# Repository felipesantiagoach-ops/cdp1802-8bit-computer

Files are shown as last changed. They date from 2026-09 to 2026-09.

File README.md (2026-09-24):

# CDP1802 8-bit Computer — Design and Construction

Design, construction and testing of an 8-bit microcomputer built around the **RCA CDP1802**, the first CMOS microprocessor (also known for flying in the Galileo probe and the Hubble Space Telescope).

Final engineering project for *Proyecto y Diseño Electrónico* (ET546), Electronic Engineering, **Universidad Nacional de Misiones**, Argentina (November 2022).

📄 **[Read the full report (PDF, Spanish)](informe/ProyectoFinal.pdf)**: 166 pages covering theory, schematics, PCBs, assembly code and test results.  
🖼️ **[Project poster](Poster_PyD_2022_Grupo_A.pdf)**

<p align="center">
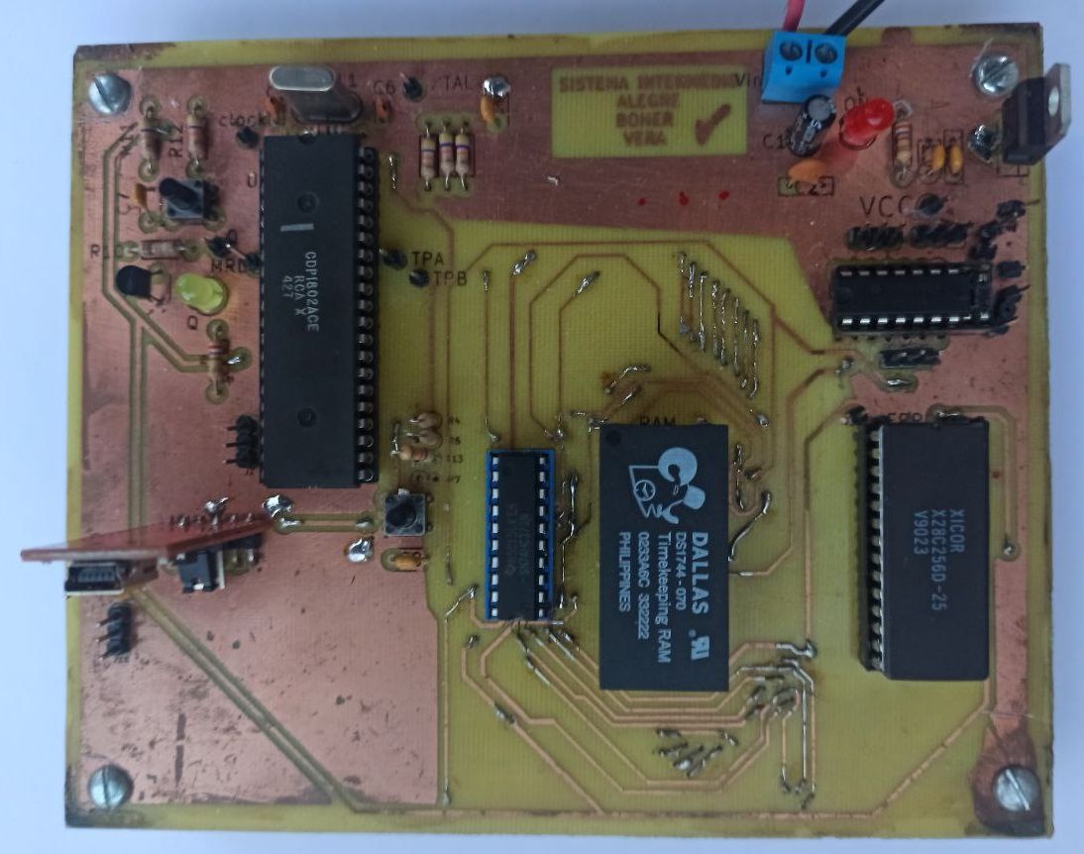
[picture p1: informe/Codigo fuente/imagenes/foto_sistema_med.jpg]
Medium system, assembled
  
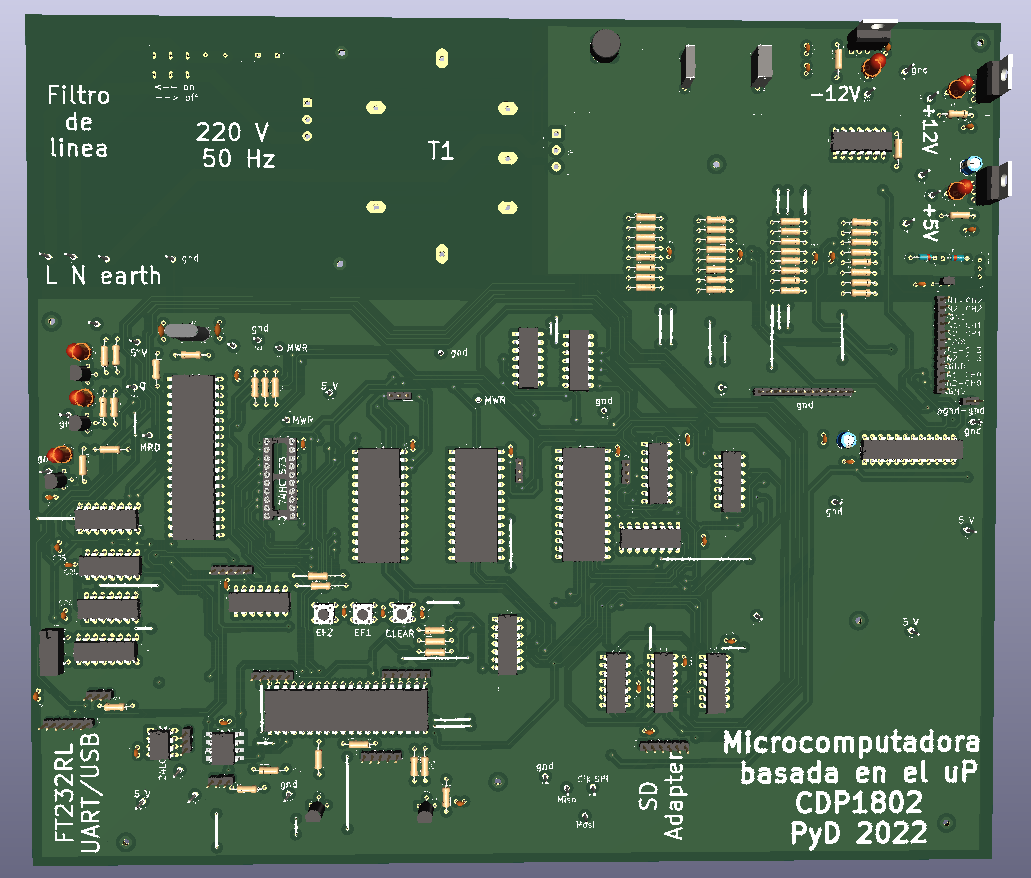
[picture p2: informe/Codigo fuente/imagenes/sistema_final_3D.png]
Final system, 3D render of the PCB
  
</p>

---

## Overview

The project was developed in three stages of increasing complexity. Each stage was designed in KiCad, simulated, and (for the first two) built and tested on hardware.

| Stage | Status | Highlights |
|---|---|---|
| **Minimal system** | ✅ Built and tested | CDP1802 + 8K EEPROM, 8-bit addressing, jumper-selectable program banks, single-sided PCB |
| **Medium system** | ✅ Built and tested | 16-bit addressing (64 KB), 32K EEPROM + 32K RAM, USB-UART link, runs Tiny BASIC and a diskless Elf/OS |
| **Final system** | 📐 Designed (schematics + PCB) | Power supply, bank-switched memory, I²C and SPI serial memories, 12-bit ADC, parallel I/O |

### 1. Minimal system
- CDP1802 with an AT28C64 EEPROM using only the 8 low address lines (256-byte programs).
- A8/A9 set by jumpers, allowing four independent programs in the same EEPROM without reprogramming.
- Four assembly programs written and verified on hardware: LED blink, push-button input, conditional blink, and a **bit-banged UART transmitter at 600 baud** using the Q output, with the delay loop derived analytically from the instruction cycle timing.
- Subroutines use the CDP1802 *SEP technique*, which requires no RAM (the system has none).

### 2. Medium system
- 74HC373 address latch to demultiplex the CDP1802's time-shared address bus to a full **16-bit / 64 KB** space.
- Memory map: 32K EEPROM (program) + 32K DS1744 timekeeping RAM (data).
- FT232RL USB-UART module for communication with a PC terminal (Tera Term).
- Ported and ran third-party software on real hardware:
  - **Tiny BASIC interpreter**: modified the source (register definitions, idle line polarity, autorun) and reassembled it.
  - **Diskless Elf/OS** operating system.

### 3. Final system (design)
Fully backwards compatible with the previous stages. Designed as a modular set of schematics and a double-sided 30 × 30 cm PCB:
- **Linear power supply** with line filter and ±12 V / 5 V regulation.
- **Bank-switched memory map**: boot mode (EEPROM + RAM) and run mode (program copied to RAM, a second RAM swapped in to maximise working memory).
- **Hardware SPI engine** built from discrete logic (MC14014 + 74HC595 shift registers, 74HC161/74HC74/74HC73 clock generator producing exactly 8 pulses at 2 MHz), which offloads the serial shifting from the CPU. Intended for a **microSD** card.
- **I²C serial memories**: 24LC1025 EEPROM and MB85RC64A **FRAM**, driven in software through the parallel port.
- **12-bit ADC** (MAX127) with OPA4277 signal conditioning for **4–20 mA** industrial current loops.
- **82C55 parallel I/O** mapped into the CDP1802's dedicated I/O space (INP/OUT instructions).

The report also outlines future work, including I/O drivers, SD-card support, a PLC-oriented use case and guidelines for a real-time operating system.

---

## Tools

| Area | Tools |
|---|---|
| Schematics and PCB | KiCad |
| Assembly and simulation | A18 cross-assembler, Emma02 emulator (debugging and instruction tracing) |
| Programming hardware | XGecu TL866 universal programmer; an Arduino-based EEPROM programmer was also built |
| Communication | FT232RL, Tera Term |
| Documentation | LaTeX (memoir, biblatex/biber), Git, VS Code |

---

## Repository structure

```
Poster_PyD_2022_Grupo_A.pdf   Project poster
informe/
  ProyectoFinal.pdf           Compiled report (Spanish)
  Codigo fuente/              LaTeX source (chapters, appendices, bibliography, figures)
archivos_de_kicad/            KiCad projects: schematics, PCBs, BOMs and exports
  1_Sistema_minimo/
  2_Sistema_medio/
  3_Sistema_final/            Full system plus separate sub-projects (ADC conditioning, SPI)
programas/                    CDP1802 assembly programs (.asm), assembled output (.hex, .lst) and build scripts
decodificador SPI/            Proteus simulations of the hardware SPI circuit
```

The KiCad projects were made with KiCad 6 (the minimal system also includes the original KiCad 5 files).  
Programs are assembled with the [A18 cross-assembler](https://www.retrotechnology.com/memship/a18.html); each folder includes a `.bat` script that assembles the `.asm` file with the same name.

### Building the report
Requires a LaTeX distribution (MiKTeX or TeX Live) with `biber`.

```bash
cd "informe/Codigo fuente"
pdflatex proyecto
biber proyecto
pdflatex proyecto
pdflatex proyecto
```

---

## Third-party software

The `programas/` folder also contains third-party code that was studied, modified or run on the hardware. It is included for reference, and credit goes to its original authors:
- **Tiny BASIC** for the 1802, from the [Membership Card](http://www.sunrise-ev.com/1802.htm) project (the `original/` folder is unmodified; `modificado/` contains our changes).
- **FIG-Forth** for the 1802, from Lee Hart's Membership Card resources.

---

## Authors

- **Felipe Santiago Alegre Chamorro**
- Atilio Boher
- Uriel Adrián Vera

Supervisor: Ing. Ricardo A. Korpys, Facultad de Ingeniería, UNaM.

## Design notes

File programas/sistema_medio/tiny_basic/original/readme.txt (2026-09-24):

Tiny BASIC for the 1802 by Lee Hart and Tom Pittman
mods by many, latest Loren Christiansen
http://www.retrotechnology.com/memship/mship_tbasic.html

tbsummaryp.txt	TMSI summary of Tiny BASIC 1802 commands
tbmanualp.txt	TMSI Tiny BASIC 1802 manual by Lee Hart
TBEK_sg.txt	Tom Pittman's documentation
tb0_test.asm		ASM of source, for A18 assember
1802reg.asm	include file names 1802 registers
tb0_test.prn		prn of assembled tb0 source
tb0_test.hex		Intel hex of assembled source
tb0_test_results.txt - commented notes from running this TB code
tbasic_loren.txt  notes about use of TB on 1802 M/S card
readme.txt	this document

last updated Aug 2 2018 Herb Johnson

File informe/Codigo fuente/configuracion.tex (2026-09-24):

% -----------------------------------------
% OTROS PAQUETES E INSTRUCCIONES ESPECIALES
% -----------------------------------------

% PAQUETES
%%%%%%%%%%

% Para insertar PDFs
\usepackage{pdfpages}
% Para insertar código fuente estilizado
\usepackage{listings}
	\lstset{basicstyle=\ttfamily,
    		breaklines=true,
            numbers=left, 
    		numberstyle=\tiny, 
    		stepnumber=1, 
    		numbersep=6pt
            }

% Para adjuntar pdf
\usepackage{pdfpages}

% Para usar múltiples columnas
\usepackage{multicol}

% Para crear árboles conceptuales
\usepackage{forest}

% Para insertar símbolos extraños
\usepackage{marvosym}

% Para insertar texto fútil
\usepackage{lipsum}

% NUEVAS INSTRUCCIONES
%%%%%%%%%%%%%%%%%%%%%%

\newcommand{\EIEx}{\textsc{Escuela \Lightning~ Ingeniería Eléctrica}}

% Definición de algunos símbolos matemáticos
\newcommand{\me}{\mathrm{e}}
\newcommand{\mi}{\mathrm{i}}
\newcommand{\mj}{\mathrm{j}}
\newcommand{\md}{\mathrm{d}}

% Listas con menos espacio entre ítemes (más ajustado)
\newcommand{\ajustado}{\itemsep0pt\parskip0pt\parsep0pt}

% FORMATO PARA EL REGLAMENTO
%%%%%%%%%%%%%%%%%%%%%%%%%%%%

\newcounter{articulo}
\newcommand{\articulo}[2]{
	{
    \stepcounter{articulo}
    \noindent
	\textbf{Artículo \thearticulo} --- \textit{#1}
	\vspace{2mm}\\
	}{
	#2
	\vspace{2mm} \\
	}
}

\newcounter{capitulo}
\newcommand{\capitulo}[1]{
	{
    \stepcounter{capitulo}
    \centering\large\bfseries
    Capítulo \Roman{capitulo}. #1
    \vspace{4mm}\\
    }
}

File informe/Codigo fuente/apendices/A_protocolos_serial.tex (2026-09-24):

\chapter{Protocolos de Comunicación Serial}
\label{C:anexo-comunicación-serial}

\section{UART}

UART (Universal Asynchronous Receiver-Transmitter) \cite{fernandez-com-serial} es un protocolo de comunicación serial asincrónica y bidireccional full-duplex desarrollado en el año 1960 por la empresa Digital Equipment Corporation. Esta interfaz posee dos líneas de datos, RX y TX, las cuales se interconectan como lo muestra la figura~\ref{F:uart-interconexión}. UART generalmente es usada para establecer una comunicación bidireccional full-dúplex sólo entre dos dispositivos (punto a punto).

\begin{figure}[ht!]
\centering
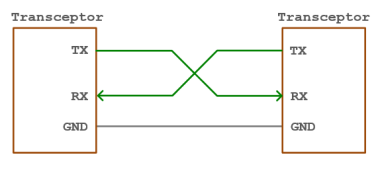
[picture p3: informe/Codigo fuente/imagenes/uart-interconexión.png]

\caption{Interconexión de interfaz UART}
\label{F:uart-interconexión}
\end{figure}

La información intercambiada entre los dispositivos es mediante paquetes de datos con un formato definido como se muestra en la figura~\ref{F:uart-trama-datos}. La comunicación está sincronizada mediante los bits de START y STOP que posee el paquete, considerando que los relojes de los dispositivos transmisor y receptor operan a la misma frecuencia.

\begin{figure}[ht!]
\centering

\caption{Paquete de datos UART}
\label{F:uart-trama-datos}
\end{figure}

El paquete de datos indicado posee las siguientes configuraciones que deben efectuarse en los dispositivos que intervienen en la comunicación:

\begin{description}
   \item[Bit de START] Es el primer bit del paquete de datos y permite que el receptor reconozca el inicio de la transmisión de un paquete. Normalmente el transmisor (TX) mantiene la línea de datos en “1” cuando se encuentra en reposo. Para iniciar la transmisión pone a “0” la línea y el receptor, al detectar esto, comienza con la lectura del DATO.
   \item[DATO] Este campo del paquete puede configurarse de 5 a 9 bits. La configuración debe ser la misma para ambos dispositivos en la comunicación. Los bits son enviados uno a uno, empezando por el menos significativo y terminando con el más significativo.
   \item[Bit de Paridad] Permite al receptor verificar si los datos recibidos son correctos o no. La paridad es un sistema de comprobación de errores de bajo nivel y puede ser de paridad par o paridad impar. Debe configurarse la misma paridad en ambos dispositivos involucrados en la comunicación.
   \item[Bit de STOP] Marca el final del paquete de datos al receptor. Puede tener uno o dos bits de longitud. Debe configurarse lo mismo en ambos dispositivos. Al finalizar la transmisión, es habitual que se mantenga la línea de datos en “1” (línea en reposo).
   \item[Baud Rate (bits por segundo)]  Es un parámetro que indica la velocidad a la que se transmiten los datos y se relaciona con el reloj interno que poseen los dispositivos para la lectura/escritura de los bits que conforman el paquete de datos. Todos los dispositivos deben tener el mismo baud rate. Algunas de las velocidades estándares son 4800 bps, 9600 bps, 19200 bps, 115200 bps, etc. De estas, 9600 bps es la más utilizada.
\end{description}

\section{I\texorpdfstring{\textsuperscript{2}}{Lg}C}

I\textsuperscript{2}C (Inter-Integrated Circuit) \cite{fernandez-com-serial} es un bus de comunicación serie sincrónica bidireccional half-duplex desarrollado en el año 1982 por la empresa Philips Semiconductors. El bus I2C también es conocido con el nombre de TWI (Two Wire Interface). Este bus también posee una arquitectura Maestro-Esclavo, donde el dispositivo Maestro es el único que puede iniciar y finalizar la transmisión y también proveer la señal de reloj. En I2C los dispositivos Esclavos pueden convertirse en Maestros, pero en el bus sólo puede existir un Maestro a la vez.

El bus está compuesto de dos líneas y la conexión común de GND, como puede apreciarse en la figura~\ref{F:i2c-interconexión}. Existe una línea bidireccional para el intercambio de datos que se denomina SDA (Serial Data) y una para la señal de reloj denominada SCL (Serial Clock). Como en este bus no existen líneas de selección de esclavo, cada dispositivo Esclavo debe contar con una dirección única (código de identificación) la cual debe incluirse al dato. Esto resulta en una reducción de la velocidad de transferencia de cada byte de dato.

Las líneas SDA y SCL son del tipo drenador abierto (figura~\ref{F:i2c-entrada-y-salida}), por lo cual cada una requiere una resistencia pull-up Rp ($ \num{1.8}~\unit{\kilo\Omega} \leq Rp \leq \num{10}~\unit{\kilo\Omega} $).

\begin{figure}[ht!]
\centering
\subfloat[Interconexión de interfaz I\textsuperscript{2}C][Interconexión de interfaz I\textsuperscript{2}C]{
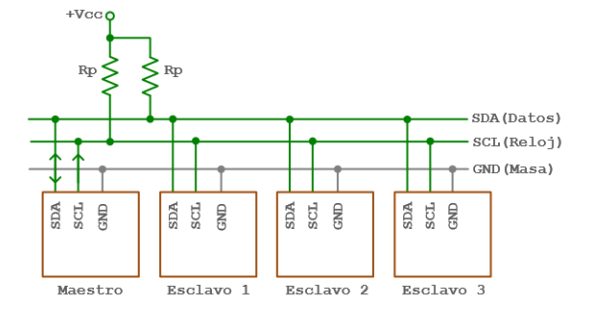
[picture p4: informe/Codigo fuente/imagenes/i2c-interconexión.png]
	
	\label{F:i2c-interconexión}}
\\
\subfloat[Líneas SDA y SCL][Líneas SDA y SCL]{
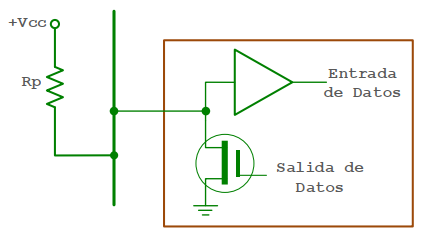
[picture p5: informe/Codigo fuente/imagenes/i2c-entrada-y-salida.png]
	
	\label{F:i2c-entrada-y-salida}}
\caption{Interfaz I\textsuperscript{2}C}
\end{figure}

A continuación se describe un ejemplo de trama del protocolo I\textsuperscript{2}C, la cual se puede observar en la figura~\ref{F:i2c-trama-y-sec}:

\begin{itemize}
    \item El Maestro inicia la comunicación con la secuencia de inicio (START), acompañada de 7~bits que corresponden a la dirección del Esclavo con el que se desea comunicar. A esto el Maestro agrega un bit que indica si la operación será de escritura (W~=~0) o  de lectura (R~=~1). En este caso de escritura.
    \item Si el Esclavo está disponible en el bus, responde con un bit de reconocimiento (ACK) a lo anterior. Si no hay respuesta del Esclavo en cuestión, el Maestro terminará la comunicación con una secuencia de parada (STOP).
    \item Luego de que el Maestro recibe el bit de reconocimiento, el mismo envía el Dato~1 (de 8~bits) que corresponde a la dirección del registro del Esclavo donde se desea escribir. A esto el Esclavo vuelve a responder con un bit de reconocimiento (ACK). Si esto no sucede el Maestro finaliza la comunicación con una secuencia de parada (STOP).
    \item Recibido el bit de reconocimiento, el Maestro envía el Dato~2 (8~bits) que corresponde al valor que se cargará en el registro del Esclavo. Luego, este último responde con un bit de reconocimiento (ACK). Caso contrario, el Maestro finaliza la comunicación.
    \item Una vez que el Maestro ha escrito el valor correspondiente (Dato~2) en el registro deseado (Dato~1) del Esclavo, finaliza la comunicación con una secuencia de parada (STOP).
\end{itemize}

\begin{figure}[ht!]
\centering
\subfloat[Ejemplo de trama I\textsuperscript{2}C: Escritura en el registro de un Esclavo (M: Maestro; E: Esclavo)][Ejemplo de trama I\textsuperscript{2}C: Escritura en el registro de un Esclavo (M: Maestro; E: Esclavo)]{
	
	\label{F:i2c-trama}}
\\
\subfloat[Secuencia de inicio y parada I\textsuperscript{2}C][Secuencia de inicio y parada I\textsuperscript{2}C]{
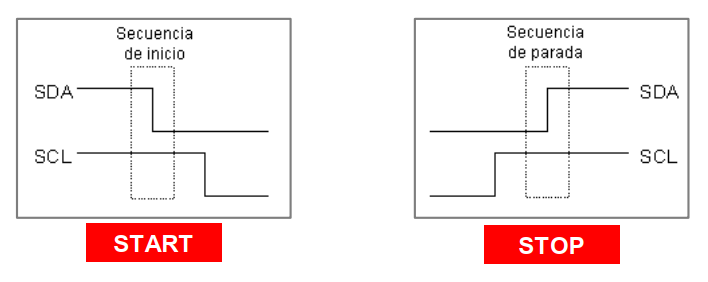
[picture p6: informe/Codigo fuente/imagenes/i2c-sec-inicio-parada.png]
	
	\label{F:i2c-sec-inicio-parada}}
\caption{Trama y secuencia de inicio y parada I\textsuperscript{2}C}
\label{F:i2c-trama-y-sec}
\end{figure}

En la figura~\ref{F:i2c-trama-en-detalle} se encuentra ilustrada en forma más detallada la trama I\textsuperscript{2}C. A continuación se describen cada una de las subfiguras.

\paragraph{Reconocimiento de bits (figura~\ref{F:i2c-fig1}):}
El nivel lógico de la línea SDA debe ser estable cuando la línea SCL es alta. La única excepción a esta regla es la generación de secuencias de START y STOP.

\paragraph{Secuencias de START y STOP (figura~\ref{F:i2c-fig2}):}
El bus está inactivo cuando SDA~=~1 y SCL~=~1. El Maestro inicia la transmisión con una secuencia START (SDA~=$ \downarrow $  con SCL~=~1) y finaliza la misma con una secuencia de STOP (SDA~=~$ \uparrow $ con SCL~=~1). Entre una condición de START y STOP, el bus se considera ocupado y ningún otro maestro debe intentar tomar el control del bus. Si el Maestro genera una nueva secuencia de START antes de la secuencia de STOP, esto se conoce como INICIO REPETIDO (\textit{Repeated START}) y se utiliza cuando el Maestro desea iniciar una nueva transferencia sin renunciar al control del bus.

\paragraph{Paquete de Dirección (figura~\ref{F:i2c-fig3}):}
Todos los paquetes de direcciones transmitidos tienen una longitud de 9~bits y están constituidos
por:

\begin{itemize}
    \item 7~bits más significativos para la dirección del Esclavo con el cual el Maestro desea comunicarse.
    \item 1~bit para definir la operación que desea realizar el Maestro. Puede ser Lectura (R) o Escritura ($ \overline{\text{W}} $). Este bit debe ser “1” para el caso de lectura y “0” para escritura.
    \item 1~bit de reconocimiento (ACK). Este bit es generado por el Esclavo cuando reconoce la dirección enviada por el Maestro. El esclavo debe poner a “0” la línea SDA si reconoce la dirección.
\end{itemize}

\paragraph{Paquete de Datos (figura~\ref{F:i2c-fig4}):}
Todos los paquetes de datos transmitidos poseen una longitud de 9~bits y están constituidos por:

\begin{itemize}
    \item 8~bits para datos.
    \item 1~bit de reconocimiento (ACK). Este bit es generado por el receptor de los datos. El reconocimiento de la recepción se efectúa poniendo en “0” la línea SDA durante el noveno ciclo de reloj en línea SCL. Si el receptor deja la línea SDA en “1”, se señaliza un NACK. Esta señalización permite al receptor avisar que ha recibido el último byte, o por alguna razón no puede recibir más bytes.
\end{itemize}

\paragraph{Combinación de Paquetes de Dirección y Datos (figura~\ref{F:i2c-fig5}):}
 Una transmisión consiste básicamente en una secuencia de START, una dirección más bit R o W (SLA+R/W)\footnote{SLA significa dirección de esclavo (Slave Address)}, uno o más paquetes de datos y una secuencia de STOP. Pueden existir varios bytes de datos entre SLA+R/W y STOP, dependiendo del protocolo implementado por el programa del usuario.

\vspace{4cm}
~

\begin{figure}[H]
\centering
\subfloat[Reconocimiento de bits][Reconocimiento de bits]{
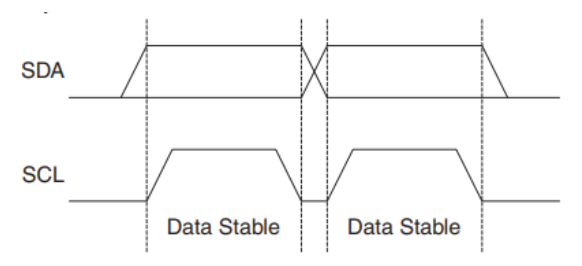
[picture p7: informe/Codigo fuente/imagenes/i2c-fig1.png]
	
	\label{F:i2c-fig1}}
\quad
\subfloat[Secuencias de START y STOP][Secuencias de START y STOP]{
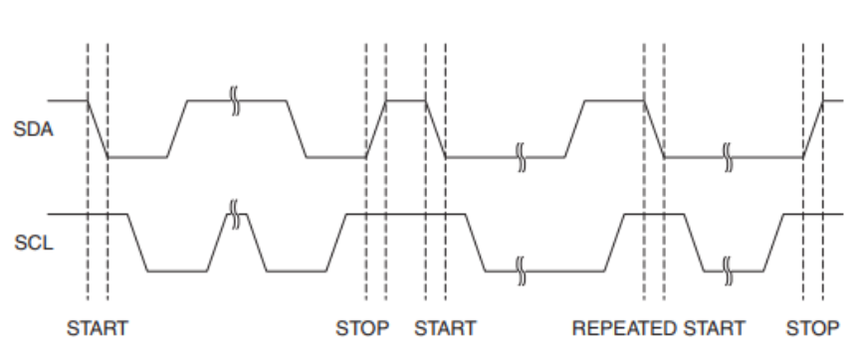
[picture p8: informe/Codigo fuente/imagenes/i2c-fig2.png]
	
	\label{F:i2c-fig2}}
\\
\subfloat[Paquete de Dirección][Paquete de Dirección]{
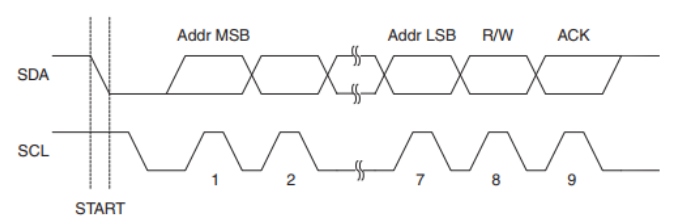
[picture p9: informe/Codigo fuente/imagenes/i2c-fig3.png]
	
	\label{F:i2c-fig3}}
	\\
\subfloat[Paquete de Datos][Paquete de Datos]{
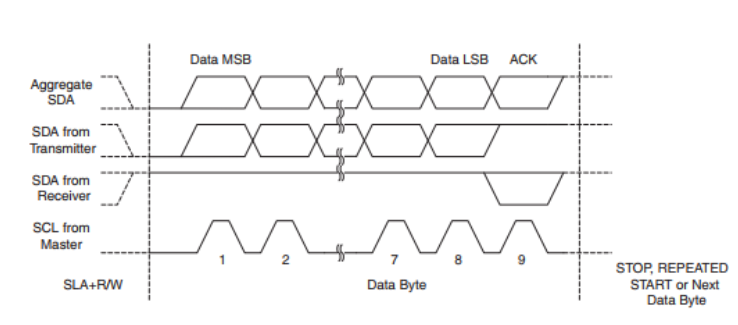
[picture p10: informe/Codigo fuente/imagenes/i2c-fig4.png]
	
	\label{F:i2c-fig4}}
	\\
\subfloat[Combinación de Paquetes de Dirección y Datos][Combinación de Paquetes de Dirección y Datos]{
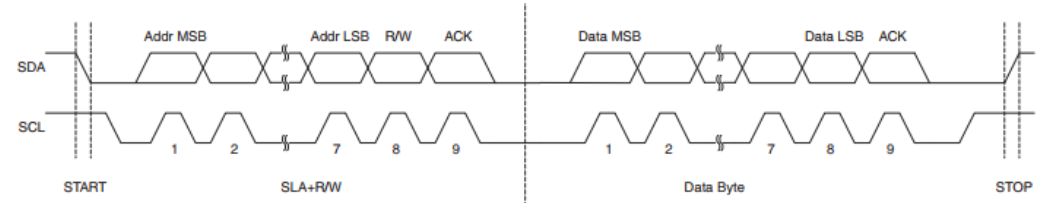
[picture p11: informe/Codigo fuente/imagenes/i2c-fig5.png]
	
	\label{F:i2c-fig5}}
\caption{Trama I\textsuperscript{2}C en detalle}
\label{F:i2c-trama-en-detalle}
\end{figure}

\section{SPI}

SPI (Serial Peripheral Interface) \cite{fernandez-com-serial} es un bus de comunicación serie sincrónica bidireccional full-duplex desarrollado en el año 1980 por la empresa Motorola. En el bus SPI hay un dispositivo Maestro y uno o más Esclavos. El Maestro es el único encargado de iniciar y finalizar la comunicación en cualquiera de las direcciones y también genera la señal de reloj de sincronización. Este bus se encuentra compuesto por las siguientes cuatro líneas más la línea común de GND:
\clearpage
\begin{description}
   \item[MOSI (Master Out Slave In):] Esta línea lleva los datos desde el Maestro a los Esclavos.
   \item[MISO (Master In Slave Out):] Lleva los datos desde los Esclavos al Maestro.
   \item[CLK (Clock):] Esta línea lleva los pulsos de reloj desde el Maestro a los Esclavos.
   \item[$ \overline{\text{SS}} $ (Slave Select):] Es la línea mediante la cual el Maestro selecciona al Esclavo con el cual quiere comunicarse. Si hay varios esclavos, pueden existir varias líneas de selección de esclavos.
\end{description}

\begin{figure}[ht!]
\centering
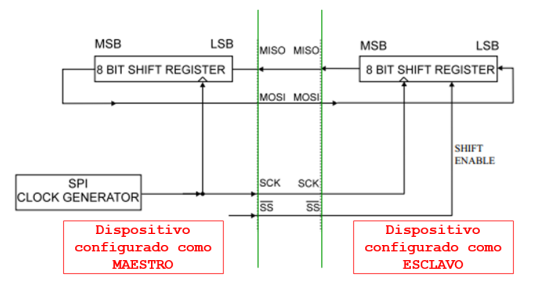
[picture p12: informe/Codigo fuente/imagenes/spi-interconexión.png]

\caption{Interconexión interfaz SPI}
\label{F:spi-interconexión}
\end{figure}

\paragraph{Operación:}
El sistema de comunicación SPI de la figura~\ref{F:spi-interconexión} posee dos registros de desplazamiento (de 8 bits c/u) y un generador de reloj maestro. El maestro SPI inicia el ciclo de comunicación cuando pone en bajo el pin $ \overline{\text{SS}} $. El maestro y el esclavo preparan los datos para ser enviados en sus respectivos registros de desplazamiento, y el maestro genera los pulsos de reloj requeridos en la línea CLK para intercambiar los datos. Estos últimos van de Maestro a Esclavo a través de la línea MOSI y de Esclavo a Maestro a través de MISO. Después de cada paquete de datos (8 bits), el maestro sincronizará al esclavo poniendo en alto la línea de selección $ \overline{\text{SS}} $.

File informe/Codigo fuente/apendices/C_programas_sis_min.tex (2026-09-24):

\chapter{Programas escritos para el sistema mínimo}
\label{C:anexo-programas-sistema-mínimo}

En este anexo se encuentra el código fuente de los programas escritos para el sistema mínimo.

\section{Programa 1: Parpadeo LED Q}
\label{C:anexo-prog-1}

\clearpage

\footnotesize
\lstinputlisting[language=CDP1802, caption=Programa 1]{codigo/1_qblink_test.asm}
\clearpage

\section{Programa 2: LED Q se enciende al presionar pulsador}
\label{C:anexo-prog-2}

\lstinputlisting[language=CDP1802, caption=Programa 2]{codigo/2_qInPutTurnOn.asm}
\clearpage

\section{Programa 3: LED Q parpadea al presionar pulsador}
\label{C:anexo-prog-3}

\lstinputlisting[language=CDP1802, caption=Programa 3]{codigo/3_qblinkIfPressed.asm}
\clearpage

\section{Programa 4: Transmisión serial de caracteres}
\label{C:anexo-prog-4}

\lstinputlisting[language=CDP1802, caption=Programa 4]{codigo/send_characters.asm}
\normalsize

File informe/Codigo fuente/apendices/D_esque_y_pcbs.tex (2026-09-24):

\chapter{Esquemas circuitales y circuitos impresos}

En este apéndice se incluyen los esquemáticos presentados dentro del cuerpo del informe, pero en el tamaño de hoja original.

\includepdf[fitpaper, angle=90]{./imagenes/EsquematicosSF/Esquematico (1).pdf}
\includepdf[fitpaper, angle=90]{./imagenes/EsquematicosSF/Esquematico (2).pdf}
\includepdf[fitpaper, angle=90]{./imagenes/EsquematicosSF/Esquematico (3).pdf}
\includepdf[fitpaper, angle=90]{./imagenes/EsquematicosSF/Esquematico (4).pdf}
\includepdf[fitpaper, angle=90]{./imagenes/EsquematicosSF/Esquematico (5).pdf}
\includepdf[fitpaper, angle=90]{./imagenes/EsquematicosSF/Esquematico (6).pdf}
\includepdf[fitpaper, angle=90]{./imagenes/EsquematicosSF/Esquematico (7).pdf}
\includepdf[fitpaper, angle=90]{./imagenes/EsquematicosSF/Esquematico (8).pdf}
\includepdf[fitpaper, angle=90]{./imagenes/EsquematicosSF/Esquematico (9).pdf}
\includepdf[fitpaper, angle=90]{./imagenes/EsquematicosSF/Esquematico (10).pdf}
\includepdf[fitpaper, angle=90]{./imagenes/EsquematicosSF/Esquematico (11).pdf}
\includepdf[fitpaper, angle=90]{./imagenes/EsquematicosSF/Esquematico (12).pdf}
\includepdf[fitpaper]{./imagenes/EsquematicosSF/PCB_atras.pdf}
\includepdf[fitpaper]{./imagenes/EsquematicosSF/PCB_frente.pdf}
\includepdf[fitpaper]{./imagenes/EsquematicosSF/PCB_mascara.pdf}

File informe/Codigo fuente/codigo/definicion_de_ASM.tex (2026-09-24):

%% este código define el estilo para el lenguaje assembler del CDP1802

\lstdefinelanguage{CDP1802}{
    morekeywords=[1]{LDN, LDA, LDX, LDXA, LDI, STR, STXD,
        INC, DEC, IRX, GLO, PLO, GHI, PHI,
        OR, ORI, XOR, XRI, AND, ANI, SHR, SHCR, RSHR, SHL, SHLC, RSHL,
        ADD, ADI, ADC, ADCI, SD, SDI, SDB, SDBI, SM, SMI, SMB, SMBI,
        BR, NBR, BZ, BNZ, BDF, BPZ, BGE, BNF, BM, BL, BQ, BNQ, B1, BN1, B2, BN2, B3, BN3, B4, BN4,
        LBR, NLBR, LBZ, LBNZ, LBDF, LBNF, LBQ, LBNQ,
        SKP, LSKP, LSZ, LSNZ, LSDF, LSNF, LSQ, LSNQ, LSIE,
        IDL, NOP, SEP, SEX, SEQ, REQ, SAV, MARK, RET, DIS,
        OUT1, OUT2, OUT3, OUT4, OUT5, OUT6, OUT7, INP1, INP2, INP3, INP4, INP5, INP6, INP7, OUT, INP},%
    morekeywords=[2]{r0, r1, r2, r3, r4, r5, r6, r7, r8, r9, r10, r11, r12, r13, r14, r15, ra, rb, rc, rd, re, rf},%
    morekeywords=[3]{org,def,equ,db,dw,include,dseg,cseg,eseg},%
    sensitive=false, % keywords are not case-sensitive
    morecomment=[l]{;}, % l is for line comment
} %

\definecolor{MyDarkGreen}{rgb}{0.0,0.4,0.0} % This is the color used for comments

\lstset{language=CDP1802,
        frame=single, % Single frame around code
        basicstyle=\small\ttfamily, % Use small true type font
        keywordstyle=\color{Blue}\textbf, % Instructions in blue, bold
        keywordstyle=[2]\color{Orange}, % Registers in orange
        keywordstyle=[3]\color{Purple}, % Directives in purple
        commentstyle=\usefont{T1}{pcr}{m}{sl}\color{MyDarkGreen}\small,
        tabsize=4, % 4 spaces per tab
        numbers=left, % Line numbers on left
        firstnumber=1, % Line numbers start with line 1
        numberstyle=\tiny\color{Blue}, % Line numbers are blue and small
        stepnumber=5 % Line numbers go in steps of 5
        }

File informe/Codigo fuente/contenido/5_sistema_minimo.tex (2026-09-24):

\chapter{Sistema mínimo}
\label{C:SistemaMinimo}
El primer circuito diseñado para el desarrollo del trabajo fue el \textbf{Sistema Mínimo}, un sistema simplificado que consta de una arquitectura simple, con el objetivo de analizar el funcionamiento del microprocesador y el uso del mapa de memoria. Este sistema consta de dos grandes bloques como se observa en la figura~\ref{F:diag_bloq_sistema_minimo}: el microprocesador y la memoria. 

\begin{figure}[ht]
  \centering
  
  \caption{Diagrama de bloques del sistema mínimo}
  \label{F:diag_bloq_sistema_minimo}
\end{figure}

El microprocesador es el elemento central del circuito diseñado, que es donde se realiza todo el procesamiento de datos. La incorporación del mismo permite realizar pruebas de funcionamiento, facilitando el entendimiento del lenguaje de programación y la secuencia de las instrucciones y ejecución dentro del microprocesador. Por otro lado, la memoria dentro de este sistema cumple la función de almacenar las instrucciones del programa a ejecutar y no se utiliza la misma para guardar datos generados en ejecución. Debido a la simplicidad del sistema presentado y la arquitectura del microprocesador, solo se utilizó un direccionamiento de 8 bits, lo que limita el tamaño del programa principal a un máximo de 256 bytes. Esto se debe a que el direccionamiento de 16 bits requiere el agregado de más elementos al circuito lo cual se explica en el desarrollo del sistema medio en la sección~\ref{C:SistemaMedio}. Con esta arquitectura los programas desarrollados debían ser simples con el único objetivo de determinar y comprobar el correcto funcionamiento de las conexiones y lograr un entendimiento básico del lenguaje de programación y del microprocesador. Para este fin se utilizan los programas desarrollados y presentados en la sección~\ref{C:ProgramasSMin}.

Debido a las limitaciones en el direccionamiento, se dispuso un diseño que permite establecer el estado de los pines de dirección A8 y A9 de la memoria de programa (28C64), directamente sobre el chip. Esto permite utilizar cuatro sectores de la memoria, aunque no simultáneamente. El microprocesador sigue utilizando únicamente 8 bits para el direccionamiento de memoria. Para la modificación se utilizan puentes tipo jumper que permiten conectar a masa o a VCC tanto A8 como A9 individualmente. De esta forma se establece un mapa de memoria como el presentado en la figura~\ref{F:Mapa_SMin}. De esta manera al realizar el grabado de la memoria EEPROM se pueden incluir los cuatro programas presentados en la sección \ref{C:ProgramasSMin} y pueden ser probados sin necesidad de regrabar la memoria.

\begin{figure}[ht!]
\centering
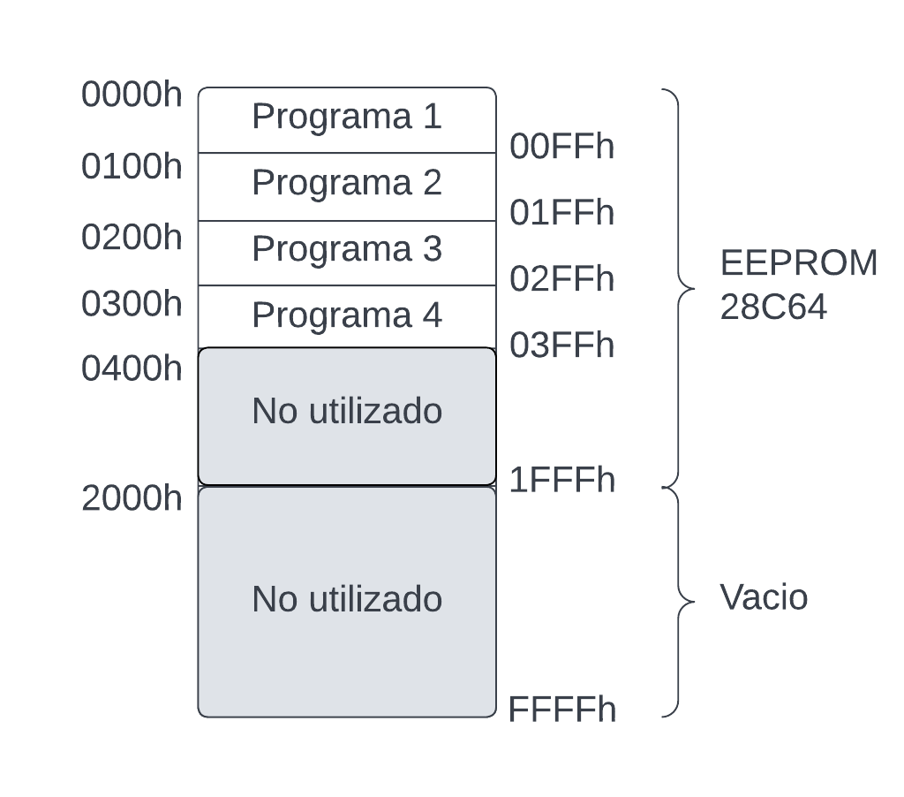
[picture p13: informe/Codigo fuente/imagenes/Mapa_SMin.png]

\caption{\centering Mapa de memoria Sistema Mínimo}
\label{F:Mapa_SMin}
\end{figure}

\clearpage
Para elegir cada uno de los programas debe conectarse adecuadamente un jumper en los conectores de J10 y otro jumper en los conectores de J11, como se describe a continuación.

\begin{description}
    \item[Programa 1:] Conectar un jumper en los pines 2 y 3 de J10, y otro jumper en los pines 2 y 3 de J11.
    \item[Programa 2:] Conectar un jumper en los pines 1 y 2 de J10, y otro jumper en los pines 2 y 3 de J11. 
    \item[Programa 3:] Conectar un jumper en los pines 2 y 3 de J10, y otro jumper en los pines 1 y 2 de J11. 
    \item[Programa 4:] Conectar un jumper en los pines 1 y 2 de J10, y otro jumper en los pines 1 y 2 de J11. 
\end{description}

Para que el circuito funcione correctamente se implementó un sistema de alimentación basado en un regulador de tensión de 5~V, específicamente el UTC7805. La incorporación del mismo proporciona mayor estabilidad en la alimentación protegiendo a los circuitos integrados del sistema. También se incorporó una interfaz de usuario simple que consta de pulsadores como sistema de entrada y LED indicadores de funcionamiento. 

Para la realización del esquemático y el diseño de la placa PCB se utilizó el programa KiCad. El esquema obtenido se presenta en la figura~\ref{F:EsquemaSMin}, además se lo presenta en el apéndice donde se encuentra en tamaño original. La placa PCB diseñada es una simple faz, la pista generada se presenta en la figura~\ref{F:PistaSMin}, mientras que la máscara de componentes de la misma se presenta en la figura~\ref{F:MascaraSMin}.

\begin{figure}[ht]
  \centering
  
  \caption{Esquema de sistema mínimo}
  \label{F:EsquemaSMin}
\end{figure}

\begin{figure}[ht]
\centering
\subfloat[Pista diseñada para sistema mínimo]{
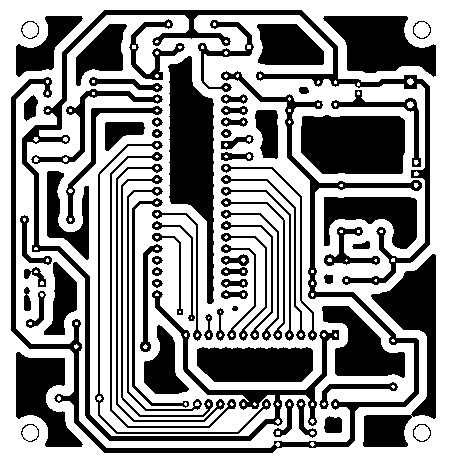
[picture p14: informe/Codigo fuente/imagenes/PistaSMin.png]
	
	\label{F:PistaSMin}}

\subfloat[Máscara de componentes sistema mínimo]{
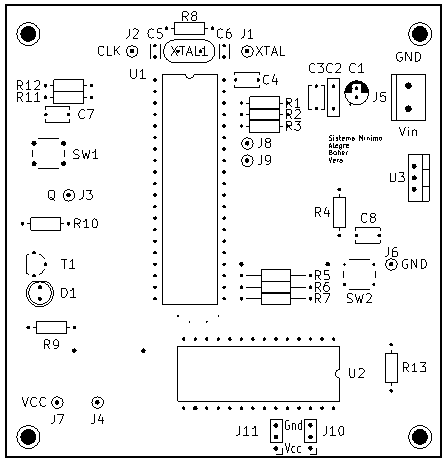
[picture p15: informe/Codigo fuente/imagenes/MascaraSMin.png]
	
	\label{F:MascaraSMin}}
\caption{Placa PCB diseñada para sistema mínimo}
\label{F:PlacaPCB}
\end{figure}

\clearpage

A partir de los diagramas presentados se procedió a la construcción del circuito. El resultado obtenido se presenta en la fotografía~\ref{F:SMin}. El mismo funcionó correctamente sin necesidad de realizar modificaciones a la arquitectura propuesta. Sin embargo, para la prueba de transmisión de datos mediante UART, con el programa que se presentará en la sección~\ref{C:ComunicacionSerial}, se utilizó una interfaz externa para la conversión del sistema UART a USB, esto permite la recepción de la información en una terminal. La interfaz utilizada es el circuito FT232RL\cite{datasheet_FT232RL}, la cual fue contemplada para los diseños posteriores al sistema mínimo. 

\begin{foto}[ht]
  \centering
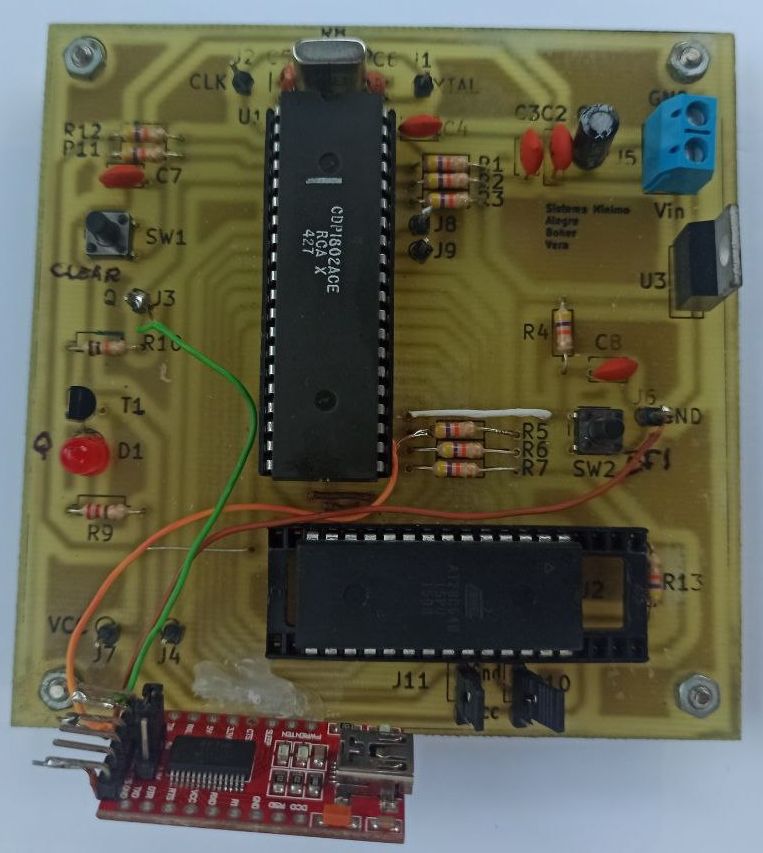
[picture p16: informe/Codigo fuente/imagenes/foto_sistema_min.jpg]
  
  \caption{Sistema mínimo construido}
  \label{F:SMin}
\end{foto}

\clearpage
\section{Lista de componentes}

En la tabla~\ref{T:bom_sis_min} se encuentra la lista de materiales para la construcción del sistema mínimo.

\begin{table}[ht!]
\caption{Lista de componentes del sistema mínimo}
\label{T:bom_sis_min}
\footnotesize
\begin{tabular}{|p{0.08\textwidth}|p{0.11\textwidth}|p{0.30\textwidth}|p{0.14\textwidth}|p{0.15\textwidth}|}
\hline
Cantidad & Etiqueta \newline
           Identificador            & Descripción                               & Fabricante            & Número de parte \\ \hline \hline
1       & U1                        & Microprocesador                           & RCA                   & CDP1802ACE      \\ \hline
1       & U2                        & Memoria EEPROM 8k x 8                     & ATMEL                 & AT28C64B          \\ \hline
1       & U3                        & Regulador de tensión                      & YOUW ANG              & UTC7805          \\ \hline
1       & T1                        & Transistor BJT NPN                        & ST Microelectronics   & PN2222A           \\ \hline
1       & XTAL1                     & Cristal \num{3.579545}~\si{\mega\hertz}   & CQ Electronics        & \listaVacio                \\ \hline
2       & SW1, SW2                  & Pulsador 6mm~x~4,3mm                      & \listaVacio           & \listaVacio       \\ \hline
10      & R1, R2, R3, R4, R5, R6, R7, R11, R12, R13
                                    & Resistor 47~\si{\kilo\ohm} 1/8~\si{\watt} & \listaVacio                      & \listaVacio                \\ \hline
1       & R8                        & Resistor 10~\si{\mega\ohm} 1/8~\si{\watt} & \listaVacio                      &    \listaVacio             \\ \hline
1       & R9                        & Resistor 220~\si{\ohm} 1/4~\si{\watt}     & \listaVacio                      &    \listaVacio             \\ \hline
1       & R10                       & Resistor 10~\si{\kilo\ohm} 1/8~\si{\watt} &  \listaVacio                     &  \listaVacio               \\ \hline
1       & D1                        & LED Rojo 5mm                              & \listaVacio                      &  \listaVacio               \\ \hline
1       & C1                        & Capacitor electrolítico 10~\si{\micro\farad} 25~\si{\volt}
                                                                                &  \listaVacio                     &   \listaVacio              \\ \hline
5       & C2, C3, C4, C7, C8        & Capacitor cerámico \num{0.10}~\si{\micro\farad} 50~\si{\volt}
                                                                                &  \listaVacio                     & \listaVacio                \\ \hline
2       & C5, C6                    & Capacitor cerámico \num{30}~\si{\pico\farad} 50~\si{\volt}
                                                                                & \listaVacio                      & \listaVacio                \\ \hline
8       & J1, J2, J3, J4, J6, J7, J8, J9
                                    & Pin conector macho (1 \textit{Male Header Pin})
                                                                                & \listaVacio                      &  \listaVacio               \\ \hline
1       & J5                        & Bornera 2 pines \num{5.08}~mm             & \listaVacio                      &  \listaVacio               \\ \hline
2       & J10, J11                  & 1x3 Pines Conectores Macho \num{2.54}~mm        & \listaVacio                      & \listaVacio                \\ \hline
\end{tabular}
\normalsize
\end{table}

Algo no contemplado en esta lista de componentes es el módulo FT232RL~\cite{datasheet_FT232RL}, dado que fue soldado luego de armado el circuito, como puede apreciarse en la figura~\ref{F:SMin}. El módulo FT232RL tiene soldado con cables sus pines Rx, Tx, Vcc y GND, a los pines Q, EF2, Vcc y GND del microprocesador, respectivamente.

%%-------------------------------------------------------------------------------------------

\clearpage
\section{Programas del sistema mínimo}
\label{C:ProgramasSMin}
Para probar el sistema mínimo, se confeccionaron cuatro programas sencillos de no más de 256 bytes, debido a que el sistema mínimo no puede direccionar más que esta cantidad de direcciones de memoria. Los programas se presentan a continuación, haciendo uso de diagramas de flujo. Sin embargo, en el apéndice~\ref{C:anexo-programas-sistema-mínimo} se encuentra el código fuente de los cuatro programas.

\subsection{Programa 1: Parpadeo LED Q}

El primer programa hace parpadear el LED conectado a la salida Q del microprocesador. Para ello, como puede apreciarse en el diagrama de flujo de la figura~\ref{F:prog_1}, el programa comienza apagando el LED (Q~=~0), luego realiza un retardo por software, que consiste en la asignación de un valor específico a un registro, para luego decrementarlo hasta que llegue a cero. Una vez finalizado el retardo, el LED togglea; si está encendido, se apaga, y si está apagado, se enciende. Esta secuencia se repite constantemente, haciendo parpadear el LED conectado a la salida Q. En el apéndice~\ref{C:anexo-prog-1}, se encuentra el código fuente del programa~1.

\begin{figure}[ht]
  \centering
  
  \caption{Programa 1}
  \label{F:prog_1}
\end{figure}

\clearpage
\subsection{Programa 2: LED Q se enciende al presionar pulsador}

El programa dos permite al usuario interactuar con el sistema, de manera que se prueba el funcionamiento de las entradas EFx (en el caso del sistema mínimo, EF1, dado que allí se encuentra conectado el pulsador). En el diagrama de flujo de la figura~\ref{F:prog_2} se puede observar cómo opera el programa. Cuando el botón se encuentra presionado, el programa entra a un bucle infinito que ejecuta el comando para encender el LED, en caso contrario, el programa entra a un bucle similar, pero donde la instrucción que se ejecuta continuamente es la de apagado del LED. En el apéndice~\ref{C:anexo-prog-2}, se encuentra el código fuente del programa~2.

\begin{figure}[H]
  \centering
  
  \caption{Programa 2}
  \label{F:prog_2}
\end{figure}

\clearpage
\subsection{Programa 3: LED Q parpadea al presionar pulsador}

El programa 3 es una combinación de los dos programas previos, el mismo hace parpadear el LED conectado a la salida Q del microprocesador, pero lo hace solo si el usuario presiona el pulsador.

En la figura~\ref{F:prog_3} se encuentra el diagrama de flujo del programa, el mismo consiste de una rutina de retardo con un contador que disminuye hasta cero (como en el programa 1), y luego, si el pulsador se encuentra presionado, el LED comienza a parpadear, pero si el pulsador no se encuentra presionado, el LED permanece apagado. En el apéndice~\ref{C:anexo-prog-3}, se encuentra el código fuente del programa 3.

\begin{figure}[H]
  \centering
  
  \caption{Programa 3}
  \label{F:prog_3}
\end{figure}

\clearpage
\subsection{Programa 4: Transmisión serial de caracteres}
\label{C:ComunicacionSerial}

El programa 4 realiza la transmisión serial por protocolo UART a través del pin Q de los caracteres “ABCDEFG”, seguido de un retorno de carro y un salto de línea. Este es el más complejo de los programas confeccionados para el sistema mínimo, por lo tanto, se encuentra descripto en dos diagramas de flujo separados, uno para la rutina principal, figura~\ref{F:prog_4_main} y otro para la rutina de transmisión de datos, figura~\ref{F:prog_4_rut_trans}. Si es de interés para el lector, en el apéndice~\ref{C:anexo-prog-4} se encuentra el código fuente.

 En la rutina principal, figura~\ref{F:prog_4_main}, inicialmente se inicializa el registro Contador  (en 7 decimal), que se utiliza para realizar la misma rutina 7 veces, y el registro Carácter (en 65 decimal), el cual representa el carácter A del código ASCII. Luego se ejecuta un bucle 7 veces seguidas, utilizando para ello el registro Contador. El mismo se decrementa una unidad en cada repetición del bucle y al llegar a cero en la última repetición, el programa sigue con su rutina. Dentro del bucle, Carácter es asignado a otro registro denominado Dato\footnote{Esta asignación parece a primera vista redundante, pero la razón de ello es que la rutina de trasmisión modifica el registro Dato, por lo tanto, se requiere que el dato a trasmitir permanezca guardado en otro lado, en este caso en el registro Carácter.}, en este registro debe encontrarse el dato a ser transmitido por la rutina de transmisión, seguidamente se llama a esa rutina, enviando el primer carácter (letra A). Seguidamente se llama a una rutina de retardo, se incrementa Carácter (pasando al siguiente carácter ASCII) y se vuelve a transmitir. Luego de ejecutarse 7 veces este bucle, se han transmitido los caracteres “ABCDEFG”.

A continuación, se sale del bucle y se envían los caracteres retorno de carro (D hexadecimal en codificación ASCII) y salto de línea (A hexadecimal en codificación ASCII). Esto concluye la rutina principal, la cual, al finalizar, vuelve a ejecutarse desde el comienzo.

En cuanto a la rutina de transmisión, figura~\ref{F:prog_4_rut_trans}, la misma envía los datos de forma serial por protocolo UART utilizando para ello el pin Q del microprocesador como salida de transmisión. En el apéndice~\ref{C:anexo-comunicación-serial} (\nameref{C:anexo-comunicación-serial}) se encuentran explicados los detalles relacionados con este protocolo.

La rutina de transmisión comienza pasando el pin Q de su estado de reposo (Q~=~1) a estado bajo (Q~=~0) por un periodo de 1~bit-time, este es el bit de inicio de la trama UART. Luego se inicializa un contador en 8 decimal, para realizar un bucle que se repite 8 veces, una por cada bit del dato de 8 bits. En este bucle el dato a enviar se corre a la derecha, cargando el LSB en el bit DF interno del microprocesador, en base al valor de este bit, se decide si poner la línea en estado alto (Q~=~1) o bajo (Q~=~0). Esto se repite 8 veces, de manera tal que se envían todos los bits del dato, del LSB al MSB. Finalmente se envían dos bits de parada (Q~=~1) para terminar la transmisión del dato.

\begin{figure}[H]
\centering
\subfloat[Rutina principal]{
	
	\label{F:prog_4_main}}
\quad
\subfloat[Rutina de transmisión]{
	
	\label{F:prog_4_rut_trans}}
\caption{Programa 4}
\label{F:prog_4}
\end{figure}

El programa 4 cuenta con muchas subrutinas, todas ellas fueron escritas con el método denominado \entreComillas{SEP technique}, el cual se encuentra descrito, junto a otros métodos, en la página 130 del libro Design Ideas Book for the CDP1802 COSMAC Microprocessor\cite{cdp1802_design_ideas}. El método SEP para las subrutinas fue utilizado por no requerir RAM para su operación, algo necesario, dado que el sistema mínimo no posee RAM.

En el listado~\ref{L:retardo}, se encuentra la rutina de retardo de un bit-time. En cada línea, como comentario, está indicado, para cada instrucción, el número de bytes, el número de ciclos máquina y la cantidad de veces que se ejecuta cada instrucción al llamarse la rutina. Esta información nos permite determinar el retardo ocasionado por la misma, necesario para poder calcular el valor que debe cargarse en \texttt{R1} (línea 5 y 6) y así poder obtener el retardo necesario.

\footnotesize
\lstinputlisting[language=CDP1802, caption = {Rutina de retardo de 1 bit-time}, label = {L:retardo}]{codigo/delay_routine.asm}
\normalsize

En base a esta información, en \eqref{eq:retardo} se tiene la expresión para el retardo; teniendo en cuenta que: todas las instrucciones ejecutadas en la rutina tienen una duración de dos ciclos máquina y que un ciclo máquina equivale a ocho ciclos de reloj.

\begin{equation}
    Retardo = 2\:ciclosMaq\:(4+3\:CONT1BT)\frac{8\:ciclosReloj}{1\:cicloMaq} T_{reloj}
    \label{eq:retardo}
\end{equation}

Simplificando \eqref{eq:retardo}, se obtiene \eqref{eq:retardo_simplificado}.

\begin{equation}
    Retardo = 16\:(4+3\:CONT1BT) T_{reloj}
    \label{eq:retardo_simplificado}
\end{equation}

Finalmente, a partir de \eqref{eq:retardo_simplificado}, se despeja CONT1BT, obteniéndose \eqref{eq:contador}.

\begin{equation}
    CONT1BT = \frac{Retardo}{48\:T_{reloj}}-\frac{4}{3}
    \label{eq:contador}
\end{equation}

En base a \eqref{eq:contador}, y teniendo en cuenta que el sistema mínimo utiliza un cristal de \num{3.579545}~\si{\mega\hertz} ($ T_{reloj} = \left(\num{3.579545}~\si{\mega\hertz}\right)^{-1} = \num{279.3651}~\si{\nano\second} $), podemos calcular CONT1BT. Lo único faltante es la duración del retardo, el cual se obtiene simplemente haciendo la inversa del baud rate. Tomando un baudrate de 600~baudios, se obtiene un retardo de \num{0.001666667}~\si{\second}. Con estos datos, y la ecuación \eqref{eq:contador}, es posible calcular el valor del contador para la rutina de retardo de 1 bit-time, como se muestra en \eqref{eq:calculo-1-bit-time-sistema-min}; redondeando el resultado, debido a que se trata de un valor que debe cargarse a un registro de 8 bits.

\begin{equation}
    CONT1BT = \frac{Retardo}{48\:T_{reloj}}-\frac{4}{3} = \frac{\num{0.001666667}~\si{\second}}{48\cdot\num{279.3651}~\si{\nano\second}}-\frac{4}{3} = \num{122.96}\approx\num{123}
    \label{eq:calculo-1-bit-time-sistema-min}
\end{equation}

\section{Simulaciones y resultados experimentales}

Todos los programas fueron probados en el simulador Emma02 antes de ser implementados en el sistema mínimo, los resultados obtenidos fueron los deseados. Para el testeo se utilizó la computadora Membership Card, y la configuración exacta utilizada puede visualizarse en la figura~\ref{F:config_emma02_sis_min}.

\begin{figure}[ht!]
  \centering
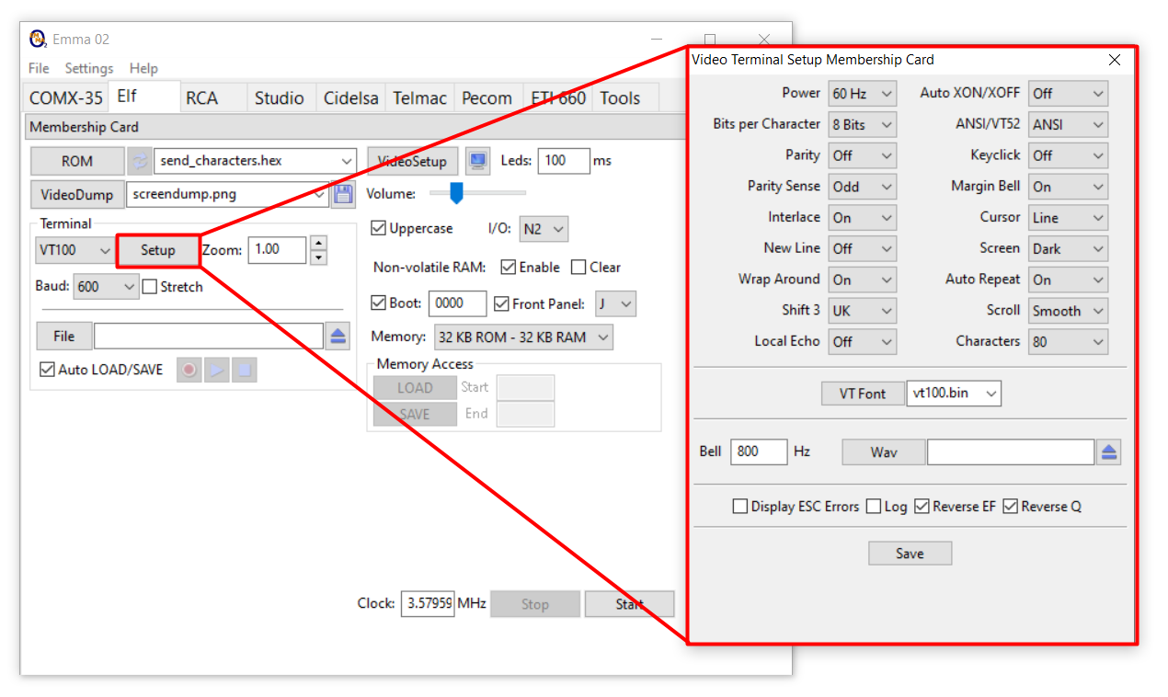
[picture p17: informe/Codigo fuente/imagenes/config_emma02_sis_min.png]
  
  \caption{Configuración utilizada en el simulador Emma02}
  \label{F:config_emma02_sis_min}
\end{figure}

En la figura~\ref{F:prog_4_resultados} puede observarse el resultado obtenido tanto en simulación como en el sistema mínimo construido. Los resultados obtenidos en ambos casos fueron acordes a lo esperado. La configuración en Tera Term fue de 600~baudios, 8~bits para tamaño de datos, sin bit de paridad y con dos bits de parada.

\begin{figure}[H]
\centering
\subfloat[Resultado obtenido en Emma02]{
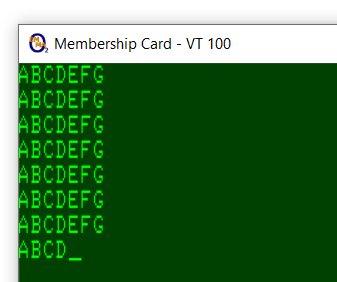
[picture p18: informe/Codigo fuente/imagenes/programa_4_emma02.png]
	
	\label{F:programa_4_emma02}}
\quad
\subfloat[\centering Resultado experimental obtenido con el sistema mínimo]{
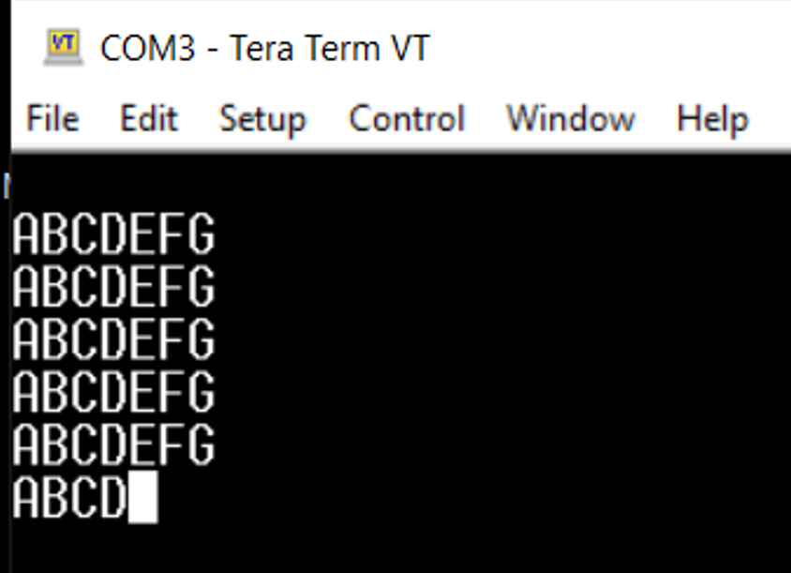
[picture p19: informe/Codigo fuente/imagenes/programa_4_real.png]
	
	\label{F:programa_4_real}}
\caption{Resultados de la ejecución del programa 4}
\label{F:prog_4_resultados}
\end{figure}

%% agregar captura de los caracteres obtenidos en esta parte, simulación y real juntos
%% explicar que el terminal externo es una computadora aparte corriendo Tera Term

\section{Programador}
Para insertar los programas diseñados en la memoria EEPROM fue requerido el diseño de un circuito programador. El diseño adoptado se basa en un Arduino Nano. El software utilizado para el mismo no es de nuestra autoría, se encuentra disponible en la red \cite{pagina_programador}; aun así, se tuvieron que realizar modificaciones, con ayuda de programación en Python, para obtener un resultado satisfactorio, ya que luego de compilar un programa se disponía del mismo en formato Intel y este debía ser interpretado antes de pasarlo al Arduino que se encargaría de grabar la memoria.

Finalmente, el resultado obtenido con el programador sirvió para realizar unos ensayos y grabar memoria, sin embargo, debido a su dificultad de operación se terminó descartando y se reemplazó por el uso del programador presentado en la sección~\ref{C:Programador}. Aun así, por haberse construido, se presenta el esquemático del circuito en la figura~\ref{F:EsquemaProg} y una fotografía del resultado obtenido en la figura~\ref{F:PlacaProg}.

\begin{figure}[ht]
  \centering
  
  \caption{Esquema de programador}
  \label{F:EsquemaProg}
\end{figure}

\begin{figure}[ht]
\centering
\subfloat[Pista diseñada para Programador]{
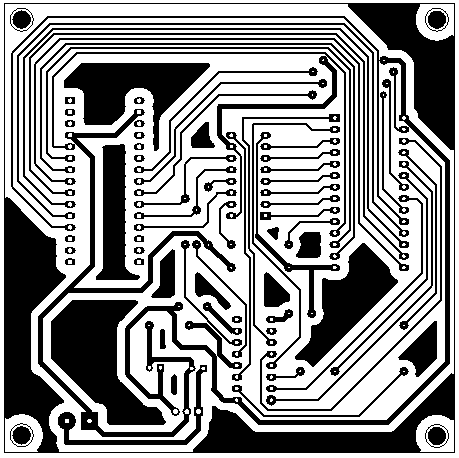
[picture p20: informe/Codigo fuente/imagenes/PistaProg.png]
	
	\label{F:PistaProg}}

\subfloat[Máscara de componentes de Programador]{
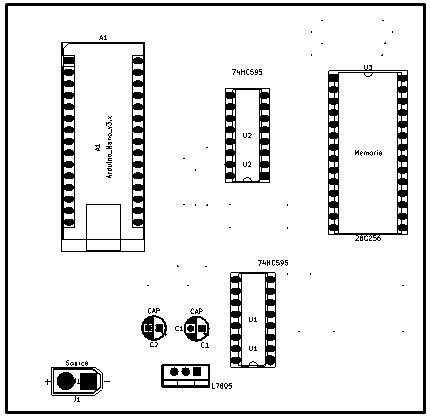
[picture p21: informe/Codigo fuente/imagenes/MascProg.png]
	
	\label{F:MascaraProg}}
\caption{Placa PCB diseñada para el programador de memoria}
\label{F:PlacaProg}
\end{figure}

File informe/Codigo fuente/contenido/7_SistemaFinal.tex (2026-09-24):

\chapter{Sistema Final}

El sistema final es la culminación de los sistemas desarrollados en este proyecto, el cual parte del planteado para el sistema medio agregando funcionalidades extras al sistema que se detallarán más adelante. El mismo se encuentra planteado de manera que presente retrocompatibilidad, es decir, que todo software diseñado tanto para el sistema mínimo como para el sistema medio, debe funcionar en el sistema final. En comparación al sistema medio, se presentan la integración de la fuente de alimentación al sistema, el uso de memorias seriales, sistema de conversión AD, una interfaz de entrada salida expandida y un sistema de comunicación SPI.   
El circuito del sistema se encuentra diseñado, se presenta el esquemático, lista de componentes y diseño de placa PCB. No obstante, al momento de la escritura de este informe, el mismo no ha sido construido.

\section{Esquemáticos}
\label{C:EsqSF}
A modo de simplificar el análisis y presentación del sistema, el esquemático del mismo se presenta de manera modular, comenzando con el esquema generalizado (Ver figura \ref{F:EsquemaSF}) en el cual se pueden ver todas las partes que componen al sistema, sin adentrarse en un funcionamiento específico, para luego en las siguientes secciones pasar a especificar su funcionamiento.
Principalmente en este esquema podemos observar la interconexión entre el microprocesador y los dispositivos o periféricos asociados.

\begin{figure}[ht]
  \centering
  
  \caption{Esquema general de sistema final}
  \label{F:EsquemaSF}
\end{figure}

\clearpage
\subsection{Fuente de alimentación}
La fuente de alimentación utilizada es lineal, basada en un transformador de tensión con punto medio. Dispone de un filtro de línea lo que reduce la distorsión armónica introducida en la red. 
Luego del proceso de rectificación y filtrado, se colocan etapas de regulación de tensión, para así poder alimentar los diferentes elementos del circuito que lo requieran. 

\begin{figure}[ht]
  \centering
  
  \caption{Esquema de fuente de alimentación de sistema final}
  \label{F:EsqSF2}
\end{figure}

\clearpage
\subsection{Mapa de memoria}
El planteo establecido para el mapa de memoria consta de dos modos de operación, un modo de inicio y un modo de ejecución o RUN. El sistema fue pensado de esta manera para tener disponible más memoria RAM en ejecución. 

El modo inicio consiste en la memoria EEPROM 28C256 en la primera mitad del mapa de memoria (0000h a 7FFFh) y en la segunda mitad una memoria RAM en dos tramos de 8000h a F7FFh y luego continúa en FC00h hasta FFF8h, se interrumpe de esta manera la RAM para simplificar el circuito decodificador el cual se presenta más adelante (Sección \ref{C:Decodificador}). La sección del mapa de memoria de F800h hasta FBFFh es destinada a la comunicación SPI. Y finalmente, en la zona superior del mapa de memoria (FFF8h a FFFFh), la memoria RAM DALLAS 1744 posee un apartado para un reloj de tiempo real. 

El modo de ejecución es un modo en el cual se cambia la primera mitad del mapa de memoria (0000h a 7FFFh). El proceso consiste en cambiar la memoria EEPROM del modo de inicio por una memoria RAM. Este proceso debe ser ejecutado por software y para ello en el modo de inicio se debe copiar el contenido de la memoria EEPROM en la RAM1, luego el sistema seguirá funcionando con la memoria de programa en la RAM1 y en la primera mitad del mapa de memoria se tendrá disponible la memoria RAM2. 

\begin{figure}[ht]
  \centering
  
  \caption{Esquema de Mapa de memoria de sistema final}
  \label{F:EsqSF3}
\end{figure}

\clearpage
\subsection{Memorias seriales}
El trabajo con memorias seriales fue planteado para diferentes tecnologías de memorias, específicamente del tipo EEPROM, FRAM y SDcard. Para la comunicación I2C se prevé el uso de un sistema de comunicación por software utilizando la interfaz de entrada salida presentada en la sección \ref{C:I/O} e interactuando con el acondicionamiento presentado en \ref{C:BUSI2C}, mientras que para la comunicación SPI, se diseñó un sistema por hardware presentado en la sección \ref{C:esqSPI}. En el esquema de la figura \ref{F:EsqSF4} se observan las etiquetas de interconexión con el resto del circuito.
\begin{figure}[ht]
  \centering
  
  \caption{Esquema de memorias seriales de sistema final}
  \label{F:EsqSF4}
\end{figure}

\clearpage
\subsection{Conversor analógico digital}

El sistema de conversión analógico-digital se basa en el MAX127 \cite{datasheet_max127}. Este conversor de 12 bits es configurable, lo que permite seleccionar el rango de tensiones a medir por cada canal y se realiza mediante comunicación I2C. Los rangos de medición pueden ser:
\begin{itemize}
    \item 0~V a 5~V
    \item -5~V a 5~V
    \item 0~V a 10~V
    \item -10~V a 10~V
\end{itemize}

Para el acondicionamiento de señal se utilizan amplificadores operacionales OPA4277~\cite{datasheet_OPA4277}. Los amplificadores operacionales se configuraron como conversores de corriente a tensión, de 4-20~mA a 0-10~V. Se concibió el diseño de esta manera, ya que en caso de que se requiera medir tensiones, el circuito puede ser modificado para que los amplificadores operacionales funcionen como seguidores de tensión. Basta con modificar el rango de medición por software para que la lectura refleje correctamente el valor a la entrada. 

\begin{figure}[ht]
  \centering
  
  \caption{Esquema de conversor analógico digital de sistema final}
  \label{F:EsqSF5}
\end{figure}

\clearpage
\subsection{Microprocesador}
En el esquema del microprocesador se observa su interacción con el resto del circuito. Es interesante destacar el latch 74HC573~\cite{datasheet_74HC573} el cual se encarga de transmitir los bits más significativos del bus de direcciones (A8-A15), esta configuración de microprocesador/latch para el direccionamiento es propia de la arquitectura propuesta por el CDP1802. Sin embargo, se utiliza un circuito integrado distinto al del sistema medio ya que su distribución de pines permite simplificar el diseño de la placa PCB. En el esquema también se puede observar una interfaz de usuario compuesta por pulsadores para señal de entrada y LEDs para señal de salida. 
El circuito oscilador que se presenta en el esquema está construido a partir de un cristal de 4~MHz. Es importante destacar que en la hoja de datos del microprocesador la frecuencia máxima para las condiciones de trabajo que establecemos es de 3,2~MHz, sin embargo, en la práctica es utilizado a mayor frecuencia y existen muchos casos prácticos que corroboran el funcionamiento con overclocking, como en la computadora Membership Card mencionada anteriormente \cite{membership-card}. 

\begin{figure}[ht]
  \centering
  
  \caption{Esquema de conexión de microprocesador de sistema final}
  \label{F:EsqSF6}
\end{figure}

\clearpage
\subsection{Decodificador}
\label{C:Decodificador}

El circuito decodificador se encarga de activar la selección de los dispositivos según lo presente en el bus de direcciones. Para ello se utiliza un circuito lógico con compuertas y un decodificador de 3 líneas a 8 líneas 74HC138 \cite{datasheet_74HC138}.

\begin{figure}[ht]
  \centering
  
  \caption{Esquema de decodificador de memoria de sistema final}
  \label{F:EsqSF7}
\end{figure}

\clearpage
\subsection{Comunicación UART}

La comunicación UART se basa principalmente en el software que la controla y se utiliza el pin Q del microprocesador para la transmisión de datos. Para lograr establecer comunicación con una terminal en una computadora personal se requiere la conexión por medio de USB, por lo que se conecta una interfaz FT232RL~\cite{datasheet_FT232RL} que realiza la interpretación y retransmisión de los protocolos. 

\begin{figure}[ht]
  \centering
  
  \caption{Esquema de comunicación UART de sistema final}
  \label{F:EsqSF8}
\end{figure}

\clearpage
\subsection{Comunicación SPI}
\label{C:esqSPI}

En el esquemático de la figura~\ref{F:EsqSF9} se observa un circuito diseñado para realizar una comunicación basada en el protocolo SPI. Fue planteado con el objetivo de simplificar el procesamiento de datos en el microprocesador, realizándose un gran número de iteraciones en el circuito de manera transparente para el procesador. 

En principio se debe considerar que el sistema planteado cuenta con una señal de reloj proveniente de un cristal oscilador compatible con CMOS. Este cristal, al igual que el conectado al microprocesador, es de 4~MHz. Considerando que las instrucciones en el procesador duran 8 ciclos de reloj, se tendrá una velocidad de procesamiento mayor en el hardware diseñado. Esto se representa más adelante en los diagramas temporales. 

Básicamente el sistema presentado consiste en hacer trabajar 2 registros de desplazamiento (shift-register), uno para enviar datos y el otro para recibirlos. 

Para el envío de datos se utiliza un registro de desplazamiento de entrada paralela y salida serie, el MC14014 \cite{datasheet_MC14014B} (también se encuentra como CD4014). Este dispositivo cuenta con un registro interno el cual guarda el dato disponible en el bus al recibir una señal en estado alto en el pin PL. La lectura de los puertos de entrada se realiza con la señal de clock, por lo que para el guardado de los datos en el bus se debe detectar un flanco ascendente en el pin CP. Una vez guardado el dato en el registro, se encuentra listo para transmitirlo, este proceso se acciona con una señal de estado bajo en el pin PL y se transmite de manera serial con las transiciones positivas de la señal de reloj. 

Para la recepción de datos se utiliza un registro de desplazamiento de entrada serial y salida paralelo, el 74HC595 \cite{datasheet_74HC595}. Este dispositivo cuenta con una entrada serial, por la cual toma el dato a almacenar, realizando una lectura en dicha entrada por cada flanco de reloj detectado. El dato presente en el registro de desplazamiento varía por cada ciclo de reloj, por lo que al transcurrir 8 ciclos se encuentra completo el registro, para guardar este dato y que no se vea alterado por el transcurso de los posteriores ciclos, se utiliza el pin RCLK que permite guardar el dato en un registro paralelo. Para que este dato sea presentado en la salida paralelo, se pone en estado bajo el pin de output enable $\overline{\text{OE}}$.

La señal de clock utilizada para los integrados mencionados anteriormente se genera a partir del circuito establecido entre el cristal oscilador, el flip flop D 74HC74, el contador 74HC161 y el flip flop JK 74HC73 \cite{datasheet_74HC161, datasheet_74HC73, datasheet_74HC74}. La topología presentada en el esquema detecta el inicio del ciclo al recibir la señal proveniente de PC7, poniendo en estado alto el pin 4 del 74HC74, la señal generada por Q inicializa el contador. En el contador se toma la señal Q0 como señal de reloj, la cual tendrá una frecuencia de 2~MHz y luego cuando el contador se desborda la salida TC se pone en alto, esta señal es resguardada por el flip flop 74HC73 y utilizada como señal de reinicio del flip flop 74HC74. De esta manera se genera una señal oscilante de 2~MHz a la salida pero que solo tiene 8 pulsos, lo necesario para realizar el envío de un byte. 

\begin{figure}[ht]
  \centering
  
  \caption{Esquema de comunicación SPI de sistema final}
  \label{F:EsqSF9}
\end{figure}

Para el control del sistema se desarrolló un algoritmo simple el cual se presenta en el listado \ref{L:instrucciones_V3}. El funcionamiento general de este sistema se puede desglosar en tres partes. El proceso en el cual se guarda el dato a transmitir, presentado en la figura~\ref{F:DT1_SPI}; la transmisión, presentada en la figura~\ref{F:DT2_SPI}, y la lectura del dato recibido, presentada en la figura~\ref{F:DT3_SPI}. El código assembler presentado en los gráficos se corresponde con el algoritmo presentado en el listado \ref{L:instrucciones_V3}.

\begin{figure}[H]
  \centering
  
  \caption{Proceso de guardado de dato a transmitir}
  \label{F:DT1_SPI}
\end{figure}

\begin{figure}[H]
  \centering
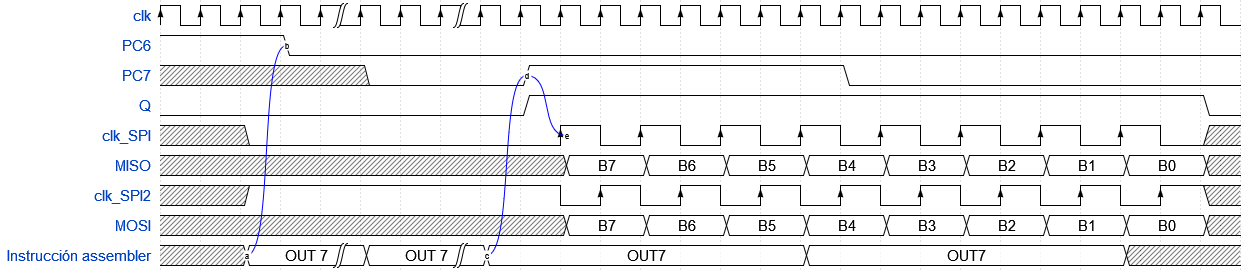
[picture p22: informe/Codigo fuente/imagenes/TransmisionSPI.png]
  
  \caption{Proceso de transmisión SPI}
  \label{F:DT2_SPI}
\end{figure}

\begin{figure}[H]
  \centering
  
  \caption{Proceso de lectura}
  \label{F:DT3_SPI}
\end{figure}

\clearpage
\footnotesize
\lstinputlisting[language=CDP1802, caption={\centering Rutina propuesta para la transmisión utilizando el circuito de comunicación SPI}, label = {L:instrucciones_V3}]{codigo/instrucciones_V3.asm}
\normalsize

\clearpage
\subsection{Alimentación de compuertas}
La alimentación de compuertas es un esquemático en el cual se representan los puntos de alimentación de los circuitos integrados y los elementos no usados de los dispositivos electrónicos. Principalmente sirve para tener una vista más limpia en los demás esquemas.

\begin{figure}[ht]
  \centering
  
  \caption{Esquema de alimentación de compuertas de sistema final}
  \label{F:EsqSF10}
\end{figure}

\clearpage
\subsection{Interfaz I/O}
\label{C:I/O}

El microprocesador CDP1802 posee una arquitectura poco común, la cual cuenta con un mapa de memoria separado para los dispositivos de entrada y salida. Esto le da la capacidad al microprocesador de poder acceder a la memoria y a los dispositivos de entrada y salida al mismo tiempo, es decir, con la ejecución de una sola instrucción.

En el set de instrucciones~\cite{cdp1802_datasheet} puede verse la descripción de las instrucciones de entrada y salida. Por un lado, la instrucción \entreComillas{INP}, para leer datos de un dispositivo de entrada y salida:

\begin{equation*}
    \text{ BUS } \rightarrow \text{ M(R(X)) ; BUS} \rightarrow \text{ D }
\end{equation*}

Es decir, el microprocesador actúa sobre el dispositivo de entrada para que este coloque el dato a leer en el BUS de datos, luego lo almacena en la dirección de memoria apuntada por \textbf{R(X)}.

Algo similar sucede con la instrucción para enviar datos a un dispositivo, denominada \entreComillas{OUT}:

\begin{equation*}
    \text{ M(R(X)) } \rightarrow \text{ BUS ; R(X)+1} \rightarrow \text{ R(X) }
\end{equation*}

Es decir, el microprocesador coloca en el bus de datos el dato guardado en la posición de memoria apuntada por \textbf{R(X)}, y luego actúa sobre el dispositivo de salida para que este lea el dato.

Lo que significa esto es que el microprocesador no puede usar directamente sus pines \textit{Memory Write} ($ \overline{\text{MWR}} $) o \textit{Memory Read} ($ \overline{\text{MRD}} $) en un dispositivo de entrada y salida, dado que los mismos se utilizan para acceder a la memoria. Para solventar eso, el microprocesador utiliza los pines TPA, TPB y $ \overline{\text{MRD}} $, en conjunto con un circuito lógico para actuar sobre el dispositivo de entrada y salida.

Este circuito lógico se obtuvo de la figura~98 de la página~77 del manual del CDP1802~\cite{cdp1802_manual}; en conjunto con la figura~1 de la página~4 de la hoja de datos del CDP1853~\cite{datasheet_CDP1853}, resultando en el circuito de la figura~\ref{F:EsqSF11}.

\begin{figure}[ht]
  \centering
  
  \caption{Esquema de interfaz de entrada/salida de sistema final}
  \label{F:EsqSF11}
\end{figure}

Con este circuito es posible controlar las salidas y leer las entradas del 82C55 utilizando las instrucciones de entrada y salida del CDP1802 (INP y OUT). Todas las instrucciones utilizables se encuentran en las tablas~\ref{T:82c55_inp} y \ref{T:82c55_out}, junto a una descripción de la acción realizada por las mismas.

\begin{table}[ht!]
\caption{Instrucciones INP utilizables con el 82C55}
\label{T:82c55_inp}
\begin{tabular}{|c|c|}
\hline
Instrucción & Acción \\ \hline \hline
INP 4       & Guarda en M(R(X)) y en D el dato presente en el puerto A del 82C55     \\ \hline
INP 5       & Guarda en M(R(X)) y en D el dato presente en el puerto B del 82C55    \\ \hline
INP 6       & Guarda en M(R(X)) y en D el dato presente en el puerto C del 82C55    \\ \hline
INP 7       & Guarda en M(R(X)) y en D el dato presente en el registro de control del 82C55     \\ \hline
\end{tabular}
\end{table}

\begin{table}[ht!]
\caption{Instrucciones OUT utilizables con el 82C55}
\label{T:82c55_out}
\begin{tabular}{|c|c|}
\hline
Instrucción & Acción \\ \hline \hline
OUT 4       & Escribe el dato M(R(X)) en el puerto A del 82C55     \\ \hline
OUT 5       & Escribe el dato M(R(X)) en el puerto B del 82C55     \\ \hline
OUT 6       & Escribe el dato M(R(X)) en el puerto C del 82C55     \\ \hline
OUT 7       & Escribe el dato M(R(X)) en el registro de control del 82C55     \\ \hline
\end{tabular}
\end{table}

\clearpage
\subsection{BUS I2C}
\label{C:BUSI2C}

El esquema presentado para el bus I2C presenta una interfaz construida a partir de transistores NPN. La razón de esta interfaz radica en la característica de los dispositivos I2C, que se conectan al bus mediante una interfaz de drenador abierto. Esto podría generar cortocircuitos en un accionamiento simultáneo del bus, por lo que se requiere de esta interfaz.

\begin{figure}[ht]
  \centering
  
  \caption{Esquema de bus I2C de sistema final}
  \label{F:EsqSF12}
\end{figure}

\clearpage
\section{Lista de componentes}

En la tabla~\ref{T:bom_sis_final} se encuentra la lista de materiales para la construcción del sistema final.

\footnotesize
\begin{longtable}{|p{0.08\textwidth}|p{0.11\textwidth}|p{0.30\textwidth}|p{0.14\textwidth}|p{0.15\textwidth}|}
\caption{Lista de componentes del sistema final} % needs to go inside longtable environment
\label{T:bom_sis_final}
\\
\hline
Cantidad & Etiqueta \newline
           Identificador            & Descripción                               & Fabricante            & Número de parte       \\ \hline \hline \endfirsthead
\hline
Cantidad & Etiqueta \newline
           Identificador            & Descripción                               & Fabricante            & Número de parte       \\ \hline \hline \endhead
1       & U1                        & Microprocesador                           & RCA                   & CDP1802ACE            \\ \hline
1       & U2                        & Latch de 8 bits                           & Philips               & 74HC573N              \\ \hline
1       & U3                        & Memoria EEPROM 32k x 8                    & XICOR                 & X28C256D-25           \\ \hline
1       & U4                        & Memoria EEPROM Serial I2C 128k x 8        & Microchip             & 24LC1025              \\ \hline
1       & U5                        & Time keeping RAM 32K x8                   & Dallas                & DS1744-070            \\ \hline
1       & U6                        & Memoria RAM 32k x 8                       & HYUNDAI               & HY62256ALP-10         \\ \hline
1       & U7                        & Memoria FRAM Serial I2C 8k x 8            & Fujitsu Semiconductor & MB85RC64A            \\ \hline
1       & U8                        & Conversor analógico-digital con interfaz I2C & Maxim Integrated   & MAX127                \\ \hline
1       & U9                        & Regulador de tensión 12~\si{\volt}        & Motorola              & 7812CT                \\ \hline
1       & U10                       & Regulador de tensión 5~\si{\volt}         & ST Microelectronics   & L7805CV               \\ \hline
1       & U11                       & High Precision Operational Amplifier      & Burr-Brown            & OPA4277PA             \\ \hline
1       & U12                       & Regulador de tensión -12~\si{\volt}       & ST Microelectronics   & L7912CV               \\ \hline
5       & U13, U14, U15, U16, U28   & Cuádruple compuerta NAND de dos entradas  & Texas Instruments     & SN74HC00N             \\ \hline
1       & U17                       & Cuádruple compuerta NAND de dos entradas con Schmitt-Trigger & Texas Instruments& SN74HC132N \\ \hline
2       & U18,U30                   & Cuádruple compuerta NOR de dos entradas   & Texas Instruments     & SN74HC02N             \\ \hline
1       & U19                       & Decodificador Multiplexador 3 a 8 líneas  & Texas Instruments     & SN74HC138N            \\ \hline
1       & U20                       & CMOS Programmable Peripheral Interface    & Intersil              & CP82C55A-5Z           \\ \hline
1       & U21                       & Regulador programable shunt               & Fairchild             & LM336Z25              \\ \hline
1       & U24                       & Doble flip-flop tipo D con Set y Reset    & Texas Instruments     & SN74HC74N             \\ \hline
1       & U25                       & Contador binario de 4 bits                & Fairchild Semiconductor & MM74HC161N          \\ \hline
1       & U29                       & Doble flip-flop JK con Set y Reset        & National Semiconductor & MM74HC73N           \\ \hline
1       & U31                       & Registro de desplazamiento de 8 bits      & Texas Instruments     & SN74HC595N            \\ \hline
1       & U32                       & Registro de desplazamiento de 8 estados   & Motorola              & MC14014BCP            \\ \hline
1       & X2                        & XO-22BE-4MHz                              &   \listaVacio                    & \listaVacio                      \\ \hline
1       & XTAL1                     & Cristal \num{4}~\si{\mega\hertz}          & CQ Electronics        & \listaVacio                      \\ \hline
1       & SW1                       & Llave DPDT 6 pines                        & \listaVacio                      & \listaVacio                      \\ \hline
3       & SW2, SW3, SW4             & Pulsador 6mm~x~4,3mm                      &  \listaVacio                     &  \listaVacio                     \\ \hline
5       & T2, T3, T4, T5, T6        & Transistor BJT NPN                        & Motorola              & P2N2222A               \\ \hline
1       & RV1                       & Preset 10~\si{\kilo\ohm}                  &  \listaVacio                     &  \listaVacio                     \\ \hline
1       & D1                        & Puente rectificador de onda completa B380R &            \listaVacio           &  \listaVacio                     \\ \hline
6       & D2, D3, D4, D5, D6, D7    & LED 5~mm                                  &\listaVacio                       &   \listaVacio                    \\ \hline
2       & D8, D9                    & 1N914                                     &\listaVacio                       &  \listaVacio                     \\ \hline
1       & F1                        & Fusible 10~mm 1~\si{\ampere}              &\listaVacio                       &  \listaVacio                     \\ \hline
8       & R1, R2, R3, R5, R21, R22, R23, R27
                                    & Resistor 47~\si{\kilo\ohm} 1/8~\si{\watt} & \listaVacio                      &   \listaVacio                    \\ \hline
1       & R4                        & Resistor 10~\si{\mega\ohm} 1/8~\si{\watt} &  \listaVacio                     &   \listaVacio                    \\ \hline
1       & R6                        & Resistor 330~\si{\ohm} 1/4~\si{\watt}     &  \listaVacio                     &   \listaVacio                    \\ \hline
2       & R7, R8                    & Resistor 1~\si{\kilo\ohm} 1/8~\si{\watt}  &  \listaVacio                     &    \listaVacio                   \\ \hline
3       & R9, R10, R11              & Resistor 220~\si{\ohm} 1/4~\si{\watt}     &    \listaVacio                   &    \listaVacio                   \\ \hline
16      & R12, R13, R14, R15, R16, R17, R18, R38, R39, R40, R41, R46, R47, R56, R57, R60
                                    & Resistor 10~\si{\kilo\ohm} 1/8~\si{\watt} & \listaVacio                      &   \listaVacio                    \\ \hline
5       & R19, R20, R24, R25, R26   & Resistor 100~\si{\kilo\ohm} 1/8~\si{\watt}&  \listaVacio                     &   \listaVacio                    \\ \hline
4       & R28, R30, R36, R52        & Resistor 100~\si{\ohm} 1/4~\si{\watt}     &  \listaVacio                     &   \listaVacio                    \\ \hline
4       & R29, R31, R37, R53        & Resistor 150~\si{\ohm} 1/4~\si{\watt}     &  \listaVacio                     &   \listaVacio                    \\ \hline
8       & R32, R33, R34, R35, R42, R43, R54, R55
                                    & Resistor 390~\si{\kilo\ohm} 1/8~\si{\watt}&  \listaVacio                     & \listaVacio                      \\ \hline
8       & R44, R45, R48, R49, R50, R51, R58, R59
                                    & Resistor 1~\si{\mega\ohm} 1/8~\si{\watt}  &  \listaVacio                     & \listaVacio                      \\ \hline
2       & C2, C3                    & Capacitor cerámico \num{30}~\si{\pico\farad} 50~\si{\volt}
                                                                                &   \listaVacio                    & \listaVacio                      \\ \hline
14       & C5, C7, C8, C29, C30, C31, C14, C15, C18, C32, C33, C39, C40, C43
                                    & Capacitor cerámico \num{0.10}~\si{\micro\farad} 50~\si{\volt}
                                                                                &    \listaVacio                   &   \listaVacio                    \\ \hline
2       & C11, C17                  & Capacitor electrolítico 4700~\si{\micro\farad} 25~\si{\volt}
                                                                                &     \listaVacio                  &   \listaVacio                    \\ \hline
2       & C12, C16                  & Capacitor cerámico \num{0.33}~\si{\micro\farad} 50~\si{\volt}
                                                                                &   \listaVacio                    &  \listaVacio                     \\ \hline
1       & C13                       & Capacitor electrolítico 10~\si{\micro\farad} 25~\si{\volt}
                                                                                &   \listaVacio                    &  \listaVacio                     \\ \hline
1       & C19                       & Capacitor electrolítico \num{0.01}~\si{\micro\farad} 25~\si{\volt}
                                                                                &     \listaVacio                  &  \listaVacio                     \\ \hline
1       & C20                       & Capacitor electrolítico \num{4.7}~\si{\micro\farad} 25~\si{\volt}
                                                                                &   \listaVacio                    &  \listaVacio                     \\ \hline
6       & J1, J2, J33, J48, J49, J50& 1x3 Pines Conectores Macho \num{2.54}~mm  &   \listaVacio                    &  \listaVacio                     \\ \hline
38      & J3, J4, J5, J6, J7, J8, J9, J10, J11, J12, J13, J14, J15, J16, J17, J18, J19, J20, J21, J22, J23, J24, J25, J26, J27, J28, J29, J30, J31, J36, J40, J41, J42, J45, J46, J51, J52, J53
                                    & Pin conector macho (1 \textit{Male Header Pin}) & \listaVacio                      &   \listaVacio                    \\ \hline
3       & J32, J35, J38             & 1x6 Pines Conectores Macho \num{2.54}~mm  & \listaVacio                      & \listaVacio                      \\ \hline
3       & J34, J37, J39             & 1x5 Pines Conectores Macho \num{2.54}~mm  & \listaVacio                      &   \listaVacio                    \\ \hline
2       & J43, J44                  & Bornera 3 pines \num{5.08}~mm             &  \listaVacio                     &  \listaVacio                     \\ \hline
2       & J47, J54                  & 1x12 Pines Conectores Macho \num{2.54}~mm &   \listaVacio                    &  \listaVacio                     \\ \hline
1       & J55                       & 1x2 Pines Conectores Macho \num{2.54}~mm  &   \listaVacio                    &   \listaVacio                    \\ \hline
1       & No aplica                 & Módulo conversor USB-Serial               & Future Technology Devices International & FT232RL \\ \hline
1       & No aplica                 & Módulo adaptador tarjeta micro SD         & \listaVacio  & \listaVacio \\ \hline
\end{longtable}
\normalsize

\section{Placa PCB}
La placa PCB fue desarrollada en KiCad, al igual que los anteriormente mencionados. En la misma se incluyen todas las partes presentadas en los esquemáticos de la sección \ref{C:EsqSF}. Para ello se requirió un tamaño de 30~cm de largo por 30~cm de ancho, en una placa doble faz. Ambos lados y la máscara de componentes se presentan en las figuras \ref{F:PCB_frente}, \ref{F:PCB_atras} y \ref{F:PCB_mascara}. Sin embargo, se adjuntarán en tamaño original en el apéndice. 
Por otro lado, se presenta una visión en tres dimensiones creada por el mismo software de diseño en la figura~\ref{F:PCB_3D}.

\begin{figure}[H]
  \centering
  
  \caption{Pistas de PCB sistema final parte frontal}
  \label{F:PCB_frente}
\end{figure}

\begin{figure}[H]
  \centering
  
  \caption{Pistas de PCB sistema final parte posterior}
  \label{F:PCB_atras}
\end{figure}

\begin{figure}[H]
  \centering
  
  \caption{Máscara de componentes de PCB de sistema final}
  \label{F:PCB_mascara}
\end{figure}

\begin{figure}[H]
  \centering
  
  \caption{Visión en tres dimensiones de sistema final}
  \label{F:PCB_3D}
\end{figure}

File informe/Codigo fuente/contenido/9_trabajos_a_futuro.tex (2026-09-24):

\chapter{Trabajos a futuro}
\label{C:trabajos_a_futuro}

En este capítulo presentaremos una lista de actividades que pueden ser desarrolladas a partir de las bases presentadas en este trabajo. Las actividades propuestas buscan ser alcanzables con un nivel medio de dificultad considerándose como punto de partida las herramientas teórico-prácticas presentadas.

\section{Construcción de sistema final}
Se considera que el primer paso lógico a seguir, luego de lo presentado, es la construcción del sistema final. La construcción del circuito puede proveer información útil, verificando los esquemas planteados o identificando fallas del mismo. En dicha construcción se deben realizar pruebas de alimentación, comunicación entre circuitos integrados, coordinación en instrucciones simples, entre otras pruebas.

\section{Programas de prueba}
Una vez construido el sistema final, este puede ser puesto a prueba con los programas diseñados para el sistema medio y mínimo, sin embargo, estos no explotarían el potencial del circuito presentado en el sistema final. Es por ello que se requiere el diseño de programas de prueba que en principio serán simples para verificar el funcionamiento del circuito y luego podrán ser modificados para realizar tareas más complejas. 

\subsection{Coordinación de interfaz entrada-salida}
El esquema presentado en la figura~\ref{F:EsqSF11} presenta una interfaz de entrada-salida basada en el circuito integrado 82C55. Para el correcto funcionamiento de la interfaz, se debe diseñar un software capaz de controlar los puertos disponibles en el chip. Este software debería ser uno de los primeros en probarse en el sistema final, ya que sirve para comunicarse con gran parte del resto del circuito. 

\subsection{Comunicación I2C}
El circuito final cuenta con circuitos integrados que funcionan a través de la comunicación I2C. Para lograr un funcionamiento óptimo del circuito, es indispensable el planteamiento de un software que permita enviar y recibir instrucciones a estos integrados. 

\subsection{Conversión Analógico-Digital}
Una vez diseñado el sistema de comunicación I2C, se puede plantear un software que permita controlar el sistema de conversión A/D. Para ello debe poder realizar la configuración de los niveles de tensión asociados a la lectura de cada uno de los canales disponibles, así como también realizar la lectura de un canal deseado. 

\subsection{Rutina de cambio en el mapa de memoria}
Para desbloquear un mayor potencial en el funcionamiento del sistema final, se debe plantear un programa de booteo que permita transmitir la memoria de programa a la memoria RAM y luego realice el cambio en el mapa de memoria poniendo en la parte baja del mismo (0000h a 7FFFh) otra memoria RAM, permitiendo almacenar mayor volumen de información en ejecución. 

\subsection{Escritura de memoria SDcard}
Aprovechando la rutina planteada en la sección \ref{C:esqSPI}, diseñar un programa capaz de escribir en una memoria del tipo SDcard. A estas memorias se puede acceder mediante un protocolo SPI, aun así debe ser analizado el funcionamiento específico del grabado en memorias SPI, para lograr modificar la rutina de comunicación SPI y lograr un sistema de escritura satisfactorio. 

\subsection{Copia de memoria}
Una vez que los sistemas de escritura en memoria, tanto los de comunicación I2C, como los de comunicación SPI, funcionen correctamente, se puede desarrollar un software capaz de guardar el contenido de una sección o la totalidad del mapa de memoria en estas memorias no volátiles. 

\section{Rediseño de circuito}
Una vez probado y verificado el sistema final, puede ser rediseñado con el fin de optimizar en algún aspecto su funcionamiento. En esta sección presentamos algunas propuestas.

\subsection{Rediseño de placa PCB}
En caso de que se desee replicar el sistema final, manteniendo su topología fundamental, puede establecerse un nuevo layout que reduzca la distancia entre componentes y el número de puentes. Dado el caso, puede analizarse el uso de GALs o PALs para reemplazar las compuertas lógicas y simplificar la disposición del circuito. 

\subsection{Conversión Digital-Analógico}
Para dotar de aún más herramientas al sistema, se puede plantear la incorporación de un circuito de conversión digital-analógico. Esto permitiría a la computadora interactuar con mayor número de periféricos.

\subsection{Separación galvánica de entradas analógicas}
Para un mejor desempeño de la etapa de conversión analógico-digital (o digital-analógico) puede plantearse la separación galvánica de estas para reducir interferencias que puedan existir.  

\subsection{Traslado del circuito SPI del mapa de memoria principal al mapa de memoria de entrada y salida del CDP1802}
En el diseño realizado del sistema final, el circuito SPI interrumpe la continuidad de la RAM en el mapa de memoria, utilizando 400h direcciones de memoria; sin embargo, solo necesita una dirección.

Como alternativa a esto, se propone modificar el circuito SPI para que el mismo esté en el mapa de memoria de dispositivos de entrada y salida del CDP1802, esto liberaría el espacio de memoria del mapa principal actualmente utilizado por el circuito SPI y, además, se utilizarían las instrucciones INP y OUT para el proceso de lectura y escritura de datos. Es necesario recordar que el 82C55 utiliza las direcciones 4, 5, 6 y 7 de los pines N0, N1 y N2, por lo tanto, quedan libres las direcciones 1, 2 y 3 que pueden utilizarse.

Aunque pareciera una complicación, realizar esta modificación simplificaría el decodificador del mapa de memoria, lo cual debe tenerse en cuenta a la hora de comparar las dos alternativas.

\section{Desarrollo de controlador lógico programable}
Combinando algunas de las soluciones propuestas tanto en software como en hardware, se puede plantear el uso del sistema como PLC. Para poder avanzar en el desarrollo de este sistema se debe contar con un hardware probado y libre de errores a fin de enfocarse en la tarea de desarrollo de software que puede resultar compleja. 

\section{Topología con dos microprocesadores}
A modo didáctico puede ser planteado un nuevo sistema que presente dos microprocesadores, esto permitiría expandir el mapa de memoria, realizar tareas en paralelo, entre otras cosas. El planteamiento del software debería contemplar un proceso de comunicación entre ambos microprocesadores. Las combinaciones y utilidades que pueda presentar son diversas y deben ser desarrolladas con detenimiento. Sin embargo, presentamos una propuesta de funcionamiento.

Establecer un microprocesador maestro el cual delega tareas preestablecidas al segundo microprocesador; la comunicación entre ellos se realizaría mediante los flags EF1-EF4. Para la interacción entre los buses de datos se utilizará un sistema basado en un latch de 8 líneas, que disponga de un flag indicador de disponibilidad de dato.

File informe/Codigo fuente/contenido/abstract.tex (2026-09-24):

% EL RESUMEN EN INGLÉS
% --------------------

\begin{theabstract}{Design and construction of an 8-bit computer based on the CDP1802 microprocessor}{microprocessor, CDP1802, computer, 8-bit, operating system}

The objective of this project is the development and design of a computer based on the CDP1802 microprocessor, and the theoretical foundation and steps followed to achieve it are presented. In the first part of the report, a quick description of the microprocessor, its operating principles and previous circuits based on the same technology are presented. Simple circuits are then developed with their corresponding assembly language programs designed to gain an understanding of the microprocessor instructions and the way in which the microprocessor interacts with the memories. At this point, schematic development processes, PCB boards and simple programs are presented. Then, the development of more complex systems with more available memory is presented. Complex programs created by third parties are tested, revealing the real capacity and limitations of the system developed. Finally, a final design is presented which exploits the capabilities exposed by previous developments and allows greater interaction with external stimuli, such as reading or writing data.

\end{theabstract}

% El entorno 'theabstract' tiene el formato \begin{theabstract}{A} ...B... \end{theabstract} donde A es el título del proyecto traducido de inglés a español y B es el contenido, en inglés, del resumen. Se recomienda buscar ayuda calificada para la elaboración y/o revisión de este resumen.

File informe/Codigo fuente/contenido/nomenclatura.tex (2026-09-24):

% LA NOMENCLATURA
% ---------------

% La nomenclatura se realiza con el paquete 'nomencl'. Para ingresar un nuevo elemento, se debe usar el comando \nomenclature{símbolo}{definición}, ya sea en este archivo nomenclatura.tex (más fácil para encontrar y editar), o en cualquier parte del documento (probablemente cuando se introduce una nueva variable o constante). Para más opciones del paquete, favor referirse a su documentación (https://www.ctan.org/pkg/nomencl). También hay una buena guía de uso en https://www.sharelatex.com/learn/Nomenclatures.

% Formato recomendado
% -------------------

% Variable o constante matemática
% \nomenclature{$V$}{Tensión eléctrica}

% Acrónimo
% \nomenclature{TBH}{Para ser honesto (del inglés \textit{To Be Honest})}

% Si únicamente existen acrónimos del inglés, se puede omitir la frase 'del inglés'. La definición no tiene punto al final.

\nomenclature{$R$}{Resistencia eléctrica}
\nomenclature{$I$}{Corriente eléctrica}
\nomenclature{$V$}{Tensión eléctrica}
\nomenclature{IEEE}{Instituto de Ingenieros Eléctricos y Electrónicos (del inglés \textit{Institute of Electrical and Electronics Engineers})}
\nomenclature{FIO}{Facultad de Ingeniería}
\nomenclature{UNaM}{Universidad Nacional de Misiones}
\nomenclature{ROM}{Read Only Memory}
\nomenclature{RAM}{Random Access Memory}
\nomenclature{CMOS}{Complementary Metal-Oxide Semiconductor}
\nomenclature{E/S}{Entrada/Salida}
\nomenclature{TTL}{Transistor-Transistor Logic}
\nomenclature{I\textsuperscript{2}C}{Inter-Integrated Circuit}
\nomenclature{UART}{Universal Asynchronous Receiver-Transmitter}
\nomenclature{SPI}{Serial Peripheral Interface}
\nomenclature{COSMAC}{Complementary Symmetry Monolithic Array Computer}
\nomenclature{MSB}{Most Significant Bit}
\nomenclature{LSB}{Least Significant Bit}
\nomenclature{EPROM}{Erasable Programmable Read-Only Memory}
\nomenclature{EEPROM}{Electrically Erasable Programmable Read-Only Memory}
\nomenclature{RCA}{Radio Corporation of America}
\nomenclature{EDA}{Electronic Design Automation}
\nomenclature{PCB}{Circuito impreso (del inglés \textit{Printed Circuit Board})}
\nomenclature{PAL}{Programmable Array Logic}
\nomenclature{GAL}{Generic Array Logic}
\nomenclature{PLC}{Programmable Logic Controller}
\nomenclature{KiCad}{Software para el diseño de esquemáticos y PCBs de circuitos electrónicos}
\nomenclature{MRD}{Memory Read}
\nomenclature{MWR}{Memory Write}

\printnomenclature

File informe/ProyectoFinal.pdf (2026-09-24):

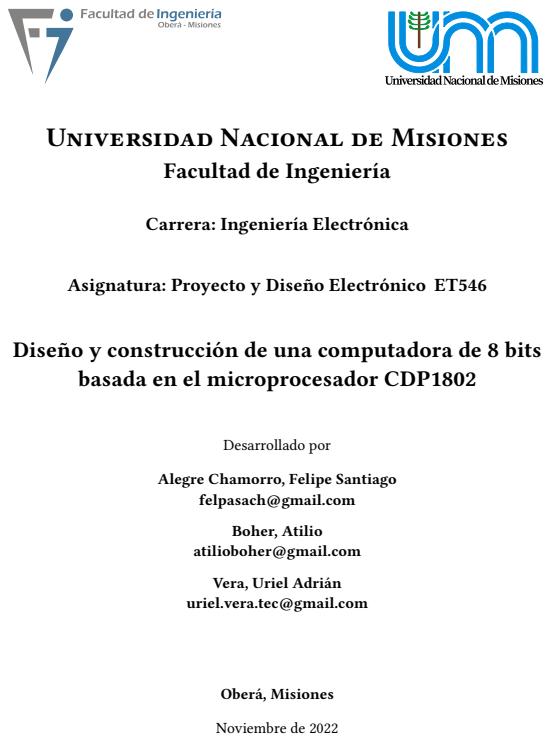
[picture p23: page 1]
Desarrollado por; Oberá, Misiones; Noviembre de 2022

Universidad Nacional de Misiones

Facultad de Ingeniería

Carrera: Ingeniería Electrónica

Asignatura: Proyecto y Diseño Electrónico ET546

Diseño y construcción de una computadora de 8 bits

basada en el microprocesador CDP1802

Alegre Chamorro, Felipe Santiago
felpasach@gmail.com

Boher, Atilio
atilioboher@gmail.com

Vera, Uriel Adrián
uriel.vera.tec@gmail.com

# Diseño y construcción de una computadora de 8 bits basada en el microprocesador CDP1802

Desarrollado por

# Alegre Chamorro, Felipe Santiago felpasach@gmail.com

# Boher, Atilio atilioboher@gmail.com

# Vera, Uriel Adrián uriel.vera.tec@gmail.com

# Proyecto y Diseño Electrónico ET546

Aprobado por

Ing. Ricardo A. Korpys

# Profesor tutor

Mgter. Ing. Guillermo Alfredo Fernández | Dr. Ing. Javier Ernesto Kolodziej
Profesor lector | Profesor lector

Noviembre de 2022

# Resumen

# Diseño y construcción de una computadora de 8 bits basada en el microprocesador CDP1802

Desarrollado por

# Alegre Chamorro, Felipe Santiago Boher, Atilio Vera, Uriel Adrián

Universidad Nacional de Misiones

Facultad de Ingeniería

Profesor tutor: Ing. Ricardo A. Korpys

Noviembre de 2022

El presente trabajo tiene como objetivo la proyección y el diseño de una computadora basada en

el microprocesador CDP1802, presentando la fundamentación teórica y la serie de pasos seguidos para

su implementación. En principio, se presenta una descripción breve del microprocesador, los principios

de funcionamiento y circuitos previos basados en la misma tecnología. Luego se exponen los circuitos

simples donde se implementan programas en lenguaje ensamblador pensados para lograr un entendi-

miento de las instrucciones del microprocesador y la forma en la que este interactúa con las memorias.

En tercer lugar, se exponen los esquemas, las placas de circuito impreso y programas simples que com-

plementan los conceptos previos. Seguidamente, se presenta el desarrollo de sistemas más complejos

con mayor disponibilidad de memoria e interacción con esta. Se han probado programas complejos

desarrollados por terceros que ponen en evidencia la capacidad de procesamiento del sistema y los

límites alcanzables por el mismo. Finalmente, se presenta el diseño final que es una evolución de los

sistemas anteriores, con mayor funcionalidad y aplicabilidad en diferentes entornos, como en la lectura

o escritura de datos.

Palabras clave: microprocesador, CDP1802, computadora, 8 bits, sistema operativo.

# Acerca de Proyecto y Diseño Electrónico

El Proyecto Electrónico es un curso anual bajo la modalidad de trabajo individual o grupal supervisado, con el propósito de

aplicar estrategias de diseño y análisis a un problema de temática abierta de la ingeniería electrónica.

# Abstract

# Design and construction of an 8-bit computer based on the CDP1802 microprocessor

## Translated from the original Spanish title: “Diseño y construcción de una

## computadora de 8 bits basada en el microprocesador CDP1802”

by

# Alegre Chamorro, Felipe Santiago Boher, Atilio Vera, Uriel Adrián

National University of Misiones

Engineering Faculty

Tutor: Ing. Ricardo A. Korpys

November 2022

The objective of this project is the development and design of a computer based on the CDP1802

microprocessor, and the theoretical foundation and steps followed to achieve it are presented. In the

first part of the report, a quick description of the microprocessor, its operating principles and previous

circuits based on the same technology are presented. Simple circuits are then developed with their

corresponding assembly language programs designed to gain an understanding of the microprocessor

instructions and the way in which the microprocessor interacts with the memories. At this point, sche-

matic development processes, PCB boards and simple programs are presented. Then, the development

of more complex systems with more available memory is presented. Complex programs created by

third parties are tested, revealing the real capacity and limitations of the system developed. Finally, a

final design is presented which exploits the capabilities exposed by previous developments and allows

greater interaction with external stimuli, such as reading or writing data.

Keywords: microprocessor, CDP1802, computer, 8-bit, operating system.

# About Proyecto y Diseño Electrónico (“Electronic Project”)

The “Electronic Project” is a one-year course of supervised individual or group work, with the purpose of applying design

and analysis strategies to an open-topic problem in electronic engineering.

# Índice general

Índice general | ix
Índice de figuras | xii
Índice de fotografías | xv
Índice de tablas | xv
1 Introducción | 1
2 Introducción al microprocesador CDP1802 | 3
3 Programas utilizados | 17

ix

x | Índice general
4 Pruebas en el COSMAC ELF II | 33
5 Sistema mínimo | 35
6 Sistema medio | 53
7 Sistema Final | 67
8 Conclusiones | 103

9 Trabajos a futuro | 105
9.1. | Construcción de sistema final | | | 105
9.2. | Programas de prueba | | | 105
9.2.1. | Coordinación de interfaz entrada-salida | | | 105
9.2.2. | Comunicación I2C | | 105
9.2.3. | Conversión Analógico-Digital | | 106
9.2.4. | Rutina de cambio en el mapa de memoria | | | 106
9.2.5. | Escritura de memoria SDcard | | 106
9.2.6. | Copia de memoria | | | 106
9.3. | Rediseño de circuito | | 106
9.3.1. | Rediseño de placa PCB | | 106
9.3.2. | Conversión Digital-Analógico | | 107
9.3.3. | Separación galvánica de entradas analógicas | | 107
9.3.4. Traslado del circuito SPI del mapa de memoria principal al mapa de memoria
de entrada y salida del CDP1802 | | 107
9.4. | Desarrollo de controlador lógico programable | | | 107
9.5. | Topología con dos microprocesadores | | 107
10 Lineamientos para el desarrollo del sistema operativo | 109
Bibliografía | 111
A Protocolos de Comunicación Serial | 115
A.1. | UART | | 115
A.2. | I²C | | | 116
A.3. | SPI | | | 121
B Formato Intel (Archivo .hex) | 123
C Programas escritos para el sistema mínimo | 125
C.1. | Programa 1: Parpadeo LED Q | | 125
C.2. | Programa 2: LED Q se enciende al presionar pulsador | | | 127
C.3. | Programa 3: LED Q parpadea al presionar pulsador | | | 128
C.4. | Programa 4: Transmisión serial de caracteres | | 129

xi

xii | Índice de figuras
D Esquemas circuitales y circuitos impresos | 133

# Índice de figuras

2.1. | CDP1802 en encapsulado DIP40 | | | 4
2.2. | Distribución de pines del CDP1802 | | 4
2.3. | Fotografía del COSMAC ELF de la revista Popular Electronics | | 5
2.4. | Fotografía obtenida en línea del COSMAC ELF II | | 6
2.5. | Fotografía obtenida en línea del Membership Card | | 7
2.6. | Circuitos impresos Membership Card | | 8
(a). | PCB Membership Card | | 8
(b). | PCB Membership Card Panel Frontal | | 8
2.7. Diagrama de bloques de un sistema computacional típico usando el microprocesador CDP1802 11
2.8. | Estructura interna del microprocesador CDP1802 | | | 14
2.9. | Formato de instrucción | | | 15
3.1. | Extensiones utilizadas en Visual Studio Code | | 17
(a). | Extensión para visualización en Assembler | | 17
(b). | Extensión para visualización de formato Intel | | 17
3.2. | Extensión para resaltar sintaxis de código en assembler | | | 18
3.3. | Extensión para resaltar la composición de archivos en formato Intel | | 18
3.4. | Configuración inicial de Git | | 19
(a). | Abrir Git | | 19
(b). | Comandos para la configuración inicial | | 19
3.5. | Configuración de Git relacionada a difftool | | 20
3.6. | Comando para comparar dos archivos con Git | | | 20
3.7. | Ejemplo de comparación | | | 20
3.8. | Apertura de ventana de comandos en directorio | | | 21
3.9. | Resultado del ensamblado en ventana de comandos | | | 22
3.10. Ensamblado con script Batch | | 22
(a). | Instrucciones Batch para el ensamblado con doble click | | 22
(b). | Uso del archivo .bat | | 22
3.11. Computadoras disponibles que utilizan el CDP1802 | | | 23
3.12. Seleccionar programa | | | 23
3.13. Seleccionar programa y configuración | | 24
3.14. Seleccionar programa en Emma02 | | 25

Índice de figuras | xiii
3.15. Direct Assembler | | | 25
3.16. Registrar instrucciones ejecutadas y visualización de Registros internos | | 26
3.17. Captura de instrucciones ejecutadas | | 26
3.18. Tamaño y tipo de letra de la terminal | | 27
3.19. Cargado de programas a través de la terminal | | 28
(a). | Opción de envío de archivo | | | 28
(b). | Configuración de delay | | 28
3.20. Herramienta para cambio de carácter de salto de línea en Multi Commander | | | 29
3.21. Programador universal XGecu TL866-3G | | 30
3.22. Entorno gráfico del programa del programador universal XGecu TL866-3G | | 30
3.23. Entorno gráfico del editor de esquemas del software KiCad | | 31
3.24. Entorno gráfico del editor de circuito impreso del software KiCad | | 32
5.1. | Diagrama de bloques del sistema mínimo | | | 35
5.2. | Mapa de memoria Sistema Mínimo | | 36
5.3. | Esquema de sistema mínimo | | | 38
5.4. | Placa PCB diseñada para sistema mínimo | | | 39
(a). | Pista diseñada para sistema mínimo | | | 39
(b). | Máscara de componentes sistema mínimo | | | 39
5.5. | Programa 1 | | 42
5.6. | Programa 2 | | 43
5.7. | Programa 3 | | 44
5.8. | Programa 4 | | 46
(a). | Rutina principal | | 46
(b). | Rutina de transmisión | | | 46
5.9. | Configuración utilizada en el simulador Emma02 | | 48
5.10. Resultados de la ejecución del programa 4 | | 49
(a). | Resultado obtenido en Emma02 | | 49
(b). | Resultado experimental obtenido con el sistema mínimo | | | 49
5.11. Esquema de programador | | 50
5.12. Placa PCB diseñada para el programador de memoria | | | 51
(a). | Pista diseñada para Programador | | | 51
(b). | Máscara de componentes de Programador | | | 51
6.1. | Diagrama de bloques del sistema medio | | 54
6.2. | Mapa de memoria del sistema medio | | 55
6.3. | Esquemático del sistema medio | | 56
6.4. | Menú del sistema operativo ElfOS sin disco | | 63
6.5. Configuración utilizada en el simulador Emma02 para ejecutar el intérprete Tiny Basic y el
| ElfOS sin disco | | 64
7.1. | Esquema general de sistema final | | | 68

7.2. | Esquema de fuente de alimentación de sistema final | | 70
7.3. | Esquema de Mapa de memoria de sistema final | | 72
7.4. | Esquema de memorias seriales de sistema final | | 74
7.5. | Esquema de conversor analógico digital de sistema final | | 76
7.6. | Esquema de conexión de microprocesador de sistema final | | | 78
7.7. | Esquema de decodificador de memoria de sistema final | | | 80
7.8. | Esquema de comunicación UART de sistema final | | | 82
7.10. Proceso de guardado de dato a transmitir | | | 84
7.11. Proceso de transmisión SPI | | 84
7.12. Proceso de lectura | | | 84
7.9. | Esquema de comunicación SPI de sistema final | | 85
7.13. Esquema de alimentación de compuertas de sistema final | | 89
7.14. Esquema de interfaz de entrada/salida de sistema final | | 92
7.15. Esquema de bus I2C de sistema final | | 94
7.16. Pistas de PCB sistema final parte frontal | | 98
7.17. Pistas de PCB sistema final parte posterior | | | 99
7.18. Máscara de componentes de PCB de sistema final | | | 100
7.19. Visión en tres dimensiones de sistema final | | 101
10.1. Sistema de directorios del ElfOS | | 110
A.1. | Interconexión de interfaz UART | | 115
A.2. | Paquete de datos UART | | 115
A.3. | Interfaz I²C | | 117
(a). | Interconexión de interfaz I²C | | | 117
(b). | Líneas SDA y SCL | | | 117
A.4. | Trama y secuencia de inicio y parada I²C | | 118
(a). | Ejemplo de trama I²C: Escritura en el registro de un Esclavo (M: Maestro; E: Esclavo) 118
(b). | Secuencia de inicio y parada I²C | | | 118
A.5. | Trama I²C en detalle | | 120
(a). | Reconocimiento de bits | | 120
(b). | Secuencias de START y STOP | | 120
(c). | Paquete de Dirección | | 120
(d). | Paquete de Datos | | | 120
(e). | Combinación de Paquetes de Dirección y Datos | | 120
A.6. | Interconexión interfaz SPI | | 122
B.1. | ejemplo de archivo .hex | | 123

xiv

# Índice de fotografías

4.1. | COSMAC ELF II, propiedad de la facultad de ingeniería | | | 33
5.1. | Sistema mínimo construido | | 40
6.1. | Sistema medio construido | | 57

# Índice de tablas

2.1. | Códigos de estado | | | 12
2.2. | Modos del CDP1802 | | 13
2.3. | Numeración decimal, binaria y hexadecimal | | | 15
5.1. | Lista de componentes del sistema mínimo | | 41
6.1. | Lista de componentes del sistema medio | | 58
7.1. | Instrucciones INP utilizables con el 82C55 | | 90
7.2. | Instrucciones OUT utilizables con el 82C55 | | 91
7.3. | Lista de componentes del sistema final | | | 95

xv

# Índice de listados

5.1. | Rutina de retardo de 1 bit-time | | 47
6.1. | Archivo 1802reg.asm con definición de etiquetas para los registros de trabajo | | 60
6.2. | Segmento del código fuente tb0_test.asm con modificación en línea 25 y 28 | | | 61
6.3. Segmento del código fuente tb0_test.asm, modificación de posición de memoria RAM
en el mapa de memoria | | | 62
6.4. Segmento del código fuente tb0_test.asm, definición del baudrate utilizado con cristal
de 4 MHz | | 62
7.1. | Rutina propuesta para la transmisión utilizando el circuito de comunicación SPI . . . . | 86
C.1. | Programa 1 | | 126
C.2. | Programa 2 | | 127
C.3. | Programa 3 | | 128
C.4. | Programa 4 | | 129

xvii

# Capítulo 1

# Introducción

El siguiente trabajo se desarrolla en el marco de la materia “Proyecto y diseño electrónico” de la

carrera de ingeniería electrónica de la Universidad Nacional de Misiones, en la cual se busca proyectar

y diseñar circuitos electrónicos que involucren las competencias desarrolladas durante el cursado de la

carrera. El objetivo principal del presente documento es contemplar todos los conceptos y conocimien-

tos utilizados en el proyecto, diseño e implementación de una microcomputadora de uso general basada

en un microprocesador específico con diferentes funcionalidades como ser conversor analógico-digital

y comunicación UART, entre otras. Teniendo en cuenta la búsqueda de la integración de los concep-

tos adquiridos en la carrera, el desarrollo de una computadora de uso general toma una relevancia

considerable ya que involucra ampliamente los conceptos estudiados, como por ejemplo: el diseño y

construcción de fuentes de alimentación, circuitos analógicos, circuitos digitales, acondicionamiento

de señal, programación en lenguaje ensamblador, entre otros.

Motivados por los avances obtenidos gracias a los primeros microprocesadores y con la disponi-

bilidad de las herramientas tecnológicas de la actualidad, se plantea el diseño de una computadora de

uso general basada en uno de los primeros microprocesadores: El CDP1802, primer microproce-

sador de la tecnología CMOS. Se busca comprender su principio de funcionamiento, arquitectura e

instrucciones de operación para poder integrar en un circuito las diferentes funcionalidades requeridas

y establecer un mecanismo por el cual incorporar tecnologías más modernas como ser las tarjetas SD

o FRAM.

Durante el desarrollo del trabajo se presentarán principios de funcionamiento, bibliografía invo-

lucrada, diseño de esquemas circuitales, construcción de placas de circuito impreso (PCB), diseño de

programas y pruebas de funcionamiento asociadas a los circuitos confeccionados. Para que el análisis

y comprensión de las topologías planteadas sean simples, el desarrollo del trabajo incrementa progre-

sivamente la complejidad de los circuitos implementados.

# 1.1. Objetivos

Objetivo general La idea básica del proyecto es diseñar una microcomputadora basada en el micro-

procesador CDP1802 que esté dotada de capacidad de memoria no volátil (ROM) y memorias volátiles

(RAM) para poder ejecutar funciones específicas y pueda conectarse mediante un puerto a un terminal

(notebook o computadora de escritorio) y utilizar la pantalla y el teclado de la misma como interfaz de

1

2 | 1. Introducción

entrada y salida, para poder así usar el terminal como método principal para la comunicación entre el

usuario y la computadora.

- Diseñar, proyectar y seleccionar los componentes necesarios para la microcomputadora, entre

los más importantes, el microprocesador, la memoria de programa, memoria de datos, buses de

comunicación, integrados, etc. Para ello debe realizarse el estudio adecuado de mercado y de

tecnologías ya existentes para implementar el sistema.

- Realizar un diagrama esquemático de un sistema mínimo, de preferencia de manera manual (lápiz

y papel), para así obtener un acercamiento general de los elementos mínimos e indispensables

para lograr el funcionamiento de la microcomputadora e introducir a los alumnos en el diseño

de la misma.

- Proyectar e implementar como primera aproximación el sistema mínimo de microcomputadora

donde solamente se utilice el microprocesador, una memoria de programa y los dispositivos ne-

cesarios para el funcionamiento básico (resonadores, integrados, etc.). Para ello se debe realizar

un estudio de la bibliografía correspondiente sobre la arquitectura del microprocesador y de las

instrucciones en lenguaje ensamblador para el funcionamiento del mismo.

- Diseñar y proyectar una fuente de alimentación lineal para energizar la microcomputadora, cu-

yo suministro sea la red de alimentación (220 V/50 Hz) y analizar la necesidad de utilizar un

suministro alternativo (ej. baterías).

- Partiendo del sistema mínimo, proyectar una microcomputadora que esté dotada de memorias

tanto ROM como RAM para su funcionamiento, un bus de puerto serie (Protocolo UART), un

puerto paralelo de 8 bits, un conversor analógico-digital de 8 bits, debe contener una memoria

SD-CARD para la grabación de algún programa que se requiera y analizar el uso de memorias

F-RAM.

# Capítulo 2

# Introducción al microprocesador CDP1802
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

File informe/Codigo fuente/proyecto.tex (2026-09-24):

% ------------------------------------
% UNIVERSIDAD DE COSTA RICA
% Facultad de Ingeniería
% Escuela de Ingeniería Eléctrica
% IE0499 - Proyecto Eléctrico
%
% PLANTILLA Y GUÍA DEL TRABAJO ESCRITO
% Versión: v1.0 (marzo 2017)
% ------------------------------------

% Tipo de documento
\documentclass[final]{proyectoelectrico}

% A. PAQUETES Y MACROS ESPECIALES -------
% Paquetes y definiciones que no están incluidos 
% en la clase proyectoelectrico.cls o que son 
% propios del proyecto.
\input{configuracion.tex}

% Tipografía
\usepackage{libertine}
\usepackage{libertinust1math}
\usepackage[T1]{fontenc}
\renewcommand*{\ttdefault}{cmtt}
\newcommand{\listaVacio}{Varios}

%---------------------------------------

% B. DATOS ------------------------------
% Todos los nombres incluyen dos apellidos,
% acentos y signos de puntuación apropiados.
% Revisar las recomendaciones sobre el título
% y los nombres de los profesores en la guía.

% Título del proyecto
\titulo{Diseño y construcción de una computadora de 8 bits basada en el microprocesador CDP1802}

% Autor (nombre y carné)
\autoruno{Alegre Chamorro, Felipe Santiago}
\carneuno{A-3484/3}
\emailuno{felpasach@gmail.com}

\autordos{Boher, Atilio}
\carnedos{B-3534/3}
\emaildos{atilioboher@gmail.com}

\autortres{Vera, Uriel Adrián}
\carnetres{V-3295/6}
\emailtres{uriel.vera.tec@gmail.com}

% Profesor(a) guía
% (Ing.) Nombre Apellido Apellido(, título)
\guia{Ing. Ricardo A. Korpys}

% Profesores lectores 
\lectorA{Mgter. Ing. Guillermo Alfredo Fernández}
\lectorB{Dr. Ing. Javier Ernesto Kolodziej}

% Fecha de entrega del trabajo escrito
\mes{11}	% Número del mes
\ano{2022}	% Formato AAAA
% ---------------------------------------

% C. CONTENIDOS -------------------------

\hypersetup{citecolor=black} % esto es el color en el que aparecen las citas cuando se usa el comando \cite{}, por defecto las llaves están el negro y el número en azul

%%%%%%%%%%%%%%%%%%%
\begin{document}
%%%%%%%%%%%%%%%%%%%

\frontmatter

% 1. PORTADA
\portada

% 2. HOJA DE APROBACIÓN
\iffinal
\aprobacion
\fi

% 3. RESUMEN (EN ESPAÑOL E INGLÉS)
\input{contenido/resumen.tex}
\input{contenido/abstract.tex}

% 4. RECONOCIMIENTOS
%\iffinal
%\input{contenido/reconocimientos.tex}
%\fi

% 5. TABLAS DE CONTENIDO, FIGURAS Y TABLAS
\tableofcontents
\listoffigures
\listoffotos
\listoftables
\lstlistoflistings

% 6. NOMENCLATURA
% no sé si vamos a usar esto, no me parece necesario
\input{contenido/nomenclatura.tex}

\mainmatter
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

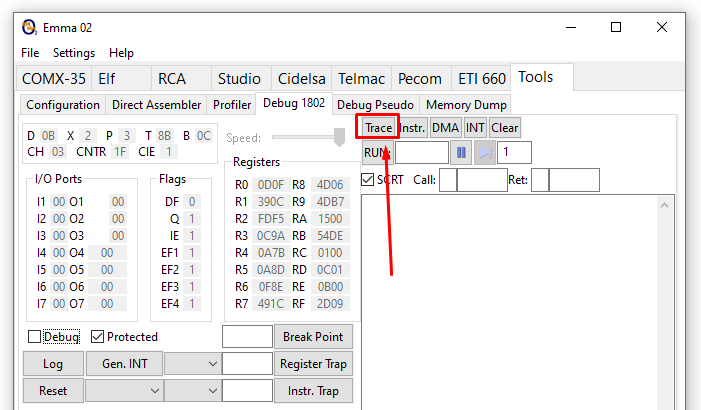
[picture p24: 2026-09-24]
informe/Codigo fuente/imagenes/emma02_trace.png

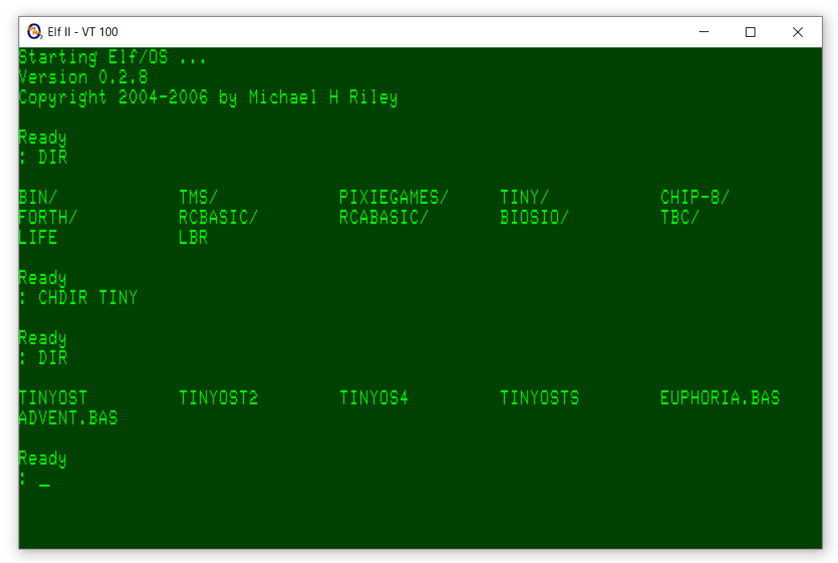
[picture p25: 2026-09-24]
informe/Codigo fuente/imagenes/dir_chdir.png

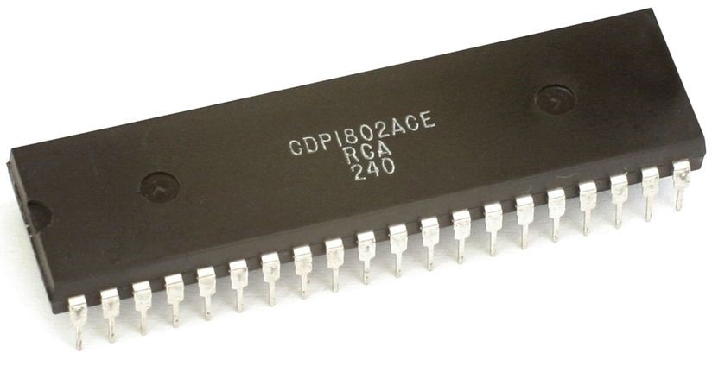
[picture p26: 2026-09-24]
informe/Codigo fuente/imagenes/cdp1802_encapsulado.jpg

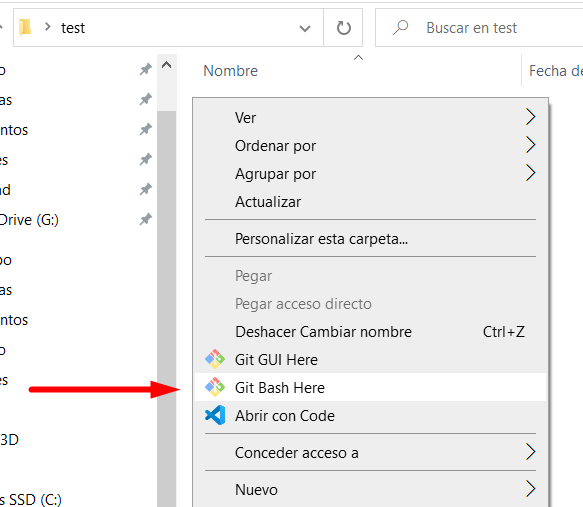
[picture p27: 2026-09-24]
informe/Codigo fuente/imagenes/git_inst_1.png

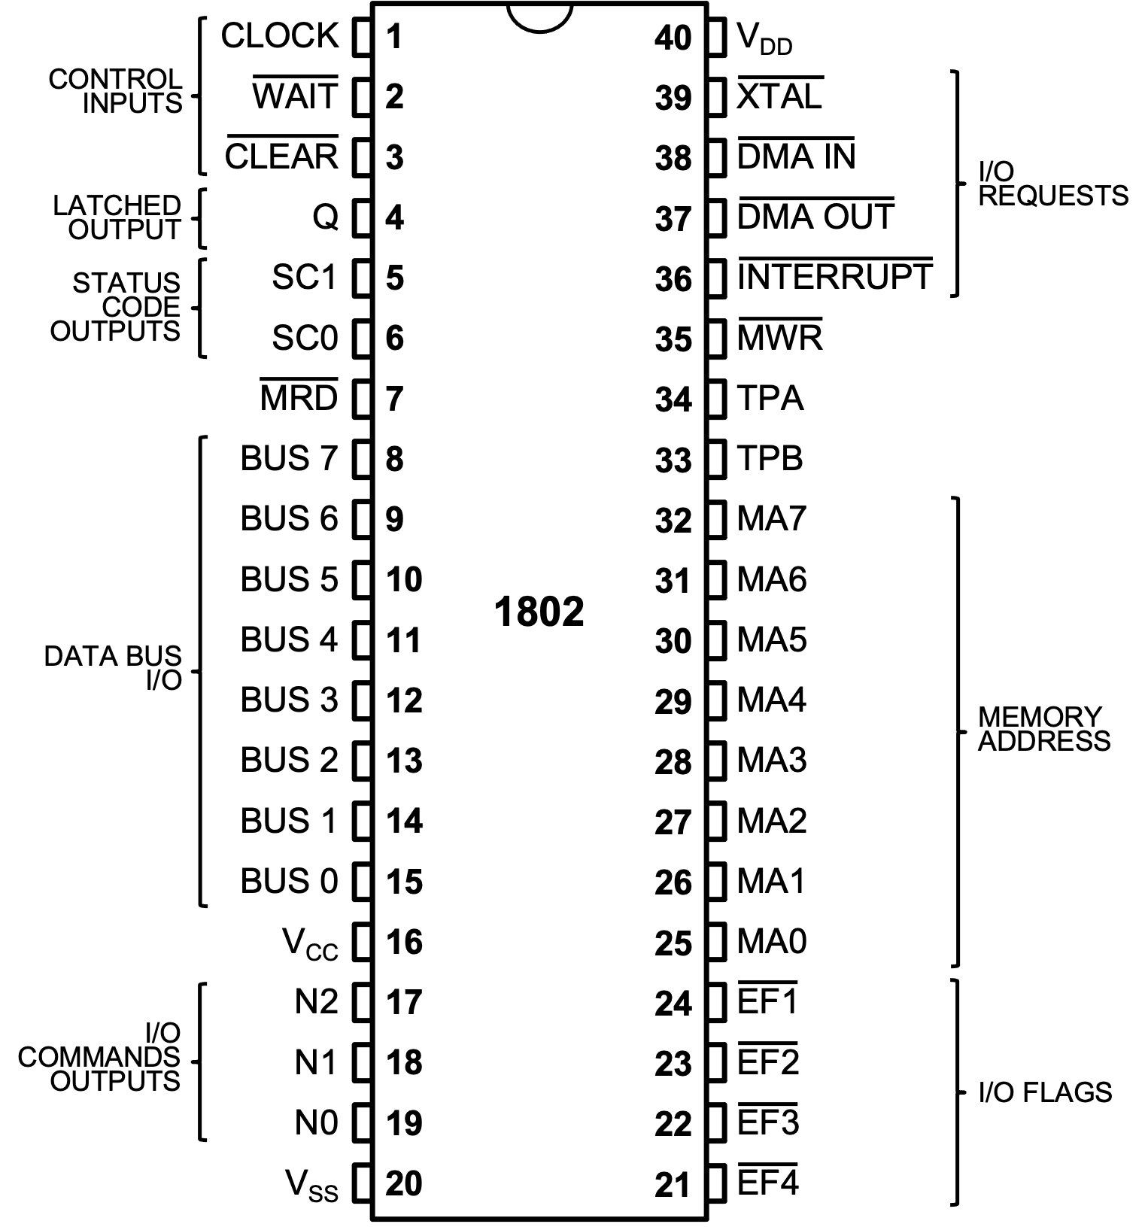
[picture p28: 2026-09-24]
informe/Codigo fuente/imagenes/cdp1802_pinout.png

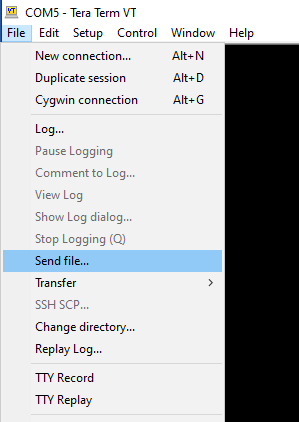
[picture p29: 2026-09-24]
informe/Codigo fuente/imagenes/teraterm_send_file.png

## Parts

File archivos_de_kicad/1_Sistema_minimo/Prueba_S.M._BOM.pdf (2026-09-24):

"Source:" "C:\Users\uriel\Desktop\FACULTAD\5TO\C_PROYECTO Y DISEÑO ELECTRONICO\Diseños_PCB_KIKAD\Prueba_S.M\Prueba_S.M..sch"
"Date:" | "2/5/2022 10:27:57"
"Tool:" | "Eeschema (5.1.12)-1"
"Component Count:" | "38"
"Ref" "Value" | "Part" | "Footprint""Description" | "Vendor"
"C1" "10u" "Device:CP""Capacitor_THT:CP_Radial_D5.0mm_P2.00mm" | "Polarized capacitor" ""
"C2" "0,1u" | "Device:C" "Capacitor_THT:C_Disc_D8.0mm_W2.5mm_P5.00mm" "Unpolarized capacitor" | ""
"C3" "0,1u" | "Device:C" "Capacitor_THT:C_Disc_D5.1mm_W3.2mm_P5.00mm" "Unpolarized capacitor" | ""
"C4" "0,1uF" | "Device:C" "Capacitor_THT:C_Disc_D5.1mm_W3.2mm_P5.00mm" "Unpolarized capacitor" | ""
"C5" "30pF" | "Device:C" "Capacitor_THT:C_Disc_D3.0mm_W2.0mm_P2.50mm" "Unpolarized capacitor" | ""
"C6" "30pF" | "Device:C" "Capacitor_THT:C_Disc_D3.0mm_W2.0mm_P2.50mm" "Unpolarized capacitor" | ""
"C7" "0,1u" | "Device:C" "Capacitor_THT:C_Disc_D5.1mm_W3.2mm_P5.00mm" "Unpolarized capacitor" | ""
"D1" "LD271" | "LED:LD271""LED_THT:LED_D5.0mm" | "940nm IR-LED, 5mm" | ""
"J1" "1" | "Connector:Conn_01x01_Male" "Connector_Pin:Pin_D1.0mm_L10.0mm" | "Generic connector, single row, 01x01,
script generated (kicad-library-utils/schlib/autogen/connector/)" | ""
"J2" "2" | "Connector:Conn_01x01_Male" "Connector_Pin:Pin_D1.0mm_L10.0mm" | "Generic connector, single row, 01x01,
script generated (kicad-library-utils/schlib/autogen/connector/)" | ""
"J3" "3" | "Connector:Conn_01x01_Male" "Connector_Pin:Pin_D1.0mm_L10.0mm" | "Generic connector, single row, 01x01,
script generated (kicad-library-utils/schlib/autogen/connector/)" | ""
"J4" "4" | "Connector:Conn_01x01_Male" "Connector_Pin:Pin_D1.0mm_L10.0mm" | "Generic connector, single row, 01x01,
script generated (kicad-library-utils/schlib/autogen/connector/)" | ""
"J5" "Voltaje de entrada" | "Connector:Screw_Terminal_01x02" | "TerminalBlock:TerminalBlock_bornier-2_P5.08mm" | "Generic
screw terminal, single row, 01x02, script generated (kicad-library-utils/schlib/autogen/connector/)" ""
"J6" "1" | "Connector:Conn_01x01_Male" "Connector_Pin:Pin_D1.0mm_L10.0mm" | "Generic connector, single row, 01x01,
script generated (kicad-library-utils/schlib/autogen/connector/)" | ""
"J7" "1" | "Connector:Conn_01x01_Male" "Connector_Pin:Pin_D1.0mm_L10.0mm" | "Generic connector, single row, 01x01,
script generated (kicad-library-utils/schlib/autogen/connector/)" | ""
"J8" "1" | "Connector:Conn_01x01_Male" "Connector_Pin:Pin_D1.0mm_L10.0mm" | "Generic connector, single row, 01x01,
script generated (kicad-library-utils/schlib/autogen/connector/)" | ""
"J9" "1" | "Connector:Conn_01x01_Male" "Connector_Pin:Pin_D1.0mm_L10.0mm" | "Generic connector, single row, 01x01,
script generated (kicad-library-utils/schlib/autogen/connector/)" | ""
"J10" "jumA8" | "Connector:Conn_01x03_Male" "Connector_PinHeader_2.54mm:PinHeader_1x03_P2.54mm_Vertical" | "Generic
connector, single row, 01x03, script generated (kicad-library-utils/schlib/autogen/connector/)" ""
"J11" "jumA9" | "Connector:Conn_01x03_Male" "Connector_PinHeader_2.54mm:PinHeader_1x03_P2.54mm_Vertical" | "Generic
connector, single row, 01x03, script generated (kicad-library-utils/schlib/autogen/connector/)" ""
"R1" "47K" "Device:R" "Resistor_THT:R_Axial_DIN0207_L6.3mm_D2.5mm_P10.16mm_Horizontal" | "Resistor" ""
"R2" "47K" "Device:R" "Resistor_THT:R_Axial_DIN0207_L6.3mm_D2.5mm_P10.16mm_Horizontal" | "Resistor" ""
"R3" "47K" "Device:R" "Resistor_THT:R_Axial_DIN0207_L6.3mm_D2.5mm_P10.16mm_Horizontal" | "Resistor" ""
"R4" "47K" "Device:R" "Resistor_THT:R_Axial_DIN0207_L6.3mm_D2.5mm_P15.24mm_Horizontal" | "Resistor" ""
"R5" "47K" "Device:R" "Resistor_THT:R_Axial_DIN0207_L6.3mm_D2.5mm_P15.24mm_Horizontal" | "Resistor" ""
"R6" "47K" "Device:R" "Resistor_THT:R_Axial_DIN0207_L6.3mm_D2.5mm_P15.24mm_Horizontal" | "Resistor" ""
"R7" "47K" "Device:R" "Resistor_THT:R_Axial_DIN0207_L6.3mm_D2.5mm_P15.24mm_Horizontal" | "Resistor" ""

"R8" "10M" "Device:R" "Resistor_THT:R_Axial_DIN0207_L6.3mm_D2.5mm_P10.16mm_Horizontal" | "Resistor" ""
"R9" "220" "Device:R" "Resistor_THT:R_Axial_DIN0207_L6.3mm_D2.5mm_P10.16mm_Horizontal" | "Resistor" ""
"R10" "10K" "Device:R" "Resistor_THT:R_Axial_DIN0207_L6.3mm_D2.5mm_P10.16mm_Horizontal" | "Resistor" ""
"R11" "47k" "Device:R" "Resistor_THT:R_Axial_DIN0207_L6.3mm_D2.5mm_P10.16mm_Horizontal" | "Resistor" ""
"R12" "47k" "Device:R" "Resistor_THT:R_Axial_DIN0207_L6.3mm_D2.5mm_P10.16mm_Horizontal" | "Resistor" ""
"R13" "47K" "Device:R" "Resistor_THT:R_Axial_DIN0207_L6.3mm_D2.5mm_P10.16mm_Horizontal" | "Resistor" ""
"SW1" "SW_Push" | "Switch:SW_Push" "Button_Switch_THT:SW_PUSH_6mm_H4.3mm" "Push button switch, generic, two pins" ""
"T1" "PN2222A" | "Transistor_BJT:PN2222A" | "Package_TO_SOT_THT:TO-92_Inline" "1A Ic, 40V Vce, NPN Transistor, General
Purpose Transistor, TO-92" | ""
"U1" "CDP1802ACE" | "CPU:CDP1802ACE" "Package_DIP:DIP-40_W15.24mm" | "8-bit, General Purpose, 5V, 3.2 MHz, DIP-40"
""
"U2" "Ram Comp.""Memory_RAM:CY62256-70PC" | "Package_DIP:DIP-28_W15.24mm" | "256K (32K x 8) Static RAM, 70ns, DIP-28"
""
"U3" "L7805" | "Regulator_Linear:L7805" | "Package_TO_SOT_THT:TO-220-3_Vertical" "Positive 1.5A 35V Linear Regulator,
Fixed Output 5V, TO-220/TO-263/TO-252" ""
"XTAL1" | "4 MHz" | "Device:Crystal" "Crystal:Crystal_HC18-U_Vertical" "Two pin crystal" | ""

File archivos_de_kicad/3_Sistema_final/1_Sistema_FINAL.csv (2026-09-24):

Source: | C:\Users\felu1\OneDrive\Documentos\proyecto\1_Sistema_FINAL\SF-19-11\Diseños_Finales\1_Sistema_FINAL\1_Sistema_FINAL.kicad_sch
Date: | 20/11/2022 13:54:38
Tool: | Eeschema (6.0.6)
Generator: | C:\Program Files\KiCad\6.0\bin\scripting\plugins/bom_csv_grouped_by_value.py
Component Count: | 206
Individual Components:
Item | Qty | Reference(s) | Value | LibPart | Footprint | Datasheet
 |  | C1 | 0.1uF | Device:C | Capacitor_THT:C_Disc_D3.0mm_W1.6mm_P2.50mm | ~
 |  | C2 | 30pF | Device:C | Capacitor_THT:C_Disc_D4.3mm_W1.9mm_P5.00mm | ~
 |  | C3 | 30pF | Device:C | Capacitor_THT:C_Disc_D4.3mm_W1.9mm_P5.00mm | ~
 |  | C4 | 0.1uF | Device:C | Capacitor_THT:C_Disc_D3.0mm_W1.6mm_P2.50mm | ~
 |  | C5 | 0,1uF | Device:C | Capacitor_THT:C_Disc_D3.0mm_W1.6mm_P2.50mm | ~
 |  | C6 | 0.1uF | Device:C | Capacitor_THT:C_Disc_D3.0mm_W1.6mm_P2.50mm | ~
 |  | C7 | 0,1uF | Device:C | Capacitor_THT:C_Disc_D3.0mm_W1.6mm_P2.50mm | ~
 |  | C8 | 0,1uF | Device:C | Capacitor_THT:C_Disc_D3.0mm_W1.6mm_P2.50mm | ~
 |  | C9 | 0.1uF | Device:C | Capacitor_THT:C_Disc_D3.0mm_W1.6mm_P2.50mm | ~
 |  | C10 | 0.1uF | Device:C | Capacitor_THT:C_Disc_D3.0mm_W1.6mm_P2.50mm | ~
 |  | C11 | 4700 uf | Device:C_Polarized | Capacitor_THT:C_Rect_L11.5mm_W4.3mm_P10.00mm_MKT | ~
 |  | C12 | 0.33 | Device:C | Capacitor_THT:C_Disc_D3.0mm_W1.6mm_P2.50mm | ~
 |  | C13 | 10 uf | Device:C_Polarized | Capacitor_THT:CP_Radial_D5.0mm_P2.00mm | ~
 |  | C14 | 0.1uf | Device:C | Capacitor_THT:C_Disc_D3.0mm_W1.6mm_P2.50mm | ~
 |  | C15 | 0.1uf | Device:C | Capacitor_THT:C_Disc_D3.0mm_W1.6mm_P2.50mm | ~
 |  | C16 | 0.33 | Device:C | Capacitor_THT:C_Disc_D3.0mm_W1.6mm_P2.50mm | ~
 |  | C17 | 4700 uf | Device:C_Polarized | Capacitor_THT:C_Rect_L11.5mm_W2.8mm_P10.00mm_MKT | ~
 |  | C18 | 0.1 uf | Device:C | Capacitor_THT:C_Disc_D3.0mm_W1.6mm_P2.50mm | ~
 |  | C19 | 0.01 uf | Device:C_Polarized | Capacitor_THT:C_Disc_D3.0mm_W1.6mm_P2.50mm | ~
 |  | C20 | 4.7 uf | Device:C_Polarized | Capacitor_THT:CP_Radial_D5.0mm_P2.00mm | ~
 |  | C21 | 0.1uF | Device:C | Capacitor_THT:C_Disc_D3.0mm_W1.6mm_P2.50mm | ~
 |  | C22 | 0.1uF | Device:C | Capacitor_THT:C_Disc_D3.0mm_W1.6mm_P2.50mm | ~
 |  | C23 | 0.1uF | Device:C | Capacitor_THT:C_Disc_D3.0mm_W1.6mm_P2.50mm | ~
 |  | C24 | 0.1uF | Device:C | Capacitor_THT:C_Disc_D3.0mm_W1.6mm_P2.50mm | ~
 |  | C25 | 0.1uF | Device:C | Capacitor_THT:C_Disc_D3.0mm_W1.6mm_P2.50mm | ~
 |  | C26 | 0.1uF | Device:C | Capacitor_THT:C_Disc_D3.0mm_W1.6mm_P2.50mm | ~
 |  | C27 | 0.1uF | Device:C | Capacitor_THT:C_Disc_D3.0mm_W1.6mm_P2.50mm | ~
 |  | C28 | 0.1uF | Device:C | Capacitor_THT:C_Disc_D3.0mm_W1.6mm_P2.50mm | ~
 |  | C29 | 0,1uF | Device:C | Capacitor_THT:C_Disc_D3.0mm_W1.6mm_P2.50mm | ~
 |  | C30 | 0,1uF | Device:C | Capacitor_THT:C_Disc_D3.0mm_W1.6mm_P2.50mm | ~
 |  | C31 | 0,1uF | Device:C | Capacitor_THT:C_Disc_D3.0mm_W1.6mm_P2.50mm | ~
 |  | C32 | C | pspice:C | Capacitor_THT:C_Disc_D3.0mm_W1.6mm_P2.50mm | ~
 |  | C33 | C | pspice:C | Capacitor_THT:C_Disc_D3.0mm_W1.6mm_P2.50mm | ~
 |  | C34 | 0.1uF | Device:C | Capacitor_THT:C_Disc_D3.0mm_W1.6mm_P2.50mm | ~
 |  | C35 | 0.1uF | Device:C | Capacitor_THT:C_Disc_D3.0mm_W1.6mm_P2.50mm | ~
 |  | C36 | 0.1uF | Device:C | Capacitor_THT:C_Disc_D3.0mm_W1.6mm_P2.50mm | ~
 |  | C37 | 0.1uF | Device:C | Capacitor_THT:C_Disc_D3.0mm_W1.6mm_P2.50mm | ~
 |  | C38 | 0.1uF | Device:C | Capacitor_THT:C_Disc_D3.0mm_W1.6mm_P2.50mm | ~
 |  | C39 | C | pspice:C | Capacitor_THT:C_Disc_D3.0mm_W1.6mm_P2.50mm | ~
 |  | C40 | C | pspice:C | Capacitor_THT:C_Disc_D3.0mm_W1.6mm_P2.50mm | ~
 |  | C43 | C | pspice:C | Capacitor_THT:C_Disc_D3.0mm_W1.6mm_P2.50mm | ~
 |  | D1 | B380R | Diode_Bridge:B380R | Diode_THT:Diode_Bridge_Round_D9.0mm | https://diotec.com/tl_files/diotec/files/pdf/datasheets/b40r.pdf
 |  | D2 | LD271 | LED:LD271 | LED_THT:LED_D5.0mm | http://www.alliedelec.com/m/d/40788c34903a719969df15f1fbea1056.pdf
 |  | D3 | LD271 | LED:LD271 | LED_THT:LED_D5.0mm | http://www.alliedelec.com/m/d/40788c34903a719969df15f1fbea1056.pdf
 |  | D4 | LD271 | LED:LD271 | LED_THT:LED_D5.0mm | http://www.alliedelec.com/m/d/40788c34903a719969df15f1fbea1056.pdf
 |  | D5 | LD271 | LED:LD271 | LED_THT:LED_D5.0mm | http://www.alliedelec.com/m/d/40788c34903a719969df15f1fbea1056.pdf
 |  | D6 | LD271 | LED:LD271 | LED_THT:LED_D5.0mm | http://www.alliedelec.com/m/d/40788c34903a719969df15f1fbea1056.pdf
 |  | D7 | LD271 | LED:LD271 | LED_THT:LED_D5.0mm | http://www.alliedelec.com/m/d/40788c34903a719969df15f1fbea1056.pdf
 |  | D8 | 1N914 | Diode:1N914 | Diode_THT:D_DO-35_SOD27_P7.62mm_Horizontal | http://www.vishay.com/docs/85622/1n914.pdf
 |  | D9 | 1N914 | Diode:1N914 | Diode_THT:D_DO-35_SOD27_P7.62mm_Horizontal | http://www.vishay.com/docs/85622/1n914.pdf
 |  | F1 | Fuse | Device:Fuse | Library_fusible:fusible_10mm | ~
 |  | J1 | N1,2,3 | Connector:Conn_01x03_Male | Connector_PinHeader_2.54mm:PinHeader_1x03_P2.54mm_Vertical | ~
 |  | J2 | N1,2,3 | Connector:Conn_01x03_Male | Connector_PinHeader_2.54mm:PinHeader_1x03_P2.54mm_Vertical | ~
 |  | J3 | 1 | Connector:Conn_01x01_Male | Connector_Pin:Pin_D1.0mm_L10.0mm | ~
 |  | J4 | 1 | Connector:Conn_01x01_Male | Connector_Pin:Pin_D1.0mm_L10.0mm | ~
 |  | J5 | 1 | Connector:Conn_01x01_Male | Connector_Pin:Pin_D1.0mm_L10.0mm | ~
 |  | J6 | 1 | Connector:Conn_01x01_Male | Connector_Pin:Pin_D1.0mm_L10.0mm | ~
 |  | J7 | 1 | Connector:Conn_01x01_Male | Connector_Pin:Pin_D1.0mm_L10.0mm | ~
 |  | J8 | 1 | Connector:Conn_01x01_Male | Connector_Pin:Pin_D1.0mm_L10.0mm | ~
 |  | J9 | 1 | Connector:Conn_01x01_Male | Connector_Pin:Pin_D1.0mm_L10.0mm | ~
 |  | J10 | 1 | Connector:Conn_01x01_Male | Connector_Pin:Pin_D1.0mm_L10.0mm | ~
 |  | J11 | 1 | Connector:Conn_01x01_Male | Connector_Pin:Pin_D1.0mm_L10.0mm | ~
 |  | J12 | 1 | Connector:Conn_01x01_Male | Connector_Pin:Pin_D1.0mm_L10.0mm | ~
 |  | J13 | 1 | Connector:Conn_01x01_Male | Connector_Pin:Pin_D1.0mm_L10.0mm | ~
 |  | J14 | 1 | Connector:Conn_01x01_Male | Connector_Pin:Pin_D1.0mm_L10.0mm | ~
 |  | J15 | 1 | Connector:Conn_01x01_Male | Connector_Pin:Pin_D1.0mm_L10.0mm | ~
 |  | J16 | 1 | Connector:Conn_01x01_Male | Connector_Pin:Pin_D1.0mm_L10.0mm | ~
 |  | J17 | 4 | Connector:Conn_01x01_Male | Connector_Pin:Pin_D1.0mm_L10.0mm | ~
 |  | J18 | 4 | Connector:Conn_01x01_Male | Connector_Pin:Pin_D1.0mm_L10.0mm | ~
 |  | J19 | 1 | Connector:Conn_01x01_Male | Connector_Pin:Pin_D1.0mm_L10.0mm | ~
 |  | J20 | 1 | Connector:Conn_01x01_Male | Connector_Pin:Pin_D1.0mm_L10.0mm | ~
 |  | J21 | 3 | Connector:Conn_01x01_Male | Connector_Pin:Pin_D1.0mm_L10.0mm | ~
 |  | J22 | 1 | Connector:Conn_01x01_Male | Connector_Pin:Pin_D1.0mm_L10.0mm | ~
 |  | J23 | 1 | Connector:Conn_01x01_Male | Connector_Pin:Pin_D1.0mm_L10.0mm | ~
 |  | J24 | 1 | Connector:Conn_01x01_Male | Connector_Pin:Pin_D1.0mm_L10.0mm | ~
 |  | J25 | 1 | Connector:Conn_01x01_Male | Connector_Pin:Pin_D1.0mm_L10.0mm | ~
 |  | J26 | 1 | Connector:Conn_01x01_Male | Connector_Pin:Pin_D1.0mm_L10.0mm | ~
 |  | J27 | 1 | Connector:Conn_01x01_Male | Connector_Pin:Pin_D1.0mm_L10.0mm | ~
 |  | J28 | 1 | Connector:Conn_01x01_Male | Connector_Pin:Pin_D1.0mm_L10.0mm | ~
 |  | J29 | 1 | Connector:Conn_01x01_Male | Connector_Pin:Pin_D1.0mm_L10.0mm | ~
 |  | J30 | 1 | Connector:Conn_01x01_Male | Connector_Pin:Pin_D1.0mm_L10.0mm | ~
 |  | J31 | 1 | Connector:Conn_01x01_Male | Connector_Pin:Pin_D1.0mm_L10.0mm | ~
 |  | J32 | Conn_01x06_Male | Connector:Conn_01x06_Male | Connector_PinHeader_2.54mm:PinHeader_1x06_P2.54mm_Vertical | ~
 |  | J33 | N1,2,3 | Connector:Conn_01x03_Male | Connector_PinHeader_2.54mm:PinHeader_1x03_P2.54mm_Vertical | ~
 |  | J34 | Conn_01x05_Male | Connector:Conn_01x05_Male | Connector_PinHeader_2.54mm:PinHeader_1x05_P2.54mm_Vertical | ~
 |  | J35 | Conn_01x06_Male | Connector:Conn_01x06_Male | Connector_PinHeader_2.54mm:PinHeader_1x06_P2.54mm_Vertical | ~
 |  | J36 | 1 | Connector:Conn_01x01_Male | Connector_Pin:Pin_D1.0mm_L10.0mm | ~
 |  | J37 | Conn_01x05_Male | Connector:Conn_01x05_Male | Connector_PinHeader_2.54mm:PinHeader_1x05_P2.54mm_Vertical | ~
 |  | J38 | Conn_01x06_Male | Connector:Conn_01x06_Male | Connector_PinHeader_2.54mm:PinHeader_1x06_P2.54mm_Vertical | ~
 |  | J39 | Conn_01x05_Male | Connector:Conn_01x05_Male | Connector_PinHeader_2.54mm:PinHeader_1x05_P2.54mm_Vertical | ~
 |  | J40 | 1 | Connector:Conn_01x01_Male | Connector_Pin:Pin_D1.0mm_L10.0mm | ~
 |  | J41 | 1 | Connector:Conn_01x01_Male | Connector_Pin:Pin_D1.0mm_L10.0mm | ~
 |  | J42 | 1 | Connector:Conn_01x01_Male | Connector_Pin:Pin_D1.0mm_L10.0mm | ~
 |  | J43 | Screw_Terminal_01x03 | Connector:Screw_Terminal_01x03 | TerminalBlock:TerminalBlock_bornier-3_P5.08mm | ~
 |  | J44 | Screw_Terminal_01x03 | Connector:Screw_Terminal_01x03 | TerminalBlock:TerminalBlock_bornier-3_P5.08mm | ~
 |  | J45 | 1 | Connector:Conn_01x01_Male | Connector_Pin:Pin_D1.0mm_L10.0mm | ~
 |  | J46 | 1 | Connector:Conn_01x01_Male | Connector_Pin:Pin_D1.0mm_L10.0mm | ~
 |  | J47 | Conn_01x12_Male | Connector:Conn_01x12_Male | Connector_PinHeader_2.54mm:PinHeader_1x12_P2.54mm_Vertical | ~
 |  | J48 | N1,2,3 | Connector:Conn_01x03_Male | Connector_PinHeader_2.54mm:PinHeader_1x03_P2.54mm_Vertical | ~
 |  | J49 | N1,2,3 | Connector:Conn_01x03_Male | Connector_PinHeader_2.54mm:PinHeader_1x03_P2.54mm_Vertical | ~
 |  | J50 | N1,2,3 | Connector:Conn_01x03_Male | Connector_PinHeader_2.54mm:PinHeader_1x03_P2.54mm_Vertical | ~
 |  | J51 | 1 | Connector:Conn_01x01_Male | Connector_Pin:Pin_D1.0mm_L10.0mm | ~
 |  | J52 | 1 | Connector:Conn_01x01_Male | Connector_Pin:Pin_D1.0mm_L10.0mm | ~
 |  | J53 | 1 | Connector:Conn_01x01_Male | Connector_Pin:Pin_D1.0mm_L10.0mm | ~
 |  | J54 | Conn_01x12_Male | Connector:Conn_01x12_Male | Connector_PinHeader_2.54mm:PinHeader_1x12_P2.54mm_Vertical | ~
 |  | J55 | Conn_01x02_Male | Connector:Conn_01x02_Male | Connector_PinHeader_2.54mm:PinHeader_1x02_P2.54mm_Vertical | ~
 |  | R1 | 47K | Device:R | Resistor_THT:R_Axial_DIN0207_L6.3mm_D2.5mm_P10.16mm_Horizontal | ~
 |  | R2 | 47K | Device:R | Resistor_THT:R_Axial_DIN0207_L6.3mm_D2.5mm_P10.16mm_Horizontal | ~
 |  | R3 | 47K | Device:R | Resistor_THT:R_Axial_DIN0207_L6.3mm_D2.5mm_P10.16mm_Horizontal | ~
 |  | R4 | 10M | Device:R | Resistor_THT:R_Axial_DIN0207_L6.3mm_D2.5mm_P10.16mm_Horizontal | ~
 |  | R5 | 47k | Device:R | Resistor_THT:R_Axial_DIN0207_L6.3mm_D2.5mm_P10.16mm_Horizontal | ~
 |  | R6 | 330 | Device:R | Resistor_THT:R_Axial_DIN0207_L6.3mm_D2.5mm_P10.16mm_Horizontal | ~
 |  | R7 | 1 k | Device:R | Resistor_THT:R_Axial_DIN0207_L6.3mm_D2.5mm_P10.16mm_Horizontal | ~
 |  | R8 | 1 k | Device:R | Resistor_THT:R_Axial_DIN0207_L6.3mm_D2.5mm_P10.16mm_Horizontal | ~
 |  | R9 | 220 | Device:R | Resistor_THT:R_Axial_DIN0207_L6.3mm_D2.5mm_P10.16mm_Horizontal | ~
 |  | R10 | 220 | Device:R | Resistor_THT:R_Axial_DIN0207_L6.3mm_D2.5mm_P10.16mm_Horizontal | ~
 |  | R11 | 220 | Device:R | Resistor_THT:R_Axial_DIN0207_L6.3mm_D2.5mm_P10.16mm_Horizontal | ~
 |  | R12 | 10K | Device:R | Resistor_THT:R_Axial_DIN0207_L6.3mm_D2.5mm_P10.16mm_Horizontal | ~
 |  | R13 | 10K | Device:R | Resistor_THT:R_Axial_DIN0207_L6.3mm_D2.5mm_P10.16mm_Horizontal | ~
 |  | R14 | 10K | Device:R | Resistor_THT:R_Axial_DIN0207_L6.3mm_D2.5mm_P10.16mm_Horizontal | ~
 |  | R15 | 10K | Device:R | Resistor_THT:R_Axial_DIN0207_L6.3mm_D2.5mm_P10.16mm_Horizontal | ~
 |  | R16 | 10K | Device:R | Resistor_THT:R_Axial_DIN0207_L6.3mm_D2.5mm_P10.16mm_Horizontal | ~
 |  | R17 | 10K | Device:R | Resistor_THT:R_Axial_DIN0207_L6.3mm_D2.5mm_P10.16mm_Horizontal | ~
 |  | R18 | 10K | Device:R | Resistor_THT:R_Axial_DIN0207_L6.3mm_D2.5mm_P10.16mm_Horizontal | ~
 |  | R19 | 100K | Device:R | Resistor_THT:R_Axial_DIN0207_L6.3mm_D2.5mm_P10.16mm_Horizontal | ~
 |  | R20 | 100K | Device:R | Resistor_THT:R_Axial_DIN0207_L6.3mm_D2.5mm_P10.16mm_Horizontal | ~
 |  | R21 | 47k | Device:R | Resistor_THT:R_Axial_DIN0207_L6.3mm_D2.5mm_P15.24mm_Horizontal | ~
 |  | R22 | 47k | Device:R | Resistor_THT:R_Axial_DIN0207_L6.3mm_D2.5mm_P15.24mm_Horizontal | ~
 |  | R23 | 47K | Device:R | Resistor_THT:R_Axial_DIN0207_L6.3mm_D2.5mm_P10.16mm_Horizontal | ~
 |  | R24 | 100k | Device:R | Resistor_THT:R_Axial_DIN0207_L6.3mm_D2.5mm_P10.16mm_Horizontal | ~
 |  | R25 | 100k | Device:R | Resistor_THT:R_Axial_DIN0207_L6.3mm_D2.5mm_P10.16mm_Horizontal | ~
 |  | R26 | 100k | Device:R | Resistor_THT:R_Axial_DIN0207_L6.3mm_D2.5mm_P10.16mm_Horizontal | ~
 |  | R27 | 47K | Device:R | Resistor_THT:R_Axial_DIN0207_L6.3mm_D2.5mm_P10.16mm_Horizontal | ~
 |  | R28 | 100 | Device:R | Resistor_THT:R_Axial_DIN0207_L6.3mm_D2.5mm_P10.16mm_Horizontal | ~
 |  | R29 | 150 | Device:R | Resistor_THT:R_Axial_DIN0207_L6.3mm_D2.5mm_P10.16mm_Horizontal | ~
 |  | R30 | 100 | Device:R | Resistor_THT:R_Axial_DIN0207_L6.3mm_D2.5mm_P10.16mm_Horizontal | ~
 |  | R31 | 150 | Device:R | Resistor_THT:R_Axial_DIN0207_L6.3mm_D2.5mm_P10.16mm_Horizontal | ~
 |  | R32 | 390k | Device:R | Resistor_THT:R_Axial_DIN0207_L6.3mm_D2.5mm_P10.16mm_Horizontal | ~
 |  | R33 | 390k | Device:R | Resistor_THT:R_Axial_DIN0207_L6.3mm_D2.5mm_P10.16mm_Horizontal | ~
 |  | R34 | 390k | Device:R | Resistor_THT:R_Axial_DIN0207_L6.3mm_D2.5mm_P10.16mm_Horizontal | ~
 |  | R35 | 390k | Device:R | Resistor_THT:R_Axial_DIN0207_L6.3mm_D2.5mm_P10.16mm_Horizontal | ~
 |  | R36 | 100 | Device:R | Resistor_THT:R_Axial_DIN0207_L6.3mm_D2.5mm_P10.16mm_Horizontal | ~
 |  | R37 | 150 | Device:R | Resistor_THT:R_Axial_DIN0207_L6.3mm_D2.5mm_P10.16mm_Horizontal | ~
 |  | R38 | 10k | Device:R | Resistor_THT:R_Axial_DIN0207_L6.3mm_D2.5mm_P10.16mm_Horizontal | ~
 |  | R39 | 10k | Device:R | Resistor_THT:R_Axial_DIN0207_L6.3mm_D2.5mm_P10.16mm_Horizontal | ~
 |  | R40 | 10k | Device:R | Resistor_THT:R_Axial_DIN0207_L6.3mm_D2.5mm_P10.16mm_Horizontal | ~
 |  | R41 | 10k | Device:R | Resistor_THT:R_Axial_DIN0207_L6.3mm_D2.5mm_P10.16mm_Horizontal | ~
 |  | R42 | 390k | Device:R | Resistor_THT:R_Axial_DIN0207_L6.3mm_D2.5mm_P10.16mm_Horizontal | ~
 |  | R43 | 390k | Device:R | Resistor_THT:R_Axial_DIN0207_L6.3mm_D2.5mm_P10.16mm_Horizontal | ~
 |  | R44 | 1M | Device:R | Resistor_THT:R_Axial_DIN0207_L6.3mm_D2.5mm_P10.16mm_Horizontal | ~
 |  | R45 | 1M | Device:R | Resistor_THT:R_Axial_DIN0207_L6.3mm_D2.5mm_P10.16mm_Horizontal | ~
 |  | R46 | 10k | Device:R | Resistor_THT:R_Axial_DIN0207_L6.3mm_D2.5mm_P10.16mm_Horizontal | ~
 |  | R47 | 10k | Device:R | Resistor_THT:R_Axial_DIN0207_L6.3mm_D2.5mm_P10.16mm_Horizontal | ~
 |  | R48 | 1M | Device:R | Resistor_THT:R_Axial_DIN0207_L6.3mm_D2.5mm_P10.16mm_Horizontal | ~
 |  | R49 | 1M | Device:R | Resistor_THT:R_Axial_DIN0207_L6.3mm_D2.5mm_P10.16mm_Horizontal | ~
 |  | R50 | 1M | Device:R | Resistor_THT:R_Axial_DIN0207_L6.3mm_D2.5mm_P10.16mm_Horizontal | ~
 |  | R51 | 1M | Device:R | Resistor_THT:R_Axial_DIN0207_L6.3mm_D2.5mm_P10.16mm_Horizontal | ~
 |  | R52 | 100 | Device:R | Resistor_THT:R_Axial_DIN0207_L6.3mm_D2.5mm_P10.16mm_Horizontal | ~
 |  | R53 | 150 | Device:R | Resistor_THT:R_Axial_DIN0207_L6.3mm_D2.5mm_P10.16mm_Horizontal | ~
 |  | R54 | 390k | Device:R | Resistor_THT:R_Axial_DIN0207_L6.3mm_D2.5mm_P10.16mm_Horizontal | ~
 |  | R55 | 390k | Device:R | Resistor_THT:R_Axial_DIN0207_L6.3mm_D2.5mm_P10.16mm_Horizontal | ~
 |  | R56 | 10k | Device:R | Resistor_THT:R_Axial_DIN0207_L6.3mm_D2.5mm_P10.16mm_Horizontal | ~
 |  | R57 | 10k | Device:R | Resistor_THT:R_Axial_DIN0207_L6.3mm_D2.5mm_P10.16mm_Horizontal | ~
 |  | R58 | 1M | Device:R | Resistor_THT:R_Axial_DIN0207_L6.3mm_D2.5mm_P10.16mm_Horizontal | ~
 |  | R59 | 1M | Device:R | Resistor_THT:R_Axial_DIN0207_L6.3mm_D2.5mm_P10.16mm_Horizontal | ~
 |  | R60 | 10k | Device:R | Resistor_THT:R_Axial_DIN0207_L6.3mm_D2.5mm_P10.16mm_Horizontal | ~
 |  | RV1 | 10k | Device:R_Potentiometer | Potentiometer_THT:Potentiometer_Bourns_3386C_Horizontal | ~
 |  | SW1 | SW_Push_DPDT | Switch:SW_Push_DPDT | llave_6:llave_6pin | ~
 |  | SW2 | SW_Push | Switch:SW_Push | Button_Switch_THT:SW_PUSH_6mm_H4.3mm | ~
 |  | SW3 | SW_Push | Switch:SW_Push | Button_Switch_THT:SW_PUSH_6mm_H4.3mm | ~
 |  | SW4 | SW_Push | Switch:SW_Push | Button_Switch_THT:SW_PUSH_6mm_H4.3mm | ~
 |  | T2 | PN2222A | Transistor_BJT:PN2222A | Package_TO_SOT_THT:TO-92L_Wide | https://www.onsemi.com/pub/Collateral/PN2222-D.PDF
 |  | T3 | PN2222A | Transistor_BJT:PN2222A | Package_TO_SOT_THT:TO-92L_Wide | https://www.onsemi.com/pub/Collateral/PN2222-D.PDF
 |  | T4 | PN2222A | Transistor_BJT:PN2222A | Package_TO_SOT_THT:TO-92L_Wide | https://www.onsemi.com/pub/Collateral/PN2222-D.PDF
 |  | T5 | PN2222A | Transistor_BJT:PN2222A | Package_TO_SOT_THT:TO-92L_Wide | https://www.onsemi.com/pub/Collateral/PN2222-D.PDF
 |  | T6 | PN2222A | Transistor_BJT:PN2222A | Package_TO_SOT_THT:TO-92L_Wide | https://www.onsemi.com/pub/Collateral/PN2222-D.PDF
 |  | U1 | CDP1802ACE | CPU:CDP1802ACE | Package_DIP:DIP-40_W15.24mm_LongPads | http://www.cosmacelf.com/publications/data-sheets/cdp1802.pdf
 |  | U2 | 74HCT573 | 74xx:74HCT574 | Package_DIP:DIP-20_W7.62mm_Socket_LongPads | http://www.ti.com/lit/gpn/sn74HCT574
 |  | U3 | EEPROM | Memory_RAM:CY62256-70PC | Package_DIP:DIP-28_W15.24mm_LongPads | https://ecee.colorado.edu/~mcclurel/Cypress_SRAM_CY62256.pdf
 |  | U4 | 24LC1025 | Memory_EEPROM:24LC1025 | Package_DIP:DIP-8_W7.62mm_LongPads | http://ww1.microchip.com/downloads/en/DeviceDoc/21941B.pdf
 |  | U5 | RAM1 | Memory_RAM:CY62256-70PC | Package_DIP:DIP-28_W15.24mm_LongPads | https://ecee.colorado.edu/~mcclurel/Cypress_SRAM_CY62256.pdf
 |  | U6 | RAM2 | Memory_RAM:CY62256-70PC | Package_DIP:DIP-28_W15.24mm_LongPads | https://ecee.colorado.edu/~mcclurel/Cypress_SRAM_CY62256.pdf
 |  | U7 | MB85RC64 | Memory_EEPROM:24LC1025 | Package_DIP:DIP-8_W8.89mm_SMDSocket_LongPads | http://ww1.microchip.com/downloads/en/DeviceDoc/21941B.pdf
 |  | U8 | MAX127 | MAX127:MAX127 | Package_DIP:DIP-24_W7.62mm_LongPads
 |  | U9 | L7812 | Regulator_Linear:L7812 | Package_TO_SOT_THT:TO-220-3_Vertical | http://www.st.com/content/ccc/resource/technical/document/datasheet/41/4f/b3/b0/12/d4/47/88/CD00000444.pdf/files/CD00000444.pdf/jcr:content/translations/en.CD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
 |  | U10 | L7805 | Regulator_Linear:L7805 | Package_TO_SOT_THT:TO-220-3_Vertical | http://www.st.com/content/ccc/resource/technical/document/datasheet/41/4f/b3/b0/12/d4/47/88/CD00000444.pdf/files/CD00000444.pdf/jcr:content/translations/en.CD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
 |  | U11 | OPA4277 | OP27:OPA4277 | Package_DIP:DIP-14_W7.62mm_LongPads | ~
 |  | U12 | L7912 | Regulator_Linear:L7912 | Package_TO_SOT_THT:TO-220-3_Vertical | http://www.st.com/content/ccc/resource/technical/document/datasheet/c9/16/86/41/c7/2b/45/f2/CD00000450.pdf/files/CD00000450.pdf/jcr:content/translations/en.CD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
 |  | U13 | 74HC00 | 74xx:74HC00 | Package_DIP:DIP-14_W7.62mm_LongPads | http://www.ti.com/lit/gpn/sn74hc00
 |  | U14 | 74HC00 | 74xx:74HC00 | Package_DIP:DIP-14_W7.62mm_LongPads | http://www.ti.com/lit/gpn/sn74hc00
 |  | U15 | 74HC00 | 74xx:74HC00 | Package_DIP:DIP-14_W7.62mm_LongPads | http://www.ti.com/lit/gpn/sn74hc00
 |  | U16 | 74HC00 | 74xx:74HC00 | Package_DIP:DIP-14_W7.62mm_LongPads | http://www.ti.com/lit/gpn/sn74hc00
 |  | U17 | 74HC132 | 74xx:74HC00 | Package_DIP:DIP-14_W7.62mm_LongPads | http://www.ti.com/lit/gpn/sn74hc00
 |  | U18 | 74HC02 | 74xx:74HC02 | Package_DIP:DIP-14_W7.62mm_LongPads | http://www.ti.com/lit/gpn/sn74hc02
 |  | U19 | 74HC138 | 74xx:74LS138 | Package_DIP:DIP-16_W7.62mm_LongPads | http://www.ti.com/lit/gpn/sn74LS138
 |  | U20 | 82C55A | Interface:82C55A | Package_DIP:DIP-40_W15.24mm | http://jap.hu/electronic/8255.pdf
 |  | U21 | LM285Z-ADJ | Reference_Voltage:LM285Z-ADJ | Package_TO_SOT_THT:TO-92S_Wide | http://www.ti.com/lit/ds/symlink/lm185-adj.pdf
 |  | U24 | 74HC74 | 74xx:74HC74 | Package_DIP:DIP-14_W7.62mm_LongPads | 74xx/74hc_hct74.pdf
 |  | U25 | 74HC161 | 74xx:74LS161 | Package_DIP:DIP-16_W7.62mm_LongPads | http://www.ti.com/lit/gpn/sn74LS161
 |  | U28 | 74HC00 | 74xx:74HC00 | Package_DIP:DIP-14_W7.62mm_LongPads | http://www.ti.com/lit/gpn/sn74hc00
 |  | U29 | 74HC73 | 74xx:74LS73 | Package_DIP:DIP-14_W7.62mm_LongPads | http://www.ti.com/lit/gpn/sn74LS73
 |  | U30 | 74HC02 | 74xx:74HC02 | Package_DIP:DIP-14_W7.62mm_LongPads | http://www.ti.com/lit/gpn/sn74hc02
 |  | U31 | 74HC595 | 74xx:74HC595 | Package_DIP:DIP-16_W7.62mm_LongPads | http://www.ti.com/lit/ds/symlink/sn74hc595.pdf
 |  | U32 | CD4014 | 4xxx_IEEE:4014 | Package_DIP:DIP-16_W7.62mm_LongPads
 |  | X2 | XO-25-4MHz | Oscillator:ASE-xxxMHz | Oscillator:Oscillator_SeikoEpson_SG-8002DC | http://www.abracon.com/Oscillators/ASV.pdf
 |  | XTAL1 | 4 MHz | Device:Crystal | Crystal:Crystal_HC18-U_Vertical | ~
Collated Components:
Item | Qty | Reference(s) | Value | LibPart | Footprint | Datasheet
1 | 18 | C1, C4, C6, C9, C10, C21, C22, C23, C24, C25, C26, C27, C28, C34, C35, C36, C37, C38 | 0.1uF | Device:C | Capacitor_THT:C_Disc_D3.0mm_W1.6mm_P2.50mm | ~
2 | 2 | C2, C3 | 30pF | Device:C | Capacitor_THT:C_Disc_D4.3mm_W1.9mm_P5.00mm | ~
3 | 6 | C5, C7, C8, C29, C30, C31 | 0,1uF | Device:C | Capacitor_THT:C_Disc_D3.0mm_W1.6mm_P2.50mm | ~
4 | 1 | C11 | 4700 uf | Device:C_Polarized | Capacitor_THT:C_Rect_L11.5mm_W4.3mm_P10.00mm_MKT | ~
5 | 2 | C12, C16 | 0.33 | Device:C | Capacitor_THT:C_Disc_D3.0mm_W1.6mm_P2.50mm | ~
6 | 1 | C13 | 10 uf | Device:C_Polarized | Capacitor_THT:CP_Radial_D5.0mm_P2.00mm | ~
7 | 2 | C14, C15 | 0.1uf | Device:C | Capacitor_THT:C_Disc_D3.0mm_W1.6mm_P2.50mm | ~
8 | 1 | C17 | 4700 uf | Device:C_Polarized | Capacitor_THT:C_Rect_L11.5mm_W2.8mm_P10.00mm_MKT | ~
9 | 1 | C18 | 0.1 uf | Device:C | Capacitor_THT:C_Disc_D3.0mm_W1.6mm_P2.50mm | ~
10 | 1 | C19 | 0.01 uf | Device:C_Polarized | Capacitor_THT:C_Disc_D3.0mm_W1.6mm_P2.50mm | ~
11 | 1 | C20 | 4.7 uf | Device:C_Polarized | Capacitor_THT:CP_Radial_D5.0mm_P2.00mm | ~
12 | 5 | C32, C33, C39, C40, C43 | C | pspice:C | Capacitor_THT:C_Disc_D3.0mm_W1.6mm_P2.50mm | ~
13 | 1 | D1 | B380R | Diode_Bridge:B380R | Diode_THT:Diode_Bridge_Round_D9.0mm | https://diotec.com/tl_files/diotec/files/pdf/datasheets/b40r.pdf
14 | 6 | D2, D3, D4, D5, D6, D7 | LD271 | LED:LD271 | LED_THT:LED_D5.0mm | http://www.alliedelec.com/m/d/40788c34903a719969df15f1fbea1056.pdf
15 | 2 | D8, D9 | 1N914 | Diode:1N914 | Diode_THT:D_DO-35_SOD27_P7.62mm_Horizontal | http://www.vishay.com/docs/85622/1n914.pdf
16 | 1 | F1 | Fuse | Device:Fuse | Library_fusible:fusible_10mm | ~
17 | 6 | J1, J2, J33, J48, J49, J50 | N1,2,3 | Connector:Conn_01x03_Male | Connector_PinHeader_2.54mm:PinHeader_1x03_P2.54mm_Vertical | ~
18 | 35 | J3, J4, J5, J6, J7, J8, J9, J10, J11, J12, J13, J14, J15, J16, J19, J20, J22, J23, J24, J25, J26, J27, J28, J29, J30, J31, J36, J40, J41, J42, J45, J46, J51, J52, J53 | 1 | Connector:Conn_01x01_Male | Connector_Pin:Pin_D1.0mm_L10.0mm | ~
19 | 2 | J17, J18 | 4 | Connector:Conn_01x01_Male | Connector_Pin:Pin_D1.0mm_L10.0mm | ~
20 | 1 | J21 | 3 | Connector:Conn_01x01_Male | Connector_Pin:Pin_D1.0mm_L10.0mm | ~
21 | 3 | J32, J35, J38 | Conn_01x06_Male | Connector:Conn_01x06_Male | Connector_PinHeader_2.54mm:PinHeader_1x06_P2.54mm_Vertical | ~
22 | 3 | J34, J37, J39 | Conn_01x05_Male | Connector:Conn_01x05_Male | Connector_PinHeader_2.54mm:PinHeader_1x05_P2.54mm_Vertical | ~
23 | 2 | J43, J44 | Screw_Terminal_01x03 | Connector:Screw_Terminal_01x03 | TerminalBlock:TerminalBlock_bornier-3_P5.08mm | ~
24 | 2 | J47, J54 | Conn_01x12_Male | Connector:Conn_01x12_Male | Connector_PinHeader_2.54mm:PinHeader_1x12_P2.54mm_Vertical | ~
25 | 1 | J55 | Conn_01x02_Male | Connector:Conn_01x02_Male | Connector_PinHeader_2.54mm:PinHeader_1x02_P2.54mm_Vertical | ~
26 | 5 | R1, R2, R3, R23, R27 | 47K | Device:R | Resistor_THT:R_Axial_DIN0207_L6.3mm_D2.5mm_P10.16mm_Horizontal | ~
27 | 1 | R4 | 10M | Device:R | Resistor_THT:R_Axial_DIN0207_L6.3mm_D2.5mm_P10.16mm_Horizontal | ~
28 | 1 | R5 | 47k | Device:R | Resistor_THT:R_Axial_DIN0207_L6.3mm_D2.5mm_P10.16mm_Horizontal | ~
29 | 1 | R6 | 330 | Device:R | Resistor_THT:R_Axial_DIN0207_L6.3mm_D2.5mm_P10.16mm_Horizontal | ~
30 | 2 | R7, R8 | 1 k | Device:R | Resistor_THT:R_Axial_DIN0207_L6.3mm_D2.5mm_P10.16mm_Horizontal | ~
31 | 3 | R9, R10, R11 | 220 | Device:R | Resistor_THT:R_Axial_DIN0207_L6.3mm_D2.5mm_P10.16mm_Horizontal | ~
32 | 7 | R12, R13, R14, R15, R16, R17, R18 | 10K | Device:R | Resistor_THT:R_Axial_DIN0207_L6.3mm_D2.5mm_P10.16mm_Horizontal | ~
33 | 2 | R19, R20 | 100K | Device:R | Resistor_THT:R_Axial_DIN0207_L6.3mm_D2.5mm_P10.16mm_Horizontal | ~
34 | 2 | R21, R22 | 47k | Device:R | Resistor_THT:R_Axial_DIN0207_L6.3mm_D2.5mm_P15.24mm_Horizontal | ~
35 | 3 | R24, R25, R26 | 100k | Device:R | Resistor_THT:R_Axial_DIN0207_L6.3mm_D2.5mm_P10.16mm_Horizontal | ~
36 | 4 | R28, R30, R36, R52 | 100 | Device:R | Resistor_THT:R_Axial_DIN0207_L6.3mm_D2.5mm_P10.16mm_Horizontal | ~
37 | 4 | R29, R31, R37, R53 | 150 | Device:R | Resistor_THT:R_Axial_DIN0207_L6.3mm_D2.5mm_P10.16mm_Horizontal | ~
38 | 8 | R32, R33, R34, R35, R42, R43, R54, R55 | 390k | Device:R | Resistor_THT:R_Axial_DIN0207_L6.3mm_D2.5mm_P10.16mm_Horizontal | ~
39 | 9 | R38, R39, R40, R41, R46, R47, R56, R57, R60 | 10k | Device:R | Resistor_THT:R_Axial_DIN0207_L6.3mm_D2.5mm_P10.16mm_Horizontal | ~
40 | 8 | R44, R45, R48, R49, R50, R51, R58, R59 | 1M | Device:R | Resistor_THT:R_Axial_DIN0207_L6.3mm_D2.5mm_P10.16mm_Horizontal | ~
41 | 1 | RV1 | 10k | Device:R_Potentiometer | Potentiometer_THT:Potentiometer_Bourns_3386C_Horizontal | ~
42 | 1 | SW1 | SW_Push_DPDT | Switch:SW_Push_DPDT | llave_6:llave_6pin | ~
43 | 3 | SW2, SW3, SW4 | SW_Push | Switch:SW_Push | Button_Switch_THT:SW_PUSH_6mm_H4.3mm | ~
44 | 5 | T2, T3, T4, T5, T6 | PN2222A | Transistor_BJT:PN2222A | Package_TO_SOT_THT:TO-92L_Wide | https://www.onsemi.com/pub/Collateral/PN2222-D.PDF
45 | 1 | U1 | CDP1802ACE | CPU:CDP1802ACE | Package_DIP:DIP-40_W15.24mm_LongPads | http://www.cosmacelf.com/publications/data-sheets/cdp1802.pdf
46 | 1 | U2 | 74HCT573 | 74xx:74HCT574 | Package_DIP:DIP-20_W7.62mm_Socket_LongPads | http://www.ti.com/lit/gpn/sn74HCT574
47 | 1 | U3 | EEPROM | Memory_RAM:CY62256-70PC | Package_DIP:DIP-28_W15.24mm_LongPads | https://ecee.colorado.edu/~mcclurel/Cypress_SRAM_CY62256.pdf
48 | 1 | U4 | 24LC1025 | Memory_EEPROM:24LC1025 | Package_DIP:DIP-8_W7.62mm_LongPads | http://ww1.microchip.com/downloads/en/DeviceDoc/21941B.pdf
49 | 1 | U5 | RAM1 | Memory_RAM:CY62256-70PC | Package_DIP:DIP-28_W15.24mm_LongPads | https://ecee.colorado.edu/~mcclurel/Cypress_SRAM_CY62256.pdf
50 | 1 | U6 | RAM2 | Memory_RAM:CY62256-70PC | Package_DIP:DIP-28_W15.24mm_LongPads | https://ecee.colorado.edu/~mcclurel/Cypress_SRAM_CY62256.pdf
51 | 1 | U7 | MB85RC64 | Memory_EEPROM:24LC1025 | Package_DIP:DIP-8_W8.89mm_SMDSocket_LongPads | http://ww1.microchip.com/downloads/en/DeviceDoc/21941B.pdf
52 | 1 | U8 | MAX127 | MAX127:MAX127 | Package_DIP:DIP-24_W7.62mm_LongPads
53 | 1 | U9 | L7812 | Regulator_Linear:L7812 | Package_TO_SOT_THT:TO-220-3_Vertical | http://www.st.com/content/ccc/resource/technical/document/datasheet/41/4f/b3/b0/12/d4/47/88/CD00000444.pdf/files/CD00000444.pdf/jcr:content/translations/en.CD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
54 | 1 | U10 | L7805 | Regulator_Linear:L7805 | Package_TO_SOT_THT:TO-220-3_Vertical | http://www.st.com/content/ccc/resource/technical/document/datasheet/41/4f/b3/b0/12/d4/47/88/CD00000444.pdf/files/CD00000444.pdf/jcr:content/translations/en.CD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
55 | 1 | U11 | OPA4277 | OP27:OPA4277 | Package_DIP:DIP-14_W7.62mm_LongPads | ~
56 | 1 | U12 | L7912 | Regulator_Linear:L7912 | Package_TO_SOT_THT:TO-220-3_Vertical | http://www.st.com/content/ccc/resource/technical/document/datasheet/c9/16/86/41/c7/2b/45/f2/CD00000450.pdf/files/CD00000450.pdf/jcr:content/translations/en.CD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
57 | 5 | U13, U14, U15, U16, U28 | 74HC00 | 74xx:74HC00 | Package_DIP:DIP-14_W7.62mm_LongPads | http://www.ti.com/lit/gpn/sn74hc00
58 | 1 | U17 | 74HC132 | 74xx:74HC00 | Package_DIP:DIP-14_W7.62mm_LongPads | http://www.ti.com/lit/gpn/sn74hc00
59 | 2 | U18, U30 | 74HC02 | 74xx:74HC02 | Package_DIP:DIP-14_W7.62mm_LongPads | http://www.ti.com/lit/gpn/sn74hc02
60 | 1 | U19 | 74HC138 | 74xx:74LS138 | Package_DIP:DIP-16_W7.62mm_LongPads | http://www.ti.com/lit/gpn/sn74LS138
61 | 1 | U20 | 82C55A | Interface:82C55A | Package_DIP:DIP-40_W15.24mm | http://jap.hu/electronic/8255.pdf
62 | 1 | U21 | LM285Z-ADJ | Reference_Voltage:LM285Z-ADJ | Package_TO_SOT_THT:TO-92S_Wide | http://www.ti.com/lit/ds/symlink/lm185-adj.pdf
63 | 1 | U24 | 74HC74 | 74xx:74HC74 | Package_DIP:DIP-14_W7.62mm_LongPads | 74xx/74hc_hct74.pdf
64 | 1 | U25 | 74HC161 | 74xx:74LS161 | Package_DIP:DIP-16_W7.62mm_LongPads | http://www.ti.com/lit/gpn/sn74LS161
65 | 1 | U29 | 74HC73 | 74xx:74LS73 | Package_DIP:DIP-14_W7.62mm_LongPads | http://www.ti.com/lit/gpn/sn74LS73
66 | 1 | U31 | 74HC595 | 74xx:74HC595 | Package_DIP:DIP-16_W7.62mm_LongPads | http://www.ti.com/lit/ds/symlink/sn74hc595.pdf
67 | 1 | U32 | CD4014 | 4xxx_IEEE:4014 | Package_DIP:DIP-16_W7.62mm_LongPads
68 | 1 | X2 | XO-25-4MHz | Oscillator:ASE-xxxMHz | Oscillator:Oscillator_SeikoEpson_SG-8002DC | http://www.abracon.com/Oscillators/ASV.pdf
69 | 1 | XTAL1 | 4 MHz | Device:Crystal | Crystal:Crystal_HC18-U_Vertical | ~

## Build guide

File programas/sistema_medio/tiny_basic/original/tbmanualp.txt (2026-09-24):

                 11     888888     000000     222222
                111    88    88   00    00   22    22
                 11    88    88   00    00         22
                 11     888888    00    00     22222
                 11    88    88   00    00    22 
                 11    88    88   00    00   22 
                1111    888888     000000    22222222

                TTTTTTTT   IIII   NN    NN   YY    YY
                   TT       II    NNN   NN   YY    YY
                   TT       II    NNNN  NN    YY  YY
                   TT       II    NN NN NN     YYYY
                   TT       II    NN  NNNN      YY
                   TT       II    NN   NNN      YY
                   TT      IIII   NN    NN      YY

          BBBBBBB       AA       SSSSSS    IIII    CCCCCC
          BB    BB     AAAA     SS    SS    II    CC    CC
          BB    BB    AA  AA    SS          II    CC
          BBBBBBB    AA    AA    SSSSSS     II    CC
          BB    BB   AAAAAAAA         SS    II    CC
          BB    BB   AA    AA   SS    SS    II    CC    CC
          BBBBBBB    AA    AA    SSSSSS    IIII    CCCCCC

                   TMSI Tiny BASIC for the 1802

                            User Manual

                       Copyright (C) 1981 by

                   Technical Micro Systems, Inc.
                          366 Cloverdale
                        Ann Arbor, MI 48105

                          (313) 994-0784

3/31/2002: This manual is being provided with the permission of its
original author, Lee A. Hart, for historical and educational use. It
may be used without charge for any non-commercial purpose. Technical
Micro Systems is out of business, so the above address and phone
number are not valid. To contact the author, write to Lee A. Hart,
814 8th Ave. N, Sartell MN 56366, or email <leeahart@earthlink.net>.

                         TABLE OF CONTENTS

     1. INTRODUCTION . . . . . . . . . . . . . . . . . . . .  1

     2. OVERVIEW . . . . . . . . . . . . . . . . . . . . . .  2

     3. HARDWARE REQUIREMENTS  . . . . . . . . . . . . . . .  3

     4. INSTALLATION . . . . . . . . . . . . . . . . . . . .  4

     5. CHECKOUT . . . . . . . . . . . . . . . . . . . . . .  5
           In Case of Difficulty . . . . . . . . . . . . . .  5

     6. TINY BASIC . . . . . . . . . . . . . . . . . . . . .  7
           The Command Mode  . . . . . . . . . . . . . . . .  8
           The Execute Mode  . . . . . . . . . . . . . . . .  9
           Error Messages  . . . . . . . . . . . . . . . . .  9
           Numbers . . . . . . . . . . . . . . . . . . . . .  9
           Variables . . . . . . . . . . . . . . . . . . . . 10
           Expressions . . . . . . . . . . . . . . . . . . . 10
           Statements  . . . . . . . . . . . . . . . . . . . 11
           Functions . . . . . . . . . . . . . . . . . . . . 18

     7. THE MACHINE-LEVEL MONITOR  . . . . . . . . . . . . . 21
           Operation . . . . . . . . . . . . . . . . . . . . 21
           Examine Memory (?M) . . . . . . . . . . . . . . . 22
           Change Memory (!M)  . . . . . . . . . . . . . . . 23
           Move Memory (?M --- !M) . . . . . . . . . . . . . 24
           Examine Registers (?R)  . . . . . . . . . . . . . 24
           Run Registers ($R)  . . . . . . . . . . . . . . . 26
           Run Program ($P)  . . . . . . . . . . . . . . . . 27

     8. INTERNAL OPERATION . . . . . . . . . . . . . . . . . 28
           Memory Allocation . . . . . . . . . . . . . . . . 28
           Internal BASIC Program Format . . . . . . . . . . 29
           Saving a BASIC Program in ROM . . . . . . . . . . 30
           Register Usage  . . . . . . . . . . . . . . . . . 33
           User-Accessible Subroutines . . . . . . . . . . . 34
           Writing USR Functions . . . . . . . . . . . . . . 39
           USR Function Example  . . . . . . . . . . . . . . 40

     APPENDICES
           Serial Terminal Interface . . . . . . . . . . .  A-1
           ASCII Control Codes . . . . . . . . . . . . . .  B-1
           Error Message Summary . . . . . . . . . . . . .  C-1
           Formal Definition of Tiny BASIC . . . . . . . .  D-1
           ASCII/Decimal/Hex Conversions . . . . . . . . .  E-1
           Tiny BASIC Memory Map . . . . . . . . . . . . .  F-1
           Tiny BASIC Assembly Listing . . . . . . . . . .  G-1

                             CHAPTER 1

                           INTRODUCTION

Thank you for your purchase of TMSI(tm) Tiny BASIC. We hope
you find it a quick and easy way to get familiar with the
BASYS/1 1802 Microcomputer and apply it to simple applications.

Tiny BASIC originated with the People's Computer Company,
and was written for the COSMAC microprocessor by Tom
Pittman of Itty Bitty Computers Company. RCA Corporation
funded its development, and it is with their permission
that it has been made available. TMSI Tiny BASIC has all
the features of regular Tiny BASIC, plus I/O extensions
and a powerful machine-level monitor. Programs written in
TMSI Tiny BASIC can also be saved in EPROM so that they
execute immediately upon power-up.

This program has been extensively tested, and we believe
it to be free of errors. It does carry our standard 90-day
warranty (see warranty statement) so if any errors are
found during the first 90 days, we will correct them free
of charge.

Good documentation is the key to solid, reliable software.
Accordingly, it is our policy to supply complete source
code listings for all TMSI software. Although it increases
our costs, we feel that it makes the program far more
useful to you. Please help us continue this policy by
respecting our copyright notices.

If there are any questions or problems with this product,
call or write:

        TMSI c/o Lee A. Hart
        814 8th Avenue North
        Sartell, MN 56377
        <leeahart@earthlink.net>

(Contact information updated, and valid as of 3/31/2002.)

                                -1-

                             CHAPTER 2

                             OVERVIEW

TMSI Tiny BASIC is a simple, high-level language for the BASYS/1 and
other microcomputers based on the RCA "COSMAC" microprocessor. It
executes a subset of the popular BASIC language and is unusually
easy to learn and use. A line editor is provided to enter programs,
and an extensive set of error checks and messages is available for
program debugging. For control-oriented applications, TMSI Tiny
BASIC has a complete set of I/O commands for controlling the
computer's inputs and outputs without machine language programming.
A Tiny BASIC program can also be saved in EPROM for dedicated
applications. It will then be executed immediately upon power-up or
reset, without the need for any operator input (see chapter 8:
Internal Operation).

All numbers in Tiny BASIC are integers within the range of -32768
to +32767. There are 26 named variables (A-Z), and four math
operators (add, subtract, multiply, and divide). Statements include
LET, PRINT, INPUT, GOTO, GOSUB, RETURN, IF-THEN, LIST, RUN, and NEW.
There are two functions; RND for generating a random number, and USR
for linking to machine-language subroutines.

For advanced users, a machine-level monitor program is included.
Using the monitor, critical functions can be programmed and debugged
in machine language, and then called by Tiny BASIC as needed. The
monitor can examine, change, and move memory; examine and change
CPU register contents; and execute programs with breakpoints. The
read and type formats are fully compatible with those used by RCA.

TMSI Tiny BASIC is specifically designed to run in very small
systems -- consequently, it trades execution speed for low memory
requirements. All software is contained in a single 4K byte EPROM
(with 1K bytes available for user programs), and the minimum RAM
requirement is 256 bytes. A serial ASCII data terminal is needed for
user inputs and outputs, using the COSMAC's Q and EF4 I/O pins.
Execution speed is quite slow (approximately 5 lines per second at
2 MHz), but adequate for many simple applications.

Conventions

Tiny BASIC normally uses only upper-case letters. Commands typed in
lower-case letters will cause syntax errors. However, lower-case
letters can be used in REMarks, comments, and PRINT statements.

In this manual, numbers are in decimal unless otherwise noted. <CR>
means the ASCII "Carriage Return" control code (13 decimal, 0D hex),
which is the RETURN or ENTER key on you keyboard.

                                -2-

                             CHAPTER 3

                       HARDWARE REQUIREMENTS

TMSI Tiny BASIC will run in the BASYS/1 microcomputer, or any other
COSMAC based system that meets the following minimum requirements:

CPU     RCA, Hughes, or Solid State Scientific "COSMAC"
        microprocessor; 1802, 1804, 1805, or 1806. Any clock
        frequency is acceptable; however, it sets the maximum baud
        rate for serial communications (see I/O below).

MEMORY  RAM: 256 bytes minimum, fully decoded and starting at
        address 1000 (hex). TMSI Tiny BASIC will test for RAM
        starting at this address, and adapt itself to the amount
        found. RAM in excess of 256 bytes is used to hold Tiny
        BASIC programs, so the more RAM, the larger the program.

        BASIC ROM: One socket for a 27C32 4K byte EPROM, fully
        decoded at address 0000. EPROM access time is 450nS,
        which is acceptable for COSMAC systems running at up to
        5 MHz. Data in the EPROM is active high (not inverted).
        Execution should begin at 0000 with P = X = 0.

        User EPROM (containing user BASIC programs): 1K bytes
        of space are available in the TMSI Tiny BASIC EPROM for
        user BASIC programs. Additional EPROMs may be added for
        larger programs. They must be addressed above the first
        page of RAM at 1000 (hex), and preferably above all RAM.
        If a user EPROM is found by TMSI Tiny BASIC after reset,
        it will be executed immediately as a BASIC program. If a
        user EPROM is not used or not addressed immediately
        above RAM, then pull-up resistors to +5v should be used
        on the data bus to insure that TMSI Tiny BASIC does not
        mistake a floating data bus for a user EPROM program.

I/O     User terminal input and output is serial ASCII, using the
	COSMAC's EF4 and Q pins respectively with a "software UART"
	program. The baud rate can be from 60 to 2400 baud with a 2
	MHz clock; scale proportionately for other CPU clock
	frequencies. TMSI Tiny BASIC automatically determines the
	baud rate from the first character received after Reset,
	which should be a <CR> (your RETURN or ENTER key) for full
	duplex, or <LF> (your LINE FEED or control-J key) for half
	duplex. See Appendix A for a sample RS-232 serial interface
	circuit.

                                -3-

                             CHAPTER 4

                           INSTALLATION

These instructions are for the TMSI BASYS/1 microcomputer. However,
they should serve as a guide for other systems as well. To avoid
damaging the parts from static electricity, follow the instructions
exactly as given. Then place a check mark in the space provided ( ).

( ) Touch the metal case of crystal Y1 on the BASYS/1 board first to
    discharge any static potential safely.

( ) U11: Remove the chip at U11 from its socket, and hold it in one
    hand. With the other hand, pick up the piece of protective foam
    holding the Tiny BASIC IC. Insert U11 into the back of this
    piece. Now remove the Tiny BASIC IC, and insert it into socket
    U11. Be sure to position pin 1 (with the dot) as shown below.

( ) X5: Install jumpers at    ____________________________________
    pins 1-2, 3-14, 6-12,    /       |                    |       \
    and 8-10 (configures    |        |         P2         |        |
    U11 for a 27C32 EPROM). |        |::::::::::::::::::::|        |
    .-----------------.     |        `--------------------'        |
    | O O O O O O O O |     | .-----. .----.   .--------. .--..--. |
    |     |   |   |   |     | |.U3  | |.U9 |   |.U17    | U25|U26| |
  X5 > _  |    \   \  |     | `-----' `----'   `--------' `--'`--' |
    | | | |     |   | |     | .-----. .-----.  .--------.  .-----. |
    | O O O O O O O O |     | |.U2  | |.U8  |  |.U16    |  |.U24 | |
    `-----------------'     | `-----' `-----'  `--------'  `-----' |
( ) XD2: Install five diode | .----------------. .------.  .-----. |
    jumpers as shown (A=    | |                | |.U15  |  |.U23 | |
    anode, C=cathode). Puts | |   BREADBOARD   | `------'  `-----' |
    RAM at 1000-17FF (hex). | |      AREA      | .------.  .-----. |
    .-------------------.   | |                | |.U14  |  |.U22 | |
    | O O O O O O O O O |   | |                | `------'  `-----' |
    |   |   |  \   \ \  |   | `----------------'.------.   .---.   |
 XD2 \  C   A   C   A C |   | .------. .----.   |.U13  |   |.X6|   |
     /  A   C   A   C A |   | |.XD2  | |.X3 |   `------'   `---'   |
    |    \  |   |   | | |   | `------' `----'   .------.   .-----. |
    | O O O O O O O O O |   | .------. .-----.  |.U12  |   |.X5  | |
    `-------------------'   | |.XD1  | |.U7  |  `------'   `-----' |
( ) XD1: Install four diode |  ------   -----  .---------.         |
    jumpers as shown. Puts  | .-----. .------. |         | .-----. |
    BASIC at 0-0FFF (hex).  | |.U1  | |.U6   | |         | |.U21 | |
    .-------------------.   | `-----' `------' |.U11     | `-----' |
    | O O O O O O O O O |   |                  `---------'         |
    |        \ \   \ \  |   |         .------------------. .----.  |
 XD1 \        A C   A C |   |  |  |   |                  | |.U20|  |
     /        C A   C A |   | .----.  |                  | `----'  |
    |         | |   | | |   | |    |  |.U5               |D20      |
    | O O O O O O O O O |   | | Y1 |  `------------------' .-----. |
    `-------------------'   | |    |.-----. .-----. .-----.|.U19 | |
( ) D20: If diode D20 is    | `----'|.U4  | |.U10 | |.U18 |`-----' |
    installed, remove it.   |__     `-----' `-----' `-----'      __|
                               |               P1               |
This completes installation    | |||||||||||||||||||||||||||||| |
of the TMSI Tiny BASIC EPROM.  |_||||||||||||||||||||||||||||||_|

                                -4-

                             CHAPTER 5

                             CHECKOUT

Re-install the BASYS/1 board in its cabinet, and connect it to a
serial RS-232 or current-loop terminal. Appendix A gives a sample
circuit for non-BASYS systems. Set the terminal for 300 baud, 8 data
bits, no parity, 2 stop bits, and full duplex. Turn on the computer
and reset it. There should be no response displayed on the terminal.
Now push your <CR> or <LF> key. The computer will echo the Carriage
Return, then print a Line Feed, and the message "NEW?".

Respond by typing "Y" for yes, and then the <CR> key. This tells
Tiny BASIC to start with a new program. Tiny BASIC will clear any
old programs in memory, and print a ":" (colon) to indicate that it
is ready for a BASIC statement or command.

Type "PRINT 2+2" and then the <CR> key. Tiny BASIC will respond by
printing "4". It's alive! This completes the initial checkout
procedure.

In Case of Difficulty

Check the following list of problems, and their possible causes. If
the symptoms of your problem are not on the list, your you are
unable to fix the problem, please write or call Customer Service,
and we'll do our best to help.

1. No response -- terminal prints nothing at all.

   a. No input at EF4 from keyboard.
      Check the voltage at pin 21 of the COSMAC (U5). It should be
      low (<0.5 volts) when no key is pressed, and high (>4 volts)
      when the <BREAK> key is pressed or the terminal is turned off
      or disconnected.

   b. Q output not reaching terminal.
      Check the voltage between pins 5 and 4 of opto-coupler U25.
      When no key is pressed, pin 5 should be +0.5v to +1.5v above
      pin 4 (i.e. the opto-coupler is "on". When keys are typed
      and the computer echoes them (try typing a "repeat+<NUL>" or
      "repeat+control+shift+L"), the opto-coupler will turn "off"
      during each character, and the voltage between pins 5 and 4
      will be close to (V+)-(V-) (P2 pin 36 and P2 pin 35
      respectively).

   c. Tiny BASIC EPROM not addressed at 0000 (hex).
      Check the address decoding. On BASYS/1, there should be four
      diodes in XD1, all installed at an angle (not straight across
      the socket). See Chapter 4: INSTALLATION for details.

   d. No RAM at 1000 (hex).
      Check the address decoding. On BASYS/1, diodes D14, D15, D16,
      and D18 should be installed at an angle in XD2, and D17 should
      be straight across XD2. See Chapter 4: INSTALLATION for
      details.
                                -5-

   e. Baud rate too high.
      Be sure the baud rate is not above 1200 baud if a 2 MHz CPU
      clock is used, or a proportionate rate for lower clock
      frequencies.

2. Tiny BASIC types "!(number) AT#(number)".

   a. A second user EPROM or write-protected RAM was found that does
      not contain a valid BASIC program. Disable or remove the
      EPROM, or write-enable the RAM. If this is not easily done,
      type "A=USR(2552)" and the <CR> key to jump to the monitor
      program. Then type a second <CR> to set the baud rate. The
      message "NEW?" will appear, to which you should type another
      <CR>. Tiny BASIC will now ignore the EPROM and start again.

   b. Write-protected RAM or partially-decoded images of the Tiny
      BASIC EPROM appear in the memory map. Memory should be fully
      decoded for TMSI Tiny BASIC. If not possible, BASIC will
      improperly size RAM and won't be able to find and run user
      programs in EPROMs.

3. Terminal prints several characters of nonsense.

   a. Terminal baud rate is too high, so an error message is being
      printed but is unreadable. Before you type the first <CR>,
      Tiny BASIC does not know your baud rate, and so assumes 300
      baud and a 2 MHz clock. Also, the opto-couplers used for the
      serial interface are not particularly fast; they will limit
      the baud rate to about 2400 baud maximum no matter how fast
      the COSMAC's clock speed is. Select a lower baud rate, and
      correct the problem as in 2b above.

   b. Serial output is inverted, or not working properly. See 1a and
      1b above.

   c. Terminal has parity enabled, or is not ASCII (Baudot, EBCDIC,
      etc.). Disable parity and try again.

                                -6-

                             CHAPTER 6

                             OPERATION

When power is first applied or whenever the computer is Reset, TMSI
Tiny BASIC searches for a user's program in the EPROM. If one is
found, it is executed immediately, and all further actions are
controlled by that program.

If no user program is found in the EPROM, TMSI Tiny BASIC waits for
you to type a key so it can determine the baud rate and echo status.
Press the <CR> key for full duplex (so all serial inputs will be
echoed as received), or the <LF> for half duplex operation (so keys
you type are not echoed, because your terminal prints them directly
by itself).

TMSI Tiny BASIC will then print "NEW?" to ask if you want to begin
with a new BASIC program (a "cold start"), or continue with one
already in memory (a "warm start"). Type "Y" for yes, or "N" for no,
and follow either response with the <CR> key.

If you answer "yes", Tiny BASIC will test RAM and adapt itself to use
the full amount available. The RAM test checks every location above
1100 (hex) and can serve as a simple confidence test to find bad
bits or addressing problems. Tiny BASIC now copies the initial values of
its control parameters from the EPROM to RAM, where they can easily
be examined or changed. See Appendix B for the location and function
of these parameters. The program space is now defined as "empty",
and BASIC prints its command-mode prompt ":" and is ready for use.

If you answer "no", Tiny BASIC assumes that RAM has already been
sized, the control parameters already moved, and that RAM contains a
valid BASIC program. Therefore, there must have been at least one
previous "NEW" since power-up to do this initialization. Everything
is left as-is, and BASIC signs on with its command-mode ":" prompt
and is ready for use.

All inputs to Tiny BASIC are held in a 72-character buffer until the
final <CR> key is typed. Excess characters will be ignored, and
signaled by ringing the terminal's bell. When the final <CR> is
typed, Tiny BASIC responds with a <LF> and then processes the line.
When finished, it again types its ":" prompt and is ready for the
next line.

If you make a mistake when typing a line, there are two ways to
correct it before the final <CR> key. First, you can
"rubout" the error one key at a time. As supplied, this is the
<BACKSPACE> key on most keyboards; ASCII code 08 (hex). Second, you
can "cancel" the entire line. As supplied, this is this is the
Control-X key on most keyboards; ASCII code 18 (hex). Both of these
codes can be changed to suit your preferences (see Appendix B: ASCII
Control Codes).

                                -7-

Tiny BASIC provides one more control function, useful for loading
programs from a cassette recorder or paper tape reader that
transmits its data continuously without stopping. If a line feed is
received, all outputs from BASIC itself are disabled (prompts and
program outputs; echoed inputs are not affected). BASIC can then
receive data continuously without pausing to type a prompt or other
data. Normal printing is restored by an X-OFF character (ASCII DC3,
code 13 hex, control-S), or by any action that returns BASIC to the
Command mode.

The Command Mode

When BASIC is not running a BASIC program, it is in the "immediate"
or command mode, and types a colon ":" on the left margin. You may
type in any BASIC statement, with or without a line number. If a
line number is included, it will be inserted into the present
program at the appropriate place without further action. Any
previous line with the same number is deleted. If the line contains
the line number only (a blank line), that line will be deleted from
the program. 0 is not a valid line number. Tiny BASIC ignores
blanks, so they may be used where desired to improve readability.
However, after the first non-blank non-numeric character in the
line, all blanks will be saved in memory. The following are all
valid lines with line numbers.

        10 PRINT "HELLO"
        2 0 PRINT "THIS IS LINE #20"
        10
        3 0 P R I N T " S P A C E S "
        1PRINT"smallest line number"
        32767 PRINT "largest line number"
        12345 Tiny BASIC ignores the contents of a line at insertion

If the input line does not start with a line number, then it will be
considered an immediate command and will be executed. The following
is a list of the valid commands. They will be explained in more
detail in the following pages:

        IF ... THEN     GOSUB           REM
        INPUT           GOTO            NEW
        PRINT           RETURN          LIST
        LET             END             RUN

Note that all twelve of these can be used in the command mode
(without a line number) or as statements within a BASIC program
(with a line number). They all work the same as commands and
program statements except INPUT and RUN, which behave slightly
differently. Although it does not make much sense to use RUN or NEW
in a program, they are still legal statements. Similarly, using
GOSUB in the command mode will work, but will cause an error stop
when the corresponding RETURN is executed because there is no
program to return to.

                                -8-

The Execute Mode

Once a BASIC program has been loaded into memory, it can be executed
by simply typing "RUN". Tiny BASIC then enters the Execute mode.
Execution begins at the first (lowest) line number, and continues
from there. BASIC will return to the Command mode when a) the
program executes an END statement, b) an error condition is detected
(see below), or c) the user stops the program by hitting the
terminals BREAK key (or by repeatedly hitting any other key). In the
latter two cases, BASIC will print an error message indicating the
cause of the halt, and the line number on which it occurred.

Error Messages

Tiny BASIC checks each line for errors when it is executed. An
immediate command (typed without a line number) is thus checked for
errors immediately after the final <CR> is typed. If there is an
error on the line (mis-spelled keyword, divide by 0, etc.) BASIC
prints an error message of the form:

        !number

where "number" is a number indicating the type of error. For
example, "!243" indicates an attempt to divide by zero. A list of
the error numbers and their meanings is given in Appendix C.

Lines typed with a line number are entered into the program space
exactly as typed. They will be checked for errors only when executed
as part of a BASIC program. Thus lines of miscellaneous data,
comments, instructions, or plain text can be entered, edited, and
listed by Tiny BASIC. Errors found during execution of a BASIC
program print an error message of the form:

        !number AT#line

and Tiny BASIC halts and returns to the command mode. "Number" is
the error number as above, and "line" is the line number in the
BASIC program in which the error occurred.

Numbers

A number in Tiny BASIC is any sequence of decimal digits (0-9)
optionally preceded by a sign (+ or -). If no sign is used, the
number is assumed to be positive. Tiny BASIC stores numbers as
16-bit signed integers. This limits them to the range of +32767 to
-32768 inclusive. You can enter numbers outside this range, but they
will be truncated modulo 65536 (=2^16). In effect, Tiny BASIC will
repetitively add or subtract 65536 to your number until it is
between -32768 and +32767 (inclusive). Blanks have no significance
within numbers and are ignored.

                                -9-

Similarly, leading zeros will be ignored. The following are examples
of valid numbers. The comments in parentheses show the effect of
truncation for numbers that are too large or too small.

        1
        123             (assumed positive)
        +123
        -123
        1 2 3           (same as 123)
        000123
        +32767          (the largest positive number)
        -32768          (the largest negative number)
        32768           (32768 - 65536 = -32768)
        65600           (65600 - 65536 = 64)
        -100000         ( -100000 + 65536 + 65536 = 31072)

Variables

There are 26 variables in Tiny BASIC, each represented by a single
capital letter A-Z. Each variable is assigned a 2-byte location in
memory. The value of the variable is the contents of that location,
which can be any valid number (i.e. an integer from -32768 to
+32767).

Expressions

An Expression is a combination of one or more numbers, variables,
and math operators that can be evaluated to a single value. For
example, the expression 2+2 evaluates to 4. The math operators are:

        + add
        - subtract
        * multiply
        / divide

Tiny BASIC follows the normal rules of precedence for mathematics.
Expressions are evaluated from left to right, performing all
multiplications and divisions, and then all additions and
subtractions. For example, in the expression:

        2+3*4+5         (=29)

the multiplication is done first (3*4=12), then the left addition
(2+12=14), and finally the right addition (14+5=19).

Parentheses may be used to alter the order of evaluation. Anything
in parentheses will be evaluated first. Parentheses may be nested as
needed. For example, if the above expression was instead written as:

        (2+3)*(4+5)     (=45)

then the left addition would be performed first (2+3=5), then the
right addition (4+5=9), and the multiplication last (5*9=45).

                               -10-

Spaces are ignored in expressions. Tiny BASIC does not check for
arithmetic overflows. However, an attempt to divide by zero will
result in an error stop.

The following are examples of valid expressions:

        A
        123
        1+2-3
        B-14*C
        (A+B)/(C+D)
        -128 / ( -32768 + (E*E) )
        (((((Q)))))

All expressions are evaluated as modulo 65536 integers. This means
that the intermediate results from every addition, subtraction,
multiplication, and division are all truncated to 16 bits. Thus an
expression like (N/P*P) may not equal N because the remainder
following the division is lost. In fact, this characteristic can be
used to determine if a number N is an exact multiple of another
number P. If so, then N/P*P=N.

Any number in the range 32768 to 65535 (2^15 to 2^16-1) becomes a
binary number with a sign bit of "1", and so is treated as NEGATIVE
by Tiny BASIC, i.e. as if 65536 were subtracted from it. Thus the
following expressions all produce the same result:

        -4096
        -4096+65536
        -8193/2
        15*4096
        32768/8
        30720+30720

Statements

A tiny BASIC statement begins with a keyword, such as REM or LET,
indicating the type of statement. The function of the rest of the
statement depends on the keyword, as defined below. Some keywords
also have abbreviated forms to save typing and save space in memory.

The REM statement

        REM This is a remark

The REM statement permits comments to be placed in a BASIC program.
Everything from the REM to the end of the line will be ignored. REM
statements have no effect on program execution except for the time
it takes to skip over it.

                               -11-

The LET Statement

        LET variable=expression
        variable=expression

The keyword LET assigns the value of the expression to the variable.
Optionally, the LET may be eliminated entirely to save memory.
However, execution is faster if it is included. The following are
example of the LET statement:

        LET X=1
        X=1
        LET A=(B+C)/2

The PRINT Statement

        PRINT printlist
        PR printlist

This statement prints the values of the items in the printlist on
the user's terminal or output device. PRINT can be abbreviated by
PR to save memory. The items in the printlist can be numbers,
variables, expressions, or quoted messages, as long as the printed
line does not exceed 125 characters. Items in the printlist are
separated by ";" (semicolons) or "," (commas). A semicolon between
items causes them to be printed with no intervening spaces. If an
item is preceded by a comma, it will begin printing at the next
"tab stop". Tab stops are set automatically every 8 spaces. The
following are examples of valid PRINT statements and the printed
output they produce (assuming A=1 and B=2).

        STATEMENT                       PRINTED OUTPUT
        ---------                       --------------
        PRINT                           (prints a blank line)
        PRINT 123                       123
        PR 1,2,3                        1       2       3
        PR "HELLO"                      HELLO
        PR"The answer is ";2+2          The answer is 4
        PR  "A=";A,"B=";B               A=1     B=2

A PRINT statement normally ends with a <CR><LF> (Carriage Return and
Line Feed) ready for the next line. But if a PRINT statement ends
with a comma "," or semicolon ";", the ending <CR><LF> sequence is
not sent. Subsequent PRINT or INPUT statements (see next section)
can then continue printing on the same line.

A PRINT statement can also be ended with a colon ":". The colon
sends an X-OFF control character (ASCII DC3, code 13 hex, control-S)
just before the final <CR><LF> sequence. This can be used to control
a mass storage device, or to prepare data for later input to other
Tiny BASIC programs.

                               -12-

The INPUT Statement

        INPUT inputlist
        IN inputlist

The INPUT statement lets the program get information from the
user, and assign it to the variables in the inputlist. It may be
abbreviated by IN. Normally, the Tiny BASIC line buffer is empty
(i.e. the last keyboard input was fully processed). In this case,
INPUT prints a question mark "?", a space, and an X-ON control
character (ASCII DC1, code 11 hex, control-Q) to indicate that it
is expecting data. The user responds by typing a line of one or more
expressions, separated by commas "," and ending with a Carriage
Return <CR>. BASIC evaluates each expression, and assigns its value
to successive variables in the inputlist. Consider the following
examples.

        STATEMENT       USER TYPES      ACTION
        ---------       ----------      ------
        INPUT A       ? 2+2             sets A=4
        IN A,B,C      ? 4,A,A+B         sets A=4, B=4, and C=8

If the user enters fewer expressions than there are variables in the
inputlist, a new "?" will be printed to ask for more data. If the
number of expressions is greater than the number of inputlist
variables, the leftover expressions will be saved in the line buffer
for subsequent INPUT statements.

If there is data in the line buffer when INPUT begins, it uses that
information first (before typing a "?"). Each expression is in turn
evaluated, removed from the buffer, and assigned to the next
inputlist variable as described above. If there are enough
expressions to satisfy the inputlist, no "?" prompt will be issued;
otherwise a "?" will be printed to request the additional
expressions needed. Warning: Misalignment between expressions and
inputlist variables can cause program bugs that are very difficult
to locate -- match them carefully!

        STATEMENT       USER TYPES      ACTION
        ---------       ----------      ------
        INPUT A,B     ? 2               sets A=2
                      ? 3               2nd "?" prompt; sets B=3
        IN A          ? 2,3             sets A=2, save 3 for next IN
        IN B                            no "?" prompt; sets B=3

Blanks are ignored as usual within input responses. The Backspace
and Cancel functions also work normally for correcting errors as
long as they are used before the final <CR>. There is no defined
escape from an input request, but an invalid expression (such as
divide-by-zero, a pair of commas, etc.) will result in an error
stop.

INPUT operates somewhat differently in the command mode if the
inputlist has more than one variable. This is because the line

                               -13-

buffer contains BOTH the INPUT statement itself and the expression
being input. For example, if you type

        INPUT A,B

in the command mode (no line number), Tiny BASIC first removes the
first part of the statement (INPUT A) and executes it. But when it
looks at the line buffer again, it finds the rest of the statement
(,B). So it evaluates it as input data for the INPUT A statement,
and sets A=B.

The IF Statement

        IF expression1 relation expression2 THEN statement
        IF expression1 relation expression2 statement

The IF statement computes the value of the two expressions, and
compares them. If the relation specified is TRUE, then the statement
is executed. Otherwise, the statement is skipped. The word THEN is
optional, and may be omitted. The relation operators are:

        =        equal
        <        less than
        >        greater than
        <=       less than or equal (i.e. not greater than)
        >=       greater than or equal (i.e. not less than)
        <> or >< not equal (i.e. greater than or less than)

Note that the statement following IF can be any valid Tiny BASIC
statement, including another IF statement. The following are valid
IF statements.

        IF A=25 THEN LET B=0
        IF A>B PRINT A,B
        IF A>0 THEN IF A<10 PRINT A      (prints A only if 1-9)
        IF N/P*P=N PRINT "NO REMAINDER"

                               -14-

The GOTO Statement

        GOTO expression

Tiny BASIC normally executes a program in ascending statement number
order. The GOTO statement permits changing this order. The next
statement executed after a GOTO is the one specified by the value of
the expression. Since the expression can include variables, the new
line number can be a computed value. GOTO is quite useful within IF
statements to make the program loop or branch.

        GO TO 100
        GOTO 200+A
        IF A=0 GOTO 100

If the value of the expression is zero, negative, or a non-existent
line number, an error stop will result. If a GOTO is typed in the
command mode (without a beginning line number), the program will
begin executing at the specified line number instead of at the
beginning. This is useful for resuming execution of a program halted
by an error stop after correcting the error.

The GOSBUB Statement

        GOSUB expression

The GOSUB statement is like the GOTO statement, except that the
value of the expression in the GOSUB is saved before going to that
line number. The next occurrence of a RETURN statement (described
below) restores this saved line number, and execution continues with
the statement following the GOSUB. The series of statements called
by the GOSUB and ending in RETURN is called a "subroutine".
Subroutines may include GOSUBs of their own, and such GOSUBs can be
nested to any depth, limited only by the available memory. The
following examples all call a subroutine starting at line 100.

      GO SUB 100
      GOSUB 50*2
      GOSUB A          (where A=100)

An error stop will result if the line number given by the expression
is negative, zero, or does not exist. GOSUB may be typed in the
command mode, but may produce an error stop when the corresponding
RETURN is executed because there is no line number to return to.

                               -15-

The RETURN Statement

        RETURN
        RET

The RETURN statement (which can be abbreviated as RET) transfers
execution to the line following the most recent unused line number saved
by a GOSUB statement (see above). If there is no matching GOSUB line
number saved, an error stop results.

A subroutine is a sub-program which consists of several statements
that are used in two or more places in the main program. Rather than
duplicating the statements each time they are needed, they are
entered only once, and end with a RETURN statement. The subroutine
can then be called from any number of places by GOSUBs. The
following subroutine is called with a GOSUB 100. It will increment
A, print it, and return to the caller.

        100 LET A=A+1
        110 PRINT A
        120 RETURN

The END Statement

        END

The END statement should be the last one executed in a program. It
halts program execution and returns BASIC to the command mode. There
may be as many END statements in the program as desired.

The LIST Statement

        LIST
        LIST expression
        LIST expression, expression

The LIST statement is used to list part or all of the user program
in memory. LIST may used alone, or may be followed by one or two
expressions. Used alone, LIST will print the entire program. If one
expression is given, it is evaluated to form a line number. LIST
then prints this line of the program if it exists. If two
expressions are given, they are evaluated and LIST prints the
program lines between the two values (inclusive). If the last
expression in a LIST statement evaluates to a number for which there
is no line, the next line above that line number is listed as the
last line. Zero is not a valid line number, and an error stop will
result if it is used. The following are valid LIST statements.

        LIST
        LIST 100
        LIST 50*2
        LIST 100,200        (lists lines 100 to 200)
        LIST 500,400        (lists nothing)

                               -16-

LIST is normally used in the command mode (without a line number).
It can also be used within a program to list large blocks of text
instead of PRINT statements, although it will of course include line
numbers. A listing may be terminated early with the BREAK key. The
format used by LIST can be recorded on the terminal's mass storage
device, and subsequently reloaded by BASIC.

The NEW Statement

        NEW

The NEW statement clears the current program from memory, sizes
memory, and initializes the CPU registers. It is in effect a "cold
start", and should be used before entering a new program.

NEW is normally used in command mode (without a line number). If
used within a program, the program will commit "suicide" and erase
itself when the NEW statement is executed.

The RUN Statement

        RUN
        RUN, expression

The RUN statement is used to begin program execution at the first
(lowest) line number. RUN may be followed by one or more
expressions, separated by commas. These expressions are saved in the
line buffer as the initial input line. When an INPUT statement is
executed, it will first check the line buffer; if there is anything
in it, it will be used first (see INPUT).

        RUN
        RUN,1,2        (line buffer contains "1,2")

RUN is normally used in the command mode. If used within a program,
RUN works as a GOTO the first line of a program.

                               -17-

                            FUNCTIONS

Tiny BASIC has two intrinsic functions: RND for generating a random
number, and USR for calling a machine-language subroutine. Each
function returns a single value, and can be used in any expression
in place of a number or variable.

The RND Function

        RND (lowerlimit, upperlimit)

RND generates a positive random number between the specified
lowerlimit and upperlimit (inclusive). Both limits can be
expressions if desired. The limits must be 0 <= lowerlimit <=
upperlimit <= 32767 or an error stop will result. The following
examples generate a random number between 1 and 100 (inclusive).

        PRINT RND(1,100)
        LET A=RND(1,2*50)

The USR Function

        USR (address)
        USR (address, expression1)
        USR (address, expression1, expression2)

The USR function calls a machine-language subroutine at the
specified address, and optionally passes it the values of one or
two expressions. The subroutine can return a 16-bit number, which
becomes the value of the USR function. The three arguments in
parentheses can be any valid Tiny BASIC expression.

A number of pre-defined USR functions are included to read and write
data to memory, I/O ports, the keyboard, or the display. The user
can also call the machine-level monitor program, IDIOT/4 (described
in the next chapter). The monitor can be used to extend Tiny BASIC
with additional machine-language USR functions as described in
Chapter 8: Internal Operation.

        USR (6)         Read Character
                        Reads one ASCII character from the keyboard
                        or other serial input device, and returns
                        its decimal equivalent. Example:
                                LET C=USR(6)
                        sets C=65 if the user types the letter "A".

        USR (9,0,n)     Print Character
                        Prints the ASCII character specified by "n"
                        to the screen or other serial output device.
                        Only the lower 8 bits of "n" are used. The
                        second expression (=0) is ignored. The value
                        returned to BASIC is always 251. Example:
                                C=C+0*USR(9,C,C)
                        If C=65 (ASCII "A"), this prints an "A" and
                        leaves the value of C unchanged.

                               -18-

        USR (20,a)      Memory Peek
                        Returns the decimal value of the byte in
                        decimal memory address "a". Since the most
                        significant bit of Tiny BASIC numbers is the
                        sign, positive values of "a" are addresses
                        from 0000-7FFF hex, and negative values are
                        addresses from 8000-FFFF hex. Example:

                                PRINT USR(20,12)

                        reads decimal address 12 (=000C hex), which
                        contains the value 192 (=C0 hex); thus this
                        statement prints 192.

        USR (24,a,b)    Memory Poke
                        Writes the decimal value of the lower 8 bits
                        of expression "b" in decimal memory address
                        "a" and returns the value of expression "b".

                                LET A=USR(24,4115,24)

                        writes the ASCII <CAN> code 24 decimal (=18
                        hex) into memory address 4115 (=1013 hex),
                        and sets A=24.

        USR (32)        Call IDIOT/4 Monitor
                        Calls the machine-level monitor program. The
                        "*" prompt will be printed, and the monitor
                        commands will then be available. The monitor
                        saves the contents of all CPU registers; you
                        can restore them and return to Tiny BASIC
                        with the monitor command $R23 <CR>.

        USR (35,n,m)    Read/Write COSMAC I/O Pins
                        Returns the status of the COSMAC EF1-4 or Q
                        pin selected by "n", and optionally sets or
                        resets Q according to the value of "m".

                          n=0 returns 0 if Q=0,   1 if Q=1
                           =1    "    0 if EF1=1, 1 if EF1=0
                           =2    "    0 if EF2=1, 1 if EF2=0
                           =3    "    0 if EF3=1, 1 if EF3=0
                           =4    "    0 if EF4=1, 1 if EF4=0

                          m=0 leaves Q unchanged
                           =1   sets Q=1
                          =-1 resets Q=0 (m=any value but 0 or 1)

                        Note that the physical EF1-4 pins on the
                        COSMAC are active LOW (a low level on the
                        pin sets the corresponding flag high).
                        Only the lower 8 bits of "m" and "n" are
                        used. Values of "n" other than 0-4 always
                        return 1. Values of "m" other than 0 or 1
                        will reset Q=0.

                               -19-

        USR (38,a)      Read Input Port
                        For "a"=9 to 15, read the corresponding
                        COSMAC input port (IN1-IN7), and return
                        its decimal value (0-255). The lowest 4
                        bits of "a" specifies which input port
                        to read according to the following code:

                                a=9 reads IN1
                                =10   "   IN2
                                =11   "   IN3
                                =12   "   IN4
                                =13   "   IN5
                                =14   "   IN6
                                =15   "   IN7

                        For example: A=USR(38,11) sets A to the
                        decimal value of input port IN3.

        USR(38,a,b)     Write to Output Port
                        For "a"=1 to 7, output the value of the
                        lower 8 bits of expression "b" (0-255)
                        to output port OUT1-OUT7. For example,
                                A=A+0*USR(38,3,10)
                        outputs 10 (0A hex) to output port 3.
                        The value of A is not changed.

Note that Tiny BASIC treats all numbers as decimal. Most machine
language and hardware devices use hexadecimal or binary notation.
Machine language opcodes, memory addresses, and I/O port values in
hexadecimal must be converted to decimal for use by Tiny BASIC. For
example, to call a machine language subroutine at address 0020 hex,
you must use its decimal equivalent, 32. Similarly, address FFB5 hex
is 65461 decimal; since 65461 is larger than 32767 (Tiny BASIC's
maximum positive integer), subtract 65636 to get -75 (i.e. -75 in
Tiny BASIC represents FFB5 in hexadecimal).

Single-byte (8-bit) hexadecimal numbers should be represented by
positive numbers from 0-255 in decimal.

4-bit numbers 0-F hex are represented by positive numbers from 0-15
decimal.

The printable ASCII characters are represented by decimal numbers
from 32-127. ASCII control codes include <NUL> Null=0, <BS>
Backspace=8, <LF> LineFeed=10 (0A hex), and <CR> Carriage Return=13
(0D hex). Conversion charts are given for converting between
decimal, hexadecimal, and ASCII in Appendix E.

                               -20-

                             CHAPTER 7

                     THE MACHINE-LEVEL MONITOR

While many applications can be programmed completely in Tiny BASIC,
there will be some tasks that need higher performance. In such
cases, some or all of the program can be written in machine language
using the machine-level monitor program IDIOT/4. Machine language
offers great flexibility and much faster program execution, at the
expense of being much harder to write and debug. To use the monitor
properly, you will need a good working knowledge of the COSMAC
microprocessor and its instruction set. You should also have a copy
of the RCA "User Manual for the CDP1802 COSMAC Microprocessor",
publication MPM-201, available from RCA or TMSI.

The IDIOT/4 monitor provides direct access to the COSMAC
microprocessor and all system memory and I/O. You can examine and
change the contents of memory, CPU registers, and I/O bits EF1-4 and
Q; load and dump programs to your terminal or mass-storage media
(paper tape, cassette, etc.); block move memory contents from one
place to another, and run and debug programs with or without
breakpoints. The command and data formats are the same as used by
RCA's UT4-UT20 series monitor programs. IDIOT/4 can also be used the
RCA Editor and Assembler software for more advanced applications.

Operation

There are three ways to enter the monitor. To enter from Tiny BASIC,
use the USR(32) function in a command or program statement; (for
example, "PRINT USR(32)". From a machine language program, call the
monitor with a "SEP R1" instruction (hex D1). Finally, if interrupts
are enabled, you can call the monitor with a hardware interrupt (by
pulling the COSMAC's INTERRUPT pin 36 low with a pushbutton switch
for example).

In each case, the monitor first saves a copy of all CPU registers
and I/O bits EF1-4 and Q in RAM. All registers are saved correctly
except T (and possibly P and X as described later in the IDIOT
Monitor Summary). The monitor then types its "*" prompt and is ready
for your commands.

Commands consist of a punctuation character (?, !, or $) followed
immediately by a letter (M, P, or R). All other characters will be
printed on your terminal, but otherwise ignored. This feature lets
you type in messages, comments, or text for documentation purposes,
or just to check the terminal-to-computer I/O interface.

The commands to IDIOT/4 are ?M (examine memory), !M (change memory),
?R (examine registers), $R (run registers), and $P (run program).
All numbers are in hexadecimal, and leading zeros are unnecessary.

                               -21-

Spaces, line feeds, etc. can be used where not ambiguous to improve
readability. If the monitor detects a syntax error, it aborts the
command and types a "?" to indicate that it didn't understand it.
Commands are executed as they are typed in, so the "rubout" or
"backspace" keys cannot be used to correct errors. When a command
has been correctly executed, the monitor again types its "*" prompt
and is ready for the next command.

Examine Memory Command

        ?Maaaa nnnn <CR>

The "?M" command lists the contents of "nnnn" bytes of memory
starting at address "aaaa". Following the <CR>, the monitor types
the address as 4 hex digits, and then up to 16 data bytes of memory.
The data bytes are paired into 2-byte (4-digit) groups. A new line
is started every 16 bytes, with a semicolon ";" at the end of the
line to indicate that the listing is continued on the next line. A
final "*" indicates the end. Examples:

        ?M20 3<CR>          (user types)
        0020 C006 6F        (monitor prints)

        ?M240023 4<CR>      (oops! corrected 0024 by typing 0023)
        0023 C0 0BFE        (monitor prints)

        ?M26 4Z<CR>         (syntax error; 4Z isn't hex)
        ?                   (monitor prints "?" to indicate error)

        ?M0000 20<CR>
        0000 7100 E4C0 0800 C009 40C0 09A4 C006 665F;
        0010 1882 8020 97BA 48D5 58D5 0679 1100 0010

All numbers are in hexadecimal. Leading zeros are unnecessary. If
more than 4 digits are typed for the address or byte count, only the
last 4 are used; thus you can correct an error by simply following
it with the correct number. For instance, the second example shows
address 0024 was corrected to 0023. A long listing can be aborted by
hitting your terminal's BREAK (or any other key repeatedly.

The format used by ?M is suitable for saving data on your terminal's
mass storage facility (paper tape, cassette, etc.). Before typing
the final <CR>, turn on your punch or recorder. The monitor will
ignore any spaces, nulls, or text you type as a header. Then type
the final <CR> and the monitor will start outputting data. The
resulting tape can then be used by the !M command to load memory.

                               -22-

Change Memory Command

        !Maaaa dd .... dd <CR>
        !Maaaa dd .... dd, comments <CR>
               dd .... dd
        !Maaaa dd .... dd; comments <CR>
          aaaa dd .... dd

The !M command writes data byte pairs "dd" into successive memory
locations, starting at address "aaaa". The data bytes are written
into memory as soon as they are typed, without waiting for the final
<CR>. They must come in pairs of hex digits, or a syntax error will
occur. Otherwise, nulls, spaces, and other non-hex characters are
ignored by the monitor, and can be used to improve readability. A
final <CR> ends the command.

Two optional forms are provided for loading more data than will fit
on one line. If you type a comma "," anything up to the final <CR>
will be ignored, and memory loading will resume on the next line at
the next sequential address. Similarly, a semicolon ";" also ignores
anything you type up to the final <CR>; memory loading continues on
the next line at a new address specified by the first hex number on
the line. This allows changing non-sequential bytes of memory. The
following examples illustrate the use of the !M command.

        !M1000 001122 <CR>  (user types)
        *                   (monitor writes 00 to address 1000,
                             11 to address 1001, and 22 to 1002)

        !M20031003 3344<CR> (oops! corrected 2003 to 1003)
        *                   (monitor writes 33 to 1003, 44 to 1004)

        !M1005 55 6X <CR>   (syntax error; 4Z isn't hex)
        ?                   (monitor writes 55 to 1005, but then
                             prints "?" to indicate error)

        !M1006 66 77 88, comma makes it ignore comments <CR>
        99 AA BB,        like these <CR>
        CC <CR>             (this ends the Change Memory command)
        *

        !M100D DD; HERE: ORG 100Dh, SEP 13 semicolons let you <CR>
        100E EE;         DB 0EEh  load assembler files with a <CR>
        100E FF;         DB 0EEh  new address for each line   <CR>
        1010 <CR>           (ends command)
        *

        ?M1000 10 <CR>      (use ?M to examine the results)
        1000 0011 2233 4455 6677 8899 AABB CCDD EEFF;
        *

As with the ?M command, an erroneous address can be corrected by
just following it with the corrected one; only the last 4 digits
count. The third example shows a syntax error; the 55 gets written
into memory, but the 6X does not -- it had to be re-typed on the
following line. The last example shows the contents of memory after
this series of !M commands.
                               -23-

The !M command will accept data produced by the ?M command. Simply
type "!M;" without a final <CR>, then turn on your terminal's
reader. Everything will be ignored (because of the semicolon) until
the first <CR> is read from the tape. This should be followed with
the first address, and then the data bytes to be loaded. The !M
command will also load listings produced by the RCA assembler.

Move Memory Command

The ?M and !M commands can be used together to move a block of
"nnnn" bytes of memory from address "aaaa" to "bbbb". Any size block
can be moved, and overlapping blocks can be moved without error. The
following examples illustrate the block move.

        ?M0 10 !M1000 <CR>       (moves 10 bytes from 0 to 1000)
        *

        ?MC00 230024 !M1C00 <CR> (oops; corrected byte count to 24)
        *

        ?M0 10000 !M1 <CR>       (move entire memory up 1 byte)
        *

        ?M1234 56X               (syntax error; 56X is not hex)
        ?

The first example moves 10 hex (16 decimal) bytes starting at
address 0000 to address 1000 hex. The addresses and byte count can be
corrected using the last-4-digits rule as in the ?M and !M commands.
The third example is the largest possible block move, and moves the
entire contents of memory up one byte. But, since the IDIOT/4
monitor is in ROM, it is write protected against damaging itself.
But the Move Memory command can move anything in RAM, since it uses
no RAM itself. Like ?M and !M, spaces can be used freely for
readability, but non-hex characters will cause a syntax error.

Examine Registers

        ?R <CR>

Upon entry, IDIOT/4 saves the state of the COSMAC CPU in RAM. This
data can be listed using the ?R command. What actually happens is
that ?R supplies the address and byte count, and performs a ?M to
list the data. The following example shows the source of the data in
each 4-byte pair of bytes in parentheses.

        ?R <CR>
        10B8 (ID,T) (DF,D) (IE,Q) (EF1-4);
        10C0 (R0) (R1) (R2) (R3) (R4) (R5) (R6) (R7);
        10D0 (R8) (R9) (RA) (RB) (RC) (RD) (RE) (RF)
        *

The first number on each line is the starting address for that line
of register contents. For example, R1 is in location 10C2 and 10C3.

                               -24-

The register contents are interpreted as follows:

        ID - Identifies what caused the registers to be saved.
                00 - power or hardware RESET
                10 - hardware or software interrupt, or USR(32)
         T - Contents of T register. Contains old X and P if entry
                     was via a hardware interrupt
        DF - Contents of DF flag
                00 - DF=0
                01 - DF=1
         D - Contents of D register (accumulator)
        IE - Status of Interrupt Enable bit
                00 - interrupts disabled
                01 - interrupts enabled
         Q - Status of Q bit
                00 - Q=0
                01 - Q=1
     EF1-4 - Status of external flags about 500 usec after entry
                1xxx - EF1=1 (EF1 pin low)
                0xxx - EF1=0 (EF1 pin high)
                x2xx - EF2=1 (EF2 pin low)
                x0xx - EF2=0 (EF2 pin high)
                xx3x - EF3=1 (EF3 pin low)
                xx0x - EF3=0 (EF3 pin high)
                xxx4 - EF4=1 (EF4 pin low)
                xxx0 - EF4=0 (EF4 pin high)
     R0-RF - Contents of registers R0-RF; 4 hex digits each

Saving CPU registers is a great aid in debugging machine-language
programs. Breakpoints (SEP R1 instructions) can be inserted into a
program with the !M command. When executed, the breakpoint saves the
registers for analysis with the ?R command. If desired, the register
values saved in RAM can be altered with the !M command. These values
can then be restored to the registers, and program execution resumed
where it left off with the $R command (described below).

The COSMAC architecture places certain limitations on the accuracy
of the saved registers. The COSMAC itself alters R0, P, X, and IE
upon Reset, so their previous contents are lost. In addition, the
monitor uses R4 as a pointer to RAM. Thus if the ID code is 00
(Reset), registers R0, P, X, IE, and R4 will not show the actual
values at the time of Reset.

If the ID code is 10, entry was via a hardware interrupt (COSMAC
Interrupt pin low) or a software interrupt (SEP 1 instruction).
Register R1 must point to the interrupt handler and R2 must point
into RAM with at least 4 free bytes for a stack. When the COSMAC
responds to a hardware interrupt, it saves the old values of X and P
in the T register; therefore the previous contents of T is lost.
Otherwise, all registers are saved correctly.

                               -25-

There are two ways to enter the monitor with a software interrupt
(SEP 1). You can either save X and P; or T; but not both. To save T,
insert a SEP 1 instruction in any machine-language program. To save
X and P, insert a MARK and a SEP 1. MARK copies X and P into T, then
pushes T onto the stack (via R2). Since MARK affects the stack and
R2, the saved register contents should be interpreted accordingly.
Other than this, all registers are saved correctly.

Run Register Command

        $R <CR>
        $Rp <CR>
        $Rxp <CR>

The Run Register command restores all CPU registers (except T) to
the values sown by the ?R command, and resumes program execution
with these values. An optional value can be specified for X and P;
if not specified, 0 is assumed. The following examples illustrate
the use of the $R command.

        $R <CR>          (restore register, and set X=0, P=0)
        $R3 <CR>         (same, but set X=0, P=3)
        $R23 <CR>	 (same, but set X=2, P=3)

Since the Tiny BASIC USR function exits with X=2 and P=3, the last
example will return to BASIC and resume execution right where it
left off.

There are a few precautions to observe when using $R to resume a
program that was interrupted by a software interrupt (SEP 1)
instruction:

1. Be sure to restore the correct value of X and P.

2. If a byte of the program was replaced by the SEP 1 (to insert a
   breakpoint), execution will resume AFTER the SEP 1 and the
   original instruction will not have been executed. You will have
   to replace the SEP 1 with the original instruction, and decrement
   the program counter by 1 so this instruction gets executed when
   you resume.

3. If the 2-byte sequence MARK, SEP 1 were substituted, two bytes
   will need to be replaced with the original instructions, and the
   program counter decremented by two to execute them. Also, R2 and
   M(R2+1) will have to be corrected as well. These details can be
   fixed by using !M to correct the RAM and register values saved in
   RAM before using the $R command.

                               -26-

Run Program Command

        $Paaaa

The Run Program Command begins execution of the program at address
"aaaa" with X=0, P=0, and interrupts disabled (similar to the effect
of a hardware reset). If no address is specified, execution begins
at 0000.

        $P100N           (syntax error; 100N is not hex)
        ?

        $P1000           (runs program at 1000 hex)

The address must be a hexadecimal number. As for the ?M and !M
commands, only the last 4 digits typed are used for the address. If
you make a mistake, simply retype the correct address as the last
four digits.

                               -27-

                             CHAPTER 8

                        INTERNAL  OPERATION

Although TMSI Tiny BASIC is quite versatile as delivered, you may
wish to modify it for special applications. Typical changes may
include adding new USR functions, modifying the I/O routines, or
saving a BASIC program in ROM. To do these successfully, you will
need a good working knowledge of the COSMAC microprocessor and must
be familiar with the normal operation of Tiny BASIC  and the IDIOT
monitor. This chapter will then provide you with the necessary
details on memory allocation, register usage, and available
subroutines.

Memory Allocation

TMSI Tiny BASIC is normally supplied in a single 4k byte 27C32 EPROM
which is addressed from 0 to 4095 (0000 to 0FFF hex). This ROM
contains all the necessary software, including I/O routines. Only
the lower 3/4 of the ROM is used, leaving approximately 1k bytes
available for expansion or user programs. Refer to the actual source
code listing (Appendix G) for the specific beginning and ending
addresses in your ROM.

Tiny BASIC requires at least 256 bytes of RAM to store its buffers,
variables, pointers, and other data. This RAM must be addressed at
4096 to 4351 (1000 to 10FF hex). This RAM is initialized from data
in the ROM whenever you answer the "NEW?" prompt with "Y" (for
"yes"), or use the BASIC NEW command. Once initialized, Tiny BASIC
works only with the data in RAM. Thus, you can temporarily change
the way BASIC operates (until the next NEW) by changing values in
RAM, or permanently change operation by changing the corresponding
values in ROM with an EPROM programmer. Appendix F summarizes the
contents of the first page of RAM and the corresponding ROM
addresses from which they are initialized. The following sections
provide further information on exactly what each of these values
does.

"NEW" also causes Tiny BASIC to set itself up to use all of the RAM
available. It begins searching for RAM at address 4352 (hex 1100);
just above the first page of RAM. The search continues upward until
the first non-RAM byte is found. The actual contents of RAM is not
changed by the test, so any programs or data in RAM are not harmed.
Once RAM has been sized, the lower limit (normally 1100 hex) is
saved at location 1020-1021 hex, and the upper limit at location
1022-1023 hex. These limits define the amount of memory available
for new Tiny BASIC programs.

Tiny BASIC needs a "stack" during program execution to store return
addresses, GOSUB line numbers, and other temporary data. This stack
begins at the upper end of RAM. It grows downward as information is

                               -28-

pushed onto it, and shrinks back upward as the information is popped
back off again. The contents of location 1017 hex is the "stack
reserve", which specifies the number of bytes of RAM reserved for
this stack. The stack reserve is normally set to 32 (20 hex), though
Tiny BASIC itself only uses about half of this. Increasing the stack
reserve gives you more room for nested GOSUBs or machine-language
subroutine calls; decreasing the stack reserve gives you a little
more room for programs. If you leave too little stack reserve, you
may run out of stack space during program execution. If this happens
in BASIC, it causes an error stop with the message "!232". If it
happens during a machine-language subroutine, it can destroy the
last line of the BASIC program. 

Internal BASIC Program Format

New Tiny BASIC programs are stored in RAM, beginning at the lower
limit specified in locations 1020-1021 hex and growing upward. The
contents of locations 1024-1025 hex is the end-of-program pointer,
and points to the last byte of the program plus the stack reserve.
When lines are deleted from the program, they are removed from RAM,
the rest of the program is shifted down to fill the hole, and the
end-of-program pointer is decreased by the appropriate amount. New
lines are inserted into the program in ascending numerical order. A
hole is created between the appropriate lines by moving the rest of
the program up, inserting the new line, and increasing the
end-of-program pointer by the right amount. If the insertion would
cause the end-of-program plus stack reserve to exceed the upper end
of RAM, you have run out of memory and a "!8" message is printed.
Since the stack reserve is included in this test, you can run any
program you can enter successfully.

Once in RAM, each line of a Tiny BASIC program begins with a 2-byte
line number (converted to binary), and ends with a carriage return
(<CR>, 0D hex). The bytes in between contain the remaining ASCII
characters in the line, exactly as originally entered and complete
with spaces. The end of the program is marked by a 2-byte 0000 after
the last line. The following shows a simple BASIC program in RAM:

	:20 END                    (enter a 2-line BASIC program)
        :10 PR A
        :X=USR(32)                 (call the monitor to examine it)
        *?M1017 F                  (display the BASIC pointers)
             vv------------------- (stack reserve)
        1017 20 0038 1234 0679 0679;
        1020 1100 17FF 112E------- (end of program + stack reserve)
                  ^^^^------------ (upper end of RAM)
             ^^^^----------------- (start of program)
        *?M1100 F                  (OK: show the BASIC program)
        1100 000A 5052 2041 0D00 1445 4E44 0D00 00
        *    \  / | |  | |  |  \  /|  | |  | \   /
              10  P R    A <CR> 20 E  N D <CR> 00

The lines were sorted into ascending order, the last two bytes were
0000, and the last byte was located at (end of program + stack
reserve)-(stack reserve)-(start of program) = 112E-1100-20 = 110E.

                               -29-

Saving a BASIC Program in EPROM

A BASIC program in RAM will be lost whenever the computer is turned
off or loses power. To prevent this, you can save your program in
Read-Only Memory (ROM), which retains its contents indefinitely
without power. TMSI Tiny BASIC automatically searches for such a
program in ROM following power-on or Reset. If found, the ROM
program is executed immediately, without other inputs: The initial
<CR>, "NEW?" message response, and RUN command are not necessary.
Thus you can write programs for control systems, test fixtures, and
other dedicated applications that "wake up" and run without a person
to type commands. In fact, no terminal keyboard or display is needed
at all unless your own BASIC program uses PRINT or INPUT statements.

In general, any TMSI Tiny BASIC program can be saved in ROM. The ROM
version will be located at a different address than its RAM version,
but this does not normally cause a problem because Tiny BASIC
programs are intrinsically ROM-able and relocatable without change.
However, there are a few special requirements that your Tiny BASIC
program must meet to be saved in ROM successfully:

1. The Command Mode

   a. You cannot insert or delete lines from a BASIC program in ROM.
      The program is permanent, and can't be changed by the
      computer.

   b. Likewise, the NEW command cannot clear a program in ROM.

2. The USR Function

   a. No USR function can alter the BASIC program itself.

   b. If a USR function reads data within the program itself, it
      must address the data relative to the start-of-program
      pointer, not by an absolute address. For example, you could
      read the 100th byte in a BASIC program in RAM by:

        10 LET X=USR(20,100+4352)

      since programs in RAM always begin at address 4352. But a ROM
      program will begin at a different address, which depends on
      where the ROM is addressed. Therefore, calculate the location
      of the 100th byte by using the start-of-program pointer:

        10 LET X=USR(20,100+USR(20,4128)*256+USR(20,4129))

      The start-of-program pointer is a 16-bit address, stored at
      locations 4128-4129. The second USR function reads the upper
      half of this address (at 4128), multiplies it by 256 to make
      it the most significant byte of a Tiny BASIC number. The third
      USR function then reads the lower byte (at 4129) and adds it
      to produce a single 16-bit Tiny BASIC number. This number
      points to the start of the BASIC program regardless of whether
      it is in ROM or RAM. The first USR function can then read the
      100th byte in the program by adding 100 to this number.

                               -30-
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

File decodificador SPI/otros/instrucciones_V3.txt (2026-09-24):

-------------------------------------------DEFINICIONES PREVIAS---------------------------------------------------------------
; voy a usar registros y valores especificos para que se entienda mejor, pero se pueden usar otros registros y otros valores

para hacer el pulso en PC7 debe estar en la memoria lo siguiente (Esas posiciones deben estár libres, si no lo estan, elegir otras. Pero tienen que ser consecutivas)
esos bits son las instruciones para hacer PC7 -> 1, y PC7 -> 0 en el 82C55
7F00	0XXX1100	para PC6 -> 0
7F01	0XXX1110	para PC7 -> 0
7F02	0XXX1111	para PC7 -> 1
7F03	0XXX1110	para PC7 -> 0
7F04	SE DEJA EN BLANCO PARA LEER EL PUERTO A
7F05	0XXX1101	para PC6 -> 1

R3 -> F800	R3 apunta a la primera dirección del SPI

R4 -> 7F00	R4 apunta a la dirección donde estan las instrucciones para hacer Set y Reset de PC6 y PC7 del 82C55, también para la lectura del puerto A

Estos registros deben ser cargados en una rutina previamente, y no deben modificarse en el transcurso de otras rutinas no relacionadas a la del circuito para la comunicación SPI de manera que siempre estén listas para ser utilizados

-------------------------------------------RUTINA DE ESCRITURA Y LECTURA JUNTAS-----------------------------------------------------------------------------

		; Se parte de que el dato que se quiere escribir está en el acumulador D, si no se quiere transmitir y solo recibir, no importa que tiene D
	STR R3	; D -> M(R3)	se escribe el dato a enviar al CD4014
	SEX R4	; 4 -> X
	OUT 7	; M(R(X)) -> BUS; R(X) + 1 -> R(X)	Esto hace PC6 -> 0
	OUT 7	; M(R(X)) -> BUS; R(X) + 1 -> R(X)	Esto hace PC7 -> 0
	OUT 7	; M(R(X)) -> BUS; R(X) + 1 -> R(X)	Esto hace PC7 -> 1
	OUT 7	; M(R(X)) -> BUS; R(X) + 1 -> R(X)	Esto hace PC7 -> 0
CHECK:	INP 4	; BUS -> M(R(X)); BUS -> D
	LDX	; M(R(X)) -> D
	SHR	; SHIFT D RIGHT, LSB(D) -> DF, 0 -> MSB(D)
	SHR
	SHR	; Ahora DF = PA2
	BNF CHECK
	INC R4
	OUT 7	; M(R(X)) -> BUS; R(X) + 1 -> R(X)	Esto hace PC6 -> 1
	DEC R4
	DEC R4
	DEC R4
	DEC R4
	DEC R4
	DEC R4	; decremento R4 dos veces para ponerlo en su valor inicial (la instrucción OUT lo modificó, lo quiero dejar como estaba)
	LDN R3	; M(R(N)) -> D; R(N) + 1 -> R(N)	Hay que tener cuidado porque aumenta R(N)
	DEC R3	; Decrementa R3 porque la instrucción anterior lo aumentó

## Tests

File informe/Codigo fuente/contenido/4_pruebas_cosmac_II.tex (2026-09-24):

% --------------------
  \chapter{Pruebas en el COSMAC ELF II}
% --------------------
\label{C:pruebas_cosmac_elf_II}

%%%%%%%%%%%%%%%%%%%%%%%%%%%%%%%
En las instalaciones de la facultad de ingeniería se cuenta con el COSMAC ELF II, el cual fue comentado en la sección~\ref{C:cosmac_elf_II}. A modo de introducción, antes de comenzar a desarrollar los sistemas del proyecto, se realizaron pruebas sobre el COSMAC ELF II, para probar su funcionamiento y comenzar a comprender la operación del microprocesador. 

\begin{foto}[ht!]
  \centering
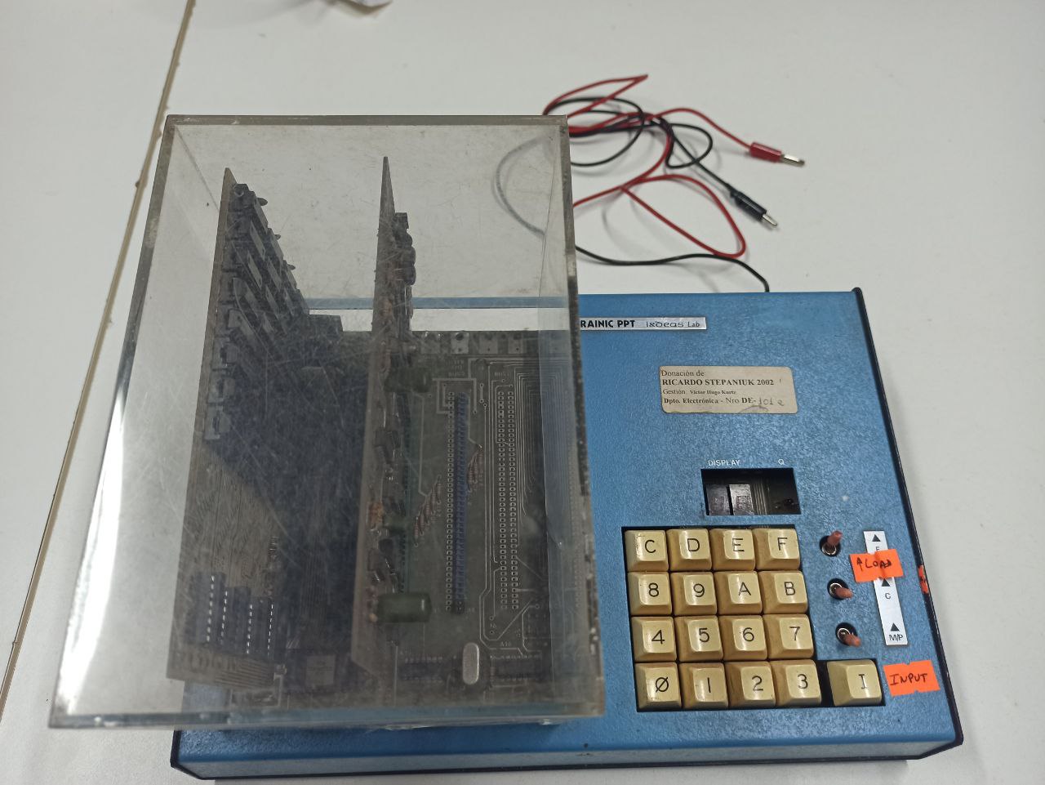
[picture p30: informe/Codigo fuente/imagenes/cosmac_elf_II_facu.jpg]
  
  \caption{COSMAC ELF II, propiedad de la facultad de ingeniería}
  \label{F:cosmac_elf_ii_falcultad}
\end{foto}

En la figura~\ref{F:cosmac_elf_ii_falcultad} se encuentra una fotografía del COSMAC ELF II que se encuentra en la facultad. Para utilizarlo fue necesario realizar reparaciones sobre el mismo. Un capacitor de entrada en la etapa de alimentación (en paralelo al pin de entrada del regulador LM7805) se encontraba dañado y fue necesario reemplazar el mismo, como así también soldar un cable a la placa para reemplazar una pista que se encontraba dañada. Luego se soldaron dos cables a los pines de alimentación de la placa de la computadora, para así poder conectarla a una fuente de alimentación.

Una vez realizadas estas reparaciones, se conectó el COSMAC ELF II a una fuente de alimentación configurada a \num{8}~\si{\volt} y se encendió. Para comprobar su funcionamiento correcto, se grabaron dos programas encontrados en línea \cite{programacion_cosmac}, junto con la explicación detallada del procedimiento para realizar la programación.

Se puede cargar un programa en el COSMAC ELF II poniendo el interruptor LOAD en la posición ON, con RUN y MP (Memory Protect) en OFF, y luego ingresar un byte con el teclado para finalmente presionar el botón INPUT. Esto graba un byte en la primera dirección de memoria. Para grabar otro byte en la siguiente dirección de memoria simplemente se debe ingresar el mismo en el teclado y volver a presionar INPUT. Una vez que se ingresaron todos los bytes del programa, MP debe colocarse en ON para proteger la memoria.

Con el programa ya cargado, para correrlo, se debe colocar LOAD en ON, esto resetea el microprocesador, luego se coloca RUN en ON, con lo cual el programa comienza a funcionar.

Siguiendo este procedimiento, se comprobó el funcionamiento del COSMAC ELF II con dos programas, uno que hace parpadear el LED Q, y otro que enciende el mismo cuando el botón INPUT es presionado.

%%%%%%%%%%%%%%%%%%%%%%%%%%%%%%%

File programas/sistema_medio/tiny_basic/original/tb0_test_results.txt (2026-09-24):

:
STARTING HOLLYWOOD COMPUTER DEMO
N IS 10
N IS 9
N IS 8
N IS 7
N IS 6
N IS 5
N IS 4
N IS 3
N IS 2
N IS 1

:LIST

10 PRINT "STARTING HOLLYWOOD COMPUTER DEMO"
20 LET N=10
30 PRINT "N IS "; N
40 REM CALL $38 TO OUTPUT N ON PORT 4, (LEDs)
50 LET X=USR(38,4,N)
60 LET N=N-1
70 IF N>0 GOTO 30
90 END

:

; "NEW" would not clear embedded program!
; to clear embedded program, must jump to "COMMAND" at 09F8H.
; a "USR(COMMAND)" may do that.
; that's (9 X 256) +(15 X 16) + 8 = 2552 decimal

:LIST

10 PRINT "STARTING HOLLYWOOD COMPUTER DEMO"
20 LET N=10
30 PRINT "N IS "; N
40 REM CALL $38 TO OUTPUT N ON PORT 4, (LEDs)
50 LET X=USR(38,4,N)
60 LET N=N-1
70 IF N>0 GOTO 30
90 END

:X=USR(2552)

NEW? Y
:LIST

; I enter a new program...

:10 I=1
20 PRINT I
30 I=I+1
40 IF I<10 GOTO 20
50 END

:RUN
1
2
3
4
5
6
7
8
9

;enter IDIOT monitor with USR(32)

:USR(32)

!201
:X=USR(32)

*?M 0000 20
0000 7100 E4C0 0800 C009 40C0 09A4 C006 6608;
0010 1802 8020 97BA 48D5 58D5 0679 8100 0080
*

;back to Tiny BASIC via COMMAND; keep last program

*$P09F8

NEW? N
:LIST

10 I=1
20 PRINT I;" ";
30 I=I+1
40 IF I<10 GOTO 20
50 END

:

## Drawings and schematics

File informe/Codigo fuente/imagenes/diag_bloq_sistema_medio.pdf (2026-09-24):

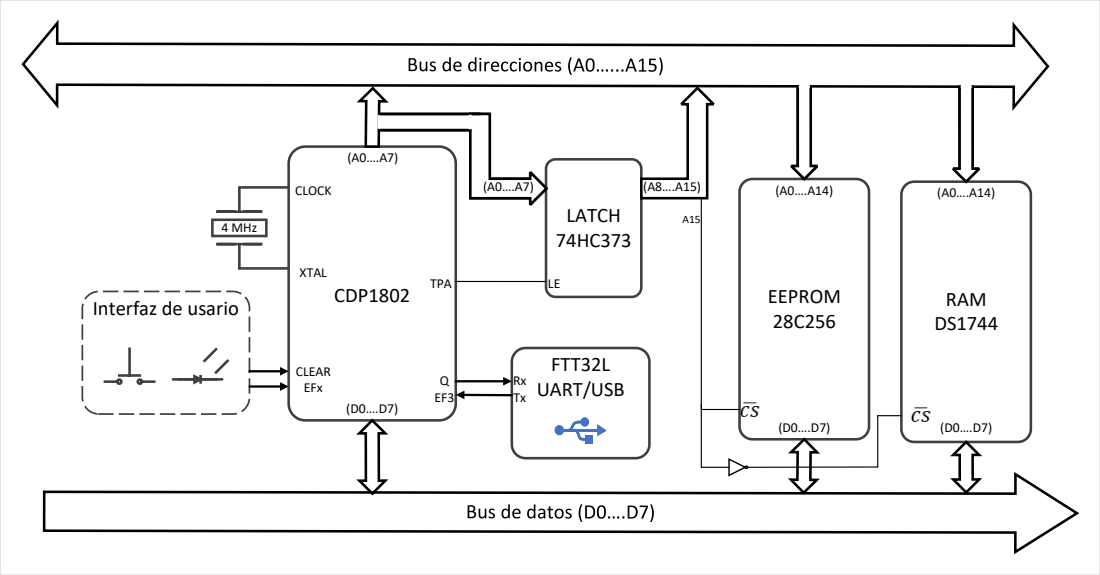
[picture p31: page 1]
CDP1802; EEPROM; LATCH 74HC373; TPA; RAM DS1744; FTT32L UART/USB Q EF3; 4 MHz; CLOCK; XTAL; CLEAR EFx

Interfaz de usario

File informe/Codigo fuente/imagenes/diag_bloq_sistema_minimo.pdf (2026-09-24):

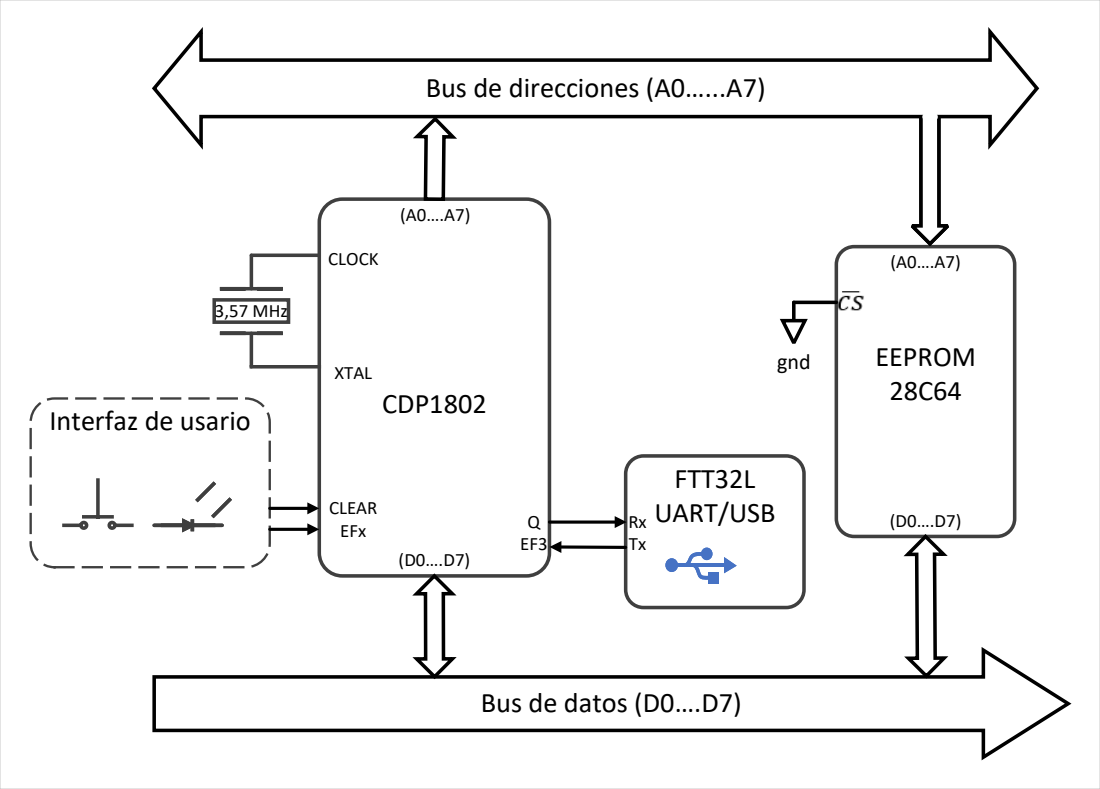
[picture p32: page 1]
CDP1802; EEPROM 28C64; FTT32L; UART/USB; 3,57 MHz; CLOCK; XTAL; CLEAR EFx; gnd

Bus de direcciones (A0…...A7)

Interfaz de usario

Bus de datos (D0….D7)

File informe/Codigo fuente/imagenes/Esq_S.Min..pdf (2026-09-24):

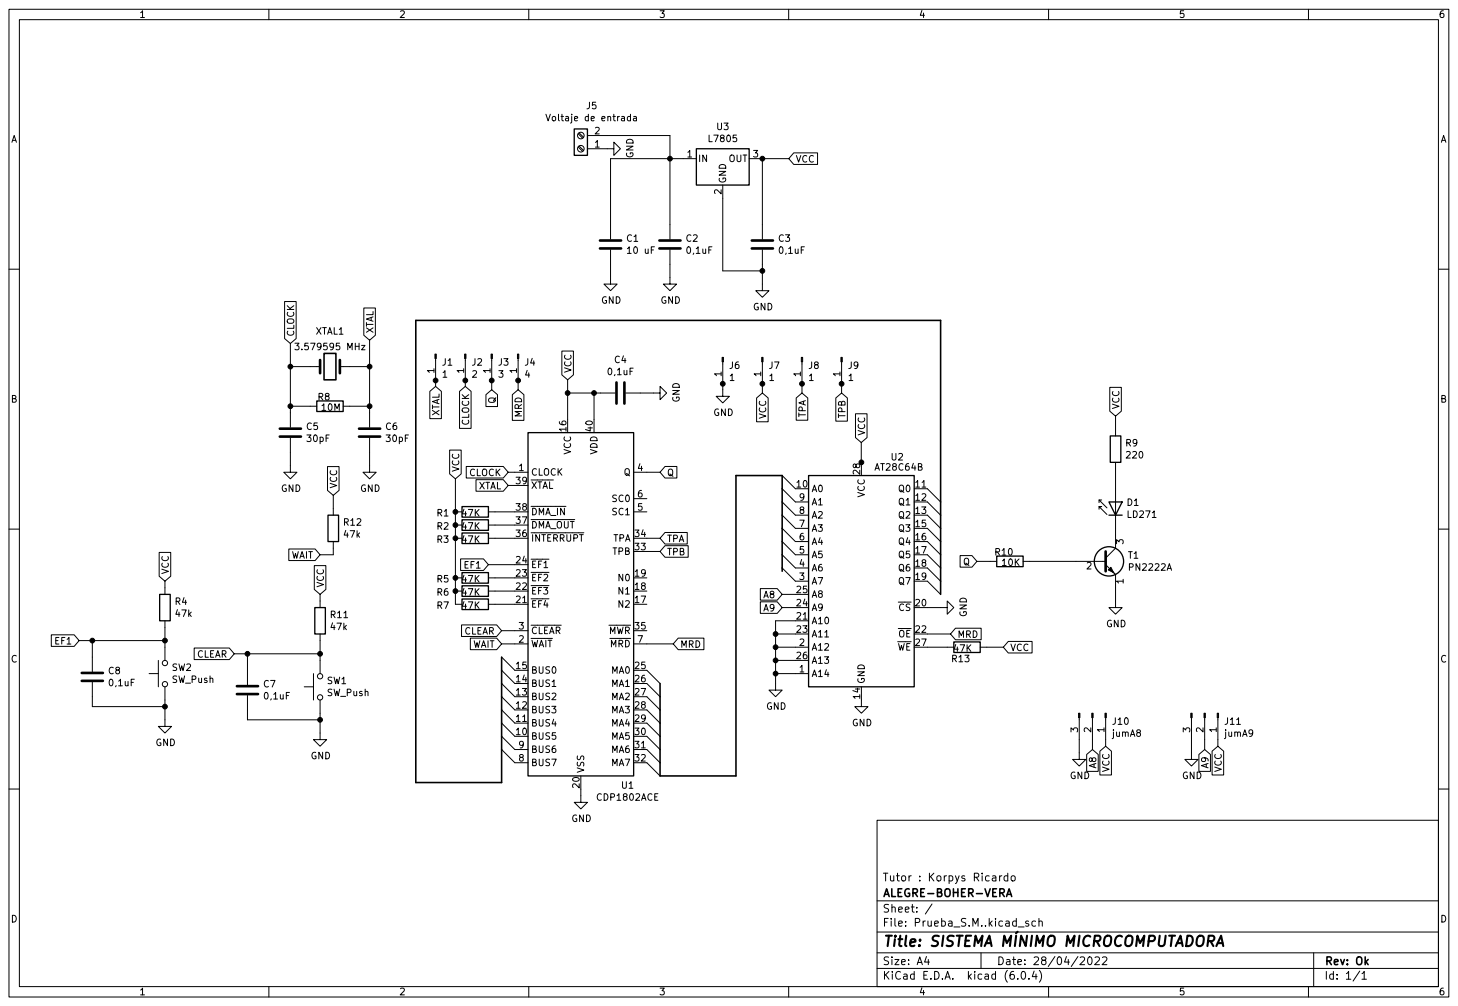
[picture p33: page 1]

J5 Voltaje de entrada GND GND

Q VCC A9 TPB WAIT CLEAR CLOCK VCC XTAL CLOCK VCC XTAL MRD VCC

Tutor : Korpys Ricardo
File: Prueba_S.M..kicad_sch Sheet: / ALEGRE-BOHER-VERA

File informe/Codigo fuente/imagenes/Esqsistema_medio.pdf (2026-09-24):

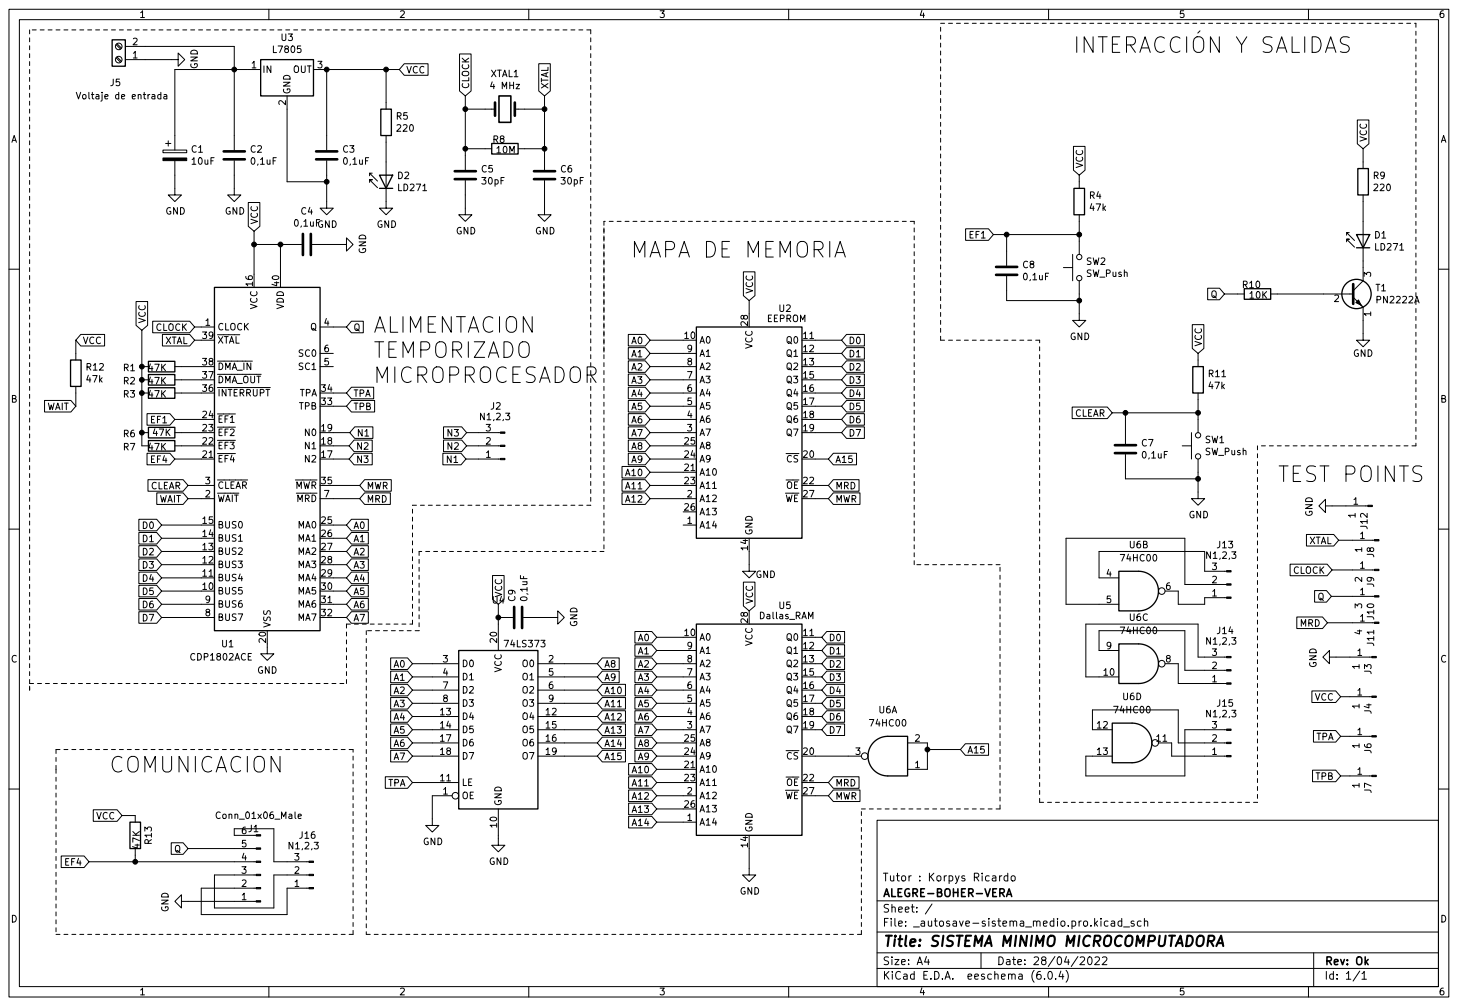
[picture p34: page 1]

File: _autosave-sistema_medio.pro.kicad_sch Sheet: / ALEGRE-BOHER-VERA

Id: 1/1 Title: SISTEMA MINIMO MICROCOMPUTADORA

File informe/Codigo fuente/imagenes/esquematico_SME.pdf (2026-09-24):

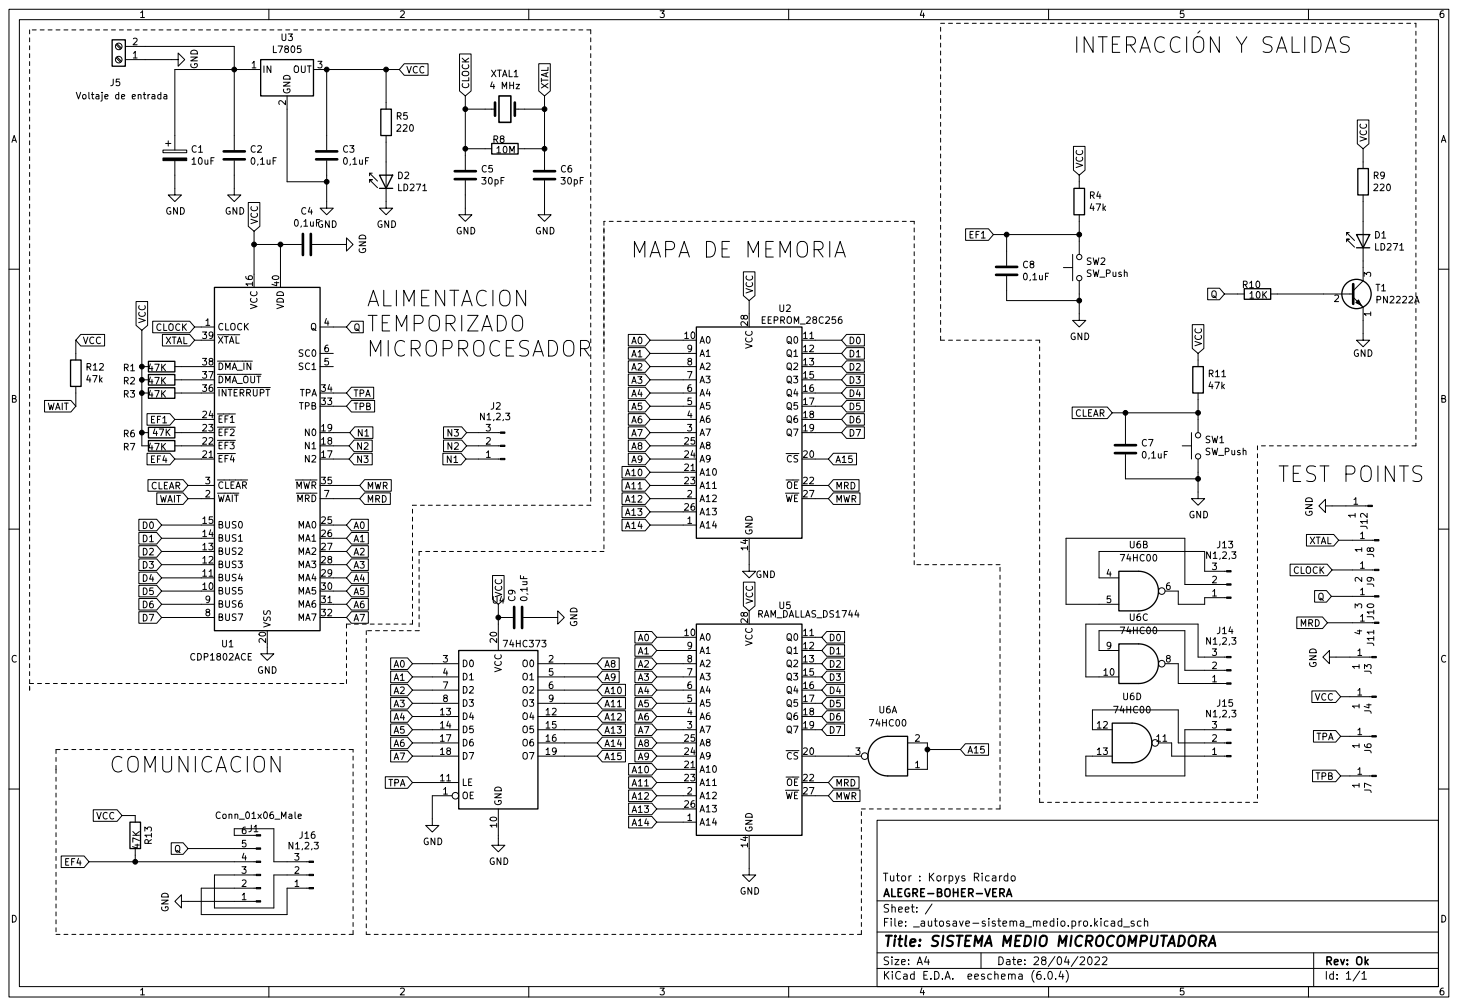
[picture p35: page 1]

File: _autosave-sistema_medio.pro.kicad_sch Sheet: / ALEGRE-BOHER-VERA

Id: 1/1 Title: SISTEMA MEDIO MICROCOMPUTADORA

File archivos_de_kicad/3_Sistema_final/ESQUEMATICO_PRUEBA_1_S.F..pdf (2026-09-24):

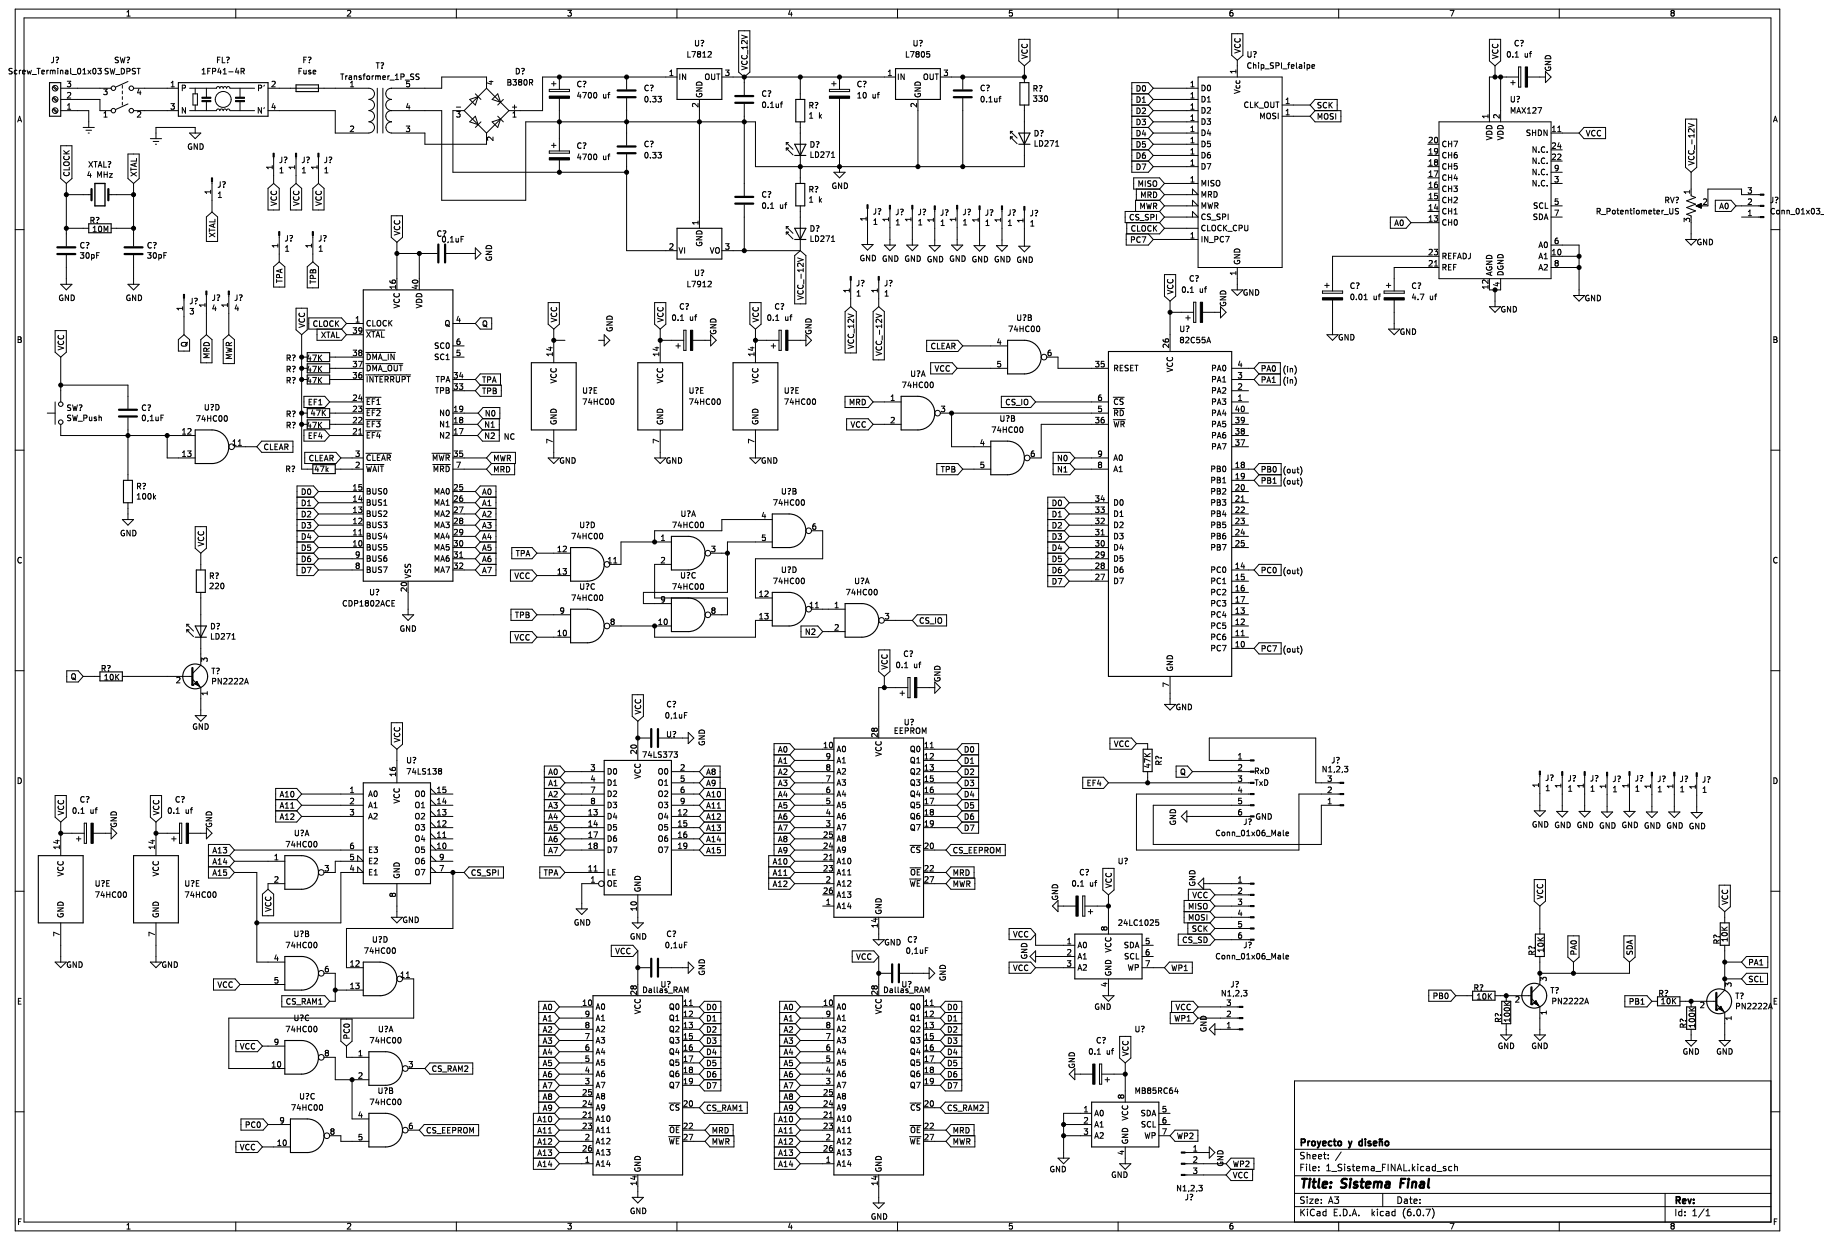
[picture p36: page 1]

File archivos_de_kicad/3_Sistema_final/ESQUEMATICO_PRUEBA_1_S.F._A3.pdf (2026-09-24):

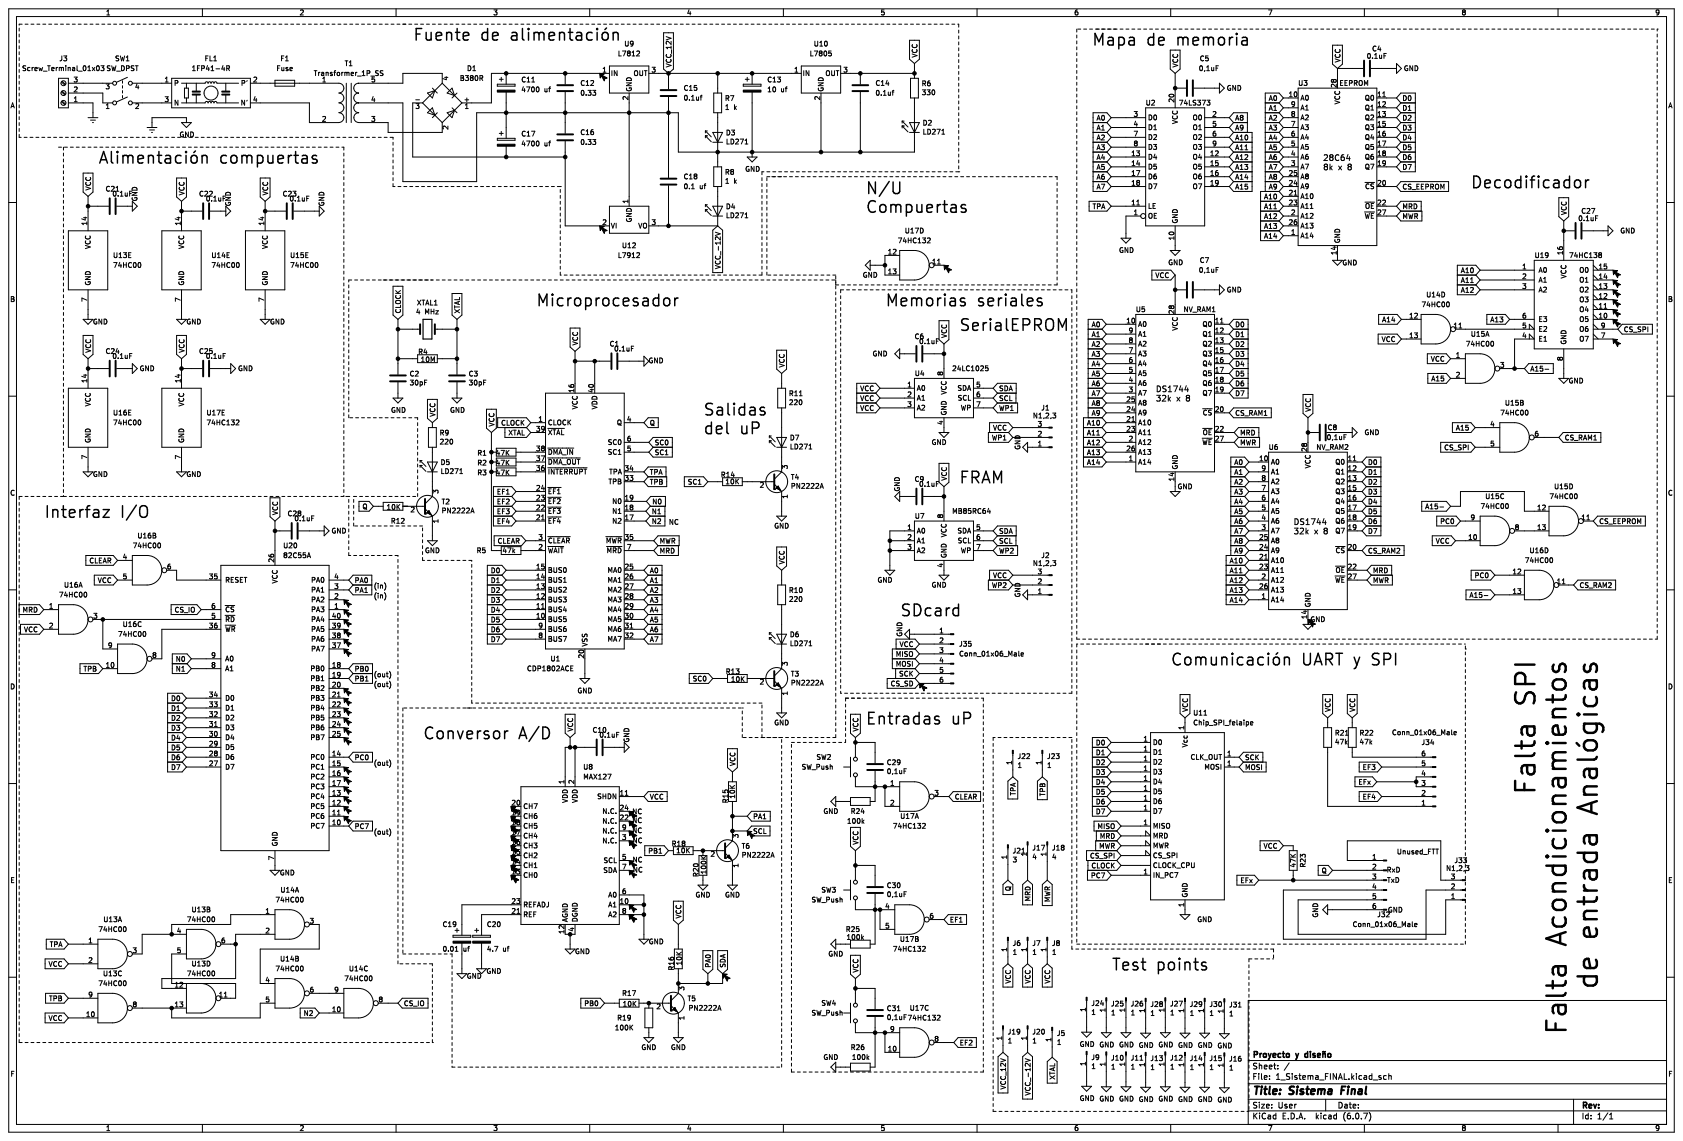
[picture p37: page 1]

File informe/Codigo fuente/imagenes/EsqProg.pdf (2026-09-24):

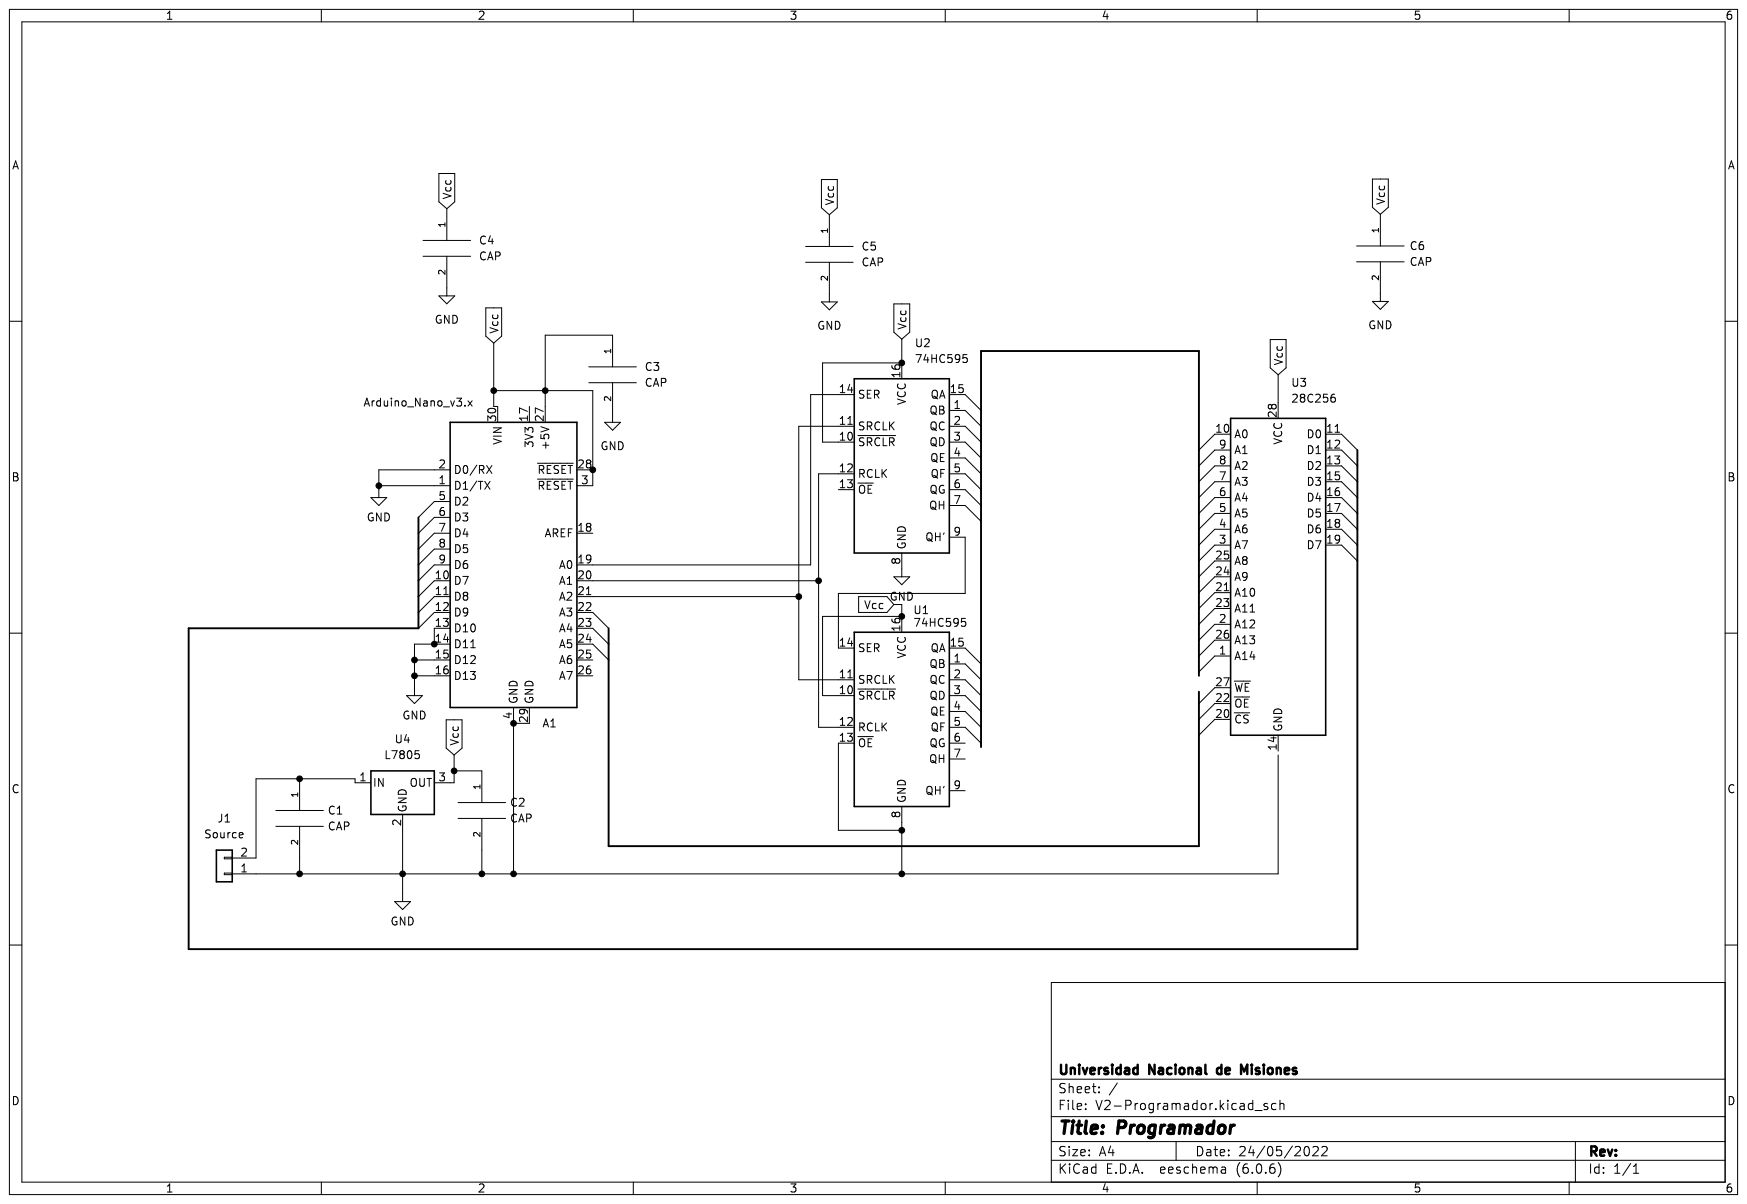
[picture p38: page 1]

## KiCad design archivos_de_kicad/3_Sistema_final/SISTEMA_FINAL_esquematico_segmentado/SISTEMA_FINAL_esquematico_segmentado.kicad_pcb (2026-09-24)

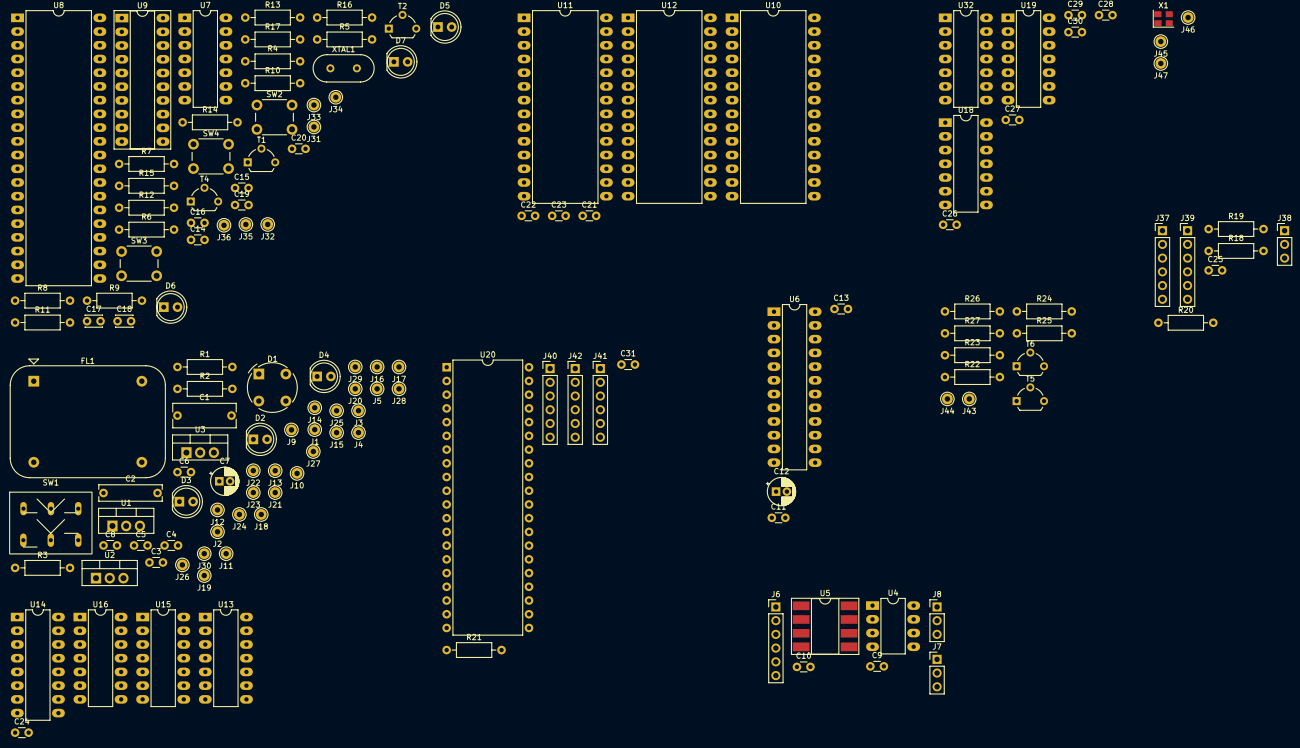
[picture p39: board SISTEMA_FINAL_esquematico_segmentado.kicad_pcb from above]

Board: 2 copper layers, 144 parts (0 on the bottom side), 133 nets, no tracks yet.

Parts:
C1: 4700 uf; C_Rect_L11.5mm_W4.3mm_P10.00mm_MKT
C2: 4700 uf; C_Rect_L11.5mm_W2.8mm_P10.00mm_MKT
C3, C4: 0.33; C_Disc_D3.0mm_W1.6mm_P2.50mm
C5, C8: 0.1uf; C_Disc_D3.0mm_W1.6mm_P2.50mm
C6: 0.1 uf; C_Disc_D3.0mm_W1.6mm_P2.50mm
C7: 10 uf; CP_Radial_D5.0mm_P2.00mm
C9, C10, C13, C19, C21, C24, C25, C26, C27, C28, C29, C30, C31: 0.1uF; C_Disc_D3.0mm_W1.6mm_P2.50mm
C11: 0.01 uf; C_Disc_D3.0mm_W1.6mm_P2.50mm
C12: 4.7 uf; CP_Radial_D5.0mm_P2.00mm
C14, C15, C16, C20, C22, C23: 0,1uF; C_Disc_D3.0mm_W1.6mm_P2.50mm
C17, C18: 30pF; C_Disc_D3.0mm_W2.0mm_P2.50mm
D1: B380R; Diode_Bridge_Round_D9.0mm
D2, D3, D4, D5, D6, D7: LD271; LED_D5.0mm
FL1: 1FP41-4R; Filter_FILTERCON_1FPxx
J1, J2, J3, J4, J5, J9, J10, J11, J12, J13, J14, J15, J16, J17, J18, J19, J20, J21, J22, J23, J24, J25, J26, J27, J28, J29, J30, J32, J34, J36, J43, J44, J45, J46, J47: 1; Pin_D1.0mm_L10.0mm
J6, J37, J39, J40, J41, J42: Conn_01x06_Male; PinHeader_1x06_P2.54mm_Vertical
J7, J8, J38: N1,2,3; PinHeader_1x03_P2.54mm_Vertical
J31: 3; Pin_D1.0mm_L10.0mm
J33, J35: 4; Pin_D1.0mm_L10.0mm
R1, R2: 1 k; R_Axial_DIN0207_L6.3mm_D2.5mm_P10.16mm_Horizontal
R3: 330; R_Axial_DIN0207_L6.3mm_D2.5mm_P10.16mm_Horizontal
R4, R5, R6: 100k; R_Axial_DIN0207_L6.3mm_D2.5mm_P10.16mm_Horizontal
R7: 10M; R_Axial_DIN0207_L6.3mm_D2.5mm_P10.16mm_Horizontal
R8, R9, R10, R18, R21: 47K; R_Axial_DIN0207_L6.3mm_D2.5mm_P10.16mm_Horizontal
R11, R19, R20: 47k; R_Axial_DIN0207_L6.3mm_D2.5mm_P10.16mm_Horizontal
R12, R14, R16, R22, R23, R26, R27: 10K; R_Axial_DIN0207_L6.3mm_D2.5mm_P10.16mm_Horizontal
R13, R15, R17: 220; R_Axial_DIN0207_L6.3mm_D2.5mm_P10.16mm_Horizontal
R24, R25: 100K; R_Axial_DIN0207_L6.3mm_D2.5mm_P10.16mm_Horizontal
SW1: SW_Push_DPDT; llave_6pin
SW2, SW3, SW4: SW_Push; SW_PUSH_6mm_H4.3mm
T1, T2, T4, T5, T6: PN2222A; TO-92L_Wide
U1: L7812; TO-220-3_Vertical
U2: L7912; TO-220-3_Vertical
U3: L7805; TO-220-3_Vertical
U4: 24LC1025; DIP-8_W7.62mm_LongPads
U5: MB85RC64; DIP-8_W8.89mm_SMDSocket_LongPads
U6: MAX127; DIP-24_W7.62mm_LongPads
U7, U19, U32: 74HC132; DIP-14_W7.62mm_LongPads
U8: CDP1802ACE; DIP-40_W15.24mm_LongPads
U9: 74HC73; DIP-20_W7.62mm_Socket_LongPads
U10: EEPROM; DIP-28_W15.24mm_LongPads
U11: NV_RAM1; DIP-28_W15.24mm_LongPads
U12: NV_RAM2; DIP-28_W15.24mm_LongPads
U13, U15, U16, U18: 74HC00; DIP-14_W7.62mm_LongPads
U14: 74HC138; DIP-16_W7.62mm_LongPads
U20: 82C55A; DIP-40_W15.24mm
X1: XO-25-4MHz; Oscillator_SMD_Abracon_ASE-4Pin_3.2x2.5mm
XTAL1: 4 MHz; Crystal_HC18-U_Vertical

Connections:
/Decodificador/A15: U13.2, U13.5
/Mapa_de_memoria/A0: U10.10 (A0), U11.10 (A0), U12.10 (A0)
/Mapa_de_memoria/A1: U10.9 (A1), U11.9 (A1), U12.9 (A1)
/Mapa_de_memoria/A2: U10.8 (A2), U11.8 (A2), U12.8 (A2)
/Mapa_de_memoria/A3: U10.7 (A3), U11.7 (A3), U12.7 (A3)
/Mapa_de_memoria/A4: U10.6 (A4), U11.6 (A4), U12.6 (A4)
/Mapa_de_memoria/A5: U10.5 (A5), U11.5 (A5), U12.5 (A5)
/Mapa_de_memoria/A6: U10.4 (A6), U11.4 (A6), U12.4 (A6)
/Mapa_de_memoria/A7: U10.3 (A7), U11.3 (A7), U12.3 (A7)
/Mapa_de_memoria/A8: U10.25 (A8), U11.25 (A8), U12.25 (A8)
/Mapa_de_memoria/A9: U10.24 (A9), U11.24 (A9), U12.24 (A9)
/Mapa_de_memoria/A10: U10.21 (A10), U11.21 (A10), U12.21 (A10)
/Mapa_de_memoria/A11: U10.23 (A11), U11.23 (A11), U12.23 (A11)
/Mapa_de_memoria/A12: U10.2 (A12), U11.2 (A12), U12.2 (A12)
/Mapa_de_memoria/A13: U10.26 (A13), U11.26 (A13), U12.26 (A13)
/Mapa_de_memoria/A14: U10.1 (A14), U11.1 (A14), U12.1 (A14)
/Mapa_de_memoria/D0: U10.11 (Q0), U11.11 (Q0), U12.11 (Q0)
/Mapa_de_memoria/D1: U10.12 (Q1), U11.12 (Q1), U12.12 (Q1)
/Mapa_de_memoria/D2: U10.13 (Q2), U11.13 (Q2), U12.13 (Q2)
/Mapa_de_memoria/D3: U10.15 (Q3), U11.15 (Q3), U12.15 (Q3)
/Mapa_de_memoria/D4: U10.16 (Q4), U11.16 (Q4), U12.16 (Q4)
/Mapa_de_memoria/D5: U10.17 (Q5), U11.17 (Q5), U12.17 (Q5)
/Mapa_de_memoria/D6: U10.18 (Q6), U11.18 (Q6), U12.18 (Q6)
/Mapa_de_memoria/D7: U10.19 (Q7), U11.19 (Q7), U12.19 (Q7)
/Microprocesador/A0: U8.25 (MA0), U9.3 (D0)
/Microprocesador/A1: U8.26 (MA1), U9.4 (D1)
/Microprocesador/A2: U8.27 (MA2), U9.7 (D2)
/Microprocesador/A3: U8.28 (MA3), U9.8 (D3)
/Microprocesador/A4: U8.29 (MA4), U9.13 (D4)
/Microprocesador/A5: U8.30 (MA5), U9.14 (D5)
/Microprocesador/A6: U8.31 (MA6), U9.17 (D6)
/Microprocesador/A7: U8.32 (MA7), U9.18 (D7)
CS_EEPROM: U10.20 (~CS), U15.11
CS_RAM1: U11.20 (~CS), U13.6
CS_RAM2: U12.20 (~CS), U16.11
CS_SPI: U13.4, U14.9 (O6)
EF3: J39.5, U8.22 (~EF3)
EF4: J39.2, U8.21 (~EF4)
EFx: J37.3, J39.3, J39.4, R18.1
Earth: C1.2, C2.1, C3.2, C4.1, C5.2, C6.1, C7.2, C8.2, C9.1, C10.1, C11.2, C12.2, C13.2, C17.2, C18.2, C19.2, C20.2, C21.2, C22.2, C23.2, C24.2, C25.2, C26.2, C27.2, C28.2, C29.2, C30.2, C31.2, D2.1 (K), D4.1 (K), J3.1, J6.1, J7.1, J8.1, J13.1, J14.1, J16.1, J17.1, J18.1, J19.1, J21.1, J22.1, J23.1, J24.1, J25.1, J26.1, J27.1, J28.1, J29.1, J30.1, J37.6, R2.1, R4.1, R5.1, R6.1, R21.1, R24.1, R25.1, T1.1 (E), T2.1 (E), T4.1 (E), T5.1 (E), T6.1 (E), U1.2 (GND), U2.1 (GND), U3.2 (GND), U4.4 (GND), U5.1 (A0), U5.2 (A1), U5.3 (A2), U5.4 (GND), U6.4 (DGND), U6.6 (A0), U6.8 (A2), U6.10 (A1), U6.12 (AGND), U8.20 (VSS), U9.1 (OE), U9.10 (GND), U10.14 (GND), U11.14 (GND), U12.14 (GND), U13.7 (GND), U14.8 (GND), U15.7 (GND), U16.7 (GND), U18.7 (GND), U19.7 (GND), U20.7 (GND), U32.12, U32.13, X1.2 (GND)
MOSI: J6.4, J45.1, J46.1
MRD: J33.1, U8.7 (~MRD), U10.22 (~OE), U11.22 (~OE), U12.22 (~OE), U16.1
MWR: J35.1, U8.35 (~MWR), U10.27 (~WE), U11.27 (~WE), U12.27 (~WE)
N0: U8.19 (N0), U20.9 (A0)
N1: U8.18 (N1), U20.8 (A1)
N2: U8.17 (N2), U18.10
unnamed: C1.1, C3.1, D1.1 (+), U1.1 (IN)
unnamed: C2.2, C4.2, D1.3 (-), U2.2 (VI)
unnamed: C11.1, U6.23 (REFADJ)
unnamed: C12.1, U6.21 (REF)
unnamed: C14.2, R4.2, SW2.1, U7.1, U7.2
unnamed: C15.2, R5.2, SW3.1, U7.4, U7.5
unnamed: C16.2, R6.2, SW4.1, U7.9, U7.10
unnamed: C17.1, R7.1, U8.1 (CLOCK), XTAL1.1
unnamed: C18.1, R7.2, U8.39 (~XTAL), XTAL1.2
unnamed: D2.2 (A), R1.2
unnamed: D3.2 (A), R2.2
unnamed: D4.2 (A), R3.2
unnamed: D5.1 (K), T1.3 (C)
unnamed: D5.2 (A), R13.2
unnamed: D6.1 (K), T2.3 (C)
unnamed: D6.2 (A), R15.2
unnamed: D7.1 (K), T4.3 (C)
unnamed: D7.2 (A), R17.2
unnamed: FL1.1, J1.1
unnamed: FL1.2 (P'), SW1.2 (B)
unnamed: FL1.3 (N), J2.1
unnamed: FL1.4 (N'), SW1.5 (B)
unnamed: J37.1, J38.3
unnamed: J37.5, J38.1
unnamed: J39.1, R20.2
unnamed: J39.6, R19.2
unnamed: J40.1, U20.37 (PA7)
unnamed: J40.2, U20.38 (PA6)
unnamed: J40.3, U20.39 (PA5)
unnamed: J40.4, U20.40 (PA4)
unnamed: J40.5, U20.1 (PA3)
unnamed: J40.6, U20.2 (PA2)
unnamed: J41.1, U20.25 (PB7)
unnamed: J41.2, U20.24 (PB6)
unnamed: J41.3, U20.23 (PB5)
unnamed: J41.4, U20.22 (PB4)
unnamed: J41.5, U20.21 (PB3)
unnamed: J41.6, U20.20 (PB2)
unnamed: J42.1, U20.11 (PC6)
unnamed: J42.2, U20.12 (PC5)
unnamed: J42.3, U20.13 (PC4)
unnamed: J42.4, U20.17 (PC3)
unnamed: J42.5, U20.16 (PC2)
unnamed: J42.6, U20.15 (PC1)
unnamed: R8.2, U8.38 (~DMA_IN)
unnamed: R9.2, U8.37 (~DMA_OUT)
unnamed: R10.2, U8.36 (~INTERRUPT)
unnamed: R11.2, U8.2 (~WAIT)
unnamed: R12.1, U8.6 (SC0)
unnamed: R12.2, T1.2 (B)
unnamed: R14.1, U8.5 (SC1)
unnamed: R14.2, T2.2 (B)
unnamed: R16.1, U8.4 (Q)
unnamed: R16.2, T4.2 (B)
unnamed: R22.2, R24.2, T5.2 (B)
unnamed: R23.2, R25.2, T6.2 (B)
unnamed: U6.17 (CH4), U6.18 (CH5), U6.19 (CH6), U6.20 (CH7)
unnamed: U7.3, U8.3 (~CLEAR)
unnamed: U7.6, U8.24 (~EF1)
unnamed: U7.8, U8.23 (~EF2)
unnamed: U13.3, U14.4 (E1), U15.12, U16.13
unnamed: U13.8, U15.13
unnamed: U13.11, U14.5 (E2)
unnamed: U15.3, U16.4, U18.1
unnamed: U15.6, U20.35 (RESET)
unnamed: U15.8, U18.5, U18.13
unnamed: U16.3, U16.9, U20.5 (~RD)
unnamed: U16.5, U18.11
unnamed: U16.6, U18.2, U18.12
unnamed: U16.8, U20.36 (~WR)
unnamed: U18.3, U18.4
unnamed: U18.6, U18.9
unnamed: U18.8, U20.6 (~CS)
PA0: J43.1, R27.1, T6.3 (C), U4.5 (SDA), U5.5 (SDA), U6.7 (SDA), U20.4 (PA0)
PA1: J44.1, R26.1, T5.3 (C), U4.6 (SCL), U5.6 (SCL), U6.5 (SCL), U20.3 (PA1)
PB0: R23.1, U20.18 (PB0)
PB1: R22.1, U20.19 (PB1)
PC0: R21.2, U13.9, U16.12, U20.14 (PC0)
Q: J31.1, J37.2
SCK: J6.5, J47.1
TPA: J32.1, U8.34 (TPA), U9.11 (LE), U15.1
TPB: J34.1, U8.33 (TPB), U15.9, U16.10
VCC: C8.1, C9.2, C10.2, C13.1, C14.1, C15.1, C16.1, C19.1, C20.1, C21.1, C22.1, C23.1, C24.1, C25.1, C26.1, C27.1, C28.1, C29.1, C30.1, C31.1, J4.1, J5.1, J6.2, J7.3, J8.3, J9.1, J10.1, J11.1, J12.1, J37.4, J38.2, R3.1, R8.1, R9.1, R10.1, R11.1, R13.1, R15.1, R17.1, R18.2, R19.1, R20.1, R26.2, R27.2, SW2.2, SW3.2, SW4.2, U3.3 (OUT), U4.1 (A0), U4.2 (A1), U4.3 (A2), U4.8 (VCC), U5.8 (VCC), U6.1 (VDD), U6.2 (VDD), U6.11 (SHDN), U8.16 (VCC), U8.40 (VDD), U9.20 (VCC), U10.28 (VCC), U11.28 (VCC), U12.28 (VCC), U13.1, U13.10, U13.13, U13.14 (VCC), U14.16 (VCC), U15.2, U15.5, U15.10, U15.14 (VCC), U16.2, U16.14 (VCC), U18.14 (VCC), U19.14 (VCC), U20.26 (VCC), X1.1 (EN), X1.4 (Vdd)
VCC_12V: C5.1, C7.1, J15.1, R1.1, U1.3 (OUT), U3.1 (IN)
VCC_-12V: C6.2, D3.1 (K), J20.1, U2.3 (VO)
WP1: J7.2, U4.7 (WP)
WP2: J8.2, U5.7 (WP)

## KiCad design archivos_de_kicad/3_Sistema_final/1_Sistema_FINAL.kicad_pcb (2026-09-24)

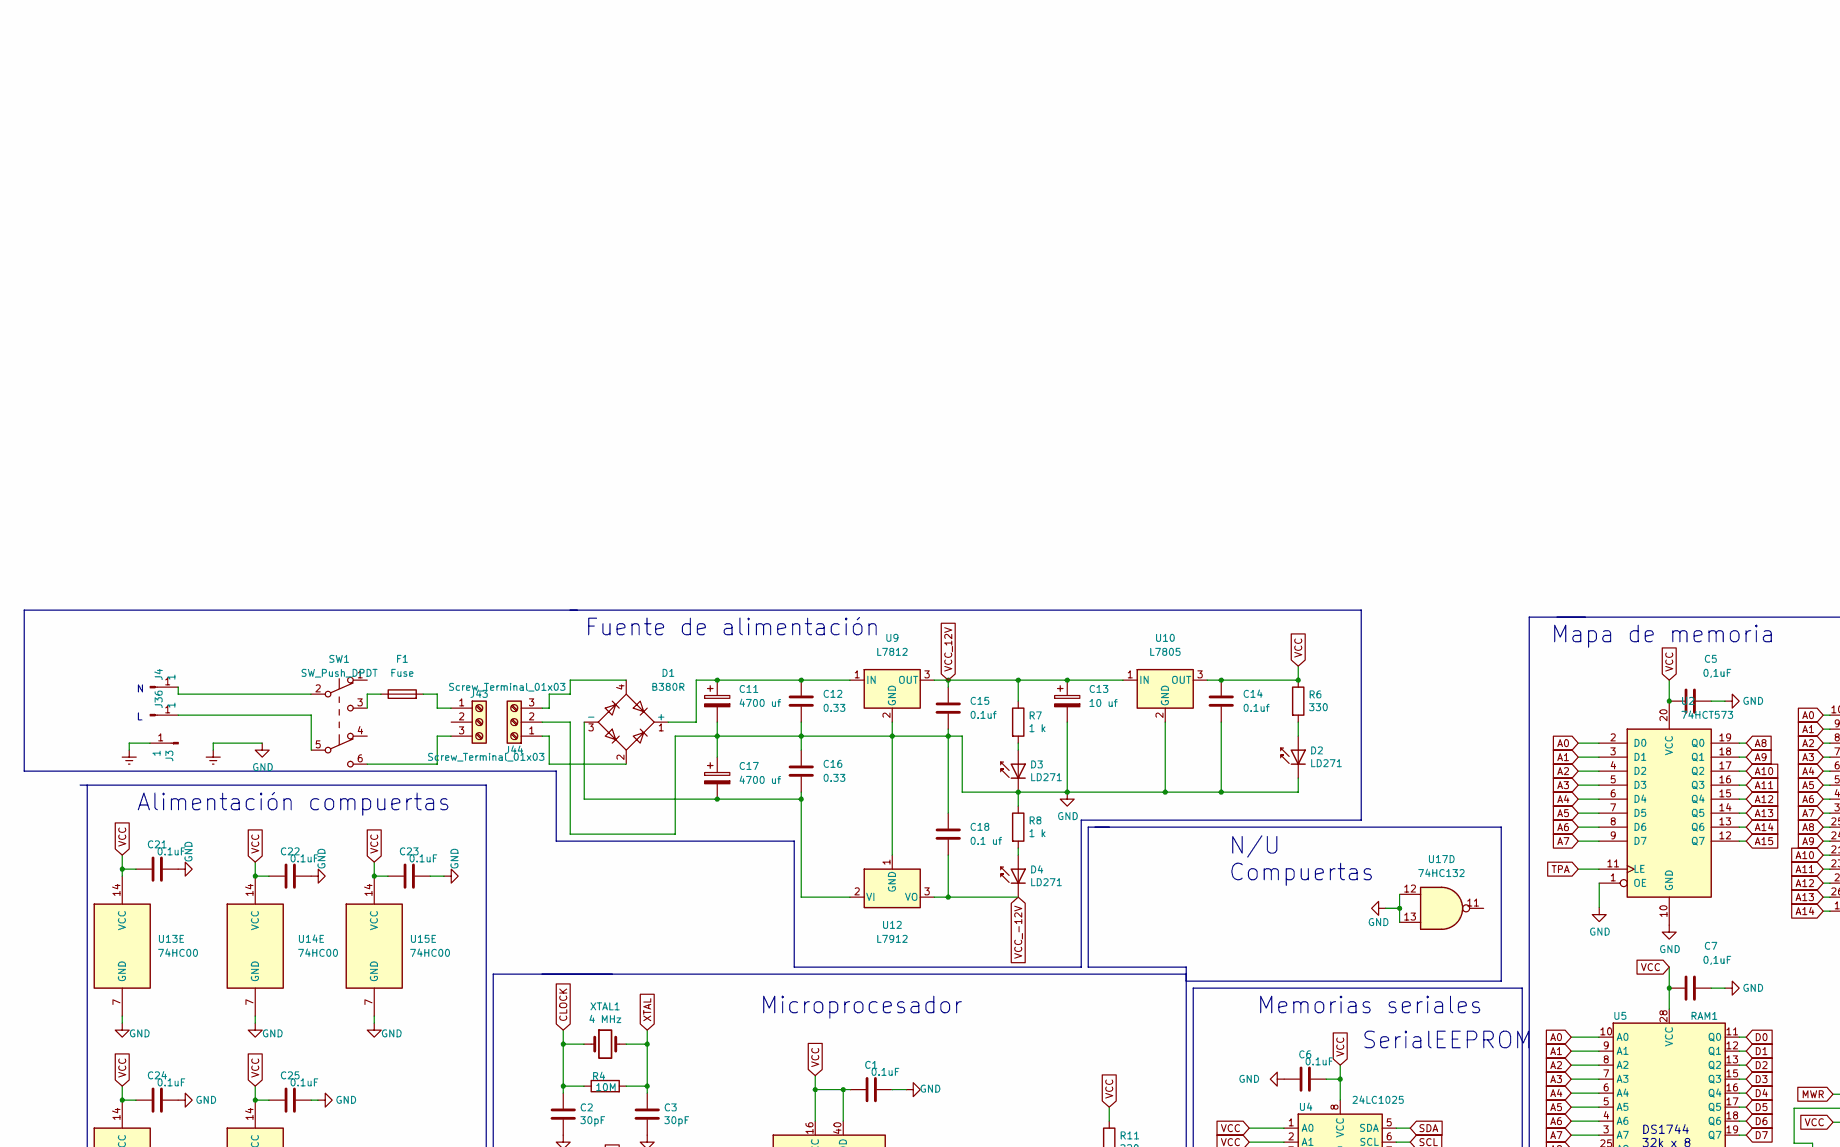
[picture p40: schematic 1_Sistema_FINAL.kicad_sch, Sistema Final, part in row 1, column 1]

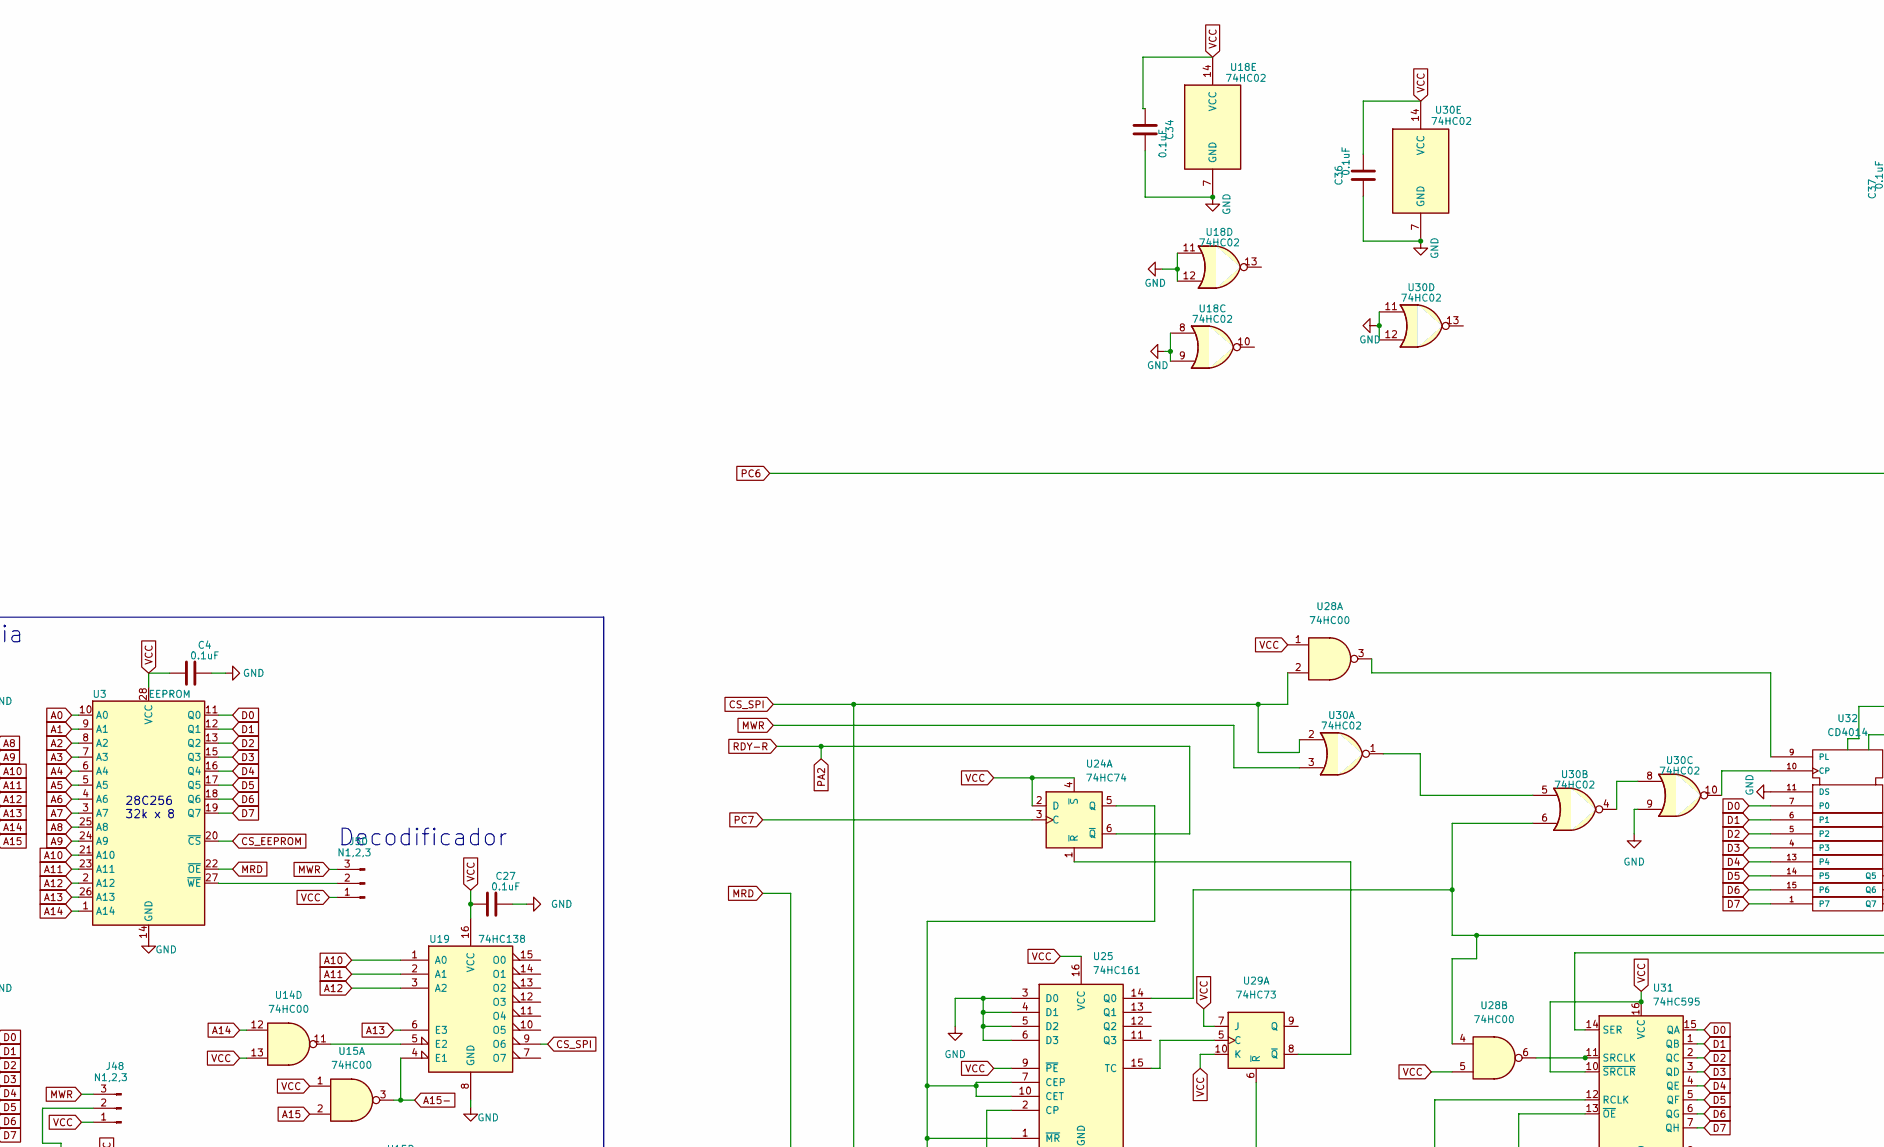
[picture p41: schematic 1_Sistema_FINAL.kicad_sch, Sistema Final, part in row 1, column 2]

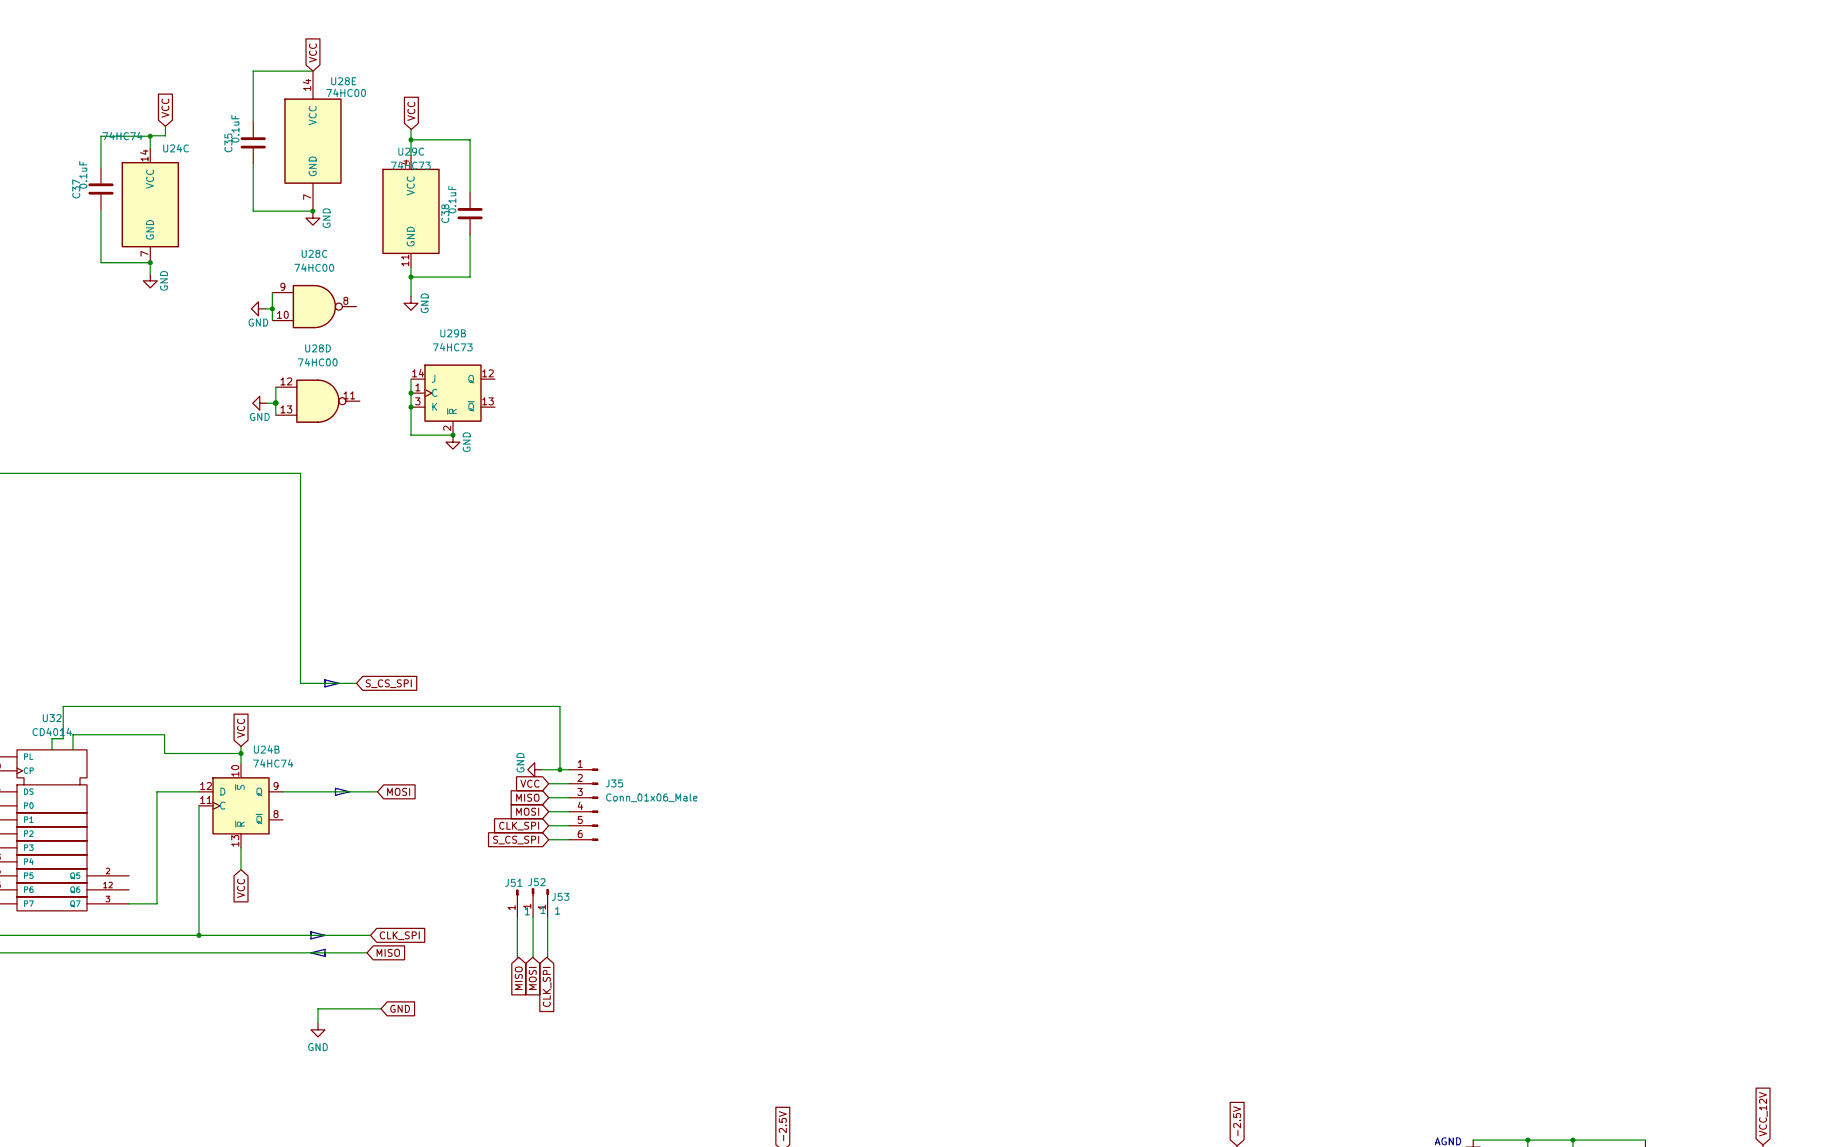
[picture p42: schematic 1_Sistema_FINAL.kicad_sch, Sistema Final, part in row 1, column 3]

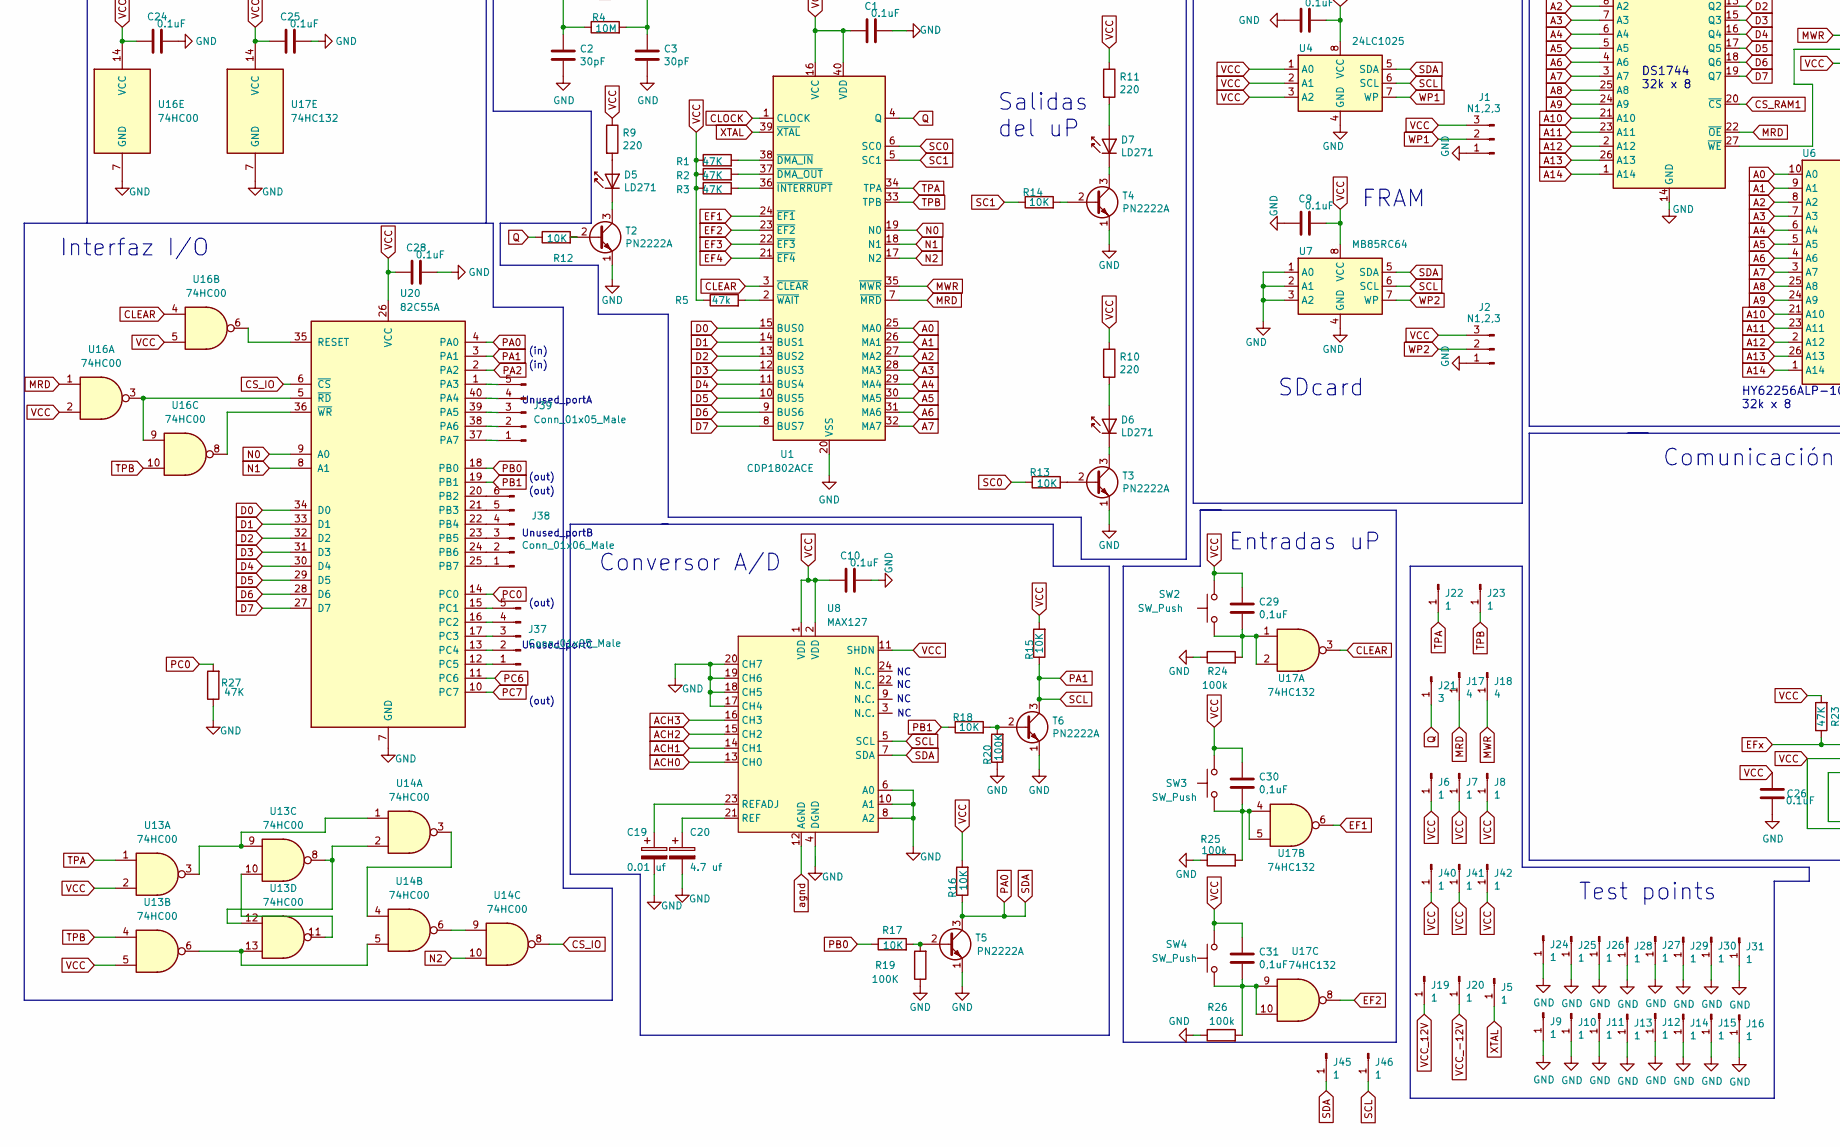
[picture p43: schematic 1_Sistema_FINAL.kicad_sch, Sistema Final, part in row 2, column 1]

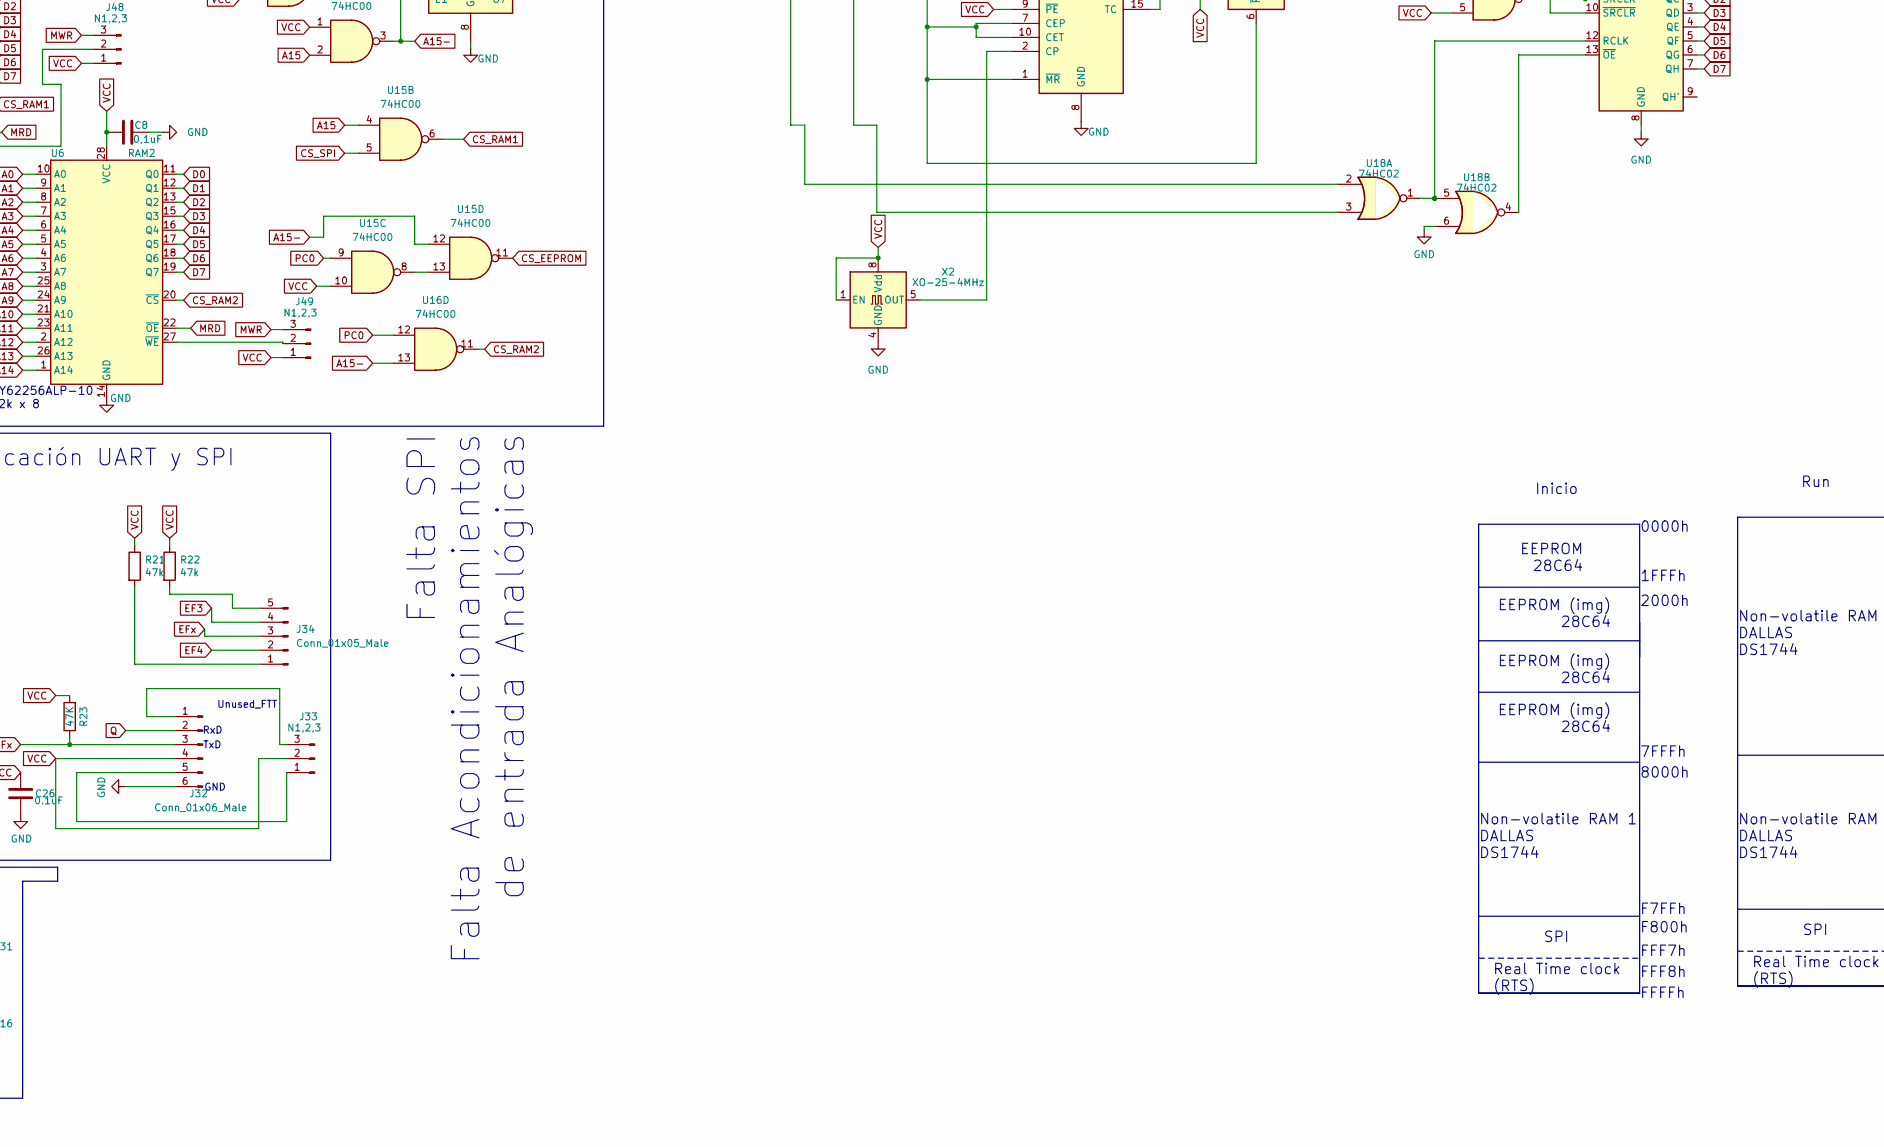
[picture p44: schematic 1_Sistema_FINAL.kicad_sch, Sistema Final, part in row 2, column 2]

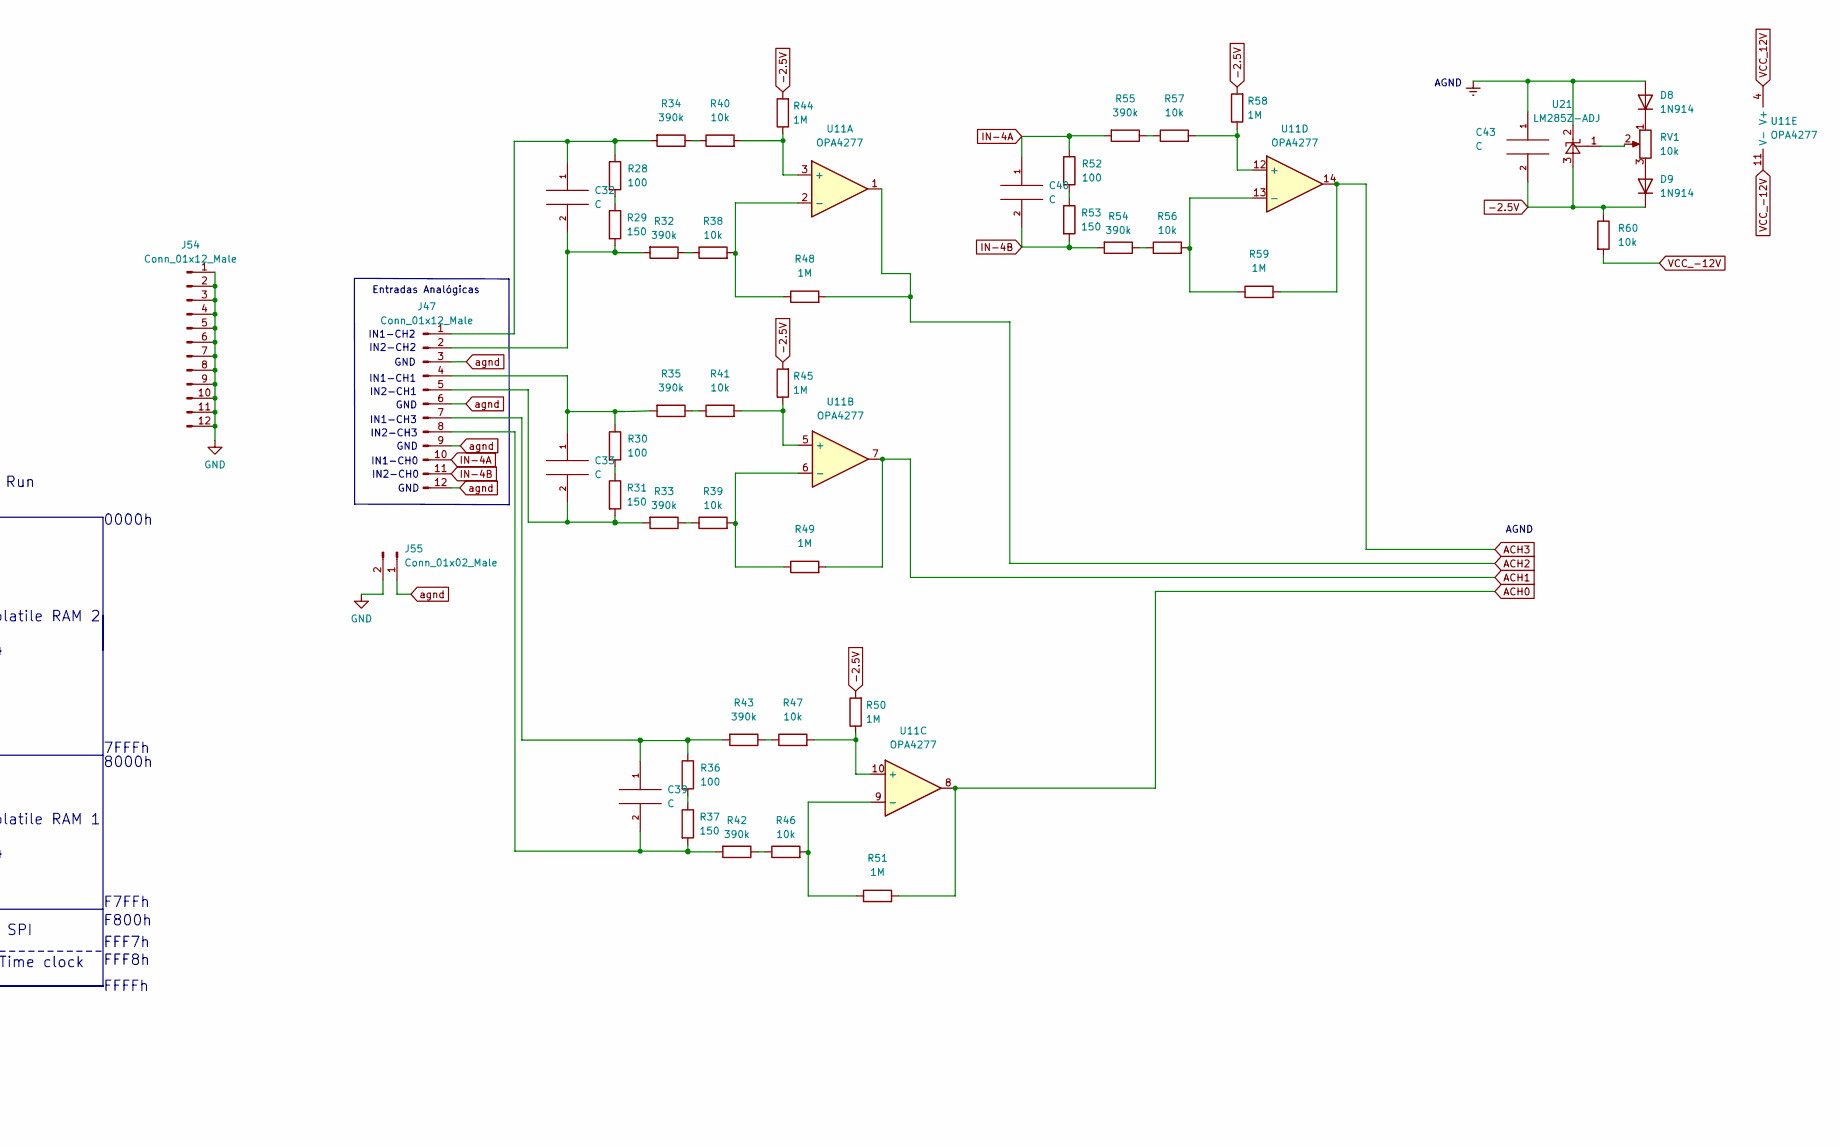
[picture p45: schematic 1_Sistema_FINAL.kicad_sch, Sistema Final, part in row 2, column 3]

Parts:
C1, C4, C6, C9, C10, C21, C22, C23, C24, C25, C26, C27, C28, C34, C35, C36, C37, C38: 0.1uF; C_Disc_D3.0mm_W1.6mm_P2.50mm
C2, C3: 30pF; C_Disc_D4.3mm_W1.9mm_P5.00mm
C5, C7, C8, C29, C30, C31: 0,1uF; C_Disc_D3.0mm_W1.6mm_P2.50mm
C11: 4700 uf; C_Rect_L11.5mm_W4.3mm_P10.00mm_MKT
C12, C16: 0.33; C_Disc_D3.0mm_W1.6mm_P2.50mm
C13: 10 uf; CP_Radial_D5.0mm_P2.00mm
C14, C15: 0.1uf; C_Disc_D3.0mm_W1.6mm_P2.50mm
C17: 4700 uf; C_Rect_L11.5mm_W2.8mm_P10.00mm_MKT
C18: 0.1 uf; C_Disc_D3.0mm_W1.6mm_P2.50mm
C19: 0.01 uf; C_Disc_D3.0mm_W1.6mm_P2.50mm
C20: 4.7 uf; CP_Radial_D5.0mm_P2.00mm
C32, C33, C39, C40, C43: C; C_Disc_D3.0mm_W1.6mm_P2.50mm
D1: B380R; Diode_Bridge_Round_D9.0mm
D2, D3, D4, D5, D6, D7: LD271; LED_D5.0mm
D8, D9: 1N914; D_DO-35_SOD27_P7.62mm_Horizontal
F1: Fuse; fusible_10mm
J1, J2, J33, J48, J49, J50: N1,2,3; PinHeader_1x03_P2.54mm_Vertical
J3, J4, J5, J6, J7, J8, J9, J10, J11, J12, J13, J14, J15, J16, J19, J20, J22, J23, J24, J25, J26, J27, J28, J29, J30, J31, J36, J40, J41, J42, J45, J46, J51, J52, J53: 1; Pin_D1.0mm_L10.0mm
J17, J18: 4; Pin_D1.0mm_L10.0mm
J21: 3; Pin_D1.0mm_L10.0mm
J32, J35, J38: Conn_01x06_Male; PinHeader_1x06_P2.54mm_Vertical
J34, J37, J39: Conn_01x05_Male; PinHeader_1x05_P2.54mm_Vertical
J43, J44: Screw_Terminal_01x03; TerminalBlock_bornier-3_P5.08mm
J47, J54: Conn_01x12_Male; PinHeader_1x12_P2.54mm_Vertical
J55: Conn_01x02_Male; PinHeader_1x02_P2.54mm_Vertical
R1, R2, R3, R23, R27: 47K; R_Axial_DIN0207_L6.3mm_D2.5mm_P10.16mm_Horizontal
R4: 10M; R_Axial_DIN0207_L6.3mm_D2.5mm_P10.16mm_Horizontal
R5: 47k; R_Axial_DIN0207_L6.3mm_D2.5mm_P10.16mm_Horizontal
R6: 330; R_Axial_DIN0207_L6.3mm_D2.5mm_P10.16mm_Horizontal
R7, R8: 1 k; R_Axial_DIN0207_L6.3mm_D2.5mm_P10.16mm_Horizontal
R9, R10, R11: 220; R_Axial_DIN0207_L6.3mm_D2.5mm_P10.16mm_Horizontal
R12, R13, R14, R15, R16, R17, R18: 10K; R_Axial_DIN0207_L6.3mm_D2.5mm_P10.16mm_Horizontal
R19, R20: 100K; R_Axial_DIN0207_L6.3mm_D2.5mm_P10.16mm_Horizontal
R21, R22: 47k; R_Axial_DIN0207_L6.3mm_D2.5mm_P15.24mm_Horizontal
R24, R25, R26: 100k; R_Axial_DIN0207_L6.3mm_D2.5mm_P10.16mm_Horizontal
R28, R30, R36, R52: 100; R_Axial_DIN0207_L6.3mm_D2.5mm_P10.16mm_Horizontal
R29, R31, R37, R53: 150; R_Axial_DIN0207_L6.3mm_D2.5mm_P10.16mm_Horizontal
R32, R33, R34, R35, R42, R43, R54, R55: 390k; R_Axial_DIN0207_L6.3mm_D2.5mm_P10.16mm_Horizontal
R38, R39, R40, R41, R46, R47, R56, R57, R60: 10k; R_Axial_DIN0207_L6.3mm_D2.5mm_P10.16mm_Horizontal
R44, R45, R48, R49, R50, R51, R58, R59: 1M; R_Axial_DIN0207_L6.3mm_D2.5mm_P10.16mm_Horizontal
RV1: 10k; Potentiometer_Bourns_3386C_Horizontal
SW1: SW_Push_DPDT; llave_6pin
SW2, SW3, SW4: SW_Push; SW_PUSH_6mm_H4.3mm
T2, T3, T4, T5, T6: PN2222A; TO-92L_Wide
U1: CDP1802ACE; DIP-40_W15.24mm_LongPads
U2: 74HCT573; DIP-20_W7.62mm_Socket_LongPads
U3: EEPROM; DIP-28_W15.24mm_LongPads
U4: 24LC1025; DIP-8_W7.62mm_LongPads
U5: RAM1; DIP-28_W15.24mm_LongPads
U6: RAM2; DIP-28_W15.24mm_LongPads
U7: MB85RC64; DIP-8_W8.89mm_SMDSocket_LongPads
U8: MAX127; DIP-24_W7.62mm_LongPads
U9: L7812; TO-220-3_Vertical
U10: L7805; TO-220-3_Vertical
U11: OPA4277; DIP-14_W7.62mm_LongPads
U12: L7912; TO-220-3_Vertical
U13, U14, U15, U16, U28: 74HC00; DIP-14_W7.62mm_LongPads
U17: 74HC132; DIP-14_W7.62mm_LongPads
U18, U30: 74HC02; DIP-14_W7.62mm_LongPads
U19: 74HC138; DIP-16_W7.62mm_LongPads
U20: 82C55A; DIP-40_W15.24mm
U21: LM285Z-ADJ; TO-92S_Wide
U24: 74HC74; DIP-14_W7.62mm_LongPads
U25: 74HC161; DIP-16_W7.62mm_LongPads
U29: 74HC73; DIP-14_W7.62mm_LongPads
U31: 74HC595; DIP-16_W7.62mm_LongPads
U32: CD4014; DIP-16_W7.62mm_LongPads
X2: XO-25-4MHz; Oscillator_SeikoEpson_SG-8002DC
XTAL1: 4 MHz; Crystal_HC18-U_Vertical

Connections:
-2.5V: C43.2, D9.1 (K), R44.2, R45.2, R50.2, R58.2, R60.1, U21.3 (A)
A0: U1.25 (MA0), U2.2 (D0), U3.10 (A0), U5.10 (A0), U6.10 (A0)
A1: U1.26 (MA1), U2.3 (D1), U3.9 (A1), U5.9 (A1), U6.9 (A1)
A2: U1.27 (MA2), U2.4 (D2), U3.8 (A2), U5.8 (A2), U6.8 (A2)
A3: U1.28 (MA3), U2.5 (D3), U3.7 (A3), U5.7 (A3), U6.7 (A3)
A4: U1.29 (MA4), U2.6 (D4), U3.6 (A4), U5.6 (A4), U6.6 (A4)
A5: U1.30 (MA5), U2.7 (D5), U3.5 (A5), U5.5 (A5), U6.5 (A5)
A6: U1.31 (MA6), U2.8 (D6), U3.4 (A6), U5.4 (A6), U6.4 (A6)
A7: U1.32 (MA7), U2.9 (D7), U3.3 (A7), U5.3 (A7), U6.3 (A7)
A8: U2.19 (Q0), U3.25 (A8), U5.25 (A8), U6.25 (A8)
A9: U2.18 (Q1), U3.24 (A9), U5.24 (A9), U6.24 (A9)
A10: U2.17 (Q2), U3.21 (A10), U5.21 (A10), U6.21 (A10), U19.1 (A0)
A11: U2.16 (Q3), U3.23 (A11), U5.23 (A11), U6.23 (A11), U19.2 (A1)
A12: U2.15 (Q4), U3.2 (A12), U5.2 (A12), U6.2 (A12), U19.3 (A2)
A13: U2.14 (Q5), U3.26 (A13), U5.26 (A13), U6.26 (A13), U19.6 (E3)
A14: U2.13 (Q6), U3.1 (A14), U5.1 (A14), U6.1 (A14), U14.12
A15: U2.12 (Q7), U15.2, U15.4
A15-: U15.3, U15.12, U16.13, U19.4 (E1)
ACH0: R51.2, U8.13 (CH0), U11.8
ACH1: R49.2, U8.14 (CH1), U11.7
ACH2: R48.2, U8.15 (CH2), U11.1
ACH3: R59.2, U8.16 (CH3), U11.14
CLEAR: U1.3 (~CLEAR), U16.4, U17.3
CLK_SPI: J35.5, J53.1, U24.11 (C), U25.14 (Q0), U28.4, U30.6
CLOCK: C2.1, R4.1, U1.1 (CLOCK), XTAL1.1
CS_EEPROM: U3.20 (~CS), U15.11
CS_IO: U14.8, U20.6 (~CS)
CS_RAM1: U5.20 (~CS), U15.6
CS_RAM2: U6.20 (~CS), U16.11
CS_SPI: U15.5, U18.3, U19.9 (O6), U28.2, U30.2
D0: U1.15 (BUS0), U3.11 (Q0), U5.11 (Q0), U6.11 (Q0), U20.34 (D0), U31.15 (QA), U32.7 (P0)
D1: U1.14 (BUS1), U3.12 (Q1), U5.12 (Q1), U6.12 (Q1), U20.33 (D1), U31.1 (QB), U32.6 (P1)
D2: U1.13 (BUS2), U3.13 (Q2), U5.13 (Q2), U6.13 (Q2), U20.32 (D2), U31.2 (QC), U32.5 (P2)
D3: U1.12 (BUS3), U3.15 (Q3), U5.15 (Q3), U6.15 (Q3), U20.31 (D3), U31.3 (QD), U32.4 (P3)
D4: U1.11 (BUS4), U3.16 (Q4), U5.16 (Q4), U6.16 (Q4), U20.30 (D4), U31.4 (QE), U32.13 (P4)
D5: U1.10 (BUS5), U3.17 (Q5), U5.17 (Q5), U6.17 (Q5), U20.29 (D5), U31.5 (QF), U32.14 (P5)
D6: U1.9 (BUS6), U3.18 (Q6), U5.18 (Q6), U6.18 (Q6), U20.28 (D6), U31.6 (QG), U32.15 (P6)
D7: U1.8 (BUS7), U3.19 (Q7), U5.19 (Q7), U6.19 (Q7), U20.27 (D7), U31.7 (QH), U32.1 (P7)
EF1: U1.24 (~EF1), U17.6
EF2: U1.23 (~EF2), U17.8
EF3: J34.4, U1.22 (~EF3)
EF4: J34.2, U1.21 (~EF4)
EFx: J32.3, J34.3, R23.1
GND: C1.2, C2.2, C3.2, C4.2, C5.2, C6.1, C7.2, C8.2, C9.1, C10.2, C11.2, C12.2, C13.2, C14.2, C15.2, C16.1, C17.1, C18.1, C19.2, C20.2, C21.2, C22.2, C23.2, C24.2, C25.2, C26.2, C27.2, C28.2, C34.2, C35.1, C36.1, C37.1, C38.1, C43.1, D2.1 (K), D3.1 (K), D8.2 (A), J1.1, J2.1, J3.1, J9.1, J10.1, J11.1, J12.1, J13.1, J14.1, J15.1, J16.1, J24.1, J25.1, J26.1, J27.1, J28.1, J29.1, J30.1, J31.1, J32.6, J35.1, J44.2, J54.1, J54.2, J54.3, J54.4, J54.5, J54.6, J54.7, J54.8, J54.9, J54.10, J54.11, J54.12, J55.2, R8.1, R19.1, R20.1, R24.1, R25.1, R26.1, R27.1, T2.1 (E), T3.1 (E), T4.1 (E), T5.1 (E), T6.1 (E), U1.20 (VSS), U2.1 (OE), U2.10 (GND), U3.14 (GND), U4.4 (GND), U5.14 (GND), U6.14 (GND), U7.1 (A0), U7.2 (A1), U7.3 (A2), U7.4 (GND), U8.4 (DGND), U8.6 (A0), U8.8 (A2), U8.10 (A1), U8.17 (CH4), U8.18 (CH5), U8.19 (CH6), U8.20 (CH7), U9.2 (GND), U10.2 (GND), U12.1 (GND), U13.7 (GND), U14.7 (GND), U15.7 (GND), U16.7 (GND), U17.7 (GND), U17.12, U17.13, U18.6, U18.7 (GND), U18.8, U18.9, U18.11, U18.12, U19.8 (GND), U20.7 (GND), U21.2 (K), U24.7 (GND), U25.3 (D0), U25.4 (D1), U25.5 (D2), U25.6 (D3), U25.8 (GND), U28.7 (GND), U28.9, U28.10, U28.12, U28.13, U29.1 (C), U29.2 (~R), U29.3 (K), U29.11 (GND), U29.14 (J), U30.7 (GND), U30.9, U30.11, U30.12, U31.8 (GND), U32.8 (Vss), U32.11 (DS), X2.4 (GND)
IN-4A: C40.1, J47.10, R52.1, R55.2
IN-4B: C40.2, J47.11, R53.2, R54.2
MISO: J35.3, J51.1, U31.14 (SER)
MOSI: J35.4, J52.1, U24.9 (Q)
MRD: J17.1, U1.7 (~MRD), U3.22 (~OE), U5.22 (~OE), U6.22 (~OE), U16.1, U18.2
MWR: J18.1, J48.3, J49.3, J50.3, U1.35 (~MWR), U30.3
N0: U1.19 (N0), U20.9 (A0)
N1: U1.18 (N1), U20.8 (A1)
N2: U1.17 (N2), U14.10
unnamed: C11.1, C12.1, D1.1 (+), U9.1 (IN)
unnamed: C16.2, C17.2, D1.3 (-), U12.2 (VI)
unnamed: C19.1, U8.23 (REFADJ)
unnamed: C20.1, U8.21 (REF)
unnamed: C29.2, R24.2, SW2.1, U17.1, U17.2
unnamed: C30.2, R25.2, SW3.1, U17.4, U17.5
unnamed: C31.2, R26.2, SW4.1, U17.9, U17.10
unnamed: C32.1, J47.1, R28.1, R34.2
unnamed: C32.2, J47.2, R29.2, R32.2
unnamed: C33.1, J47.4, R30.1, R35.2
unnamed: C33.2, J47.5, R31.2, R33.2
unnamed: C39.1, J47.7, R36.1, R43.2
unnamed: C39.2, J47.8, R37.2, R42.2
unnamed: D1.2, J44.1
unnamed: D1.4, J44.3
unnamed: D2.2 (A), R6.2
unnamed: D3.2 (A), R7.2
unnamed: D4.2 (A), R8.2
unnamed: D5.1 (K), T2.3 (C)
unnamed: D5.2 (A), R9.2
unnamed: D6.1 (K), T3.3 (C)
unnamed: D6.2 (A), R10.2
unnamed: D7.1 (K), T4.3 (C)
unnamed: D7.2 (A), R11.2
unnamed: D8.1 (K), RV1.1
unnamed: D9.2 (A), RV1.3
unnamed: F1.1, SW1.3 (C)
unnamed: F1.2, J43.1
unnamed: J4.1, SW1.2 (B)
unnamed: J32.1, J33.3
unnamed: J32.5, J33.1
unnamed: J34.1, R21.2
unnamed: J34.5, R22.2
unnamed: J36.1, SW1.5 (B)
unnamed: J37.1, U20.12 (PC5)
unnamed: J37.2, U20.13 (PC4)
unnamed: J37.3, U20.17 (PC3)
unnamed: J37.4, U20.16 (PC2)
unnamed: J37.5, U20.15 (PC1)
unnamed: J38.1, U20.25 (PB7)
unnamed: J38.2, U20.24 (PB6)
unnamed: J38.3, U20.23 (PB5)
unnamed: J38.4, U20.22 (PB4)
unnamed: J38.5, U20.21 (PB3)
unnamed: J38.6, U20.20 (PB2)
unnamed: J39.1, U20.37 (PA7)
unnamed: J39.2, U20.38 (PA6)
unnamed: J39.3, U20.39 (PA5)
unnamed: J39.4, U20.40 (PA4)
unnamed: J39.5, U20.1 (PA3)
unnamed: J43.3, SW1.6 (C)
unnamed: J48.2, U5.27 (~WE)
unnamed: J49.2, U6.27 (~WE)
unnamed: J50.2, U3.27 (~WE)
unnamed: R1.2, U1.38 (~DMA_IN)
unnamed: R2.2, U1.37 (~DMA_OUT)
unnamed: R3.2, U1.36 (~INTERRUPT)
unnamed: R5.2, U1.2 (~WAIT)
unnamed: R12.2, T2.2 (B)
unnamed: R13.2, T3.2 (B)
unnamed: R14.2, T4.2 (B)
unnamed: R17.2, R19.2, T5.2 (B)
unnamed: R18.2, R20.2, T6.2 (B)
unnamed: R28.2, R29.1
unnamed: R30.2, R31.1
unnamed: R32.1, R38.1
unnamed: R33.1, R39.1
unnamed: R34.1, R40.1
unnamed: R35.1, R41.1
unnamed: R36.2, R37.1
unnamed: R38.2, R48.1, U11.2 (-)
unnamed: R39.2, R49.1, U11.6 (-)
unnamed: R40.2, R44.1, U11.3 (+)
unnamed: R41.2, R45.1, U11.5 (+)
unnamed: R42.1, R46.1
unnamed: R43.1, R47.1
unnamed: R46.2, R51.1, U11.9 (-)
unnamed: R47.2, R50.1, U11.10 (+)
unnamed: R52.2, R53.1
unnamed: R54.1, R56.1
unnamed: R55.1, R57.1
unnamed: R56.2, R59.1, U11.13 (-)
unnamed: R57.2, R58.1, U11.12 (+)
unnamed: RV1.2, U21.1 (FB)
unnamed: U13.3, U13.9, U14.1
unnamed: U13.10, U13.11
unnamed: U13.8, U13.12, U14.2
unnamed: U13.6, U13.13, U14.5
unnamed: U14.3, U14.4
unnamed: U14.6, U14.9
unnamed: U14.11, U19.5 (E2)
unnamed: U15.8, U15.13
unnamed: U16.3, U16.9, U20.5 (~RD)
unnamed: U16.6, U20.35 (RESET)
unnamed: U16.8, U20.36 (~WR)
unnamed: U18.1, U18.5, U31.12 (RCLK)
unnamed: U18.4, U31.13 (~OE)
unnamed: U24.1 (~R), U29.8 (~Q)
unnamed: U24.5 (Q), U25.1 (~MR), U25.7 (CEP), U25.10 (CET), U29.6 (~R)
unnamed: U24.12 (D), U32.3 (Q7)
unnamed: U25.2 (CP), X2.5 (OUT)
unnamed: U28.3, U32.9 (PL)
unnamed: U28.6, U31.11 (SRCLK)
unnamed: U30.1, U30.5
unnamed: U30.4, U30.8
unnamed: U30.10, U32.10 (CP)
PA0: J45.1, R16.1, T5.3 (C), U4.5 (SDA), U7.5 (SDA), U8.7 (SDA), U20.4 (PA0)
PA1: J46.1, R15.1, T6.3 (C), U4.6 (SCL), U7.6 (SCL), U8.5 (SCL), U20.3 (PA1)
PA2: U20.2 (PA2), U24.6 (~Q)
PB0: R17.1, U20.18 (PB0)
PB1: R18.1, U20.19 (PB1)
PC0: R27.2, U15.9, U16.12, U20.14 (PC0)
PC6: J35.6, U20.11 (PC6)
PC7: U20.10 (PC7), U24.3 (C)
Q: J21.1, J32.2, R12.1, U1.4 (Q)
SC0: R13.1, U1.6 (SC0)
SC1: R14.1, U1.5 (SC1)
TPA: J22.1, U1.34 (TPA), U2.11 (LE), U13.1
TPB: J23.1, U1.33 (TPB), U13.4, U16.10
VCC: C1.1, C4.1, C5.1, C6.2, C7.1, C8.1, C9.2, C10.1, C14.1, C21.1, C22.1, C23.1, C24.1, C25.1, C26.1, C27.1, C28.1, C29.1, C30.1, C31.1, C34.1, C35.2, C36.2, C37.2, C38.2, J1.3, J2.3, J6.1, J7.1, J8.1, J32.4, J33.2, J35.2, J40.1, J41.1, J42.1, J48.1, J49.1, J50.1, R1.1, R2.1, R3.1, R5.1, R6.1, R9.1, R10.1, R11.1, R15.2, R16.2, R21.1, R22.1, R23.2, SW2.2, SW3.2, SW4.2, U1.16 (VCC), U1.40 (VDD), U2.20 (VCC), U3.28 (VCC), U4.1 (A0), U4.2 (A1), U4.3 (A2), U4.8 (VCC), U5.28 (VCC), U6.28 (VCC), U7.8 (VCC), U8.1 (VDD), U8.2 (VDD), U8.11 (SHDN), U10.3 (OUT), U13.2, U13.5, U13.14 (VCC), U14.13, U14.14 (VCC), U15.1, U15.10, U15.14 (VCC), U16.2, U16.5, U16.14 (VCC), U17.14 (VCC), U18.14 (VCC), U19.16 (VCC), U20.26 (VCC), U24.2 (D), U24.4 (~S), U24.10 (~S), U24.13 (~R), U24.14 (VCC), U25.9 (~PE), U25.16 (VCC), U28.1, U28.5, U28.14 (VCC), U29.4 (VCC), U29.7 (J), U29.10 (K), U30.14 (VCC), U31.10 (~SRCLR), U31.16 (VCC), U32.16 (Vdd), X2.1 (EN), X2.8 (Vdd)
VCC_12V: C13.1, C15.1, J19.1, R7.1, U9.3 (OUT), U10.1 (IN), U11.4 (V+)
VCC_-12V: C18.2, D4.1 (K), J20.1, R60.2, U11.11 (V-), U12.3 (VO)
WP1: J1.2, U4.7 (WP)
WP2: J2.2, U7.7 (WP)
XTAL: C3.1, J5.1, R4.2, U1.39 (~XTAL), XTAL1.2
agnd: J47.3, J47.6, J47.9, J47.12, J55.1, U8.12 (AGND)

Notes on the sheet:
Non-volatile RAM 2 DALLAS DS1744
FRAM
FFFFh
Comunicación UART y SPI
Decodificador
Unused_portA
EEPROM 28C64
Microprocesador
F800h
0000h
Mapa de memoria
Unused_portB
GND
Falta SPI Falta Acondicionamientos de entrada Analógicas
IN1-CH3
Interfaz I/O
Test points
Run
Non-volatile RAM 1 DALLAS DS1744
Alimentación compuertas
AGND
1FFFh
IN2-CH0
IN2-CH2
FFF7h
Unused_FTT
7FFFh
(out)
F7FFh
TxD
Entradas Analógicas
Entradas uP
DS1744 32k x 8
SerialEEPROM
SPI
(in)
Memorias seriales
RxD
28C256 32k x 8
Real Time clock (RTS)

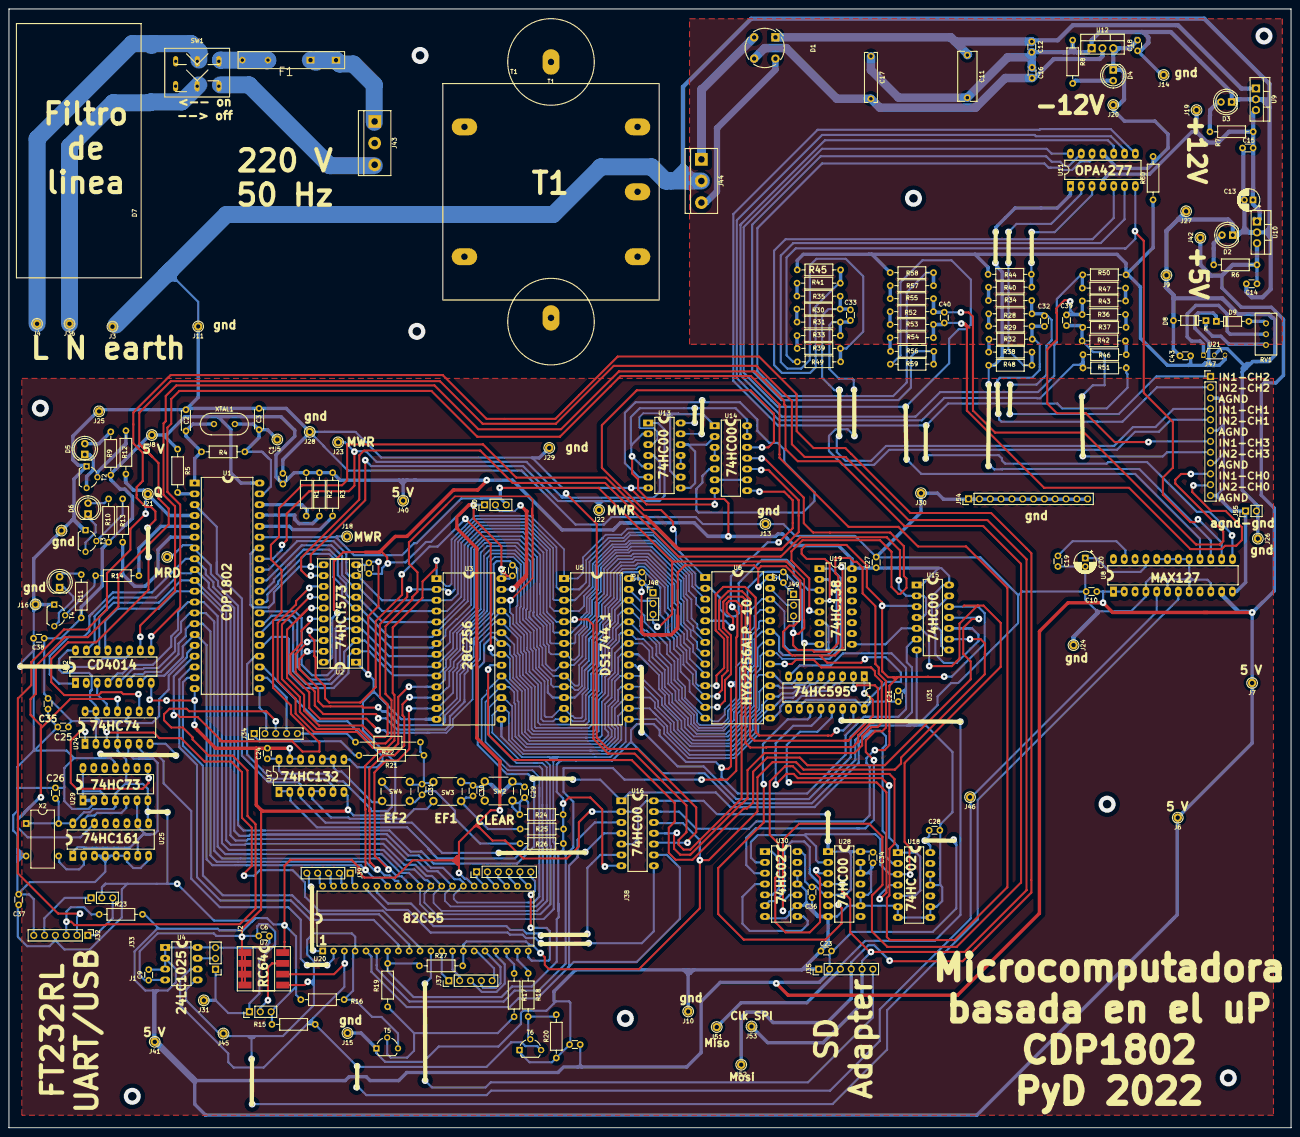
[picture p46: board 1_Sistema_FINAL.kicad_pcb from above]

Board: 2 copper layers, 301.0 x 262.6 mm, 207 parts (0 on the bottom side), 179 nets.

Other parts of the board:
T1: Transformer_1P_SS; trafo_puntomedio

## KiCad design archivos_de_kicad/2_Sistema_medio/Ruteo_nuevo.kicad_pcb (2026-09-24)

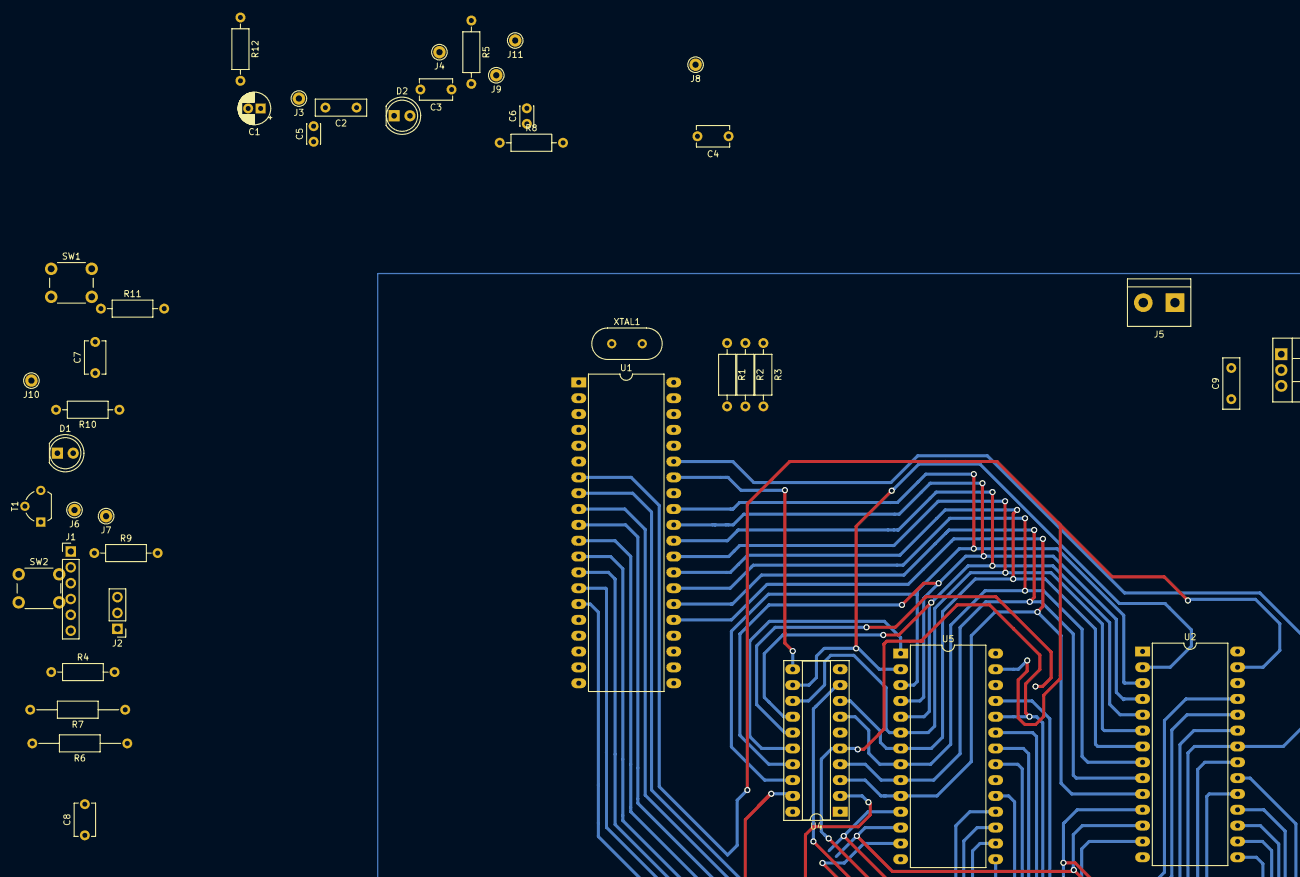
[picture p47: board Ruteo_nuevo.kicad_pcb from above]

Board: 2 copper layers, 43 parts (0 on the bottom side), 50 nets.

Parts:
C1: 10uF; CP_Radial_D5.0mm_P2.00mm
C2, C9: 0,1uF; C_Disc_D8.0mm_W2.5mm_P5.00mm
C3, C4, C7, C8: 0,1uF; C_Disc_D5.1mm_W3.2mm_P5.00mm
C5, C6: 30pF; C_Disc_D3.0mm_W2.0mm_P2.50mm
D1, D2: LD271; LED_D5.0mm
J1: Conn_01x06_Male; PinHeader_1x06_P2.54mm_Vertical
J2: N1,2,3; PinHeader_1x03_P2.54mm_Vertical
J3, J4, J6, J7, J8: 1; Pin_D1.0mm_L10.0mm
J5: Voltaje de entrada; TerminalBlock_bornier-2_P5.08mm
J9: 2; Pin_D1.0mm_L10.0mm
J10: 3; Pin_D1.0mm_L10.0mm
J11: 4; Pin_D1.0mm_L10.0mm
R1, R2, R3: 47K; R_Axial_DIN0207_L6.3mm_D2.5mm_P10.16mm_Horizontal
R4, R11, R12: 47k; R_Axial_DIN0207_L6.3mm_D2.5mm_P10.16mm_Horizontal
R5, R9: 220; R_Axial_DIN0207_L6.3mm_D2.5mm_P10.16mm_Horizontal
R6, R7: 47K; R_Axial_DIN0207_L6.3mm_D2.5mm_P15.24mm_Horizontal
R8: 10M; R_Axial_DIN0207_L6.3mm_D2.5mm_P10.16mm_Horizontal
R10: 10K; R_Axial_DIN0207_L6.3mm_D2.5mm_P10.16mm_Horizontal
SW1, SW2: SW_Push; SW_PUSH_6mm_H4.3mm
T1: PN2222A; TO-92L_Wide
U1: CDP1802ACE; DIP-40_W15.24mm_LongPads
U2: EEPROM; DIP-28_W15.24mm_LongPads
U3: L7805; TO-220-3_Vertical
U4: 74LS373; DIP-20_W7.62mm_Socket_LongPads
U5: Dallas_RAM; DIP-28_W15.24mm_LongPads
XTAL1: 4 MHz; Crystal_HC18-U_Vertical

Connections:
A0: U1.25 (MA0), U2.10 (A0), U4.3 (D0), U5.10 (A0)
A1: U1.26 (MA1), U2.9 (A1), U4.4 (D1), U5.9 (A1)
A2: U1.27 (MA2), U2.8 (A2), U4.7 (D2), U5.8 (A2)
A3: U1.28 (MA3), U2.7 (A3), U4.8 (D3), U5.7 (A3)
A4: U1.29 (MA4), U2.6 (A4), U4.13 (D4), U5.6 (A4)
A5: U1.30 (MA5), U2.5 (A5), U4.14 (D5), U5.5 (A5)
A6: U1.31 (MA6), U2.4 (A6), U4.17 (D6), U5.4 (A6)
A7: U1.32 (MA7), U2.3 (A7), U4.18 (D7), U5.3 (A7)
A8: U2.25 (A8), U4.2 (O0), U5.25 (A8)
A9: U2.24 (A9), U4.5 (O1), U5.24 (A9)
A10: U2.21 (A10), U4.6 (O2), U5.21 (A10)
A11: U2.23 (A11), U4.9 (O3), U5.23 (A11)
A12: U2.2 (A12), U4.12 (O4), U5.2 (A12)
A13: U4.15 (O5), U5.26 (A13)
A14: U4.16 (O6), U5.1 (A14)
A15: U2.20 (~CS), U4.19 (O7)
CLEAR: C7.1, R11.2, SW1.2, U1.3 (~CLEAR)
CLOCK: C5.1, J9.1, R8.1, U1.1 (CLOCK), XTAL1.1
D0: U1.15 (BUS0), U2.11 (Q0), U5.11 (Q0)
D1: U1.14 (BUS1), U2.12 (Q1), U5.12 (Q1)
D2: U1.13 (BUS2), U2.13 (Q2), U5.13 (Q2)
D3: U1.12 (BUS3), U2.15 (Q3), U5.15 (Q3)
D4: U1.11 (BUS4), U2.16 (Q4), U5.16 (Q4)
D5: U1.10 (BUS5), U2.17 (Q5), U5.17 (Q5)
D6: U1.9 (BUS6), U2.18 (Q6), U5.18 (Q6)
D7: U1.8 (BUS7), U2.19 (Q7), U5.19 (Q7)
EF1: C8.1, R4.2, SW2.2, U1.24 (~EF1)
EF4: J1.4, U1.21 (~EF4)
GND: C1.2, C2.2, C3.2, C4.2, C5.2, C6.2, C7.2, C8.2, C9.2, D2.1 (K), J1.1, J3.1, J5.1, SW1.1, SW2.1, T1.1 (E), U1.20 (VSS), U2.14 (GND), U3.2 (GND), U4.1 (OE), U4.10 (GND), U5.14 (GND)
MRD: J11.1, U1.7 (~MRD), U2.27 (~WE), U5.27 (~WE)
MWR: U1.35 (~MWR), U2.22 (~OE), U5.22 (~OE)
N1: J2.1, U1.19 (N0)
N2: J2.2, U1.18 (N1)
N3: J2.3, U1.17 (N2)
unnamed: C1.1, C2.1, J5.2, U3.1 (IN)
unnamed: D1.1 (K), T1.3 (C)
unnamed: D1.2 (A), R9.2
unnamed: D2.2 (A), R5.2
unnamed: R1.2, U1.38 (~DMA_IN)
unnamed: R2.2, U1.37 (~DMA_OUT)
unnamed: R3.2, U1.36 (~INTERRUPT)
unnamed: R6.2, U1.23 (~EF2)
unnamed: R7.2, U1.22 (~EF3)
unnamed: R10.2, T1.2 (B)
Q: J1.5, J10.1, R10.1, U1.4 (Q)
TPA: J6.1, U1.34 (TPA), U4.11 (LE)
TPB: J7.1, U1.33 (TPB)
VCC: C3.1, C4.1, C9.1, J4.1, R1.1, R2.1, R3.1, R4.1, R5.1, R6.1, R7.1, R9.1, R11.1, R12.1, U1.16 (VCC), U1.40 (VDD), U2.28 (VCC), U3.3 (OUT), U4.20 (VCC), U5.28 (VCC)
WAIT: R12.2, U1.2 (~WAIT)
XTAL: C6.1, J8.1, R8.2, U1.39 (~XTAL), XTAL1.2

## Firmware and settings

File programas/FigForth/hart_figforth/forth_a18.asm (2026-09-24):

;
; FFFF  I   GGG        FFFF   OO   RRRR   TTTTT  H   H
; F     I  G           F     O  O  R  R     T    H   H
; FFF   I  G GGG   XX  FFF   O  O  RRR      T    HHHHH
; F     I  G   G       F     O  O  R  R     T    H   H
; F     I   GGG        F      OO   R   R    T    H   H
;
;               1   8888    00   2222
;               1   8  8   0  0     2
;               1   8888   0  0   22
;               1   8  8   0  0  2
;               1   8888    00   2222
;
;
;       ALL PUBLICATIONS OF THE FORTH INTREST GROUP
;       ARE PUBLIC DOMAIN.  THEY MAY BE FURTHER
;       DISTRIBUTED BY INCLUSION OF THIS CREDIT
;       NOTICE:
;
;       THIS PUBLICATION HAS BEEN MADE AVAILABLE BY THE
;                       FORTH INTREST GROUP
;                       P. O. BOX 1105
;                       SAN CARLOS, CA 94070
;
;       IMPLEMENTAION BY:
;               GARY R. BRADSHAW
;               RFD 1 BOX 80
;               GIDLEY ROAD
;               ESPERANCE, NY  12066
;
;       MODIFIED BY:
;               GORDEN FLEMMING
;               13490 SIMSHAW ST.
;               SYLMAR, CA  91342
;
;               JIM MCDANIEL
;               1109 POINCIANA DR.
;               SUNNYVALE, CA 94086
;;
;; Apr 2016 mods Herb Johnson for A18 cross-assembler
;; change .EQU to EQU, things like that
;
;   ADDRESS COMMENTS & CORRECTIONS TO  JIM MCDANIEL.
;
;       ACKNOWLEDGEMENTS:
;
;               KEN MANTEI
;
;               FIG INSTALLATION MANUAL
;
;               FIG 8080 ASSEMBLY SOURCE LISTING..;
;
;
;               THIS LISTING TYPED     PRINTED 3/18/81
;
;
;       THE I/O VECTORS FOR DISC  ARE POINTING TO
;       ROUTINES FOR THE RCA CDP18S007, CDP18S008
;       OR THE CDP 18SOO5..
;       FOR OTHER SYSTEMS YOU WILL NEED TO
;       CHANGE THE POINTERS AND WRITE YOUR
;       OWN ROUTINES.;
;
; THE USER VARIABLE  DV IS 3 BYTES LONG
; (USER AREA OFFSET 32H 33H 34H) AND IS USED
; TO PASS VARIABLES TO THE RCA ROM UTILITY
; WHEN CALLING FOR DISK I/O.  THE RESIDENT ROM
; UTILITIES PRODUCE THEIR OWN ERROR MESSAGES.
;
; THIS VERSION ASSEMBLES WITH START UP CONSTANTS THAT
; ASSUME 28K OF RAM. DISC BUFFERS ARE
; SET FOR 1K (THIS CAN BE EASILY CHANGED
; BY CHANGING FIRST, LIMIT, B/BUF AND B/SCR).
; BLOCK 0 BEGINS AT TRACK 0 SECTOR 1.
;
;
; DR1 (SET DRIVE TO 1) IS IMPLEMENTED AS:
;  : DR1 B/SCR 250 * OFFSET ! ;
; THERFORE B/SCR AND B/BUF CAN BE CHANGED WITHOUT
; HAVING TO REWRITE
; DR1.
; THE TERMINAL I/O ASSUMES THE USE OF AN
; RCA CDP1854 UART CONFIGURED IN ONE OF THE
; ABOVE MENTIONED SYSTEMS.  THE UART IS DRIVEN
; DIRECTLY WITHOUT CALLING RCA ROM UTILITY
; ROUTINES.
;
;
; THE FORTH WORD   MON   EXITS FORTH AND RETURNS
; TO THE RESIDENT ROM UTILITY.
;
; THE FORTH WORD  BYE  IS DEFINED AS:
; : BYE  FLUSH  MON ;;
;
;
;       REGISTER ALLOCATIONS FOR THIS VERSION
;
;               R2   RETURNS STACK POINTER  R0
;                    GROWS DOWN LEFT POINTING TO
;                    FREE LOCATION
;
;               R3   PC FOR I/O AND PRIMITIVES
;
;               R7, R8  TEMPORARY ACCUMULATORS
;
;               R9   COMPUTATION STACK POINTER   S0
;                    GROWS UPWARD
;                    LEFT POINTING AT HIGH BYTE
;
;               RA   FORTH "I" REGISTER   IP
;
;               RB   FORTH "W" REGISTER   WP
;
;               RC   PC FOR INNER INTERPRETER
;
;               RD   USER POINTER         UP
;
;               RF   DISC I/O
;
;               OTHER REGISTERS ARE LEFT AVAILABLE
;               EXCEPT THAT RF.0 IS ZERO AFTER COLD
;               OR WARM STARTS
;
;
;             MEMORY MAP
;
;       ---------------------- LIMIT
;
;            RAM BUFFERS
;
;       ---------------------- FIRST
;
;             USER AREA
;
;       ---------------------- UP
;
;            RETURN STACK      R0
;
;       ---------------------- 
;
;          TERMINAL BUFFER
;
;       ---------------------- TIB
;
;         COMPUTATION STACK
;
;       ---------------------- S0
;
;             FREE SPACE
;
;       ----------------------
;
;            TEXT BUFFER
;
;       ---------------------- PAD
;
;             WORD BUFFER
;
;       ---------------------- DP
;
;             DICTIONARY
;
;       ----------------------
;
;         BOOT UP PARAMETERS
;
;       ---------------------- ORGIN 005E
;
;          ANY REQUIRED I/O
;           INITIALIZATION
;
;       ---------------------- 0000
;
;
        INCL "1802reg.asm"
;
FIRSTB  EQU  $4000 ; ADDRESS OF FIRST DISK BUFFER
LIMITB  EQU $6C2C ; END OF DISK BUFFER AREA
CSTACK  EQU  9
RSTACK  EQU 2
	;
        ORG $0000
        ;
        ; SET-UP ROUTINES
        ;
        DIS
        DB $00
        OUT 1               ; SET LEVEL 1 I/O
        DB $01
        OUT 3               ; SET UP UART
        DB $1D
        LDI $00
        PHI 3
        LDI $5E
        PLO 3
        LDI $2F
        PHI 2
        LDI $FF
        PLO 2
        SEP 3
	;
	;
        ;
        ORG $005E
	;
START:  NOP
        LBR COLD            ; COLD START
        NOP
        LBR WARM            ; WARM START
        DW $070A          ; CPU NUMBER
        DW $0001          ; REVISION NUMBER
        DW TASK - 7        ; TOPMOST PRGM IN FORTH VOCABULARY
        DW $0008          ; BACKSPACE
        DW $2000          ; INITIAL USER AREA         UP
        DW $1F00          ; INITAL STACK              S0
        DW $1FFF          ; INITAL RETURN STACK       R0
        DW $1F80          ; TERMINAL BUFFER           TIB
        DW $001F          ; NAME FIELD WIDTH          WIDTH
                            ;   (31 DECIMAL)
        DW $0000          ; WARNING                   WARNING
        DW LEND            ; FENCE                     FENCE
        DW LEND            ; INIT DICTIONARY POINTER   DP
        DW FRTH + 16       ; INIT VOCAB                VOC-LINK
	;
	;
        DB $83,"LI",$D4 ; LIT
        DW $0000
LIT:    DW $ + 2
        INC R9
        INC R9
        LDA RA
        STR R9
        INC R9
        LDA RA
        STR R9
        DEC R9
        SEP RC
	;
        ;
        ; NEXT INNER INTERPRETER
        SEP R3              ; LEAVE RC AT NEXT
NEXT:   LDA RA
        PHI RB
        LDA RA
        PLO RB
WBR:    LDA RB
        PHI R3
        LDA RB
        PLO R3
        BR NEXT - 1
        ; EXECUTE
        DB $87,"EXECUT",$C5 ; EXECUTE
	DW LIT - 6
EXE:    DW $ + 2
        LDA R9
        PHI RB
        LDN R9              ; LOAD W FROM STACK              
        PLO RB
        DEC R9
        DEC R9
        DEC R9
        INC RC
        INC RC
        INC RC              ; POINT TO WBR
        INC RC
        SEP RC
	;
	;
        DB $86,"BRANC",$C8 ; BRANCH
        DW EXE - 10
BRCH:   DW $ + 2
BRANCH: LDA RA
        STR R2
        LDA RA
        PLO RA
        LDN R2
        PHI RA
        SEP RC
	;
	;
        DB $87,"0BRANC",$C8 ; 0BRANCH
	DW BRCH - 9
ZBRCH:  DW $ + 2
        LDA R9
        BNZ NO
        LDN R9
        BNZ NO
        DEC R9
        DEC R9
        DEC R9
        BR BRANCH
NO:     INC RA
        INC RA
        DEC R9
        DEC R9
        DEC R9
        SEP RC
	;
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

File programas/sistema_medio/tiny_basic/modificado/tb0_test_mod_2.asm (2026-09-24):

;
;	$Id: tb0.asm,v 1.9.2.4.2.7 2018/04/19 23:16:50 loren Exp $
;
; TB-MON.ASM					    PAGE  1
	INCL "1802reg.asm"	;R0-RF defined HRJ

;
; AVOCET XASM18 MACRO-ASSEMBLER SYNONYMS
;
;	CALL ADDRESS	IS A SYNONYM FOR	SEP R4 (D4)
;						DW ADDR
;	EXIT		IS A SYNONYM FOR	SEP R5 (D5)
;	POP		IS A SYNONYM FOR	LDXA (72)
;	PUSH		IS A SYNONYM FOR	STXD (73)
;
; I had to change these pseudo-ops to actual code HRJ	

; L. Christensen 22 Feb 2018, (Membership Card Rev. J)
; sense of EF3 and Q for TTL is +5V idle on P4 pins 4 and 5;
;
; Rx - Pin 4, /EF3, MARK High, (no inversion, 1K resistor R2),
; Tx - Pin 5,    Q, MARK Low,  (inverted by Q7).
;
EFHI    EQU     0       ; 0=active low EF for serial, (0 = +5V MARK,  0V SPACE).
QHI     EQU     0       ; 0=active low Q for serial,  (1 =  0V MARK, +5V SPACE).

; L. Christensen 10 April 2018,
AUTORUN EQU     0       ;  Define a Tiny BASIC Autorun program at $0D00.

; Herb Johnson July 20 2018, EFHI=0 and QHI=1 for Rev J and USB/TTL FTDI dongle.
; Autorun program starts on reset after delay, ends after short loop.
; 1200 baud fixed baud rate at 2Mhz, 2400 baud at 4Mhz, no start CR needed.

;

;------------------------------------------------------;
;						       ;
; TTTTT  I  N	N  Y   Y   BBBB    AAA	 SSSS  I  CCCC ;
;   T	 I  NN	N  Y   Y   B   B  A   A  S     I  C    ;
;   T	 I  N N N   Y Y    BBBB   AAAAA  SSSS  I  C    ;
;   T	 I  N  NN    Y	   B   B  A   A     S  I  C    ;
;   T	 I  N	N    Y	   BBBB   A   A  SSSS  I  CCCC ;
;						       ;
;------------------------------------------------------;
;
; TINY BASIC FOR THE COSMAC 1802 MICROCOMPUTER	 2/18/82
; WRITTEN BY TOM PITTMAN
; MODIFIED BY LEE A. HART
; COPYRIGHT 1982 BY TECHNICAL MICRO SYSTEMS, INC.
; ASSEMBLE WITH AVOCET XASM18 CROSS-ASSEMBLER
;
; REGISTER ASSIGNMENTS:
;
;	     0	; PC (VIA RESET) AT ENTRY
;	     1	; INTERRUPT PROGRAM COUNTER
;		    (USED FOR BREAKPOINTS)
;	     2	; STACK POINTER
;	     3	; NORMAL PROGRAM COUNTER
;	     4	; MONITOR: RAM PAGE0 POINTER
;		  BASIC: SCRT "CALL" PC
;	     5	; MONITOR: MAIN PC
;		  BASIC: SCRT "RETURN" PC
;	     6	; BASIC: SCRT RETURN ADDR.
;	     7	; BASIC: PC FOR "FECH"
XX:	EQU  8	; MONITOR: ?M VS. !M SWITCH
;		  BASIC: WORK REGISTER
PC:	EQU  9	; IL PROGRAM COUNTER
AC:	EQU 10	; MONITOR: MEMORY POINTER
;		  BASIC: 16-BIT ACCUMULATOR
BP:	EQU 11	; BASIC POINTER
DELAY:	EQU 12	; PC FOR DELAY SUBROUTINE
HEXX:	EQU 13	; MONITOR: HEX ADDR. ACCUMULATOR
PZ:	EQU 13	; BASIC: PAGE 0 POINTER
BAUD:	EQU 14	; RE.0=BAUD RATE CONSTANT
;		  RE.1=USED FOR READ, TYPE
X:	EQU 15	; BASIC: SCRATCH REGISTER
ASCII:	EQU 15	; MONITOR: RF.1=ASCII I/O CHAR.
;			   RF.0=USED FOR READ, TYPE

; TB-MON.ASM					    PAGE  2

;	
; EQUATES
;
LDI0:	EQU  97H	; GHI R7 - CLEAR ACCUM. MACRO	  
TYPA:	EQU  0D3H	; SEP R3 - TYPE CHAR. MACRO
FECH:	EQU  0D7H	; SEP R7 - PAGE 0 MACRO
;
; SCRATCHPAD MEMORY ALLOCATION - OFFSET ADDED TO PAGE ADDRESS
;
PAGE:	EQU  8000H	; WORKSPACE BEGINNING
KEYV:	EQU  PAGE+06H	; KEY-INPUT ROUTINE VECTOR
TYPEV:	EQU  PAGE+09H	; TYPE-OUTPUT ROUTINE VECTOR
BREAKV: EQU  PAGE+0CH	; BREAK-DETECTION ROUTINE VECTOR
;	EQU	 +0FH	; UNUSED	  
BS:	EQU	 +13H	; BACKSPACE CHARACTER
CAN:	EQU	 +14H	; CANCEL CHARACTER
PAD:	EQU	 +15H	; NUMBER OF PAD CHARACTERS
			; MSB=0 FOR NULL, =1 FOR DELETE 		       
;		 +16H	; TAPE MODE ENABLE (80H=ENABLE)
SPARE:	EQU	 +17H	; STACK RESERVE
XEQ:	EQU	 +18H	; EXECUTION MODE FLAG
LEND:	EQU	 +19H	; INPUT LINE BUFFER END
AEPTR:	EQU	 +1AH	; ARITHMETIC EXPRESSION STACK POINTER 
;			; AND INPUT LINE BUFFER
TTYCC:	EQU	 +1BH	; PRINT COLUMN, MSB=TAPE MODE FLAG
NXA:	EQU	 +1CH	; SAVED PC FOR "NXT"
AIL:	EQU	 +1EH	; START ADDRESS OF "IL"
BASIC:	EQU	 +20H	; START ADDRESS OF BASIC PROGRAM
STACK:	EQU	 +22H	; HIGHEST ADDRESS OF USER RAM
MEND:	EQU	 +24H	; END OF BASIC PROGRAM + STACK RESERVE
TOPS:	EQU	 +26H	; TOP OF GOSUB STACK
LINO:	EQU	 +28H	; CURRENT BASIC PROGRAM LINE NUMBER
WORK:	EQU	 +2AH	; MISC. TEMPORARY STORAGE (4 BYTES)
SP:	EQU	 +2EH	; SAVED POINTER
LINE:	EQU  PAGE+30H	; INPUT LINE BUFFER (BOTTOM; 80 BYTES)
AESTK:	EQU	 +80H	; ARITHMETIC EXECUTION STACK (TOP)
;		 +82H	; BASIC VARIABLE A
;		 +84H	; BASIC VARIABLE B
;		 ...	;	...
;		 +B4H	; BASIC VARIABLE Z
;	     PAGE+B6H	; INTERPRETER TEMPORARIES (18 BYTES)
SAVEREG: EQU PAGE+0B8H	; MONITOR: SAVED REGISTERS START
SAVEND: EQU	+0DFH	;	SAVED REGISTERS END
USER:	EQU PAGE+100H	; START OF USER'S BASIC PROGRAM        

; TB-MON.ASM					    PAGE  3


;
; EXECUTION BEGINS AT 0000H, FOLLOWING A POWER-ON RESET.  
;	THE FIRST 3 BYTES CONTAIN A LONG BRANCH TO THE
;	IDIOT MONITOR. TO ENTER BASIC, THE MONITOR THEN 
;	BRANCHES TO "COLD" OR "WARM" START.
;
	ORG 0
	DIS		; DISABLE INTERRUPTS
	DB   0
	SEX  R4 	; SET X=R4
	LBR  SAVER	; GO SAVE REGISTERS
KEYBD:	LBR  TTYRED	; JUMP TO KEY-INPUT ROUTINE
TYPED:	LBR  TYPE	; JUMP TO KEY-OUTPUT ROUTINE
TBRK:	LBR  TSTBR	; JUMP TO BREAK-DETECTION ROUTINE
	DB   08H	; "BACKSPACE" CHARACTER
	DB   18H	; "CANCEL" CHARACTER
			; (ANY BUT 0AH, ODH, FFH, 00H)
	DB   02H	; PAD CODE:	   
;	      ^-------------LSD=# OF PAD CHARS AFTER CR
;	     ^--------------MSD=8: PAD CHAR.IS DELETE (FFH)
;			       =0: PAD CHAR. IS NULL (00)
	DB   80H	; TAPE MODE
	DB   20H	; SPARE STACK
;
; MEMORY PEEK AND POKE SUBROUTINES
;
PEEK:	DB   LDI0	; SINGLE BYTE LOAD
	PHI  AC 	;   HI BYTE INTO ACCUM
	LDA  XX 	;   LO BYTE INTO D
	SEP R5 ;EXIT		;   RETURN
;
POKE:	STR  XX 	; STORE BYTE
	SEP R5 ;EXIT		;   RETURN
;
	DW   TBIL	; ADDRESS OF IL
CONST:	DW   USER	; BEGINNING OF USER PROGRAM
	DB   0		; WRAP POINT
	DB   HIGH PAGE	; PAGE ADDR. HI BYTE
;
; EXIT TO MACHINE-LANGUAGE MONITOR
;
	LBR  MONITOR
;
; CPU I/O BIT ACCESS (EF1-4, Q)
;
	LBR  IOBIT
;
; I/O PORT ACCESS (IN1-7, OUT1-7)
;
	LBR  IO

; TB-MON.ASM					    PAGE  4


;---------------------------------------;
;	COMMONLY-USED SUBROUTINES	; 
;---------------------------------------;
;
; STANDARD CALL - USES R4 AS ITS PROGRAM COUNTER
;
	SEP  R3 	; < EXIT:
CALL:	PHI  X		; > ENTRY: SAVE D
	SEX  R2 	;   PUSH R6 ONTO STACK
	GLO  R6
	STXD
	GHI  R6
	STXD
	GLO  R3 	;   SAVE OLD R3 IN R6
	PLO  R6
	GHI  R3
	PHI  R6
	LDA  R6 	;   LOAD SUBROUTINE
	PHI  R3 	;     ADDRESS INTO R3
	LDA  R6
	PLO  R3
	GHI  X		;   RESTORE D
	BR   CALL-1	;   ...AND GO TO EXIT
;
; STANDARD RETURN - USES R5 AS ITS PROGRAM COUNTER
;
	SEP  R3 	; < EXIT:
RETRN:	PHI  X		; > ENTRY: SAVE D
	SEX  R2 	;   COPY R6 INTO R3
	GHI  R6
	PHI  R3
	GLO  R6
	PLO  R3
	INC  R2 	;   POP R6 FROM STACK
	LDA  R2
	PHI  R6
	LDN  R2
	PLO  R6
	GHI  X		;   RESTORE D
	BR   RETRN-1	;   ...AND GO TO EXIT
;
; BASE PAGE RAM FETCH - USES R7 AS ITS PROGRAM COUNTER 
;
	SEP  R3 	; < EXIT:
FETCH:	LDA  R3 	; > ENTRY: SET PZ POINTER
	PLO  PZ 	;     TO BASE PAGE
	LDI  HIGH PAGE	;     PLUS OFFSET (FROM CALLER)
	PHI  PZ
	LDA  PZ 	;   GET BYTE @ POINTER
	SEX  PZ 	;   INCREMENT PZ POINTER
	BR   FETCH-1	;   ...AND GO TO EXIT

; TB-MON.ASM					    PAGE  5
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

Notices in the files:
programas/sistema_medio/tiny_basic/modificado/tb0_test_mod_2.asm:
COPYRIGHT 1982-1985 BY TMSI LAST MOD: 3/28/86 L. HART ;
